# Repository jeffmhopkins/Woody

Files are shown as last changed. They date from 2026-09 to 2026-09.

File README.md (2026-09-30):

# Woody

A custom electronic woodwind instrument: a wooden body with mechanical key
switches, breath and motion sensing, driving control voltage into a Eurorack
system.

This is the second iteration of the
[Open Woodwind Project](https://github.com/jeffmhopkins/Open-Woodwind-Project)
(2021), rebuilt from scratch with modern components. The previous version was a
Teensy 3.2 with capacitive touch keys and an onboard synthesizer. This one keeps
almost none of that: mechanical switches instead of capacitive pads, an ESP32-S3
instead of a Teensy, CV output instead of an onboard synth engine.

**Status: Phase 0.** Design decisions are being recorded; no hardware has been
built. Switches and keycaps are purchased. See [ROADMAP.md](ROADMAP.md).

## What it is

The project splits into two physical deliverables that meet over a single cable:

| | **Controller** | **Interface module** |
|---|---|---|
| Form | Laminated wood/aluminium/acrylic body | 10HP Eurorack module |
| Contains | Keys, breath sensor, IMU, LED matrix, MCU | DAC, analog scaling, jacks, knobs |
| Domain | Digital | Analog, ±12V |
| Primary risk | Mechanical and ergonomic | Analog precision |

The controller carries no battery and no output jacks, and all CV **scaling,
conversion and output** happens in the module. It is **not** purely digital —
it holds the pressure sensor, a precision reference, two op-amp stages and the
analog drive onto the umbilical, which is where most of the project's analog
risk lives (ADR 0003). An earlier version of this sentence said otherwise, and
ADR 0004 records that the claim let a review finding through unchallenged.

It takes power from the rack over the umbilical and sends channel data
down the same cable as SPI. The module's analog sits inches from
the jacks it drives.

These two can be developed and tested independently, and the module can be
brought up standalone on a bench long before the instrument exists.

### Output

Six CV channels from the module:

- **Pitch** — dedicated, 1V/oct, −2V to +7V, per-unit calibrated
- **Breath** — dedicated, 0–10V, with panel knobs for gain and offset
- **Mod 1–4** — assignable; source, scale, offset, curve and slew configured
  over the instrument's USB port (ADR 0015)

## Design scope

**This is a tethered rack instrument.** It is powered by a Eurorack system,
patched into one, and played in front of one. That is the design case, and
decisions get made for it.

It is explicitly **not**: battery powered, wireless, standalone, a USB MIDI
controller product, or a touring instrument. Requirements that only make sense
away from the rack do not belong here, and past versions of these documents
drifted into arguing for some of them.

USB exists for flashing, and USB MIDI on top of it is a **bring-up tool** — it
is how keys, fingering and breath response get validated in a DAW before any
analog hardware is built (milestone E5). It is not a feature and it does not
get to constrain anything.

There is no onboard synthesizer. There is no battery.

**The target rack has a generous supply and a regulated +5 V rail.** Both are
stated properties of the system this is built for, not assumptions to be
defended. Rack current budget is therefore **not** a design constraint here, and
arguments of the form "a small Eurorack PSU might not cope" do not apply.

That relief is narrower than it sounds, and worth stating precisely so nobody
re-derives the wrong caution later. What still binds:

- **Heat.** The body is oak and acrylic — insulators — and sealed. Every watt
  leaves through the aluminium plate, part of which is under the player's hands.
- **The instrument's own 5 V regulator**, which is a 1 A part at the end of a
  2 m cable, not the rack supply.
- **Fault current**, which a larger supply makes *worse*, not better.

## Licence

Three share-alike licences, one per kind of work — **GPL-3.0-only** for
firmware, **CERN-OHL-S-2.0** for hardware and mechanical design,
**CC-BY-SA-4.0** for documentation. Derivatives stay open on the same terms.

See [`LICENSE`](LICENSE) for the mapping and the reasoning, and
[ADR 0011](docs/decisions/0011-licensing.md) for why it is three rather than
one.

## Repository layout

```
docs/decisions/   Architecture decision records — the important stuff
docs/log/         Dated build log
docs/reference/   Latency budgets, fingering notes, specs
docs/research/    Component comparisons and datasheet notes
docs/review/      Cold review waves. A dated record, never corrected
datasheets/       The actual vendor PDFs, one MANIFEST.csv row each
hardware/         Schematics, split by CIRCUIT under each board:
                    <board>/<circuit>/<circuit>.md  the drawing + derivations
                                      bom.csv       fragment; generates the BOM
                                      circuit.yaml  declared dependencies
                                      notes.md      what it used to be
                  interfaces/  the three circuits that cross a board boundary
                  boards/      one KiCad project per physical board, placing the
                               circuit sheets; the KiCad sheets are the source
                               of truth (ADR 0019, docs/reference/tooling.md)
                  bom.csv      GENERATED from the fragments - do not edit
firmware/         ESP32-S3 firmware (PlatformIO)
mechanical/       Body CAD (OpenSCAD, parametric): renders, DXF cut files and
                  a design-rule report, all GENERATED by tools/cad.py and
                  fingerprinted against their sources - see mechanical/README.md
config/           figures.yaml - THE SHARED-FIGURE REGISTER, the single
                  source of truth for every value used in more than one
                  document; plus key layout and routing, as data
tools/            Host-side utilities
branding/         The Space Coast Synthesizers mark: build.py generates the
                  laser artwork (SVG/DXF), a test print and renders
CLAUDE.md         THE WORKING RULES. Read this before editing anything -
                  it is short, and every rule in it was paid for once
```

*(`docs/review/` and `datasheets/` were missing from this tree until
2026-09-21. `datasheets/` is the largest directory in the repository;
`docs/review/` holds a wave per directory — `ls -d docs/review/*/` is the
count, and there is deliberately no number in this sentence. Both were
invisible in the one file a new reader opens first. The counts that used to
sit here — "77 banked documents", "seven waves", then "nine waves" — were
each true when written and wrong within the week, which is the whole reason
this repository cites rather than
restates.)*

## Where to start reading

1. [ROADMAP.md](ROADMAP.md) — the three tracks and what "done" means for each
2. [hardware/README.md](hardware/README.md) — **how the schematics are
   organised**: one circuit per directory, what the four files in each are,
   and the two rules that will bite you. Start here before opening any
   circuit page.
3. [docs/decisions/](docs/decisions/) — every choice made so far, and why
4. [docs/reference/latency-budget.md](docs/reference/latency-budget.md) — the
   constraint that shapes most of the electrical design
5. [docs/reference/repo-maintenance.md](docs/reference/repo-maintenance.md) —
   which files are generated, which are history, what each tool owns
6. [docs/reference/tooling.md](docs/reference/tooling.md) — **installing and
   using the tools**: the body CAD (OpenSCAD) and the schematic sheets
   (KiCad 9), one setup script for both

*(Entry 2 was missing until 2026-09-21. `hardware/README.md` — the page that
explains the whole `<board>/<circuit>/` scheme the restructure exists to
create — had **zero inbound links from anywhere in the corpus**, so the tree
was navigable by `grep` and by already knowing where things were, which is
the condition the restructure was meant to end.)*

*(This file carried a second "Licensing" section here saying the licence was
"not yet decided", contradicting the "Licence" section above it, which states
the three that were chosen. ADR 0011 has read `Accepted` since it was written
and `LICENSE` has held the mapping the whole time. Deleted 2026-09-21 — the
licence is stated once, above, and nowhere else.)*

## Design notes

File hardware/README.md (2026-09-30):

# hardware/ — how this directory is organised

*Schematic sheets are generated from the netlists in KiCad 9, and each
physical board has a directory under [`boards/`](boards/) whose netlist is
assembled from the circuits: [`docs/reference/tooling.md`](../docs/reference/tooling.md) §3.*

One circuit per directory. The directory is the unit: the drawing, the parts,
the declared dependencies and the history of what the circuit *used to be* all
sit together, so a change and its record are never in different places.

```
<board>/<circuit>/<circuit>.md     the schematic: ASCII drawing, derivations,
                                   and an ## Interfaces table of every net
                                   that crosses the circuit's boundary
                  bom.csv          this circuit's parts. A FRAGMENT
                  circuit.yaml     declared dependencies. SEEDED, NOT VERIFIED
                  notes.md         past tense only. No live value belongs here
                  sim/             its SPICE simulation: sims.yaml (what is simulated,
                                   and what each run must show), the decks, and
                                   results.yaml, GENERATED by tools/sim.py run and
                                   held to its inputs by check-staleness. A sim/
                                   with a README and no sims.yaml is a contract not
                                   yet run, and says so
                  <circuit>.kicad_sch  THE SOURCE OF TRUTH where it exists
                                   (ADR 0019): connections and part facts.
                                   Edit in KiCad 9
                  netlist.yaml     EXPORTED from the sheet by tools/kicad.py
                                   where one exists - do not edit. Otherwise
                                   hand-written and authoritative until the
                                   circuit is migrated. Every check reads it

boards/<board>/   one KiCad project per physical board: the root sheet
                  places circuit sheets once per instance; board-netlist.yaml
                  is its exported, flattened netlist

nets.yaml                          at hardware/ root: THE MASTER NET LIST,
                                   which owns every net that crosses a circuit
                                   boundary. A netlist.yaml declares only its
                                   own side; this file owns the net
```

> ### The drawing is not the source of truth. Where a `netlist.yaml` exists, that is.
>
> **An ASCII drawing is a picture.** No tool in this repository can read one,
> so nothing checks that a value in a drawing matches the BOM row for the same
> refdes — and on 2026-09-22 a review found four that did not, including
> `R-FB` drawn at a resistance that is not a purchasable E96 value and an
> entry capacitor drawn at half the BOM's value on the rail that matters.
>
> **`tools/check-netlist.py` checks the drawing against the netlist**, and
> the netlist against `bom.csv` and against `nets.yaml`. It runs `--strict`
> from the commit gate, so a page that gains a drawing and no netlist is a
> failure rather than an entry on a list. It resolves a label against EVERY
> netlist, not only the one beside the page, because several pages draw parts
> they do not own.
>
> **Where a drawing and a row disagree and no netlist covers them, `bom.csv`
> wins.** It is generated from fragments, `merge-bom.py --check` proves the
> master matches them, and the commit hook runs it. A drawing has none of
> that behind it.

| Directory | |
|---|---|
| [`carrier/`](carrier/carrier.md) | The instrument's real-time board — 5 circuits |
| [`cluster/`](cluster/cluster-boards.md) | The four key clusters — two key boards and the main board's two thumb clusters — 3 circuits |
| [`module/`](module/module.md) | The 10HP Eurorack module — 12 circuits |
| [`interfaces/`](interfaces/README.md) | The 3 circuits that cross a board boundary |

## The `## Interfaces` table

Every circuit page carries one: every net that crosses that circuit's
boundary, one row each. A PCB netlist is transcribed from these, so a row is
a wiring instruction and two pages disagreeing about a net is a short.

**Two drawing shorthands, and they are shorthands — not missing parts.** The
ASCII drawings use a short spelling where the full refdes would break column
alignment. When transcribing a netlist, expand them:

A netlist declares its own alias with `drawn_as:`, which is what makes the
shorthand checkable rather than merely documented; this table is for the
pages that have no netlist yet.

| Drawn as | BOM row |
|---|---|
| `C-TIMER` | `C-TIMER-LOADSW` |
| `C-GATE` | `C-GATE-LOADSW` |

**`J-UMB` is no longer a shorthand.** It was one, for `J-UMBILICAL`, until
ADR 0017 put a real connector of that name on the main board: `J-UMB` is now
its own row, the header that joins the etherCON's adapter to the main board
(ADR 0021), so "`J-UMB` pin N" on an instrument page is that header and the
same conductor as the etherCON's pin N
(`hardware/interfaces/spi-link/spi-link.md`). On a module page the umbilical
connector is `J-UMBILICAL`, netlisted as `J-UMB-MOD`; the instrument's
etherCON is `J-UMBILICAL-INST`, netlisted as `J-UMB-INST`. Neither is ever
`J-UMB`.

A cold reviewer filed these two, and `J-UMB` when it was a shorthand, as
refdes that "match nothing in `bom.csv`", which was fair — nothing said
otherwise. They are listed here once rather
than expanded in ~40 drawing sites, because widening a label inside a drawing
shifts every column to its right, and that drift is itself a recorded defect
on these pages. One more, an unlabelled `N-FET`, was **not** a shorthand: it
is `Q-LOADSW`, a row created after that drawing was last touched, and it is
now labelled.

| Column | |
|---|---|
| **Node** | The net's name, **qualified** where the same bare name means different things on different boards. `AGND_SENSE`, `AGND_INST` and `AGND_MOD` are three nets; `AGND` alone is a merge waiting to happen. Each row names the drawing's own spelling so a reader can match the two. |
| **Dir** | This circuit's side of the net: `in`, `out`, `in/out`, `ref` (a return or a reference) or `—` (no connection here — the row is context). |
| **Peer** | A bare `board/circuit` id when the other end is a circuit in this tree, a reference designator or part name when it is not, `—` when there is nothing on the other end. |
| **Figure** | A citation into `config/figures.yaml`. The table names nodes; it **does not restate values.** |

**Exactly one page sources a net.** The page holding the part that drives it
says `out` and "Sourced here"; every other page says `in` and names it. Two
pages both claiming to source one net is the defect this column exists to
make visible — it happened to the DAC's `SCLK`/`DIN`/`SYNC`, in two
byte-identical rows.

The two board-crossing tables (`interfaces/breath-sense-link`,
`interfaces/spi-link`) carry an extra **End** column naming which side of the
cable a node sits on, because for those the board is not implied by the page.

*(This definition sat inline in all 23 circuit pages until 2026-09-21 —
twenty-three copies of one paragraph, in a repository whose first rule is
state it once and cite it. It is here, and they cite it.)*

## `circuit.yaml` and its `depends_on` edges

Every circuit directory carries a `circuit.yaml` whose `depends_on` list is
the dependency graph. Four kinds of edge, and **they are not equally
trustworthy** — this section is the one place that says which:

**`circuit:` edges are VERIFIED.** The rule is mechanical, so any edge can be
checked against the two tables it comes from:

> ONE `circuit:` edge per distinct `board/circuit` id in the **Peer** column of
> this circuit's `## Interfaces` table, AND every such edge is declared from
> **both** ends. A peer that is not a circuit in this tree — a connector, the
> Eurorack bus board, a dev board header — is named in the Peer column by its
> reference designator or its name, and creates no edge.

**`adr:`, `fig:` and `refdes:` edges are SEEDED FROM CO-MENTION and are NOT
VERIFIED.** An edge of those three kinds means *"this page mentions this
thing"*, which is a useful starting graph and a bad finished one. Three were
verified false by a cold reviewer, by reading:

| edge | what it really is |
|---|---|
| `pitch-stage` → `R-BIAS-INAMP` | the page names it as an explicit **contrast** |
| `breath-adc` → `C-STRIP-BULK` | a citation of a note about the LED strip |
| `breath-receive` → `U-OPA-PITCH` | a package-count consequence, not a use |

All three are still declared. **Expect more of that shape.**

**Direction is not recorded.** Several pairs are mutual, which is honest for a
net shared between two circuits and useless for ordering anything.

**What IS guaranteed for every edge, verified or seeded: it RESOLVES.** A
`refdes:` names a BOM row that exists, a `fig:` names a register entry, a
`circuit:` names a declared id. That is what catches a dependency on a deleted
part — the semantic half `CLAUDE.md` §5 says a grep cannot reach.

*(This sat as a 39-line comment header inside all 23 `circuit.yaml` files —
byte-identical, twenty-three copies — until 2026-09-22. Same defect as the
`## Interfaces` definition above, found the same way, fixed the same way.)*

## Two rules that will bite you

**`bom.csv` here is GENERATED.** `tools/merge-bom.py` rebuilds it from the
per-circuit fragments, so **a direct edit survives until the next run of that
tool and then disappears without a word.** Edit the fragment. A row lives with
the circuit **whose page derives its value** — not where it is mentioned, not
where it is mounted. `merge-bom.py --check` proves the master still matches
and the commit hook runs it, so this one fails loudly rather than silently.

**Numbers shared between documents are not written here.** They live in
`config/figures.yaml`, stated once by their owner and **cited by name**
everywhere else. This whole repository is organised around one recorded
failure — a value changes and the documents derived from it do not follow —
and citation is the only form that cannot go stale. `CLAUDE.md` has the rule
and the three-step procedure for changing a tracked figure.

## What is deliberately not here

`hardware/unplaced.csv` holds the BOM rows **no schematic page derives**.
That is a count, not a dumping ground: a part nobody has drawn.

It has shrunk twice; `wc -l hardware/unplaced.csv` is the count, and a
number written here goes stale the next time a row is placed. Sixteen rows
were drawn all along — the
DAC, the in-amp, the LM317 and its divider, the entry diodes, the four
beads, the bulk capacitors, both load-switch capacitors, the module's level
shifter and the LT5400 — and were sitting in the undrawn pile because
assignment matched on **reference designator** while those parts are drawn
under a local label (`R1`, `C_cm`, `FB2`, `R_G`) or a part number
(`INA828`, `LM317LZ`, `DAC8568`). A count of undrawn parts that includes
every principal IC on a board is not a count of anything.

What remains is genuinely unplaced, and most of it is mechanical — the oak,
the acrylic, the adhesives, the fasteners — plus the parts whose circuit has
no page yet.

Drawings that span more than one circuit were **left whole** rather than
redrawn, and the circuits cite them. `carrier.md`'s §2 figure carries three
circuits in one connected picture; dividing it would mean redrawing it, and a
redraw is not a move.

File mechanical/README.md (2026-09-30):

# Instrument body — parametric CAD

*Installing the tools and the day-to-day loop: [`docs/reference/tooling.md`](../docs/reference/tooling.md)
(`sudo bash tools/setup-env.sh` installs everything).*

> **Status:** first model, 2026-09-26. **Layout is PROVISIONAL**: every key
> position in `config/key-layout.yaml` is still `null` (they are M2/M3
> outputs), so keys are placed on ADR 0009's length budget and every render
> says so in its footer. Keys are **flush with the top face at full travel**
> — thumb keys included, on the bottom face. **There is no display board**:
> the LED matrix is the instrument's only display (ADR 0015, 2026-09-26).

The body described in [ADR 0009](../docs/decisions/0009-enclosure-construction.md)
— a laminated stack of flat parts, every layer a 2D through-cut — as an
OpenSCAD model, with renders and cut files generated from it and a ledger that
proves each one still shows the model it names.

*The Eurorack module is a separate model in the same pipeline:
[`module/README.md`](module/README.md).*

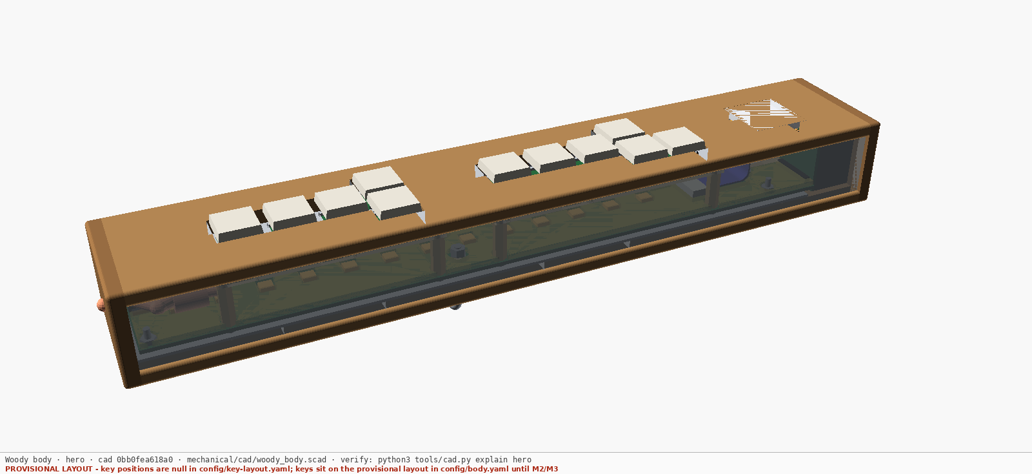
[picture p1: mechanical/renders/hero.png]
The instrument, key face up


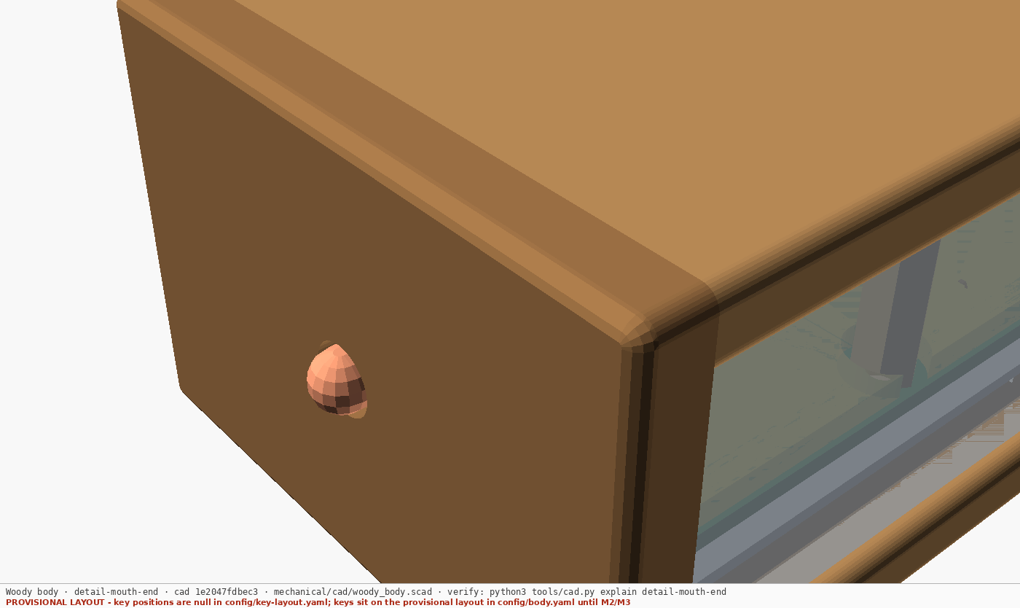
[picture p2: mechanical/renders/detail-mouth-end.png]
The mouth end close up: oak cap and sanded edges


## The one rule

**Change the YAML, run the build, commit what it produced.** Never draw a
number into the `.scad`, and never touch a file under `renders/`, `export/`
or `cad/generated/`.

```
config/key-layout.yaml ─┐                           ┌─> renders/*.png   (stamped)
config/body.yaml ───────┼─> cad/generated/params.scad ─> woody_body.scad ─┼─> export/*.dxf    (cut files)
datasheets/…  (STEP, DXF)─> cad/vendor/*.stl ────────┘                     └─> drc.echo        (design rules)
                                                         every arrow fingerprinted in OUTPUTS.csv
```

```
python3 tools/cad.py build          # regenerate params, rebuild whatever is stale
python3 tools/cad.py check          # exit 1 if any output no longer matches its sources
python3 tools/cad.py explain hero   # which input moved, and the commit it was built from
```

`check` runs from the commit gate (`tools/check-staleness.py`) and needs
nothing but Python. `build` needs OpenSCAD 2021.01+, `xvfb-run` on a machine
without a display, Pillow (for the stamp), and gmsh (`pip install gmsh`, plus
apt `libxft2`) to mesh the vendor STEP files.

## How staleness is tracked

A picture cannot be grepped, so no forbidden pattern will ever catch a render
of a superseded value. Instead:

- **Every output has a fingerprint**: a hash over its recipe in
  [`outputs.yaml`](outputs.yaml) and the git blob id of **every file it was
  built from**, found by walking `include`/`use`/data-file references from its
  source. The build cross-checks that walk against OpenSCAD's own dependency
  file and refuses to trust a fingerprint the two disagree on.
- **[`OUTPUTS.csv`](OUTPUTS.csv) is the ledger**: fingerprint, the output's own
  hash, and each input's blob id. `check` recomputes all of it. It reports an
  output as **STALE** when an input moved (naming the file), as **edited** when
  the output no longer hashes to what the ledger vouches for, and as an
  **orphan** when a PNG or DXF exists that no spec entry builds.
- **The fingerprint is stamped into every render's footer**, because the reader
  looks at the picture, not the ledger. A render pasted anywhere still says
  `cad <fingerprint>`, and `explain` turns that back into the git commits it was
  built from.
- **A config change is caught before it reaches a picture**: `params.scad`
  must equal what the YAML generates, and `check` lists every output fed by it.
- **Pages here may only show tracked outputs.** An image link in a
  `mechanical/**/*.md` page that is not in the ledger fails `check`.
- **`RECIPE` in `tools/cad.py`** is part of every fingerprint. Bump it when you
  change *how* outputs are made (stamp, mesh settings, render flags) — the
  tool's own source is deliberately not an input, so this is the one manual
  step, and forgetting it was the first bug this pipeline had.

## What is here

| Path | What it is |
|---|---|
| [`cad/woody_body.scad`](cad/woody_body.scad) | The model. Every flat part as a 2D module in its own sheet frame; the assembly places them. `part=` selects one |
| `cad/fig_*.scad` | Figure sources with dimensions and labels, drawn from the same variables as the parts. They sit beside the model because OpenSCAD resolves `import()` against the top-level file |
| `cad/lib/annot.scad` | Dimension and label helpers (from JBrain2's back-plate CAD) |
| `cad/generated/params.scad` | **Generated.** Every number the model uses, with its source and status |
| `cad/vendor/*.stl` | **Generated.** The banked KS-33 STEP solid, meshed |
| [`outputs.yaml`](outputs.yaml) | Every output: cameras, defines, paths. The build does exactly this list |
| [`OUTPUTS.csv`](OUTPUTS.csv) | **Generated.** The fingerprint ledger |
| [`drc.echo`](drc.echo) | **Generated.** The design-rule report — read it after every change |
| [`clash.txt`](clash.txt) | **Generated.** The interference check: every named solid against every other |
| [`clash-allow.yaml`](clash-allow.yaml) | Interference the design intends, each with its reason |
| `export/*.dxf` | **Generated.** One file per flat part, as it goes to the cutter |
| `renders/*.png` | **Generated.** Every image on these pages |
| [DESIGN.md](DESIGN.md) | How the stack is built, where each number comes from, and what the first model found |

## The views

| | |
|---|---|
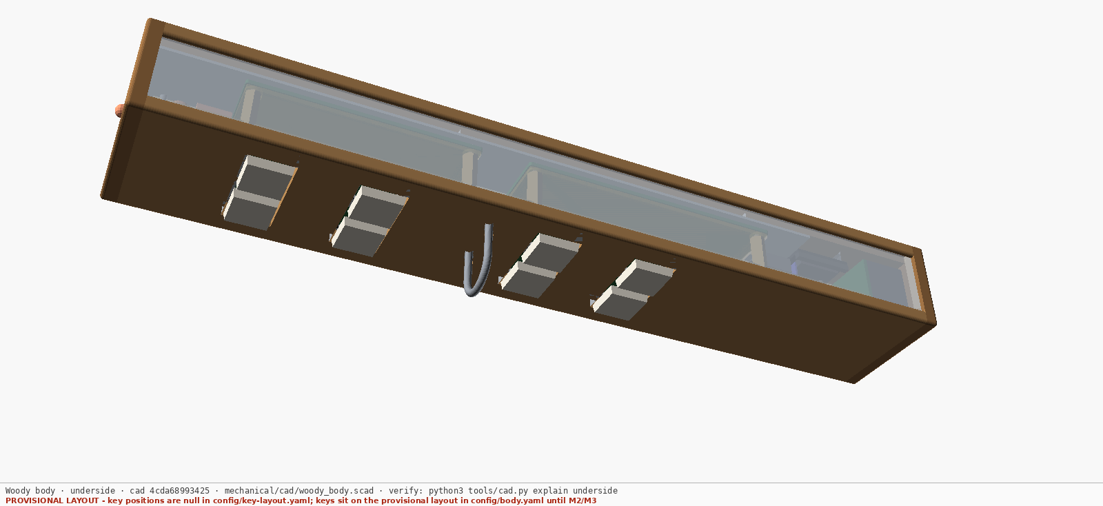
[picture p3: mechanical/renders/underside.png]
Underside
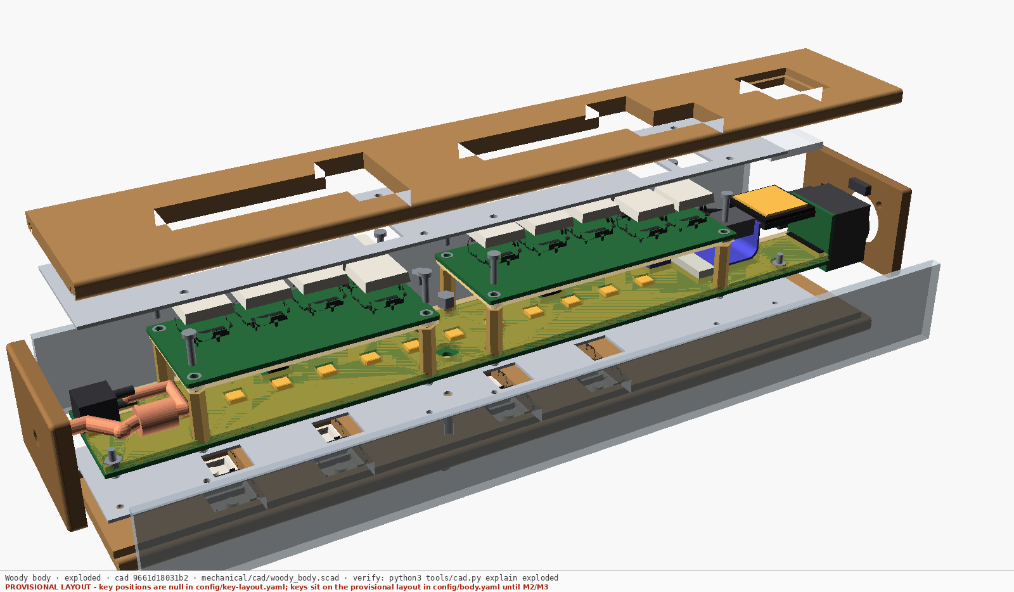
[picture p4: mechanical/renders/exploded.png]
Exploded
|  Underside: thumb recesses, both thumb rests, U-bolt |  The stack, pulled apart |
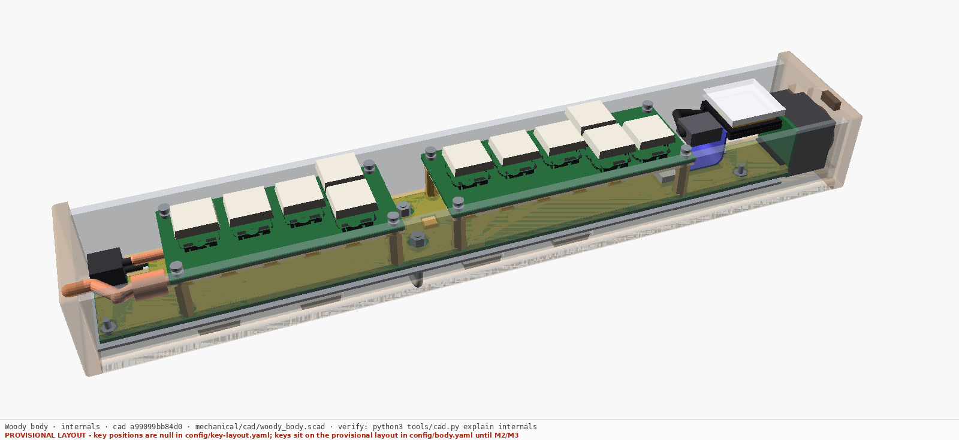
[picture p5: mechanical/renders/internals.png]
Internals
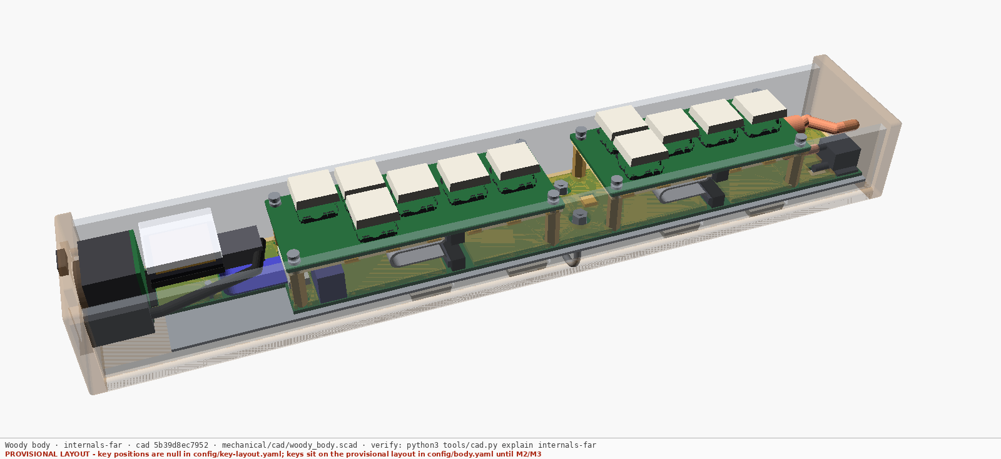
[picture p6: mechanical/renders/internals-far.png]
Internals, far side
|  Oak top and key plate off |  Oak top and key plate off, from the far side: the ribbons |
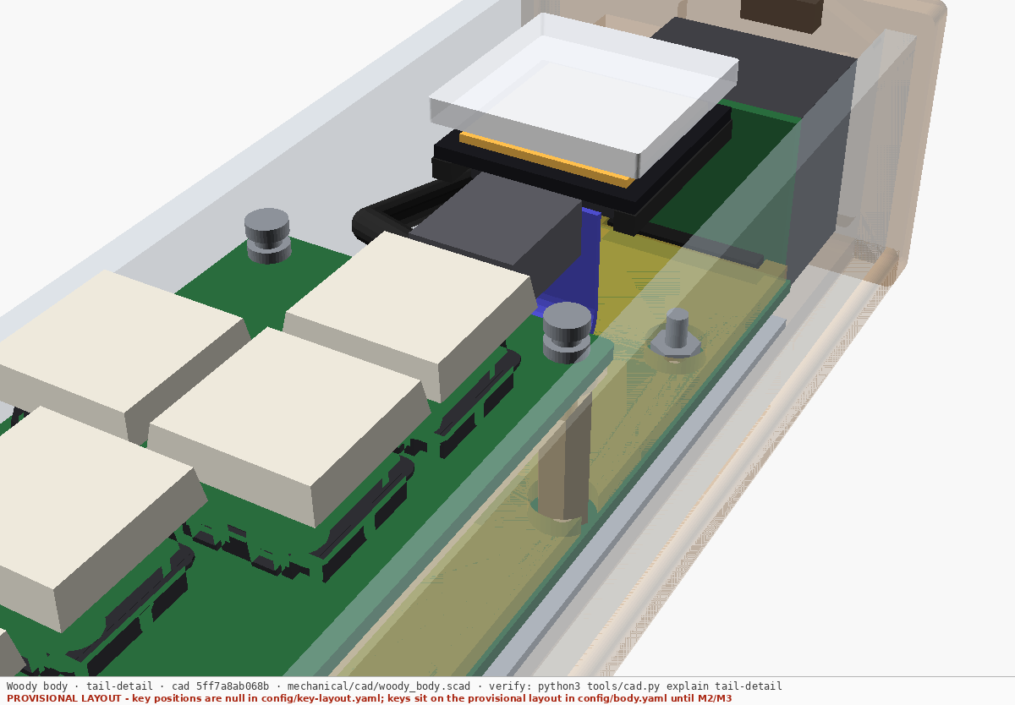
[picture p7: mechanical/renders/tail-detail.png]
Tail
|  The tail from inside | |
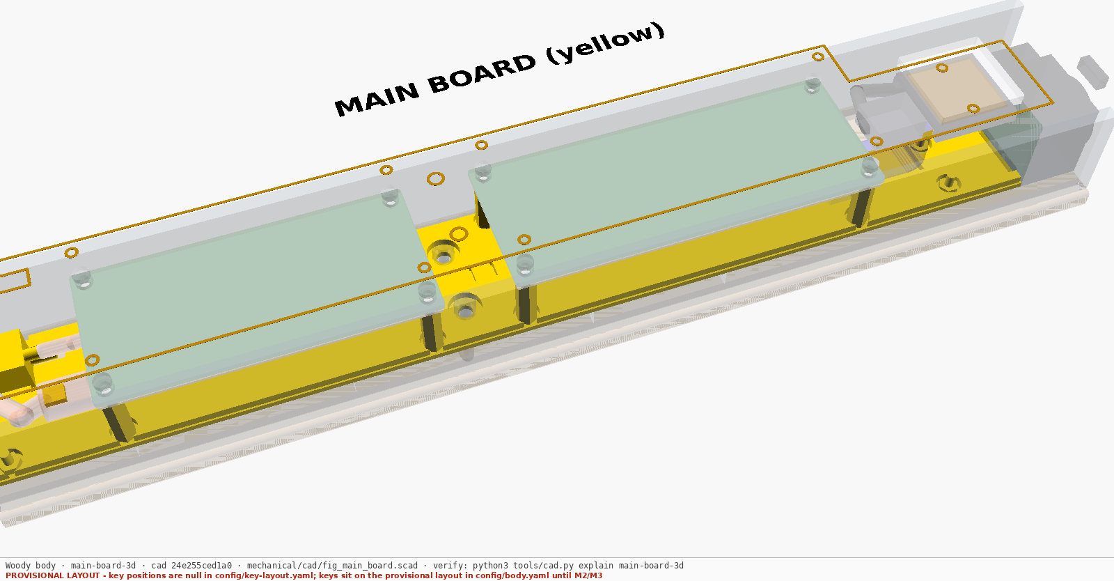
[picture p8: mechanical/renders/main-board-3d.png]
Main board
|  The main board: thumb switches and carrier circuits on one board, in yellow | |

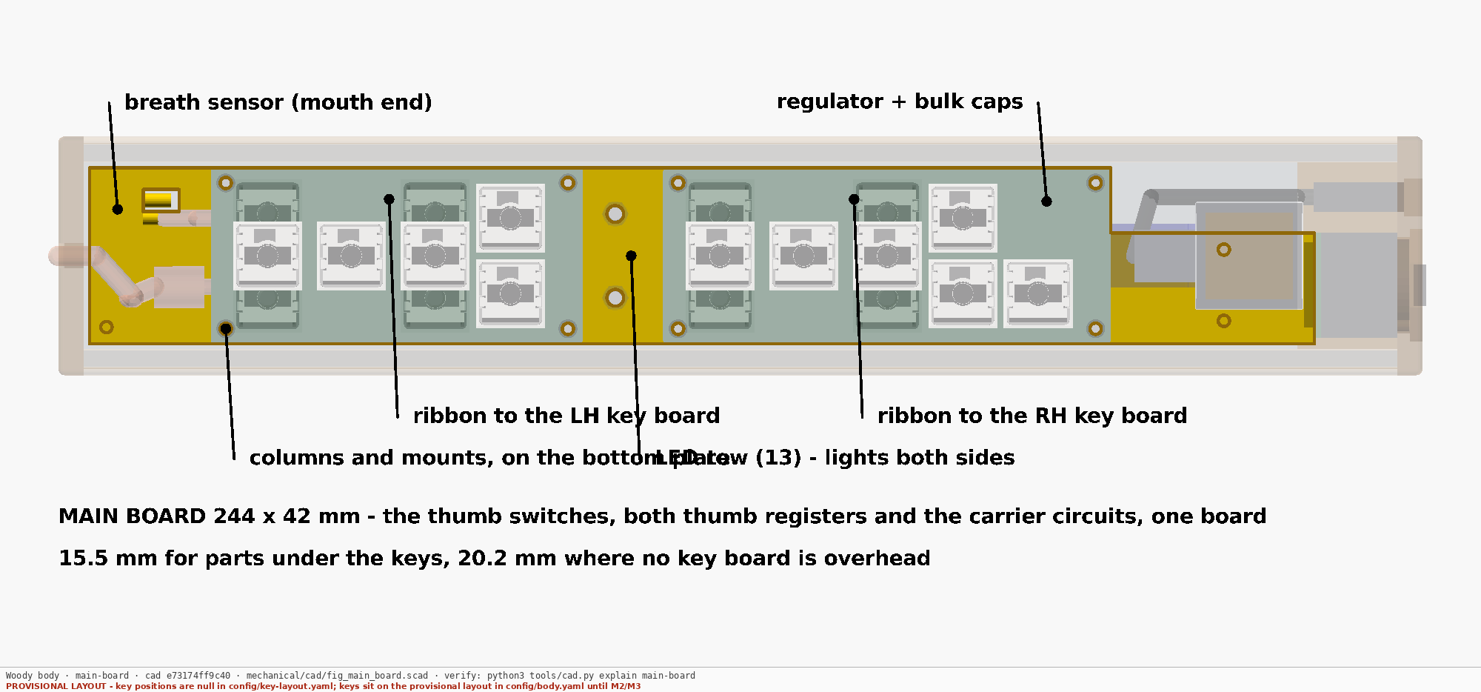
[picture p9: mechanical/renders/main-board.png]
The main board, labelled


### Breakdowns

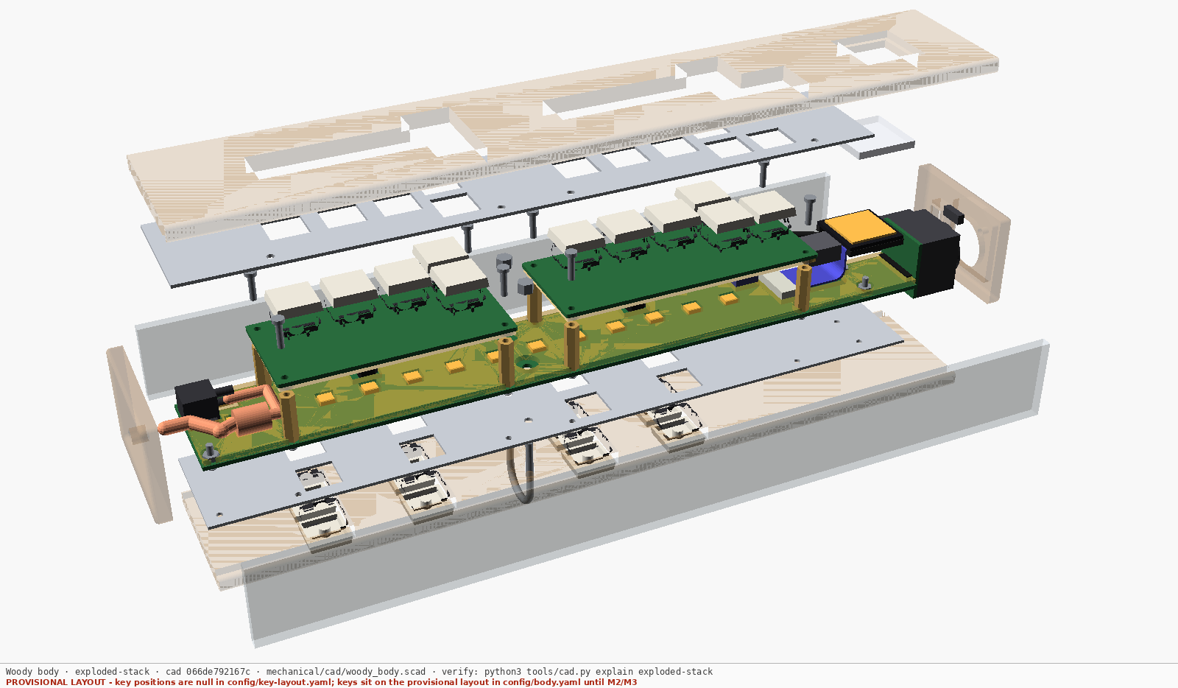
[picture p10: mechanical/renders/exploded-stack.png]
The stack pulled apart, shell ghosted


| | |
|---|---|
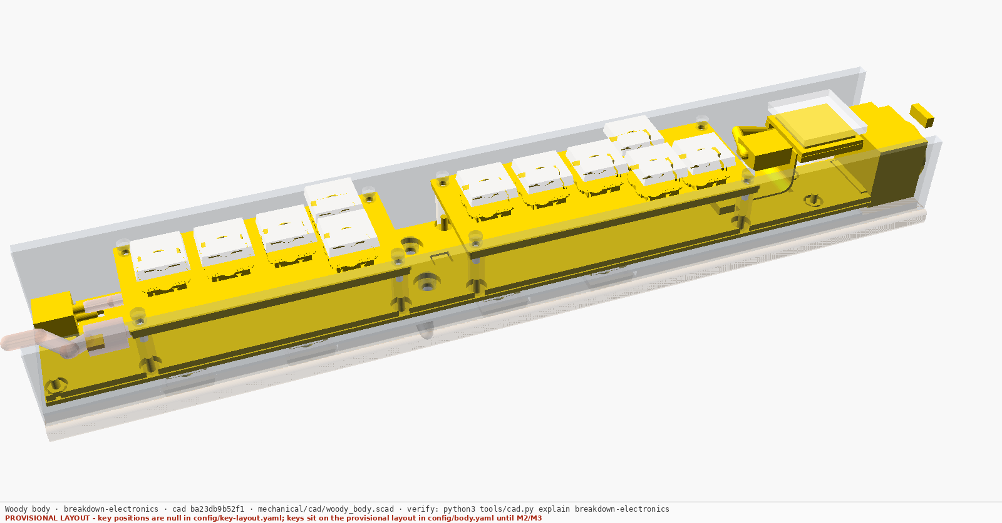
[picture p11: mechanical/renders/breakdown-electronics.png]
Electronics
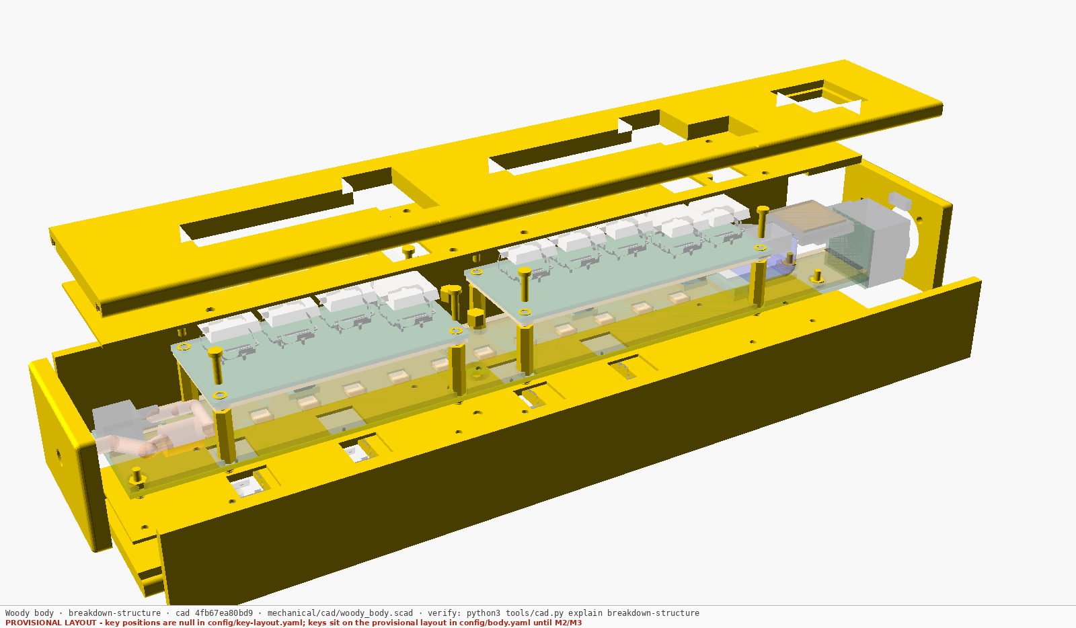
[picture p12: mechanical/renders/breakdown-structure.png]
Structure
|  The electronics in yellow |  The structure in yellow, pulled apart |
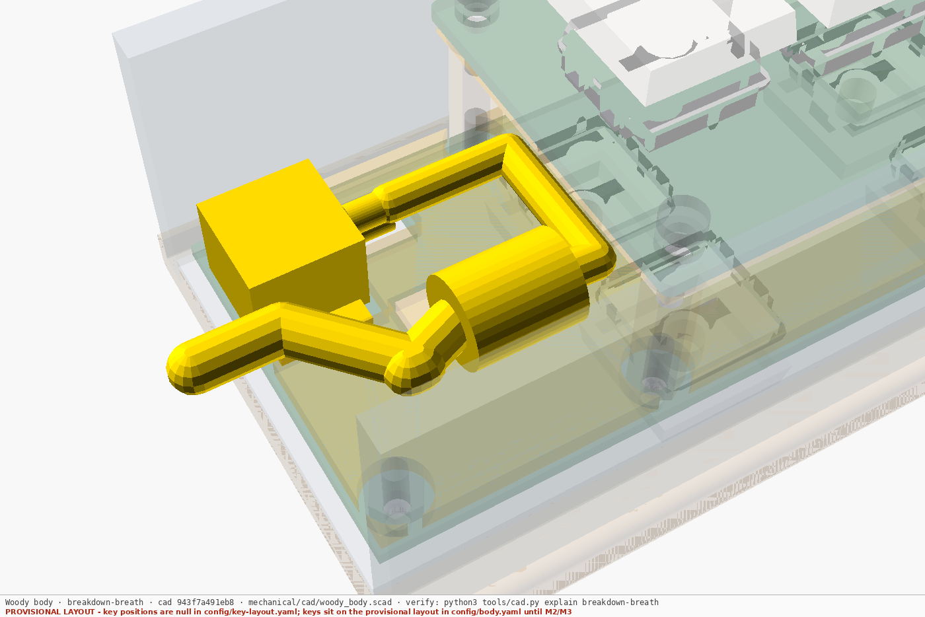
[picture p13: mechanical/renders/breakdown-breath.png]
Breath path
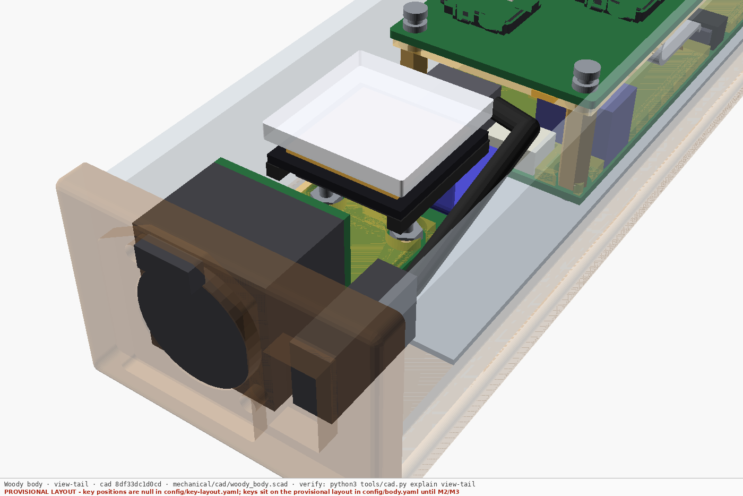
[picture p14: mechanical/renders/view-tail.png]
From the tail
|  The breath path at the mouth end |  The tail from outside, oak top and key plate off |

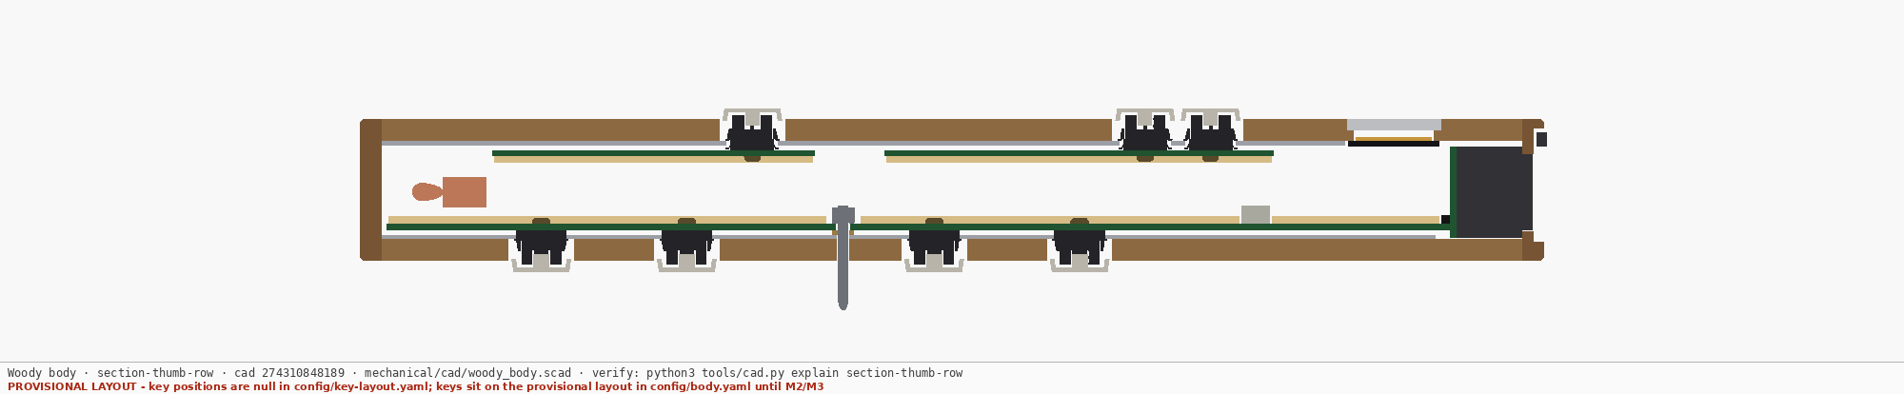
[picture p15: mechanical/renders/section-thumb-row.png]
Section through the thumb row


| | |
|---|---|
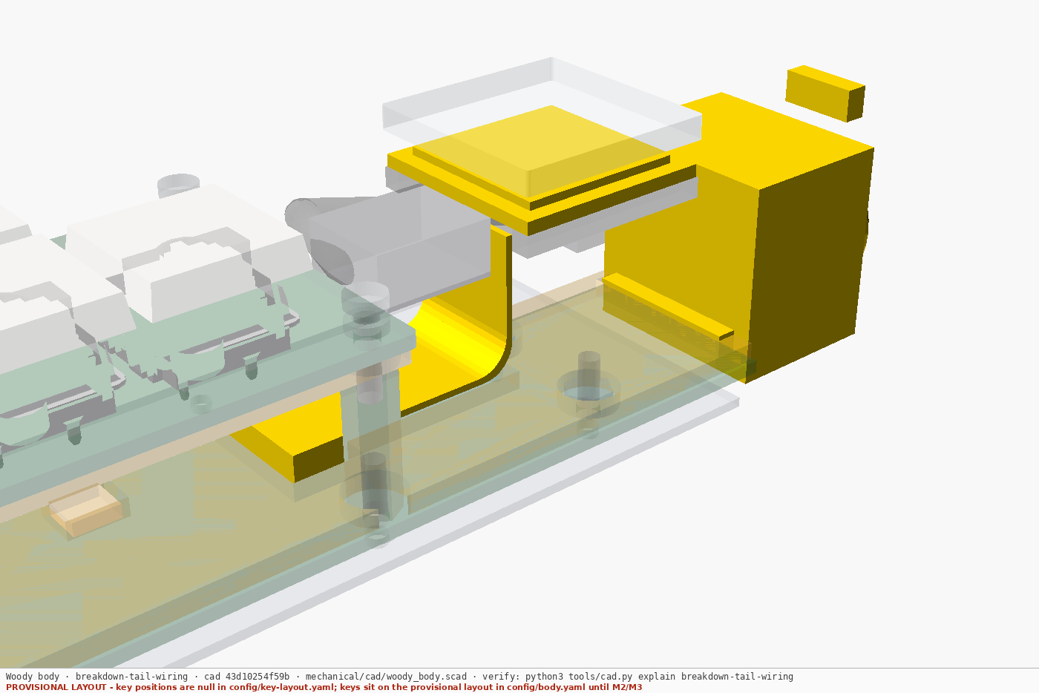
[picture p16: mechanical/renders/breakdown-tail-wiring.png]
Tail wiring
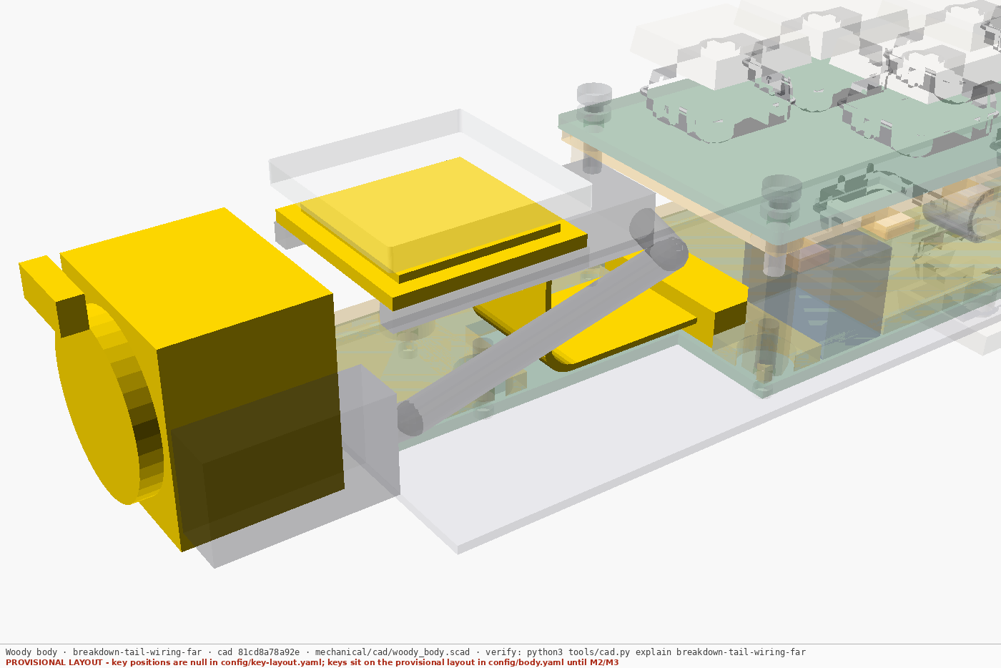
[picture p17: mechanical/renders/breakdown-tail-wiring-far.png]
Tail wiring, far side
|  The etherCON on its adapter, joined by J-UMB to the main board's tongue, and the Matrix's ribbon |  The Matrix ribbon's drop into J-MCU |
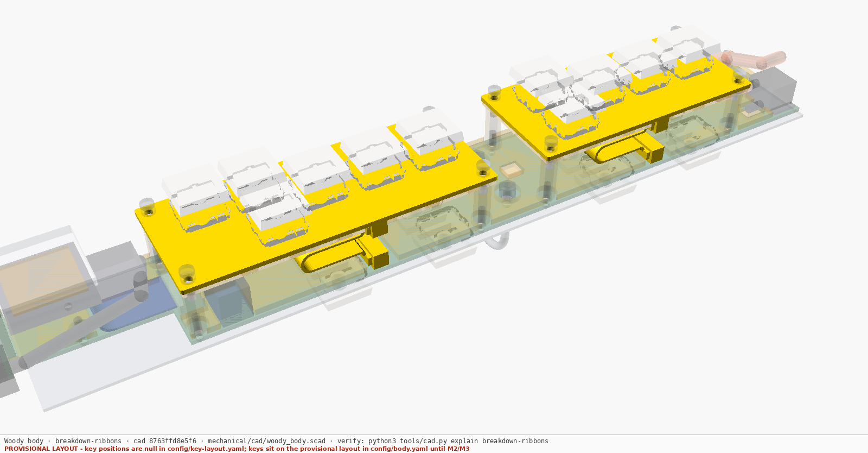
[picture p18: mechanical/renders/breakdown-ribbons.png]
Ribbons
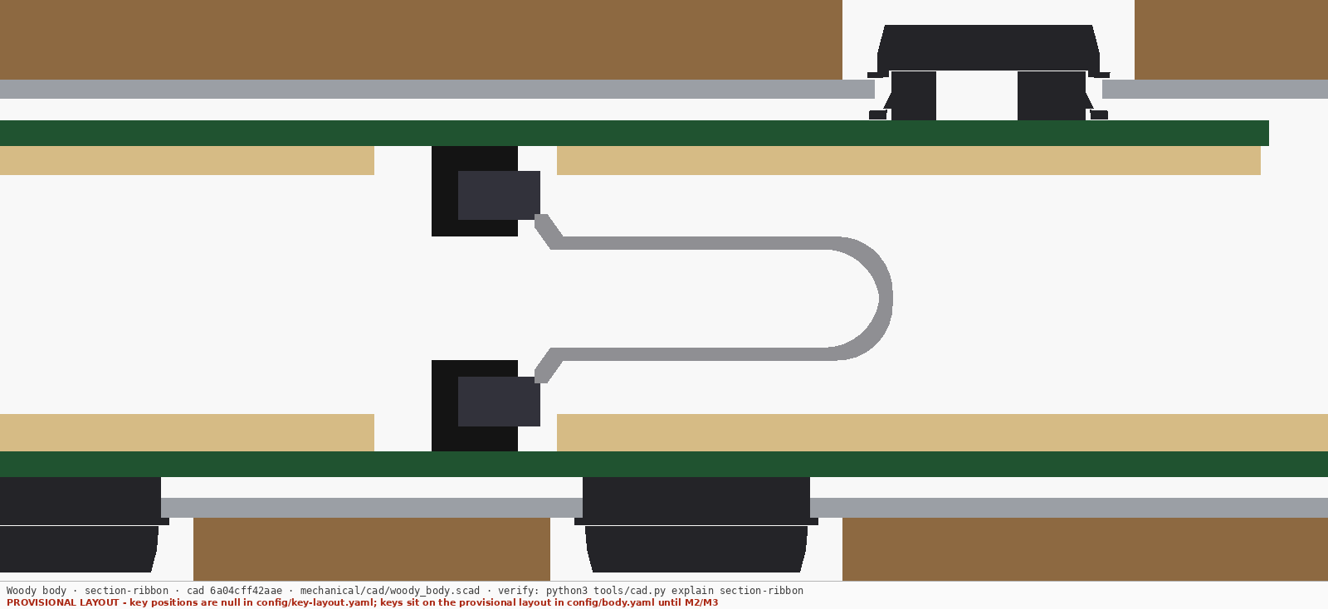
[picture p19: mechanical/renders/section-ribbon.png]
Ribbon fold
|  The key boards' ribbons and connectors, lid, sides and oak bottom off |  Section along the body through the left key board's chain headers: the ribbon's hairpin, closed |

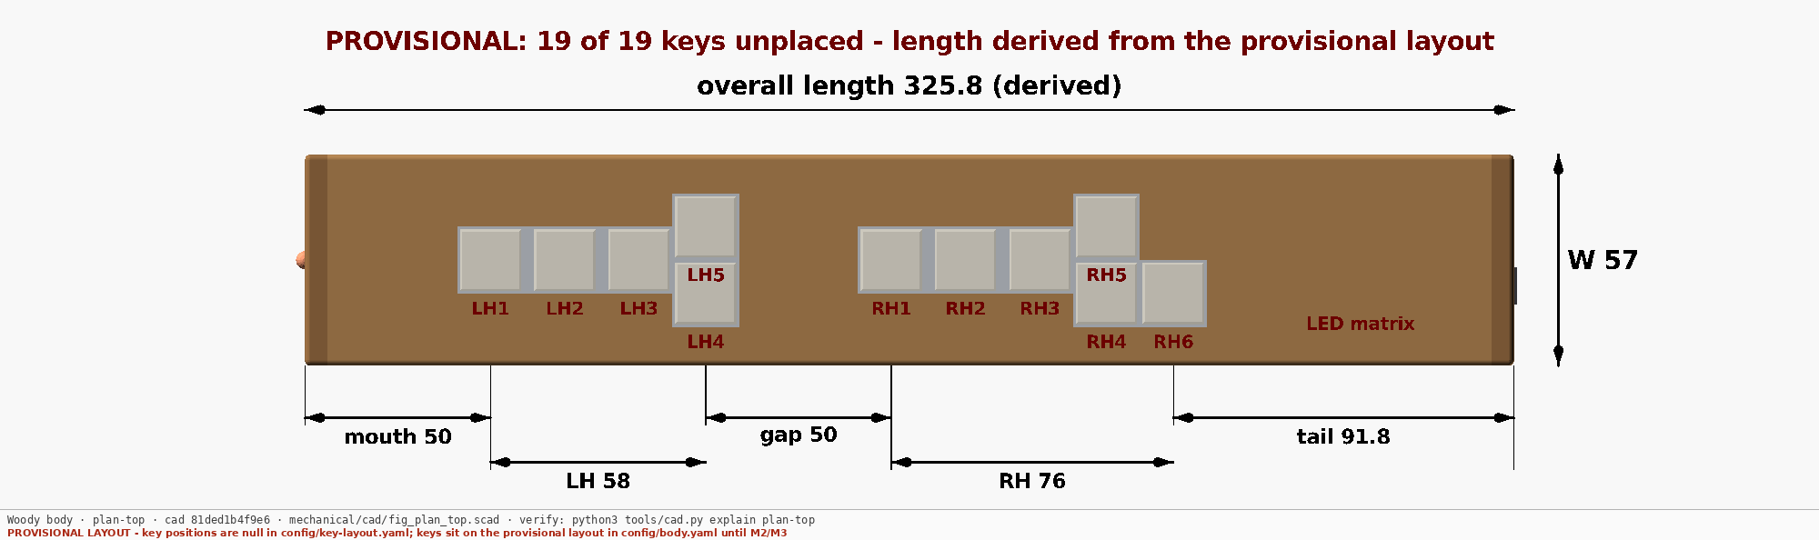
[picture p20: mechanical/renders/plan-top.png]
Plan from above, with the length budget


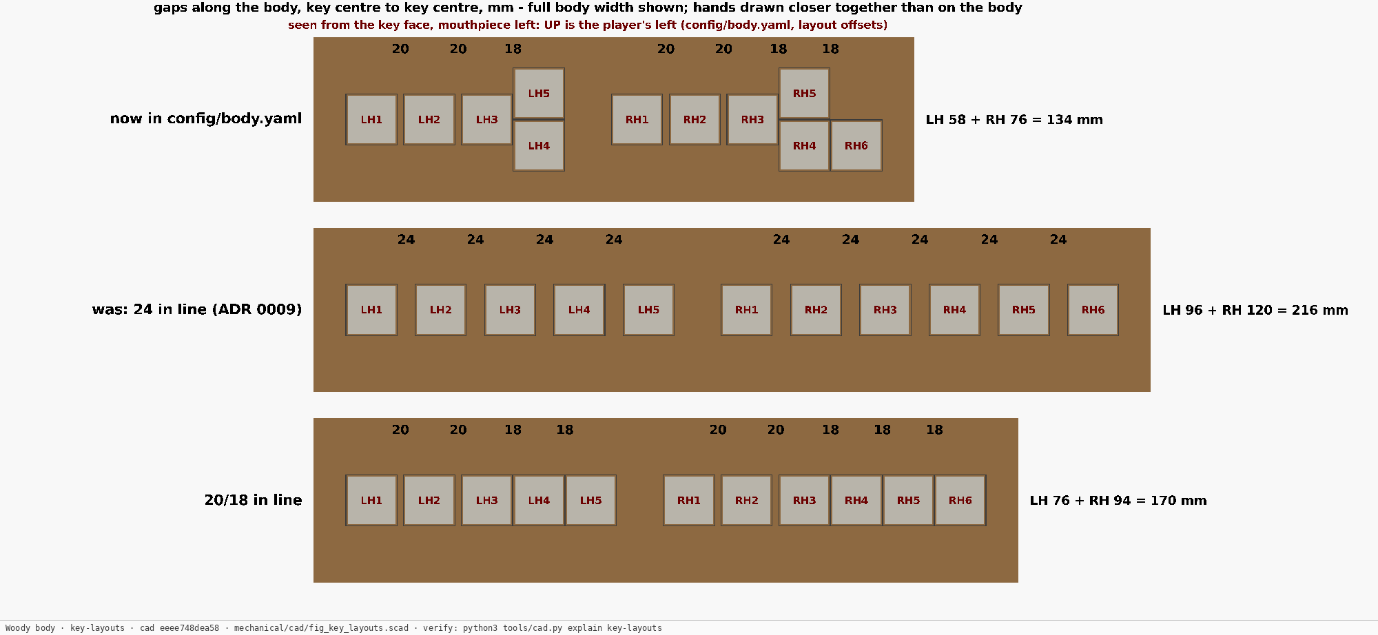
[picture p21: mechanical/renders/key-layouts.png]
Top-key spacing, now against the alternatives


Top-key spacing comes from `docs/research/2026-09-26-finger-spacing/`:
graded, wider under index-middle-ring and tighter to the little finger. The
little finger starts on a side-by-side pair, and the right little finger has
a single key below its pair, in line with the pair's outer key (ADR 0010). At
the tightest gap an oak web between individual cap holes would be zero, so
the oak top has **one slot per hand** (`stack.cap_holes`).

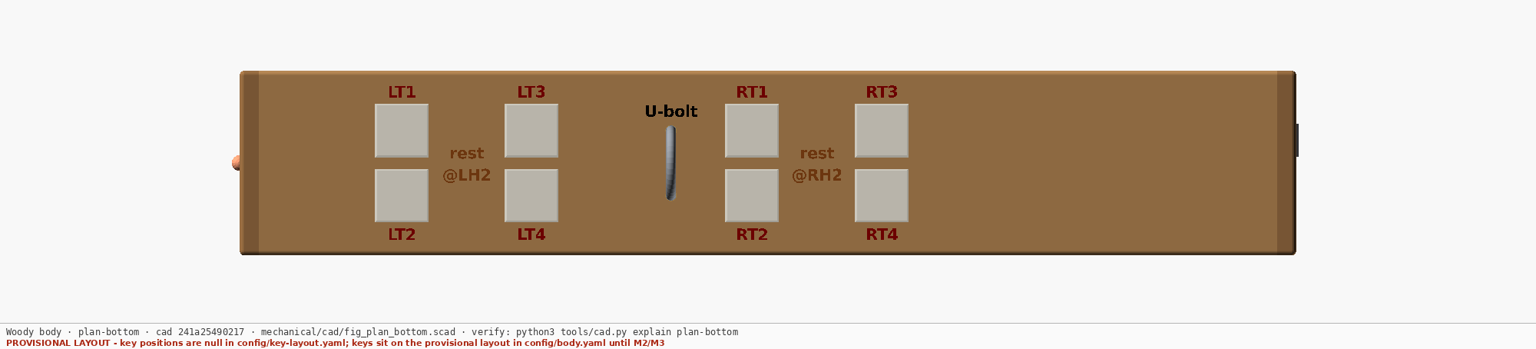
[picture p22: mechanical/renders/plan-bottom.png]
Plan from below


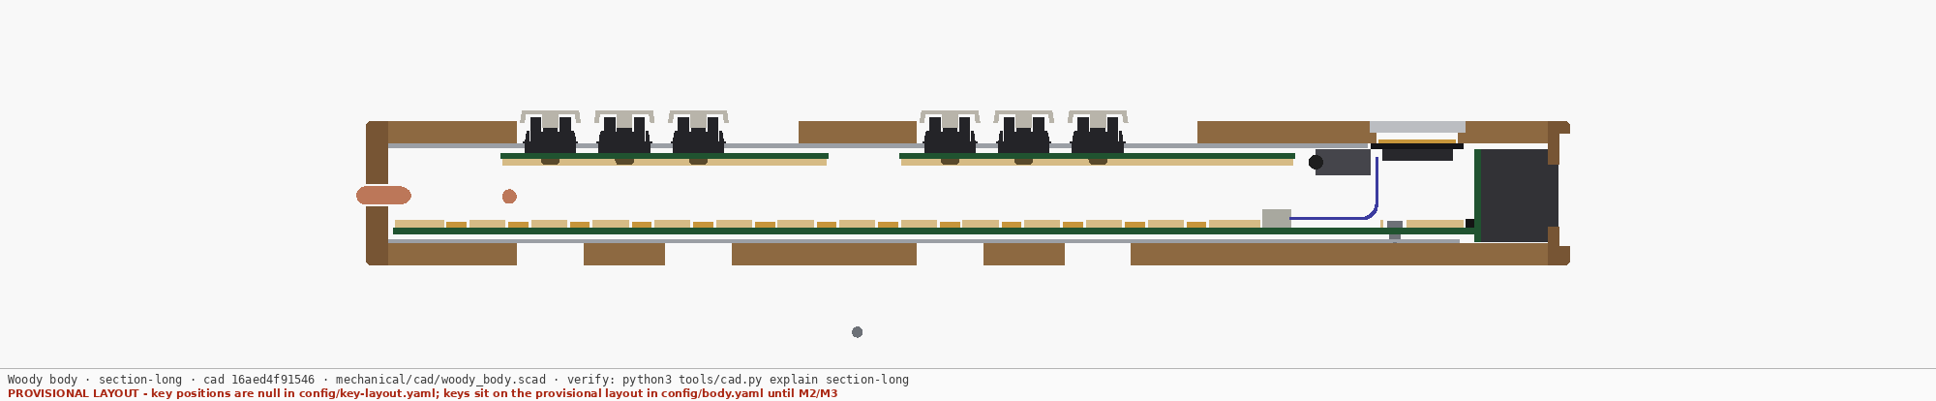
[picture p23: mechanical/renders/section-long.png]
Longitudinal section


| | |
|---|---|
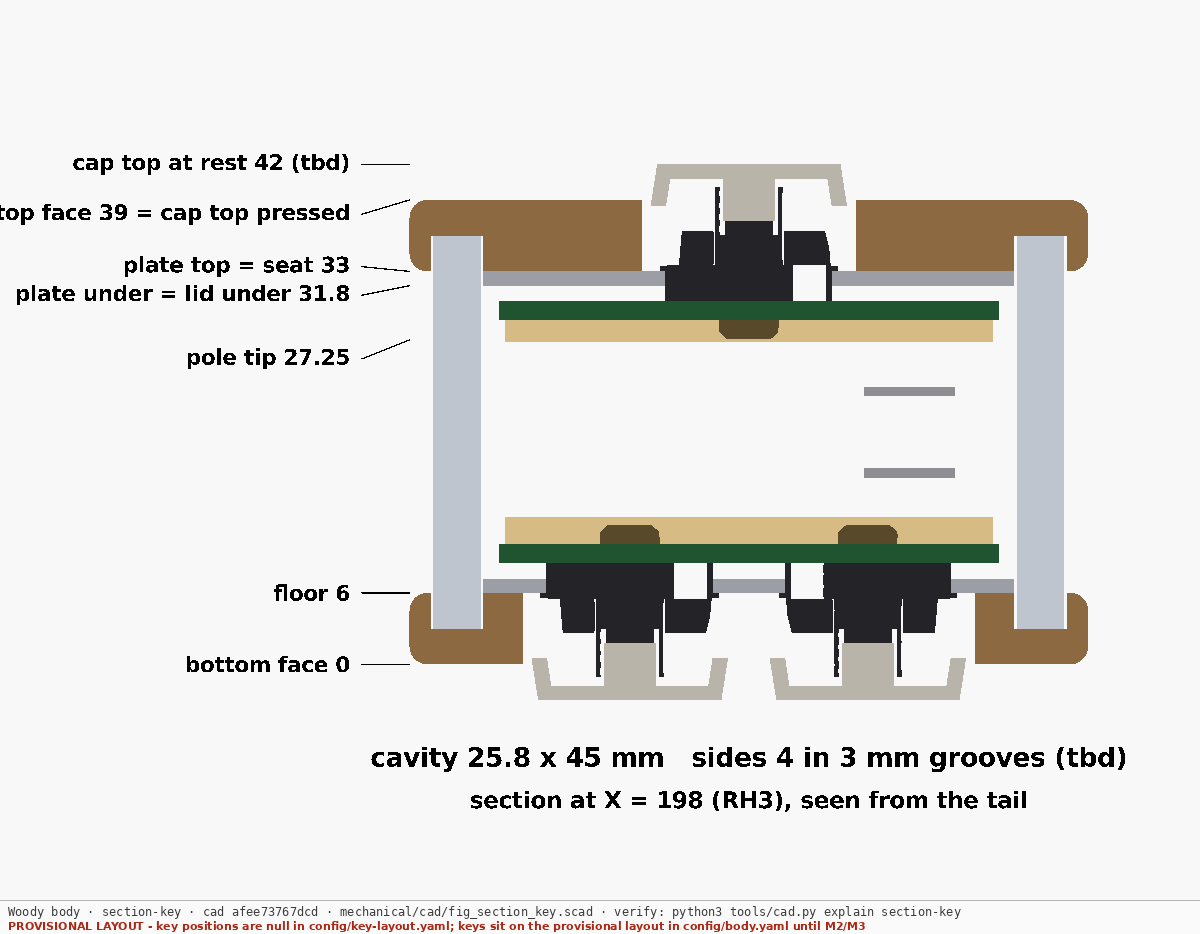
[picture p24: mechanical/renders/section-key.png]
Cross-section through RH3
|  | Tail face |
| Cross-section through the LED matrix The frosted window, flush on its oak lip | Section through a key-board corner A column at a key board's corner (ADR 0025): the stud in the bottom plate, a spacer, the main board, the standoff faced to the gap, the key board, a spacer, the key plate, and the screw whose head sits in a blind pocket in the oak top |

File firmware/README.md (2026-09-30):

# Firmware

**One image** ([ADR 0015](../docs/decisions/0015-one-mcu-no-display.md)):

- `realtime/` — the ESP32-S3-Matrix. Keys, breath, IMU, DAC loop, the LED
  strip (one, ADR 0016) and the 8×8 matrix (the only display), USB MIDI and USB
  configuration. Owns all state and persistence. This is the instrument.

There is no display board and no radio: WiFi and BLE stay off.

PlatformIO, ESP-IDF underneath. Nothing here yet — Track F follows Track E
(see [ROADMAP.md](../ROADMAP.md)).

## Architecture constraints

These come from [ADR 0001](../docs/decisions/0001-mcu-and-board-partitioning.md)
and [the latency budget](../docs/reference/latency-budget.md), and they are not
negotiable without revisiting those:

- **4 kHz loop** for sensor read and DAC update, pinned to one core.
- **Lighting renders on the other core, through RMT.** A matrix or strip update
  must never block the output loop.
- **Asymmetric key debounce** — fire immediately on press, filter only the
  release. A symmetric window puts its full length into the attack. The
  release window is sized against `ks33-contact-bounce`, which is now a
  tracked figure read verbatim off Gateron's own drawing for this exact part
  — so the starting number is published, not guessed, and is deliberately not
  restated here. M1 still measures it, because a vendor maximum at a stated
  actuation speed is not this keyboard's bounce at a player's speed; what M1
  changed is that it now confirms or moves a documented figure instead of
  supplying the only one. Either way, not the conventional 20 ms the 2021
  firmware used.
- **Per-channel smoothing in software**, not in the analog filter. The analog
  filter is fixed; firmware knows what each channel carries.
- **Nothing expressive touches the ESP32's internal ADC.** It is noisy and
  nonlinear, and breath drives a 0–10V output where that shows.
- **There is no radio.** WiFi and BLE are never started, so no transmit burst
  can preempt the output loop or land on the rail the breath path shares
  ([ADR 0015](../docs/decisions/0015-one-mcu-no-display.md)).
- **Refresh everything, every pass. Never write-on-change.** The umbilical is
  write-only — `MISO` was deleted from the cable (ADR 0004) — so nothing
  downstream can ever be read back. *With no readback, shared state can only be
  made safe by being made stateless.* This is the rule, not an optimisation
  note; see below for the failure that produced it.

### Why statelessness, specifically

The design review found this by one route and two diagnostics findings arrived
at it from the opposite direction, so it is worth stating the case once.

The mod channels are `Vout = 4·Vdac − 3·V_ref`, with `V_ref` the shared
**3.3333 V** from DAC channel 7 — **refreshed every pass, like the other five** (ADR 0006, corrected 2026-09-21). *(The
value changed with the two-resistor redraw in `mod-channels.md`; writing the
old 2.5 V into channel 7 against the current 10 k/30 k network gives a
−7.5…+12.5 V window — wrong span, and it clips positive.)* When `CLR` is
asserted, every DAC channel including channel 7 goes to zero scale. Firmware
then rewrites the five signal channels, because those are the ones it thinks of
as signals, and `Voffset` stays at 0. Every mod jack pins at `4 × Vdac`
≈ +11.45 V and stays there.

**`CLR` is asserted by two things, and neither of them is optional.** The
DAC's own **power-on reset**, which fires on every rack power-up — so this is
not a fault case, it is the boot path. And the **`LK-CLR` solder pad**
(`bom.csv`), which asserts `CLR` by hand and exists precisely so that E7–E10
can drive the module into this state deliberately. *(This paragraph said "when
the module watchdog asserts `CLR`" until 2026-09-21. The 74HC123 frame watchdog
is deleted — `digital-and-supervision.md` — and the rule below is the most
load-bearing firmware constraint in the repo, so its stated cause had to be one
that still exists. A reader who checks the old premise, finds the watchdog
gone, and relaxes the rule reintroduces +11.45 V on four jacks.)*

With no `MISO` this is undetectable, and it survives until the next power
cycle. The same shape of bug is latent in every other register the DAC holds
that firmware writes once: the internal-reference enable, and the clear-code
register itself.

The fix costs nothing. **The latency budget already books six DAC words per
pass while five are written**, so the sixth channel fits inside a budget that
was already paid — and refreshing the reference-enable and clear-code registers
periodically costs a word every few thousand passes.

**Breath is outside all of this.** It never passes through the DAC, and since
the in-amp's `REF` pin is grounded rather than driven by a firmware zero
(ADR 0003), no DAC register touches the breath jack at all. Firmware's breath
zero is a subtraction applied to its own ADC copy — the representation it can
actually measure — and never leaves the instrument.

## The instrument must stay recoverable

The body comes apart by cutting its silicone (ADR 0025), and answering a
failed flash that way means cutting the oak top free, unscrewing the key plate
from the cassette's columns, unplugging the Matrix's ribbon and the key
boards' ribbons from the main board (ADR 0017), and bonding it all back with
fresh silicone. Everything here exists so that it never has to be the answer.

- **Two app partitions, with `CONFIG_BOOTLOADER_APP_ROLLBACK_ENABLE`.** There
  is no OTA — no radio — but an image flashed over USB into the inactive slot
  that does not mark itself valid is still rolled back by the bootloader on the
  next boot. It turns the most likely bricking event into a reboot.
- **USB MIDI is opt-in, not the default.** On the ESP32-S3 the internal PHY
  routes to USB-Serial-JTAG *or* USB-OTG, never both. The moment the
  application claims OTG the `DTR`/`RTS` download-mode path is gone. Leaving
  MIDI off until the player enables it keeps the serial-JTAG reset path alive
  through every boot that has not been asked for MIDI.
- **The recovery ladder, in order.** (1) Rollback to the other app slot. (2) USB-Serial-JTAG
  through the tail USB-C slot — which is why MIDI is opt-in. (3) The console
  header on the main board, with the body opened (ADR 0025 — there is no
  service cover since 2026-09-26), for watching a board that boots
  but misbehaves. (4) **Hardware boot-force on the same header**: `EN` and
  `IO0` are not on the ESP32-S3-Matrix's pad rows, so two ribbon conductors
  are soldered to its RESET and BOOT button pads and brought to
  `HDR-SERVICE` (ADR 0018; `hardware/carrier/service-uart/`). Hold `IO0` low,
  pulse `EN`, and the ROM download mode takes a UART flash over the console
  pair — so a corrupted *bootloader* is recovered with the body opened and the
  Matrix still in place. **Only pull `EN` and `IO0` to ground** (open-drain or
  a switch to GND), never drive them high: the Matrix's own buttons short them
  to GND. The two spare GPIO on the ribbon (`IO2`, `IO3`) sit beside fast
  lines as shields; drive them low after boot (`IO3` is a strapping pin
  [from memory], harmless once booted) — pin map in `hardware/carrier/carrier.md`.
- **Exercise the ladder at M8**, before the body closes, so it is known good
  rather than assumed.

## The lights are instrument-side, and so is everything about them

**The LED row and the matrix read the MCU's own digitised breath value.** Not
the jack, not anything that has been through the module's panel knobs — there
is no return path for that and no reason to want one. The lights show what the
player is doing; the knobs scale what the rack receives. See ADR 0014.

Three numbers, all firmware, none of them constants in the source:

- **Zero** — the power-on ADC capture, shared with the note-gating zero.
- **Deadband** — zero plus a measured noise margin. Without it the bottom LED
  flickers with nobody blowing, which looks like a fault and is arithmetic.
  Size it from E2's measured standard deviation; the auto-zero's "quiet" gate
  needs the same figure.
- **Span** — where full brightness lands. A setting, because the sensor's range
  is about twice what real playing produces, so a fixed mapping wastes the top
  of the display.

## Data, not code

Two things are explicitly configuration rather than compiled constants
([ADR 0010](../docs/decisions/0010-key-layout-as-data.md),
[ADR 0006](../docs/decisions/0006-cv-channel-allocation.md)):

- **Fingering table** — a custom fingering system takes a lot of playing to get
  right, and a recompile per experiment is the wrong loop. It covers the 15
  `note` keys only; the four right-thumb switches are `control` and must never
  enter it (ADR 0010).
- **Routing matrix** — four mod channels, each with source, scale, offset, curve
  and slew.

Both live in NVS and are edited over USB.

## Bring-up fixtures

Throwaway test firmware for E-track milestones belongs in `fixtures/`, not in
the instrument firmware. It is a tool, not a deliverable.

## Configuration is over USB

Config is a page on a computer, talking to the instrument over its own USB-C
port, not a menu system and not a phone
([ADR 0015](../docs/decisions/0015-one-mcu-no-display.md)). The matrix shows
status only.

**The transport follows the USB PHY rule above.** With MIDI off — the default —
the only USB function is USB-Serial-JTAG, so configuration rides it (Web Serial
from a browser, or a host tool). With MIDI on, the same framed messages go as
SysEx, which Web MIDI can reach. One message format, two carriers; do not let
configuration be the reason MIDI stops being opt-in.

**Single source of truth:** every config edit round-trips. The page edits, the
instrument validates, applies, persists and echoes back. The page never holds
authoritative state.

Build live telemetry over the same link early — it is a test instrument for the
mechanical and calibration work, not just a configuration convenience.

## USB MIDI

A **bring-up tool, not a feature.** Keys, fingering and breath response get
validated in a DAW before any analog hardware exists (milestone E5). The
instrument is a tethered rack device; USB MIDI does not get to constrain the
design.

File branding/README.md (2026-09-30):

# Branding: the Space Coast Synthesizers mark

The mark etched on bocote and dark walnut

The **orbit-wave mark** for Space Coast Synthesizers, the maker name on the
instrument. "Woody" is the project's working name and is not part of the
brand.

It is a ring in orbit (a planet's path, with a moon on it) and a sine wave
running through it (the sound). The wave is drawn as a brush stroke that
lifts off into a point at both ends. The mark is symbol-only by design, with
no lettering, because small text does not survive laser etching into
figured wood.

## Files

Everything under `export/` is **generated** by [`build.py`](build.py). Do not
edit it by hand: change `SPEC` in `build.py` and rebuild.

| File | Use |
|---|---|
| [`export/scs-orbit-wave-mark.svg`](export/scs-orbit-wave-mark.svg) | **Production artwork.** Exact size in mm, filled outlines only (no strokes, no fonts). Black is the etched area. Send this to the laser shop. |
| [`export/scs-orbit-wave-mark.dxf`](export/scs-orbit-wave-mark.dxf) | The same outlines as five closed polylines, units mm, for laser or CAM software that prefers DXF. |
| [`export/spec.json`](export/spec.json) | Every construction number, plus the measured overall size. |
| [`export/print/scs-mark-test-print-100pct.pdf`](export/print/scs-mark-test-print-100pct.pdf) | US Letter. Print at 100 % and measure the 50 mm bar first. It includes the mark at actual size, a cut-out outline for checking position, the mark on a panel outline, and 45 mm / 36 mm comparisons. |
| [`export/png/scs-mark-black.png`](export/png/scs-mark-black.png), [`scs-mark-white.png`](export/png/scs-mark-white.png) | Transparent PNGs, 2000 px wide, for screens and documents on light or dark backgrounds. |
| [`export/renders/`](export/renders/) | True-scale renders on procedurally generated wood textures. **Illustrative only**: the wood is synthetic, not photographed. `scs-mark-on-*`: plain laser etch on bocote and dark walnut. `scs-mark-epoxy-on-*`: the colour-fill scheme below, on dark oak and dark walnut. |

## Geometry

All dimensions are in mm, at the size the mark is etched.

| | |
|---|---|
| Overall | **54.0 × 39.6** |
| Ring | 36.0 centreline diameter, 3.6 band |
| Wave | One sine cycle, amplitude 6.2, 2.8 wide in the body, brush-tapered to a point over the last 9.0 at each end, 54.0 tip to tip |
| Moon | Ø 7.52, on the ring at upper left (−122° from the +x axis) |
| Clearances | 2.0 around the wave where it crosses the ring, 2.0 around the moon |
| Parts | 5 separate filled shapes: 3 ring arcs, the wave, the moon |

The mark is laid out for the controller's top panel, in the section between
the key runs and the mouthpiece end. Its width is taken from the enclosure
envelope in [ADR 0009](../docs/decisions/0009-enclosure-construction.md).
`PANEL_WIDTH` in `build.py` is used only for the test print and the renders;
**if ADR 0009's width changes, update `PANEL_WIDTH` and check the side margin
in `spec.json`**, because the 54 mm mark does not scale with it.

The smallest feature is the 2.0 mm clearance, which is safe for a laser in
wood. The pointed wave tips will come out slightly soft over their last
~1 mm when etched; that is expected, and it reads as a brush lift.

## Etching notes

- Etch the black areas as **filled raster**, not vector outlines. About
  0.3–0.5 mm deep reads well.
- **Mask the panel** (paper transfer tape or masking tape) before etching.
  Resinous woods smoke-stain around an etch, and the mask takes the stain.
- Etch **after final sanding and before finishing**, so the finish seals the
  etch along with the surface.
- **Test on an offcut of the same board first** to set the depth and check
  that the tips come out cleanly.

## Colour fill (dark woods)

On dark wood the etch can be filled with pigmented epoxy and sanded flush.
The scheme is set in `EPOXY` in `build.py`:

| Part | Colour | sRGB |
|---|---|---|
| Wave | Orange | `#FC4C02` |
| Moon | Orange | `#FC4C02` |
| Ring | Black | `#121214` |

Colour-filled mark on dark oak and dark walnut

The orange carries the mark and the black ring reads as a gloss a shade darker
than the wood, so the eye goes to the sound and the moon first. The sRGB
values are screen references; match the pigment against a poured test coupon,
not the screen.

- Etch **deeper than for a plain burn**, about 0.8–1.5 mm, so the fill has
  something to key into.
- **Seal the etched wood first** (a thin coat of dewaxed shellac), or the
  pigment wicks into the grain around the edges.
- Two colours means **two pours**: mask the ring, pour and cure the orange,
  then pour the black. The 2.0 mm clearances keep the colours apart.
- Pour slightly proud, cure, **sand flush** (220 then 400 grit), then finish
  as normal.
- Use **UV-stable pigment**. Bright oranges fade, and some are fluorescent,
  which fades faster.

## Rebuilding

```sh
pip install -r branding/requirements.txt
python3 branding/build.py
```

The build is **deterministic**: with `SPEC` unchanged it rewrites every file
byte for byte (no timestamps in the PDF or DXF, seeded textures, and a pinned
Python hash seed, which the DXF writer's table order depends on). A diff
under `export/` therefore always means the mark itself changed.

## Licence

**TBD.** [`LICENSE`](../LICENSE) maps every other top-level directory to a
licence, and `branding/` is not in it yet. A brand mark is usually kept out of
the share-alike licences so that forks do not ship under the original maker's
name. What decides it: whether derivatives may carry the Space Coast
Synthesizers mark. Until that is decided and recorded in `LICENSE`, the mark
is not covered by the repository's open licences.

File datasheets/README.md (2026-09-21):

# Datasheets and mechanical drawings

**Actual PDFs, not links.** Four review waves were degraded by every vendor
site being blocked at the egress proxy — dozens of findings were marked
`[from memory]` and several load-bearing numbers had never been read off a real
document. This directory is the fix, and as of wave R7 (2026-09-21) it mostly
works: the LT1641's `I_TIMER`, the OPA2197's output impedance and the KS-33's
clip dimension were the three named here as missing, and **all three are now
read off vendor documents banked in this directory**. Two of the three had been
*wrong*, one of them by a factor of five.

## Rules

- **The PDF lives here.** A link is not a datasheet; the link rots and the
  proxy blocks it on the day you need it.
- **`MANIFEST.csv` has one row per part**, with the SHA-256 of the file, where
  it came from, and when. A file with no manifest row is untrusted.
- **A part that could not be fetched gets a row too**, with `status=BLOCKED`,
  the exact URL and the exact error. An honest gap is useful; a fabricated
  file is not.
- **Verify before committing**: `python3 tools/verify-datasheets.py`. It
  checks that every row's file exists, that a `.pdf` really begins with `%PDF`
  and is larger than 10 kB, that every SHA-256 matches, that a row with no
  file says why, and that nothing sits on disk without a row. Vendor sites
  commonly serve an HTML error page with a `.pdf` filename, which is the
  failure the magic-number check exists for.
- **Non-PDF artefacts are banked too** — dimensioned DXFs, STEP solids, KiCad
  footprints, vendor images — because they carry dimensions the design is
  built from. The KS-33's Z stack and the etherCON's screw pattern both came
  from these rather than from a datasheet.
- **Closing someone else's BLOCKED row: quote it.** When you bank a document
  that fills an earlier gap, put the blocked row's **exact `part` string** in
  your own row's notes together with the word **`SUPERSEDES`**.
  `tools/merge-manifests.py` then reports that row as closed every time it
  runs. This matters because you must not edit their fragment, so the blocked
  row goes on existing — and a reader greps `BLOCKED` to find the gaps. In
  September 2026 three banked documents read as live gaps for exactly this
  reason, and a session nearly spent a wave of agents re-fetching them. The
  tool also guesses at renamed matches and prints them under `CHECK:`, but that
  is a heuristic and it says so: it deliberately will not match `WS2812B-0807`
  to `WS2812B-2020`, because those are different dies.
- **Each researcher writes to `.manifest-R<N>.csv`**, and
  `python3 tools/merge-manifests.py` rebuilds `MANIFEST.csv` from the
  fragments. It is idempotent — edit a fragment, re-run, re-verify. Do not
  hand-edit `MANIFEST.csv`; it is generated.

## How to fetch anything at all from here

**The egress policy is not the same on every session, so measure it before you
plan around it.** Six researchers in waves R1-R6 found every vendor and
distributor host blocked and built an elaborate GitHub-mining method around
that. A seventh wave (R7, 2026-09-21) found ti.com, neutrik.com, murata.com,
gateron.com, files.waveshare.com, farnell.com, docs.rs-online.com,
world-semi.com, onsemi.cn, tai-hao.com and **web.archive.org** all answering
normally. Nine of the seventeen gaps closed by simply asking again.

Spend the first five minutes on a reachability sweep:

```
UA="Mozilla/5.0 (Windows NT 10.0; Win64; x64) AppleWebKit/537.36 (KHTML, like Gecko) Chrome/126.0.0.0 Safari/537.36"
curl -sS -A "$UA" -o /dev/null -w "%{http_code} %{content_type}\n" -L --max-time 40 "<url>"
```

| Lever | Note |
|---|---|
| **`web.archive.org`, via the CDX API** | **The single biggest unlock in R7.** It is how `164112fc.pdf` was recovered after four waves failed: `cdx/search/cdx?url=<host>/<path>&output=text` lists captures, then fetch `web.archive.org/web/<timestamp>id_/<original-url>` for raw bytes. It reaches hosts that are still dead directly — analog.com among them. Use `curl -G --data-urlencode` for any `filter=`, or brackets in the regex break the URL. |
| Mirror hosts | `docs.rs-online.com`, `www.farnell.com/datasheets/<id>.pdf`, `datasheet.lcsc.com`, `www.tme.eu`, `static6.arrow.com`. Farnell in particular served two documents in R7 from URLs an earlier wave had recorded as `HTTP 000`. |
| Regional domains | `www.onsemi.cn` serves what `www.onsemi.com` 403s. `www.tai-hao.com` answers where `taihao.com.tw` does not. Worth trying before declaring a vendor blocked. |
| `git clone https://github.com/<owner>/<repo>` | Works for any public repo. Clone, then `find -iname '*.pdf'`. |
| `raw.githubusercontent.com/...` | Direct fetch of a known path, including binaries. |
| `media.githubusercontent.com/media/...` | **Git-LFS objects.** `raw` returns only a ~130-byte pointer; swapping the host returns the real bytes. |
| The GitHub MCP `search_code` tool | GitHub indexes no binaries: `extension:pdf` always returns zero. Search for *text* files that reference a PDF beside them. |

**A 200 and a `.pdf` filename prove nothing. Three mirrors lied in R7 alone:**

- `docs.rs-online.com/5ab4/0900766b810edab8.pdf`, recorded in an earlier
  BLOCKED row as the LT1641's RS mirror, is a real 195 kB PDF — **of the
  LT4256**, a pin-compatible successor.
- `farnell.com/datasheets/2299370.pdf`, found searching for a 74HC165, is a
  genuine 359 kB PDF containing no occurrence of "165".
- `diodes.com/assets/Datasheets/ds30079.pdf`, found searching for a 1N4148W,
  is the **MMST3906 transistor**.

So: `head -c 4` must be `%PDF`, size over 10 kB, and the part number must appear
in `pdftotext -layout` output. `tools/verify-datasheets.py` enforces the first
two; **only you can enforce the third.** And when a document is vector CAD —
Gateron's drawing, the Laird bead drawings, the Neutrik outlines — `pdftotext`
returns almost nothing and the numbers are only in the picture. Render it
(`pdftoppm -r 150 -png`) and read it.

## What is still missing, and why it matters

**Rewritten 2026-09-21 after wave R7.** Seventeen rows were `BLOCKED` or
`NOT-FETCHED`; **ten of those parts are now banked**, and
`tools/merge-manifests.py` prints their names every time it runs. The earlier
fragments are left exactly as their researchers wrote them — a BLOCKED row is
the honest record of a gap at the time, and editing it would destroy the one
thing it is for — so the same part legitimately appears twice in `MANIFEST.csv`,
once `BLOCKED` with no file and once `OK` with one. **Trust the row with the
file.**

The three that blocked real decisions are all resolved:

- **LT1641-1** — `164112fc.pdf` is banked. It confirmed eight of nine claims
  verbatim, including that foldback is sensed at the `FB` pin, and refuted the
  `VCC` UVLO maximum. `C-TIMER`, `C-GATE`, `R-FB-HI` and `R-FB-LO` all have
  values now and the parts order is unblocked.
- **SP0504BAHT** — banked, and it settled the power question by **not having
  one**: there is no peak-pulse-power spec in the document at all, so the
  0.98 W figure is unsourceable rather than merely wrong.
- **A ferrite bead with an impedance-vs-DC-bias curve** — found, in Laird's
  `MI1206K601R-10`. The judgement that produced this gap was right and is
  upheld: Murata's *PDF* turns out to carry no bias curve either (that data
  lives only in SimSurfing), so a Murata part can be an alternate but not the
  characterised one.

**What is genuinely still open**, and all of it was opened *by* R7 rather than
inherited:

- **WS2812B-0807 — and this one is not a fetch failure, it is a vendor
  negative.** The Waveshare schematic, once banked, showed the matrix is fitted
  with this part and not the WS2812C the corpus assumed. **Worldsemi does not
  publish a datasheet for it**: their own machine-readable datasheet index
  enumerates 68 keys covering every published part — `ws2812b-v6/-v7`, `-mini`,
  `-1313`, `-2020`, `-2427`, `-4020`, all of `ws2812c/d/e` — and has no `0807`
  key in either language, while the control URL for `ws2812b-2020-v6` returns a
  real 1.26 MB PDF. Two XINGLIGHT `XL-0807RGBC-WS2812B` revisions are banked as
  **surrogates, named as such**, and they disagree with each other (12 vs
  19 mA/channel, 7× on quiescent). Tracked as `matrix-led-current`, status
  `blocked` — and **unblocking it now needs a current probe at E1, not another
  fetch.**
- **`5400fc.pdf`** — the LT5400 is banked at rev **fa**, which answers the
  exposed-pad question fully. Rev fc is still wanted because rev fa predates
  the `-7` option, so `LT5400-7` is *not-in-document* rather than refuted.
- **Tai-Hao MT165** — no drawing exists anywhere. Tai-Hao's own store confirms
  16.5 x 16.5 mm and MX-compatible; height, stem depth and profile are
  unpublished. Two independent routes failed; recorded and moved on.

The rest are second sources and substitutes whose absence is recorded in the
relevant BOM row.

**A note on surrogates.** Three rows in this manifest bank a document for a part
that is *not* the one fitted: the two XINGLIGHT 0807 LEDs and the 1986 Toshiba
`TC74HC165P/F` excerpt. Their notes say so in the first line, and they exist
because a bracketing document is worth more than nothing when the real one does
not exist. **They must never be cited as the fitted part's datasheet**, and the
figure they bracket stays `blocked` or carries its bracket explicitly.

## Provenance and licence

These are third-party copyrighted documents, redistributed here for a
one-off personal build so that the design can be verified offline. They are
not covered by this repository's own licence (ADR 0011). Each manifest row
records its source.

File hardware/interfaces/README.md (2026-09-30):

# Interfaces — the circuits that cross a board boundary

Three circuits in this project do not sit on one board. Each was described in
two places until 2026-09-21, and each is now one directory.

| Directory | Runs between |
|---|---|
| [`breath-sense-link/`](breath-sense-link/breath-sense-link.md) | Sensor and excitation buffer on the carrier → 2 m twisted pair → in-amp on the module |
| [`spi-link/`](spi-link/spi-link.md) | Carrier SPI egress → umbilical → the module's 74AHCT125 |
| [`key-chain-loom/`](key-chain-loom/key-chain-loom.md) | Main board → the two key boards, one 1.27 mm IDC ribbon each; the thumb clusters' part is main-board traces |

## Why these are not filed under a board

Because their numbers cannot be derived from one side.

`breath-sense-link` is the clearest case. Its differential pole is derived
from 1 kΩ in **both** legs, and one of those legs is on the other board. Its
CMRR term is *entirely* a statement about whether a resistor is fitted over
there. And it **owns a tracked figure**, `inamp-full-scale`, whose derivation
reaches across the umbilical. Split across two files, each half stated a
budget it could not check.

`docs/reference/pcb-pipeline.md`'s netlist precursor records the cost of
getting this wrong: `AGND` means two different things and `BREATH` means two
different things, and **both collisions are between the two ends of one of
these three blocks**. A transcription that takes net names off the drawings
shorts the breath in-amp input to the breath output jack — and every
downstream check passes, because the merge happens before anything can see it.

Each page's `## Interfaces` table therefore carries an **End** column naming
which side of the cable a node sits on, and the breath table states both
collisions explicitly.

## A disagreement is moved here, not resolved here

Consolidation was done under a content freeze: where the two halves disagreed,
**both statements were moved verbatim and placed adjacent**, with a closing
section saying no winner was picked.

`breath-sense-link.md` carries the live one. One end says `R1b` is worth
"fifty times" the rejection; the other says it buys about 13 dB. Both agree
the part must be fitted. The simulation deck in
`../module/breath-receive-stage/sim/` is what settles it, and it has not been
run.

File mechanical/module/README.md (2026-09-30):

# Eurorack module — parametric CAD

The module's panel, its two boards and every part that sets their positions
and depths, as an OpenSCAD model: [`../cad/module.scad`](../cad/module.scad).
The decisions it realises are [ADR 0023](../../docs/decisions/0023-module-ethercon-and-two-boards.md)
(the NE8FAV, two boards) and [ADR 0024](../../docs/decisions/0024-module-panel-layout-and-stack.md)
(the panel layout and the stack). It goes as far as the line before board
layout: outlines, positions, keep-outs and the cut file, not copper.

**The etherCON is the panel's bottom row** (ADR 0024 point 11, the owner's
instruction of 2026-09-30: *"Power switch should not be underneath the
connector"*). The toggle and the LED are the row above it, so the umbilical's
plug and cable drop below every control. The panel drawing shades that drop
zone, and `drc.echo` holds the rule that keeps controls out of it: *no panel
control under the umbilical: clear of the NE8MX's grip and its cable's drop
zone*, with *the umbilical's plug stands proud of every control* beside it.
Behind the panel, the jack board's notch clears the NE8FAV and steps up
narrower for the toggle's body.

**The toggle throws left–right, ON to the right** (ADR 0024 point 12, the
owner, 2026-09-30: *"to avoid inadvertent triggering"*). One leaf,
`layout.toggle_on`, turns everything that turns with the switch: the panel
hole's D-flat (on the OFF side, the left — NKK's M2011 is ON with its lever
away from the flat), the lever's sweep and the legends derived from it, the
body's terminal field and lugs, the jack board's step and the main board's
wiring keep-out. The panel drawing outlines the sweep and marks ON.

The module, three-quarter front

## The one rule, as for the body

**Change `config/module.yaml`, run the build, commit what it produced.** Never
type a number into a `.scad` file, and never touch a file under `renders/`,
`export/` or the generated parameters. The NE8FAV's numbers are not in
`config/module.yaml` at all: its leaves say `ref: config/body.yaml:ethercon.*`
and `tools/cad.py` copies them, so the connector is dimensioned once for both
ends. A leaf that names a register figure (`figure: panel-width`) fails the
build if the figure moves.

```
config/module.yaml ──┐  (+ config/body.yaml ethercon.*, config/figures.yaml)
                     └─> cad/generated/module-params.scad ─> cad/module.scad ─┬─> module/renders/*.png   (stamped)
datasheets/… (STEP) ─> cad/vendor/{ne8fav,pj398sm,r0904n}.stl ────────────────┤─> module/export/*.dxf    (cut files)
                                                                               ├─> module/drc.echo        (design rules)
                                                                               └─> module/clash.txt       (interference)
                                        every arrow fingerprinted in module/OUTPUTS.csv
```

```
python3 tools/cad.py build                       # everything stale, body and module
python3 tools/cad.py build module-drc module-clash
python3 tools/cad.py check
```

The module is **a separate model with its own spec and ledger**
([`outputs.yaml`](outputs.yaml), `OUTPUTS.csv`), built by the same tool as the
body (`mechanical/README.md` says how staleness is tracked). A change to the
body never marks a module picture stale, nor the reverse.

## What is here

| Path | What it is |
|---|---|
| [`../cad/module.scad`](../cad/module.scad) | The model. `part=` selects the assembly, a 2D cut (`panel`, `jack_board`, `main_board`), the DRC or the PCB geometry |
| `../cad/fig_module_*.scad` | The drawings: the panel, both boards, the side section |
| `../cad/generated/module-params.scad` | **Generated** from `config/module.yaml` |
| [`drc.echo`](drc.echo) | **Generated.** Every design rule, `PASS`/`FAIL`/`NOTE`/`INFO` with its measured value. Pages cite rules by name |
| [`clash.txt`](clash.txt) | **Generated.** Every named envelope against every other |
| [`clash-allow.yaml`](clash-allow.yaml) | Interference the design intends, each with its reason (none yet) |
| `export/panel.dxf` | **Generated.** The panel as it goes to the cutter |
| `export/jack-board.dxf`, `export/main-board.dxf` | **Generated.** The boards' outlines, with the standoff holes |
| [`export/pcb-geometry.echo`](export/pcb-geometry.echo) | **Generated.** Where every board-mounted part is, each face's keep-outs and height limits - the board layout's input, in the body's `pcb-geometry.echo` format |
| [`export/panel-art.echo`](export/panel-art.echo) | **Generated.** Every legend and graphics zone's position, every keep-out on the face, where each part sits - the artwork's and the photographs' input (ADR 0026) |
| `art/` | **Generated** by `tools/panel-art.py`: the print PDF and SVG, the proof, the placement report, the render textures |
| `blender/studio_small_08_1k.hdr` | The photographs' light probe, banked (Poly Haven, CC0) |
| `renders/*.png` | **Generated.** Every image on this page; `photo-*.png` by `tools/render-module.py` |

The clash check and the DRC use **envelopes** from `config/module.yaml`, not
the vendor meshes (`vendor=false`); the meshes are for the pictures. So a
clean clash is only as good as the envelopes, and several are `tbd` — the DRC's
first line lists each one in play.

## The panel's print (ADR 0026)

The module in a slice of a black case: patched, the umbilical home, the power LED lit

The printed graphics follow Pittsburgh Modular's dark Lifeforms language —
black anodise, three grey islands, a light-grey header pill, white lowercase
Inter, every jack's word knocked out of a light-grey pill (they are all
outputs), no scales but OFFSET's − and + — as an original design
([ADR 0026](../../docs/decisions/0026-module-panel-graphics.md)). Nothing in
it is drawn by hand:

```
config/module.yaml art.*  ──┐
cad/module.scad (part=art) ─┴─> export/panel-art.echo ─┐   every zone's position, every keep-out, every part
export/panel.dxf ──────────────────────────────────────┼─> tools/panel-art.py ─┬─> art/panel-art.pdf   spot inks, to the panel maker
datasheets/fonts/Inter-*.ttf ──────────────────────────┘                        ├─> art/panel-art.svg   the master, Inkscape layers
                                                                                ├─> art/panel-art.png   the proof
                                                                                ├─> art/panel-art-check.txt   every word's zone and air
                                                                                └─> art/tex-*.png ─> tools/render-module.py ─> renders/photo-*.png
```

- `module.scad` derives the islands, the `breath` header pill, the
  OFFSET marks and the name between the top screws from the layout, and `drc.echo` checks each
  (`art:` and `art zone:` rules). The legend zones ADR 0024 already had are
  exported with their positions too.
- `tools/panel-art.py` sets the words and **fails** on any placement rule;
  its report, `art/panel-art-check.txt`, gives every word's ink box, its air
  inside its zone, its distance to a cut and to the nearest keep-out, its
  stem, and each ink pair's contrast. The words themselves are
  `config/module.yaml` `art.text.*` — the knobs read *gain, offset, curve*.
- **To the panel maker**: `export/panel.dxf` (the cut) with
  `art/panel-art.pdf` (UV print, "use white ink" and "underprint white" on).
  A 1:1 paper print of the PDF over a cut template first, then one proof panel.

The artwork proofed on the anodise, the cuts shown light

The photographs are Cycles renders of a scripted scene
(`tools/render-module.py`, Blender as a Python module): the panel is
`panel.dxf` extruded, the print is the same textures at
`art.texture.px_mm`, the NE8FAV, the NE8MX and the jacks are the banked
vendor solids, and the knob, the toggle's lever, the nuts, the patch cables
and the case are modelled from `config/module.yaml`. The studio light probe
is Poly Haven's *studio_small_08* (CC0, Sergej Majboroda,
https://polyhaven.com/a/studio_small_08), banked at 1k in `blender/`. Each
render takes tens of minutes on a CPU; `cad.py build` redoes one only when
something it shows moved.

| | |
|---|---|
| Straight on, orthographic, no patch cables: the print against the parts Straight on — for checking the print against the parts | Close-up of the breath knobs and the first outputs' pills The breath knobs, the OFFSET marks, the pitch and breath pills |

## The views

The panel drawing: cuts, centres, legend zones, the washers' reach along their slots

Both boards seen from the panel: the jack board's notch and its step for the toggle, the standoffs, J-B2B-MOD, the parts on each face

Side section through the panel's centre, with every depth and the Palette's limit read both ways

| | |
|---|---|
| The stack pulled apart The stack pulled apart | From behind From behind: the power header, its socket and the ribbon folded down, `U-ISO` (RPA20-2412SAW, ADR 0027) with its filter parts, the trimmers and bulk caps (envelopes) |

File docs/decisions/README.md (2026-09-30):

# Architecture Decision Records

Every non-obvious choice in this project gets a numbered record here: what was
decided, what the alternatives were, and why. Six months from now, "why did I
pick that sensor" should have a written answer.

## Scope

Decisions here are made for **one case: a tethered rack instrument**, powered by
and patched into a Eurorack system. See the design scope in the
[README](../../README.md).

Battery operation, wireless output, standalone use and touring durability are
explicit non-goals. An argument that only holds away from the rack is not a
reason to do anything — several ADRs here previously carried justifications of
that kind and have been trimmed.

## Status values

| Status | Meaning |
|---|---|
| **Accepted** | Decided. Build to this |
| **Open** | Options identified, decision not made. Usually blocking something |
| **Superseded** | Replaced by a later ADR. Kept for the reasoning trail |

## Format

Context, Options, Decision, Consequences. Keep the options that were rejected —
the reasoning behind a rejection is often more useful later than the decision
itself, especially when circumstances change and the rejected option comes back.

When a decision is reversed, do not edit the old ADR. Mark it `Superseded` and
write a new one that says what changed. ADR 0005 is an example: the battery
architecture was real work that got deleted by a better idea, and the record of
why it was deleted is worth keeping.

A **partial** reversal, where most of the decision stands, may instead be
recorded in the same ADR as a dated `## Amendment, <date>` section, with a
dated italic note at each point it changes, and the amendment named in the
`**Status:**` line. ADRs 0017, 0019 and 0020 are examples.

## Index

> **This table is hand-maintained, and on 2026-09-21 three of its fourteen rows
> disagreed with the ADR they point at** — 0007 and 0008 read "(board open)"
> while both files name a selected board, and 0011 read "Open" while the ADR
> says `Accepted`. Each row restates a fact its own target owns, which is
> rule 1 in `CLAUDE.md` broken in the project's own index. **It should be
> generated from the `**Status:**` line of each ADR.** Until it is, check the
> file before trusting the row.

| # | Title | Status |
|---|---|---|
| [0001](0001-mcu-and-board-partitioning.md) | MCU selection and board partitioning | Accepted (partitioning revised by 0013, one MCU since 0015) |
| [0002](0002-key-switches-and-mounting.md) | Key switches and mounting | Accepted |
| [0003](0003-breath-sensing-path.md) | Breath sensing signal path | Accepted |
| [0004](0004-cv-interface-module.md) | CV interface module and umbilical | Accepted |
| [0005](0005-power-architecture.md) | Power architecture | Accepted |
| [0006](0006-cv-channel-allocation.md) | CV channel allocation and calibration | Accepted |
| [0007](0007-imu-selection.md) | IMU selection | Accepted. Board selected: Waveshare ESP32-S3-Matrix |
| [0008](0008-display-selection.md) | Display selection | Superseded by 0015 |
| [0009](0009-enclosure-construction.md) | Enclosure construction | Accepted; how the body closes amended 2026-09-29 by 0025 (no body fasteners, glued shut round the cassette) |
| [0010](0010-key-layout-as-data.md) | Key layout as data | Accepted |
| [0011](0011-licensing.md) | Licensing | Accepted |
| [0012](0012-configuration-interface.md) | Configuration interface | Superseded by 0015 |
| [0013](0013-two-mcu-split.md) | Two-MCU split | Superseded by 0015 |
| [0014](0014-lighting.md) | Lighting | Accepted (geometry amended by 0016; the strip replaced, density and diffusion timing amended 2026-09-30 by 0028) |
| [0015](0015-one-mcu-no-display.md) | One MCU, no display board | Accepted |
| [0016](0016-one-strip-on-the-centre-board.md) | One LED strip, on the centre board | Accepted (placement amended by 0017; the strip replaced 2026-09-30 by 0028) |
| [0017](0017-one-main-board.md) | One main board | Accepted (wiring details in 0018; key-chain connectors amended to through-hole IDC 2026-09-27) |
| [0018](0018-main-board-wiring-decisions.md) | Main board wiring: five decisions | Accepted |
| [0019](0019-kicad-sheets-are-the-source.md) | The KiCad sheets are the source of truth | Accepted, amended 2026-09-27 (the sheet names the bought part; migration in progress) |
| [0020](0020-key-boards-screw-to-the-plate.md) | The key boards are screwed to the key plate | Accepted, amended 2026-09-29 (1.6 mm boards pressed against the switches; Amendment 7: held by the cassette's columns, Amendment 5's bond superseded, by 0025), 2026-09-27 (a mount at each corner, 1.2 mm boards; twice more the same day) and 2026-09-28 (Amendment 4: a PEM flush-head stud pressed into the plate, nothing above it) |
| [0021](0021-pcb-mount-ethercon.md) | The instrument's etherCON is PCB-mounted, on an adapter joined to the main board | Accepted (the instrument's end of ADR 0004's open variant question) |
| [0022](0022-main-board-mount.md) | How the main board is held, and how thick it is | Accepted, amended 2026-09-29 by 0025 (every mount on the bottom plate) |
| [0023](0023-module-ethercon-and-two-boards.md) | The module's etherCON is the NE8FAV too, and the module is two boards | Accepted (the module's end of ADR 0004's open variant question); amended 2026-09-29 by 0024 (no PUSH-tab slot) |
| [0024](0024-module-panel-layout-and-stack.md) | The module's panel layout and board stack | Accepted |
| [0025](0025-the-cassette.md) | The cassette: the internals are one bonded unit, dropped into the shell | Accepted |
| [0026](0026-module-panel-graphics.md) | The module panel's graphic language (dark Lifeforms-style islands, Inter lowercase, spot-colour UV print) | Accepted |
| [0027](0027-isolated-instrument-supply.md) | The instrument's supply is isolated, drawn rail to rail | Accepted |
| [0028](0028-on-board-leds.md) | The lights are thirteen LEDs on the main board, not a strip | Accepted |

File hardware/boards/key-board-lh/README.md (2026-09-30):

# Left-hand key board — `key-board-lh`

The left hand's five keys (LH1–LH5) and their register. The board is held
under the key plate by the cassette's columns, one at each corner (ADR 0025,
ADR 0020 Amendment 7), and one IDC ribbon runs from it to
the main board (ADR 0017, amended). **This board is the project's worked
example.** Every other board is laid out, checked and ordered the way this one
is.

> **Status: orderable as a prototype, not as the instrument's board.** The
> five switch positions this board is built around are **provisional until
> M2/M3**. They come from `config/body.yaml` `layout.lh_gaps` (`nominal`) and
> `layout.lh_offsets` (`tbd`), which stand in until the ergonomic work of M2
> fills `config/key-layout.yaml`'s `x`/`y` (every one `null` on purpose), and
> ROADMAP M3 locks them: "nothing expensive gets cut before M3". An order
> before then is a bring-up board. It proves the circuit, the chain, the fab
> outputs and the assembly, and it can go on a mule. When a key moves, the
> switches, the plate cutouts and the outline all move, and the board gets a
> new revision (below).

What each circuit does, and why, is on its page:
- [`key-register`](../../cluster/key-register/key-register.md)
- [`key-switch-network`](../../cluster/key-switch-network/key-switch-network.md)
- [`key-marker-and-bits`](../../cluster/key-marker-and-bits/key-marker-and-bits.md)
- [`cluster-boards.md`](../../cluster/cluster-boards.md)
- the ribbon: [`key-chain-loom.md`](../../interfaces/key-chain-loom/key-chain-loom.md)

This page covers the board as a made thing.

## Files — what is source, what is generated

| File | What it is |
|---|---|
| `key-board-lh.kicad_sch` (+ the three circuit sheets it places) | **Source.** Every connection, and each part's identity: `Row`, `Pins`, `Manufacturer`, `MPN`, `LCSC`, `Assembly` (ADR 0019) |
| `key-board-lh.kicad_pcb` (+ `.kicad_pro`, which holds its design rules) | **Source**, once laid out: edit it in KiCad 9 |
| `layout.yaml` | The first layout's inputs, and the limits the board is held to. `networks:`, `parts:`, `silk:`, `route:`, `route_first:`, `standoff_footprint:`, `ground_net:` and `power_nets:` are read only by `pcb.py layout`. `rules:`, `fab:` and `connect_first:` are read by **every** `pcb.py check` too: the board's design settings must still say what they say, and each `connect_first` path must stay within its `max_mm` (below) |
| `board-netlist.yaml` | Exported from the sheets (`tools/kicad.py export`) |
| `*.sch.png`, `*.pcb-*.png` | Renders, recorded in `hardware/SHEETS.csv` |
| `fab/` | **Generated** by `tools/pcb.py render`, and recorded in the ledger against the board *and* the sheets. Never edit it by hand: `kicad.py check` fails on a stale file, and on any file in `fab/` that no tool wrote |

`key-board-lh.kicad_prl` (KiCad's per-user view state) is gitignored.

`fab/` holds:
- Gerbers: both coppers, pastes, silkscreens and masks, plus the edge.
- `key-board-lh-job.gbrjob`, which carries the stackup: thickness, finish, mask and silk colour.
- Two drill files, as JLCPCB takes them: `key-board-lh-PTH.drl` (plated: the switch pins, `J-CHAIN` and the vias) and `key-board-lh-NPTH.drl` (unplated: the switches' centre-pole holes and the four corner mount holes, which must stay unplated, ADR 0020). The drill sizes and their arithmetic are in `hardware/lib/README.md`.
- `key-board-lh-pos.csv`, KiCad's own placement export.
- For JLCPCB:
  - `key-board-lh-bom-jlc.csv` — the machine-placed parts, with LCSC numbers.
  - `key-board-lh-cpl-jlc.csv` — their placement.
  - `key-board-lh-hand-assembly.csv` — the parts fitted by hand.

### Rebuild and check

**Prerequisites:** KiCad 9 with its Python module (`pcbnew`), OpenSCAD for the
body CAD, `rsvg-convert`, and the three KiCad 3D models this board's renders
need. `sudo bash tools/setup-env.sh` installs all of them
(`docs/reference/tooling.md` §1). `pcb.py render` refuses to run without the
models rather than render a board with parts missing.

After editing **a circuit sheet**, rebuild everything that places it, in this
order. The same sequence is in `docs/reference/tooling.md` §3:

```
python3 tools/kicad.py export hardware/cluster/<circuit>     # each circuit sheet you edited -> its netlist.yaml
python3 tools/kicad.py export hardware/boards/key-board-lh   # the board -> board-netlist.yaml, ERC
python3 tools/kicad.py export hardware/boards/key-board-rh   # every other board that places the circuit
python3 tools/kicad.py render hardware/cluster/<circuit>     # sheet PNGs, for each of the above
python3 tools/kicad.py render hardware/boards/key-board-lh
python3 tools/kicad.py render hardware/boards/key-board-rh
python3 tools/pcb.py check hardware/boards/key-board-lh      # the layout against the sheets, the fab limits and the body CAD
python3 tools/pcb.py render hardware/boards/key-board-lh     # PCB renders and fab/ (refuses a board that fails check)
python3 tools/kicad.py check                                 # everything above is current; runs pcb.py check too
```

After editing **only the `.kicad_pcb`**, the last three lines are enough.

`pcb.py check` fails on any of these (`docs/reference/tooling.md` §4 has the
full list and the reasons):
- a DRC error **or warning**;
- a schematic-parity difference, or an unrouted connection;
- a design setting that no longer matches `layout.yaml` `rules:`/`fab:`, or
  **any** DRC test set to *ignore* that is not on `tools/pcb.py` `IGNORE_OK`
  (each entry there carries its reason);
- a silkscreen line or text under `fab:`'s minimums, a filled silk shape
  thinner than the minimum line, silk too near a pad's mask opening, silk on
  a via, or silk off the board (KiCad's DRC does not test these);
- a placed silkscreen mark under a part's body (its courtyard), on either
  side, where it could not be read with the part fitted;
- two tracks of one net meeting on one layer at under 90° (an acid trap),
  including a track that ends in the middle of another; a wedge whose apex a
  via or pad of the net fills is not one;
- a `layout.yaml` `connect_first:` connection with no track path of its own,
  or a longer one than its `max_mm` (the decoupler's return to the register's
  ground pin);
- the board's thickness or outline differing from the body CAD's;
- a switch, mount hole or `J-CHAIN` not where the body CAD puts it, or
  turned or on the wrong side;
- a mount hole (H1–H4) that is not NPTH at the body CAD's size, or any copper
  (track, via, pour or another part's pad), on either layer, inside its
  keep-out: the column standoff's and the spacer's footprint, each grown by
  `hardware.kb_mount_float`, plus `rules.clearance` (ADR 0020).

**What holds the owner's rule (every key's network placed the same way round
its switch) after the layout:** only the switches' positions. `layout`
places the networks from the one pattern and stops if any key's three KEY
pads are not the three nearest its T's junction; `check` holds each switch
where the body CAD puts it. Nothing re-checks the networks' own positions
once the `.kicad_pcb` is edited by hand.

`kicad.py check` also holds `J-CHAIN`'s pins to the ribbon's netlist
(`hardware/interfaces/key-chain-loom/netlist.yaml`).

`tools/pcb.py layout … --force` rebuilds the board from scratch, from
`layout.yaml` and the body CAD. It overwrites any hand edits, so run it only
while `layout.yaml` is still the record of the layout. If the router cannot
finish a net, it exits 1 and leaves the existing board as it was.
`docs/reference/tooling.md` §4 covers the tools.

### Making the next board from this one

The right-hand board, or any other simple board, starts from a copy of
`layout.yaml`:
- `cluster:` and `suffix:` name the cluster (`right_hand`, `RH`). The switches,
  mount holes, `J-CHAIN` and outline then come from the body CAD for that cluster.
- `networks:` gives ONE PATTERN for every key: where the T's junction sits
  relative to the key's switch, and which way its resistors and capacitor
  turn. `tools/pcb.py` `network_parts` places each key's three parts from its
  switch's position in the body CAD, so every key's network sits the same way
  round its switch. A key that cannot take the pattern goes under `except:`,
  with the reason; on this board none does.
- `route_first:` names the nets routed before the rest, in order. They are
  the chain nets reaching `J-CHAIN`'s far (odd) row, which a track can reach
  only from behind the header. On this board they also include three key
  lines, which would otherwise be boxed in at the register:
  - `/KEY_LH5` goes first, because U1.14's only way out is a via between the
    pin rows, which SCK would otherwise take;
  - `/KEY_LH4` and `/KEY_LH1` go straight after the chain nets.

  With that order, every net routes on the first pass. `layout.yaml` says why,
  line by line.
- **No mount is plated.** All four stay unplated with their copper
  keep-outs: the key plate is grounded through the columns at the main
  board's mounts (ADR 0025). Amendment 5's `bond_mount` is gone from
  `layout.yaml`; `tools/pcb.py` still supports the key for a board that needs one.
- `connect_first:` names pad-to-pad connections routed before everything,
  each with the `max_mm` that `pcb.py check` then holds it to: here the
  decoupler's return to the register's ground pin. Name the new board's pads.
- `parts:` places everything else: the register, its decoupler, the free-bit
  pull-ups and `C-BULK-CHAIN-<suffix>`.
- `rules:`, `fab:` (the board house), `silk:` (title, revision, date; `at`
  for the parts side, `top_at` for the switch side),
  `standoff_footprint:`, `route:`, `ground_net:` and `power_nets:` are copied
  as they are. `power_nets:` names that board's rail.

Then run `pcb.py layout`, and move parts in `layout.yaml` until `pcb.py check`
passes. Write the board's README from this one.

## Ordering it — JLCPCB

Everything below was checked against JLCPCB's banked pages
(`datasheets/fab/`) on 2026-09-27.

**What to upload:**
1. **PCB:** `fab/` zipped: every `.gbr` file, both `.drl` files and the `.gbrjob`.
2. **Assembly BOM:** `fab/key-board-lh-bom-jlc.csv`.
3. **Assembly CPL:** `fab/key-board-lh-cpl-jlc.csv`.

**The bare board** — the options to pick:

| Setting | Value | Why |
|---|---|---|
| Layers | 2 | |
| Quantity | 5, the fewest JLC makes `[from memory]`; assemble 2 | Economic PCBA assembles 2–30 boards `[datasheets/fab/JLCPCB-PCBA-CAPABILITIES.pdf, "PCB Specs for Economic PCB Assembly"]`. The right-hand board is a different design and a separate order (below) |
| Thickness | `boards.key_board_t` | `config/body.yaml` (ADR 0020); a standard JLC thickness `[datasheets/fab/JLCPCB-PCB-CAPABILITIES.pdf]`. `pcb.py check` holds the stackup to it |
| Material | FR-4 | |
| Surface finish | HASL lead-free | At this thickness, Economic assembly offers HASL only `[JLCPCB-PCBA-CAPABILITIES.pdf]`. `layout.yaml` `fab: finish`, in the stackup and the Gerber job file |
| Solder mask / silkscreen | Green / White | `layout.yaml` `fab:`. Economic assembly at this thickness offers green or black |
| Copper | 1 oz | `layout.yaml` `fab: copper_oz` |
| Outline | from the Gerbers | The outline is the body CAD's key board, `mechanical/export/key-board-lh.dxf`, which holds only the outline (its size is there). The four mount holes (M2.5) are footprints placed from `mechanical/export/pcb-geometry.echo`, in the NPTH drill file |

**The limits this board is held to.** JLCPCB's own limits are banked in
`datasheets/fab/` and written into `layout.yaml` `fab:`. The first layout
copied them into the board's design rules (`key-board-lh.kicad_pro`), and every
`pcb.py check` compares the two, so neither can drift from the other
unreported. To change a limit, change both: in KiCad's Board Setup and in
`layout.yaml`, and say why. The silkscreen limits that KiCad's DRC does not
test are checked by `pcb.py` itself (above).

**Assembly: Economic PCBA, bottom side only**

- **Every machine-placed part is on the bottom** (the side facing the main board).
  - The designators are the plain references on the silkscreen (R1, C6, U1); *The silkscreen*, below, maps each to its BOM row.
- **Check every part's orientation in JLC's placement preview before you pay.**
  - The CPL carries KiCad's own rotations, with KiCad's column headers renamed to JLC's (the banked guide's Method 1, `datasheets/fab/JLCPCB-KICAD-BOM-CPL-GUIDE.pdf`).
  - That guide attributes automatic rotation corrections only to the Fabrication Toolkit plugin (its Method 2). This flow does not use the plugin, so **nothing corrects the rotations**: JLC's preview is the only check.
  - Bottom-side parts are the ones most often shown wrong `[from memory]`, and every part here is on the bottom.
  - The register's (U1) pin 1 is marked on the silkscreen, and that is the one to look at.
  - Record any correction the first order needs in *Revisions* (below), so the next order does not rediscover it.
- **Which parts are in the order.** The resistors and capacitors are JLC **Basic** parts. The register, TI's SN74HCS165DR, is an **Extended** part, not a "Preferred" one, so it carries JLC's feeder-loading fee on Economic assembly ("$3 per extended component", FAQ 6 `[datasheets/fab/JLCPCB-PCBA-FAQ.pdf]`).
  - **Its stock at JLC is thin**: about 112 on 2026-09-27 and 112 again on 2026-09-30 `[web https://jlcpcb.com/partdetail/TexasInstruments-SN74HCS165DR/C2864745, 2026-09-27; JLC component-search API, 2026-09-30]`. Digi-Key held 5,845 at $0.73 the same day `[web https://www.digikey.com/en/products/detail/texas-instruments/SN74HCS165DR/13563029, 2026-09-27]`. **If JLC is short, buy it from Digi-Key** and either send it to JLC as a consigned part or leave it off the JLC order and fit it by hand (SOIC-16, 1.27 mm pitch).
  - **Do not let JLC substitute a plain 74HC165** or a 74LV165A: the part must have Schmitt-trigger inputs with no input transition-rate limit (the `U-KEYS` row says why).
  - Library status as of 2026-09-27 `[web, JLC part pages: jlcpcb.com/partdetail/…/C17408, …/C17520, …/C49678, …/C53134, …/C2864745, and JLC's component-search API]`. It can change, so check it at order.
  - The other part numbers are not repeated here. They are on the sheets, and in `fab/key-board-lh-bom-jlc.csv`.
- **Not in the order:**
  - SW1-SW5 and J1 (`J-CHAIN`), which are in `fab/key-board-lh-hand-assembly.csv`;
  - the mount holes, which are drill only.
- **Bought separately, for the hand assembly.** Only the first two are on the hand list. Sourcing facts below were read on 2026-09-27; check stock at order.
  - **The switches** (BOM row `SW1-n`): Gateron **KS-33H10B050NN-Y24**, Low Profile 2.0 Red, the code on the sheet and the hand list. **Order `-Y24` exactly.** The suffix is the bottom housing's colour, not a year: `-Y24` is black and `-Y31` white. The white-housing spec gives a longer total travel than the black one the body is drawn from (`switch.total_travel`), which would break the flush rule `[datasheets/mechanical/GATERON-KS-33-VENDOR-SPEC-DRAWING.pdf; datasheets/mechanical/GATERON-KS-33-SPEC-WHITE-HOUSING-KS-33H10B050NN-Y31.pdf]`. Not the Silent, not the Low Profile 3.0. Gateron's own store sells the black-housing Red `[web https://www.gateron.com/products/gateron-ks-33-low-profile-switch-set, 2026-09-27]`; whether it ships from a US warehouse is unverified. US sellers found (e.g. LumeKeebs) sell "KS-33 2.0 Red" without naming the housing or the code `[web https://lumekeebs.com/products/gateron-ks-33-low-profile-2-0-mechanical-switches, 2026-09-27]`, so check the code on the packaging.
  - **`J-CHAIN`**, Samtec SHF-106-01-L-D-RA. JLC/LCSC had none (C17202657, stock 0 `[web, JLC API, 2026-09-27]`). DigiKey SHF-106-01-L-D-RA-ND had **only 8 in stock**, with a **4-week factory lead time**, on 2026-09-27 and again on 2026-09-30 `[web https://www.digikey.com/en/products/detail/samtec-inc/SHF-106-01-L-D-RA/8410402]`. An instrument takes `chain-connectors` of them, two on this pair of key boards and two on the main board, so eight is one build and its spares; failing that, Samtec direct (reel variants and samples). Its sourcing is open (its BOM row, and *Open* below).
  - **The corner mount hardware**: at each corner a spacer (`MECH-KB-SPACER`), and the column's standoff and screw (`MECH-COL-STANDOFF`, `MECH-COL-SCREW`), which are bought with the cassette. What each must be, the quantities and the sources are those rows in `hardware/unplaced.csv`; their prices are not repeated here. The spacers and standoffs are faced to length before fitting. The mount is described in *Assembling*, step 2.
  - **`CBL-CHAIN`**, one per board, ordered as in *Assembling*, step 3.
- **A US-sourced hand build.** The UNI-ROYAL resistors stay for JLC assembly: they are JLC **Basic** parts, with no feeder fee. No US distributor stocks them (DigiKey had no result `[web https://www.digikey.com/en/products/result?keywords=0805W8F1000T5E, 2026-09-27]`). For a board built by hand from US stock, use YAGEO RC0805FR-07100RL (100R) and RC0805FR-072K2L (2k2): DigiKey 311-100CRCT-ND / 311-2.20KCRCT-ND; LCSC C105577 / C114561, which are JLC **Extended** `[web https://www.digikey.com/en/products/result?keywords=RC0805FR-07100RL; …=RC0805FR-072K2L; https://jlcpcb.com/partdetail/YAGEO-RC0805FR07100RL/C105577; …/YAGEO-RC0805FR072K2L/C114561, all 2026-09-27]`. The capacitors' parts are already at DigiKey.
- **One instrument needs two key boards.** The right-hand board is a separate design and a separate order: [`../key-board-rh/README.md`](../key-board-rh/README.md), which gives only what differs from this one.
- **The sheets are the source of every part number.** To change a part, set its `LCSC`/`MPN` fields in the circuit sheet and re-render. The BOM row (`hardware/cluster/bom.csv` etc.) says what the part must be; the sheet says which one is bought.

## Assembling the rest by hand

1. **J1** (`J-CHAIN`; the part is on its BOM row and the sheet).
   - It goes on the bottom side, **mouth toward the tail**. The silkscreen marks it: an arrow beside the header points out of its mouth, and pin 1's dot is behind the pins, away from the mouth.
   - **Backward is 3V3 on ground.** The 2×6 pad grid fits the header either way round. Turned 180°, the header puts the ribbon's 3V3 on a ground pin (`key-chain-loom.md`). Fit it with its mouth at the arrow.
   - Seat it flat and solder it from the top (switch) side.
   - The plate has **no window** over the tails. Seated flat, they stop short of the grounded plate (`mechanical/drc.echo` "J-CHAIN pin tails clear of the key plate"), so do not trim them or leave the header standing proud.
2. **The corner mounts, and the switches.** Each of the board's four corners is one of the cassette's columns (ADR 0025; ADR 0020 Amendment 7; the section is `mechanical/renders/section-kb-mount.png`). From the top down: an M2.5 low-head screw whose head bears on the key plate's top face; the key plate; a spacer (Ettinger 5.52.015, faced to `hardware.kb_spacer_l`); the board; and the column's standoff, which is already threaded onto its stud in the bottom plate and clamps the main board. The screw goes down through the plate, the spacer and the board into the standoff. The key board is fitted on the bench, with the rest of the cassette, before anything goes into the wood.
   - **The spacer is not optional**: with the plate it sets the board's depth (`drc.echo` "key-board mount sets the board depth"). Measure each faced spacer with calipers before fitting: `hardware.kb_spacer_l`, within `kb_spacer_l_tol`.
   - Clip the five KS-33s into the key plate's cutouts.
   - Plug the ribbon into this board's J1 (step 3).
   - Stand the board on its four standoffs, set a spacer on each corner, lower the key plate onto the switch pins and the spacers, and drive the four screws into the standoffs.
   - **Then** solder the switch pins, from the bottom. Soldering with the board fixed at depth is what holds it at the depth the pins were designed for (`switch.pcb_below_seat`). How far the hardware's tolerances can move it is `drc.echo` "key-board depth at the hardware's tolerance limits" (*Open* below). Soldering from the bottom needs the key plate, with its board, off the columns and turned over: do it before the cassette's ribbon is plugged at the main board, or with the plate held raised (step 3).
   - **Last, the cassette goes into the shell**, and the oak top is RTV-bonded onto the key plate (ADR 0025), the screws' heads finding their pockets. For service afterwards the silicone is cut and the screws come out from above.
3. **The ribbon** (`CBL-CHAIN`).
   - **Order it as** `FFSD-06-D-<code>-01-N-RN2`. `<code>` is `mechanical/drc.echo` "key-chain cable to order (FFSD length code)", **written with two digits before the point**: Samtec's field is `XX.XX` `[datasheets/connectors/SAMTEC-FFSD-XX-X-XX.XX-01-PRINT.pdf, part-number block]`, so a length under 10 in takes a leading zero, as DigiKey lists FFSD-06-D-06.00-01-N `[web https://www.digikey.com/en/products/detail/samtec-inc/FFSD-06-D-06-00-01-N/6678085, 2026-09-27]`. The print takes any overall length in that field above a 1.00 in minimum; it states increments only for the daisy-chain option, which this cable does not use (same print, sheet 1). Type the full part number into Samtec's configurator and check it echoes back before paying, since the series is non-returnable. It is the overall length in **inches**, over both sockets, as the FFSD print measures it, with the print's −0.125 in tolerance already covered. `-RN2` reverses the notch on the second socket. **Do not type the millimetre length** ("key-chain ribbon length (derived)") into the part number: read as inches, it orders a cable about 25 times too long.
   - **Meter every cable before it is first powered**, not only the first one. Check it by *Bring-up*, step 2.
   - Plug it in with the key plate held raised straight up off its columns, before the plate is screwed down (`routing.chain_service`, `routing.chain_raise`). That is the position its length was derived for.
   - With `-RN2`, the main board's socket's cable leaves **upward** and the key board's leaves **downward**. The two face each other, and closed, the ribbon folds into a flat hairpin between the two plugs' heights (`key-chain-loom.md`). **A cable whose ends both leave downward is a standard cable, without `-RN2`, and it is wrong.**
4. **Conformal coat** (`MECH-COAT`), once the board has passed *Bring-up*: brush it on the bottom (parts) face only, with J1's mouth masked, and leave the switch side bare (`cluster-boards.md`, *Still open*, says why).

## Bring-up

Before the first key board goes into an instrument, check it on the bench.
**There are no test pads** (owner, 2026-09-29: a one-off build is probed by
hand). Everything is reached at J1's pin tails on the bottom, which carry the
whole chain (`hardware/interfaces/key-chain-loom/key-chain-loom.md`, the
key-board end):

| J1 pin | Signal |
|---|---|
| 3 | 3V3 |
| 4, 6, 8, 10, 12 | GND |
| 11 | SCK |
| 9 | SH/LD |
| 7 | SER |
| 5 | QH |

A clip lead on the header's pin tails, or a spare ribbon with an IDC plug cut
open, is the bench harness.

1. **No shorts.** Measure J1 pin 3 (3V3) to pin 4 (GND) with no power: it must not read as a short.
2. **Every cable's pinout, with a meter, before it is first powered.**
   - With both ends free, conductor 10 at one end must reach the other socket's position 3 (3V3), and conductor 2 its position 11 (SCK).
   - That is the `-RN2` map, key pin = 13 − main pin (`key-chain-loom.md`). The map is symmetric, so either end can be taken as the main-board end.
   - A cable without `-RN2` looks right on the drawn route and puts 3V3 on a ground pin. Nothing mechanical shows it, so check every cable, spares and replacements included.
3. **Tie SER.** Nothing drives SER on the bench, and a floating CMOS input draws current and shifts in undefined bits. Tie J1 pin 7 (SER) to a GND pin or to pin 3 (3V3).
4. **Power.** Feed 3.3 V between J1 pin 3 (3V3) and a GND pin (current-limited to ~20 mA).
   - With no key pressed, and SER tied, the draw should be near zero: the register's quiescent current is microamps `[datasheets/logic/SN74HCS165-ti-scls828a.pdf p.6]`. A reading of milliamps with no key pressed is a fault.
   - Each pressed key adds its pull-up's current (`key-scan-current`, on `key-switch-network.md`).
5. **The chain.** Drive SH/LD low then high, then clock SCK, and watch QH.
   - It shifts out this board's eight bits, H first: LH1..LH5, then the two marker bits and the free bit, in `key-marker-and-bits/allocation.yaml`'s order. Idle, each key bit and the free bit read high, and the markers read the pattern `marker-bits` gives this device.
   - Each key reads low while pressed.
   - Clocks past the 8th shift in the level SER is tied to.
   - Firmware normally does this; with a logic analyser on J1's pins it is visible without one.
6. **The rail, in the instrument.** On the real main board and ribbon, scope the key board's VCC (J1 pin 3 to a GND pin, or across C6) while the chain shifts. `FB-CHAIN` and `C-DECOUPLE-165` form a lightly damped LC (the `FB-CHAIN` row). The simulation (`hardware/interfaces/key-chain-loom/sim/`, `rail-as-ordered`) keeps this rail well inside its limit with C7 fitted, and inside it even without C7 (`rail-without-bulk`), so expect at most a small ring after each burst and each key change. A larger one means the bead or the ribbon is not what the simulation assumes: record it in *Revisions*. The bench supply has no bead, so this step needs the main board.

## The silkscreen

Both sides carry it, every mark clear of the parts, so it reads with them
fitted: `pcb.py check` fails any silkscreen under a part's body (its
courtyard). The parts side is mirrored so it reads from below. The straight-down
renders, `key-board-lh.pcb-plan-bottom.png` and `-plan-top.png`, show it as a
builder sees it.

**References are plain numbers** (owner, 2026-09-28): R1, C1, U1, as the
schematic, the placement file and the hand-assembly list all name them. Each
part's BOM row is its `Row` field; the sheet a key's network sits on (LH1..LH5)
is how the tools find it.

| Reference | BOM row | What it is |
|---|---|---|
| SW*n*, *n* = 1-5 | `SW1-n` | the switch of key LH*n* |
| R(2*n*-1): R1, R3, R5, R7, R9 | `R-KEY-SER` | key LH*n*'s series resistor |
| R(2*n*): R2, R4, R6, R8, R10 | `R-KEY-PU` | key LH*n*'s pull-up |
| C*n*: C1-C5 | `C-KEY` | key LH*n*'s capacitor |
| R11 | `R-KEY-PU` | the free input's pull-up (sheet FREE3) |
| C6 | `C-DECOUPLE-165` | the register's decoupler |
| C7 | `C-BULK-CHAIN` | the rail's reservoir, beside J1's 3V3 pin |
| U1 | `U-KEYS` | the register, SN74HCS165 |
| J1 | `J-CHAIN` | the key chain's header |
| H1-H4 | (board only) | the corner mounts' holes |

**Parts side (bottom):** every part's reference beside it. Each key's three
network parts carry theirs the same way round the network, as the parts sit
round the switch (the two resistors' along them, beside the column), with the
key's name (LH1..LH5) beside its capacitor;
J1's pin 1 dot and an arrow out of its mouth; `MOUTH` and an arrow at the
mouth end; the title block (`layout.yaml` `silk:`).

**Switch side (top):** each switch's reference and key (`SW1 LH1`) beside it;
J1 with pin 1's dot and the arrow out of its mouth, where it is soldered;
`MOUTH`; the title block again (`silk:` `top_at`).

## Revisions

| Rev | Date | What changed | Where |
|---|---|---|---|
| A | 2026-09-27 | First layout: every key's network the same T in the same place round its switch, six test pads in one row (QH, SER, GND, SCK, SH/LD, 3V3), C7 (`C-BULK-CHAIN`), silkscreen on both sides, no acute track junction (`pcb.py check` tests every join, a track ending mid-track included). Not yet ordered; re-laid out on the same date for the screwed corner mount (keep-outs from the nut and the spacer/washer; ADR 0020 Amendment 3 then moved the heads from plugged bores into blind pockets, which changes nothing on the board); on 2026-09-28, C7 made a fitted, machine-placed part (it had been a do-not-fit footprint; owner: it costs cents) and J-CHAIN's pads lengthened on their free side; the same day the corner mounts went to M2.5 for PEM studs pressed flush into the plate (ADR 0020 Amendment 4: larger holes and keep-outs, mounts 0.2 further in), and the washer dropped, the spacer taking its length; on 2026-09-29 re-laid out for the cassette's columns (ADR 0025): no bonded mount (Amendment 5's is superseded), the mouth end 0.6 and the tail end 0.2 longer, J-CHAIN 0.5 further toward the tail and the register, its decoupler, R11 and C7 moved 0.5 with it | git history of this directory |

To make a revision, edit the board in KiCad, change the revision and date in
the title block and in the silkscreen text, and copy them into
`layout.yaml` `silk:` so a re-layout keeps them. Then re-render and add a row
here. Record any correction an order needed (a part rotation in JLC's preview,
a drill that did not fit) in the row.

## Open, and what decides each

| Open | Decided by |
|---|---|
| **The switch positions** (`layout.lh_gaps`, `layout.lh_offsets` `tbd`; `config/key-layout.yaml` `x`/`y` replace them) | M2 on the mule, locked at M3 |
| The FFSD socket's stand-out from the header's mouth, `boards.chain_plug_proud`. The print does not dimension it, and it decides whether the cable clears the shroud's mouth at all, not only the ribbon's fold | M4, the first mated pair |
| The mount's spacers, faced to `hardware.kb_spacer_l` (no stocked M2.5 spacer has that length), and the column's standoff and screw (`MECH-COL-STANDOFF`, `MECH-COL-SCREW`) | the first fit; M4, with the parts bought |
| The board depth at the hardware's tolerance limits: the worst case reaches the window's shoulder end (`drc.echo` "key-board depth at the hardware's tolerance limits") | the first board, fitted |
| The register's supply: JLC's stock is thin (above) | the first order |
| J-CHAIN's supply: none at JLC, 8 at DigiKey (above); buy them with this order, or from Samtec. A stocked alternative is not a drop-in: its footprint is on three boards | the first order |
| J-CHAIN's pads' ring is at JLC's absolute minimum on the sides facing a neighbour. The 1.27 mm pitch both ways leaves no room there. The pads are lengthened on their free side instead (`hardware/lib/README.md`, the IDC header's row); ask JLC's review to accept the thin side | the first order |
| Part orientation in JLC's placement preview (above) | the first order |
| No 3D model of J-CHAIN in the renders (Samtec's is behind a login; `datasheets/.manifest-R12.csv` records the attempt) | nothing blocks on it |
| The main board's end of the ribbon | the main board's layout |

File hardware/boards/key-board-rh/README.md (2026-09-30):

# Right-hand key board — `key-board-rh`

The right hand's six keys (RH1–RH6) and their register. **It is made, checked,
ordered, assembled and brought up exactly as the left-hand board is**, and
[`../key-board-lh/README.md`](../key-board-lh/README.md) is the procedure for
all of it. This page gives only what differs. Where it says nothing, the
left-hand page holds, with `key-board-rh` for `key-board-lh` in every path.

> **Status: orderable as a prototype, not as the instrument's board**, for the
> same reason as the left-hand board. The six switch positions come from
> `config/body.yaml` `layout.rh_gaps` and `layout.rh_offsets` until M2 fills
> `config/key-layout.yaml`, and M3 locks them.

## What differs from the left-hand board

| | Left hand | This board |
|---|---|---|
| Keys | five, LH1–LH5, on inputs H..D | **six**, RH1–RH6, on inputs H..C |
| The register's other inputs | A is a free input with its pull-up (R11, sheet FREE3); B and C are the markers | **no free input**: A and B are the markers (`key-marker-and-bits/allocation.yaml`) |
| The register's decoupler | C6, across the ends of pins 16 and 15 | **C7, below the register's J-CHAIN end, beside pin 8** (`layout.yaml` says why: two key lines leave the far row here, and the left-hand board's place walls them in) |
| The register's far-row ground pins | reached by the pour | **strapped by tracks of their own**, pin 12 (the low marker) to pin 8 and pin 15 (CLK INH) to pin 12, held by `pcb.py check` (`layout.yaml` `connect_first:`): the far-row key lines box them in, so no pour reaches them |
| The register's place | level with LH3 | 6.0 past RH3's level, where the header's new place leaves room for SCK and SH/LD between them (ADR 0025 moved `J-CHAIN`), and 0.5 further from the key row, for the room those lines need. **Marginal**: `layout.yaml` records what else was tried |
| The rail's reservoir | C7 | **C8** |
| SER comes from / QH goes to | the main board / the left thumb (`/CHAIN_SER_LH`, `/HOP_LH_LT`) | the left thumb / the right thumb (`/HOP_LT_RH`, `/HOP_RH_RT`), `key-chain-loom.md` |
| Its rail | `V3V3_CHAIN_LH` | `V3V3_CHAIN_RH` |

Everything else is the same part, placed the same way: every key's network
the same T round its own switch (`layout.yaml` `networks:`, the same
pattern), J1 where the body
CAD puts it, the four corner mounts, the rules and the board house's limits.

## The references

As the left-hand board's table, for six keys:

| Reference | BOM row | What it is |
|---|---|---|
| SW*n*, *n* = 1-6 | `SW1-n` | the switch of key RH*n* |
| R(2*n*-1): R1, R3, … R11 | `R-KEY-SER` | key RH*n*'s series resistor |
| R(2*n*): R2, R4, … R12 | `R-KEY-PU` | key RH*n*'s pull-up |
| C*n*: C1-C6 | `C-KEY` | key RH*n*'s capacitor |
| C7 | `C-DECOUPLE-165` | the register's decoupler |
| C8 | `C-BULK-CHAIN` | the rail's reservoir, beside J1's 3V3 pin |
| U1 | `U-KEYS` | the register, SN74HCS165 |
| J1 | `J-CHAIN` | the key chain's header |
| H1-H4 | (board only) | the corner mounts' holes |

## Ordering

As the left-hand board, with this board's `fab/` files. It is a **separate
design and a separate order**: one instrument needs one of each. For the
hand assembly, buy **six** switches, not five. `J-CHAIN`'s stock (the
left-hand page) has to cover both boards.

## Bring-up

As the left-hand board's, with two differences at step 5 (the chain): the
eight bits out, H first, are RH1..RH6 and then the two marker bits, in
`key-marker-and-bits/allocation.yaml`'s order, and there is no free bit.

## Simulation

`sim/`, generated from this board's netlist as the left-hand board's is,
with that board's register model and parameters imported by path, so they
are stated once. At every corner: every key input H..C clears the register's
thresholds open and closed, the high marker (A) reads high, and the draw with
every key closed is six keys' `key-scan-current`.

## Revisions

| Rev | Date | What changed | Where |
|---|---|---|---|
| A | 2026-09-28 | First layout, from the left-hand board's (`layout.yaml`). Not yet ordered; re-laid out 2026-09-29 for the cassette's columns (ADR 0025): the mouth end 0.6 and the tail end 0.2 longer, `J-CHAIN` 13.0 further toward the tail where the shorter ribbon lets the body CAD put it, the register, C7 and C8 following it, the switch side's title moved off the header's tails | git history of this directory |

## Open, and what decides each

The left-hand page's *Open* table holds for this board too. This board adds
nothing to it.

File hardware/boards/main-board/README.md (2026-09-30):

# Main board — `main-board`

The one long board at the thumb level (ADR 0017). It carries:
- the thumb switches and both thumb registers;
- the carrier's circuits: the breath sensor's reference, buffer and ADC, power
  entry, the LED drive and the LED row (ADR 0028), the service header and the
  SPI egress;
- the key chain's two ribbon headers;
- `J-UMB`, where the umbilical arrives from the etherCON's adapter (ADR 0021).

The Matrix is on the lid and reaches it by a ribbon into `J-MCU`. The board
is part of the cassette (ADR 0025): every one of its mounts stands on the one
bottom plate, and eight of them are columns up to the key boards (ADR 0022 as
amended).

> **Status: schematic done, layout not started.** The sheets are the source
> and pass KiCad's ERC. Every part has its footprint and bought part on its
> symbol (`Footprint`, `Manufacturer`, `MPN`, `LCSC`, `Assembly`), from
> selections whose datasheets are banked, except those under *Open*. The
> board's outline and every placement the body fixes are exported
> (`mechanical/export/main-board.dxf`, the `main` entries in
> `mechanical/export/pcb-geometry.echo`). The thumb switch positions are
> provisional until M2/M3, as the key boards' are.

What each circuit does, and why, is on its page:
- [`carrier.md`](../../carrier/carrier.md), the board's own page, and its
  circuits:
  - [`breath-adc`](../../carrier/breath-adc/breath-adc.md)
  - [`breath-excitation-reference`](../../carrier/breath-excitation-reference/breath-excitation-reference.md)
  - [`power-entry-instrument`](../../carrier/power-entry-instrument/power-entry-instrument.md)
  - [`service-uart`](../../carrier/service-uart/service-uart.md)
  - [`led-strip-drive`](../../carrier/led-strip-drive/led-strip-drive.md)
- The thumb clusters:
  - [`key-register`](../../cluster/key-register/key-register.md)
  - [`key-switch-network`](../../cluster/key-switch-network/key-switch-network.md)
  - [`key-marker-and-bits`](../../cluster/key-marker-and-bits/key-marker-and-bits.md)
- The interfaces whose main-board parts the root sheet draws:
  - [`key-chain-loom`](../../interfaces/key-chain-loom/key-chain-loom.md)
  - [`breath-sense-link`](../../interfaces/breath-sense-link/breath-sense-link.md)
  - [`spi-link`](../../interfaces/spi-link/spi-link.md)
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

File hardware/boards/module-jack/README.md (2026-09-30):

# Module jack board — `module-jack`

The Eurorack module's front board (ADR 0023), behind the panel where the
jacks' bodies put it: the six jacks, the three pots and the power LED, and
nothing else. It is a U whose notch clears the etherCON (ADR 0024).
Everything it connects to is on [`module-main`](../module-main/README.md),
through `J-B2B-MOD`.

> **Status: schematic done, layout not started.** The sheets are the source
> and pass KiCad's ERC. Every part has a footprint; the parts still missing a
> bought part are under *Open*.
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

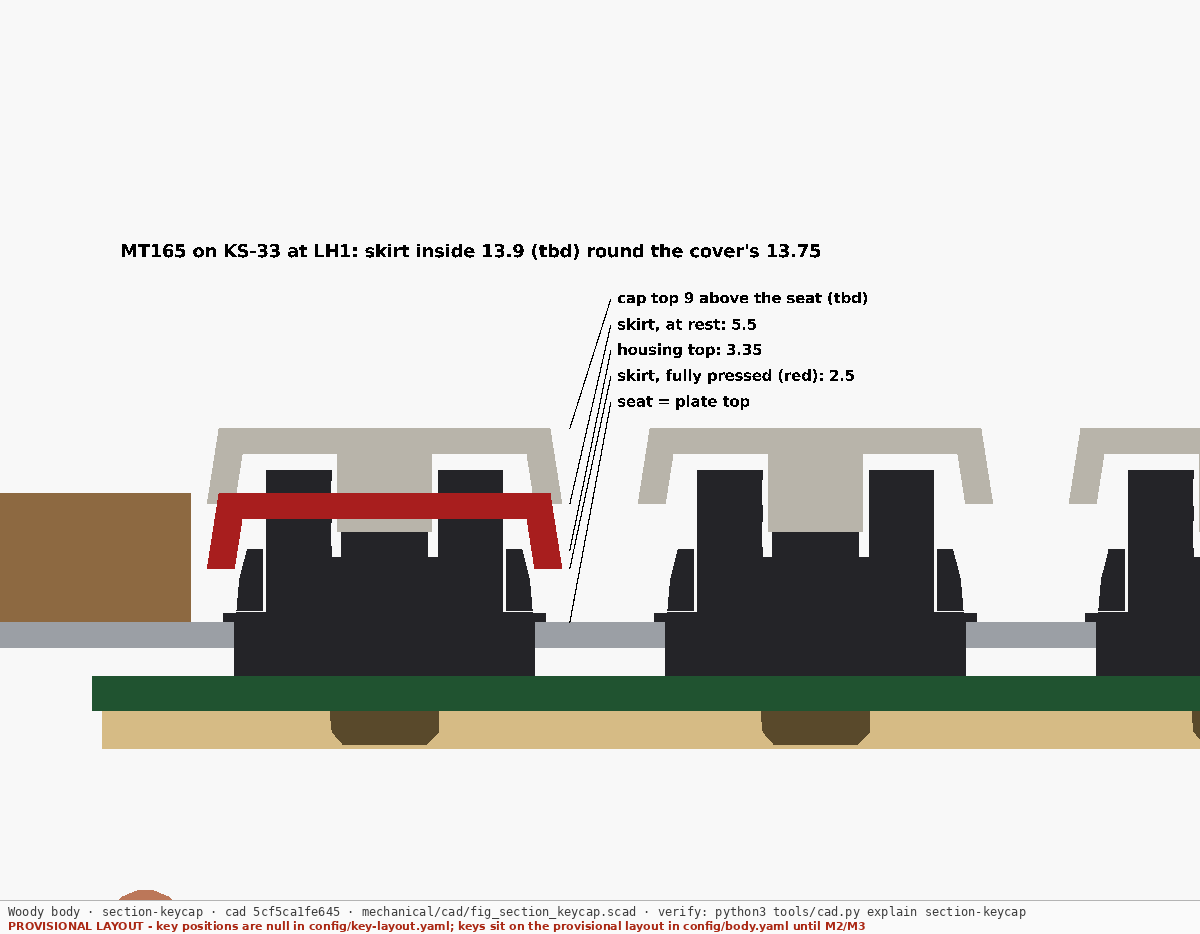
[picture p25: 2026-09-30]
mechanical/renders/section-keycap.png

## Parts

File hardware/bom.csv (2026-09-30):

ref | category | part | manufacturer | description | package | qty | status | source | adr | notes
U-BUCK | controller | R-78E5.0-1.0 | Recom | 12V to 5V switching regulator module | SIP-3 THROUGH-HOLE | 1 | candidate |  | 0015 | 3-pin SIP on a 7805 footprint - no inductor, no feedback network, no layout risk. ONE: the one dev board, the 8x8 matrix and the level shifter (ADR 0015 - there is no display board). Its share of the clamp-legal worst case is 68-78% of 1A (power-entry-instrument.md). IT IS 10.4mm TALL UPRIGHT, which fits anywhere on the main board, under the key boards included (mechanical/drc.echo 'main board parts room under the key boards' and 'regulator block fits where it stands') - no need to lay it flat. *** MINIMUM INPUT IS 8V FOR THE 5.0V PART, NOT THE 7V ON THE FEATURES LINE - THAT 7V IS THE 3.3V PART'S. *** The front page says 'Wide input range (7V - 28V)' and the selection table says R-78E3.3-1.0 = 7-28, R-78E5.0-1.0 = 8-28. Not binding here - worst case at the buck input is ~10.96V (rack at 11.4V, less ~0.28V of Schottky, ~36mV of R-ILIM and FET, ~121mV in 4m of Cat5 at 360mA), so ~3V of margin and even a 20% rack sag clears it - but anyone sizing the umbilical against '7V' is working to the wrong part. DERATING: 100% of rated load from -40C to +60C ambient, then linear to 60% at +85C with a hard cutoff, natural convection. At 65C ambient that permits 92% against the 69-78% actually drawn, ~14 points of margin, and 78% stays legal to ~73.8C. SWITCHING FREQUENCY 330kHz for the 3.3V and 5V outputs (570kHz for 12V) - the figure C-AA-ADC is sized against. Max capacitive load 220uF. No minimum load on the 5V part. Short-circuit protection is CONTINUOUS WITH AUTOMATIC RECOVERY, not l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
C-STRIP-BULK | controller | 470uF 25V electrolytic | Nichicon | Bulk at the LED row's 12V feed point | SMD can 10 x 10mm | 1 | selected |  | 0028 | Bulk belongs at the load: the row's PWM steps its whole current at once, and a ferrite is a wire at that rate. ONE, at the row's feed end on the main board, where the 12V from J-UMB reaches it, the 100 nF at each LED (C-LED) taking the edges (ADR 0028). UCW1E471MNL1GS (LCSC C340751): 25 V on the 12 V feed
L-BUCK-IN | controller | 22uH shielded power inductor, >=1A | Sunlord | LC between the umbilical node and the buck input | SMD 6.0 x 6.0 x 2.8mm | 1 | selected |  | 0004 | A real inductor, not a bead. SWPA6028S220MT (LCSC C51349), 22 uH: the value the input LC's derivation uses (power-entry-instrument.md)
D-USBOR | controller | SS14 | Vishay | ORs USB VBUS with the umbilical-derived 5V rail for bench use | DO-214AC (SMA) | 1 | selected |  | 0005 | One diode from the buck into the dev board's 5V node, which USB VBUS also feeds. Bench affordance for E5, explicitly not a standalone mode. SS14-E3/61T (LCSC C47460): SMA like D-REVSHUNT's SMC, so machine-placed with no hand step, and 2.29 max high [ds SS14.pdf p.3], inside the main board's SMD height. VF 0.50 V max at 1 A [ds p.2]; at 0.7-0.8 A it drops about 0.45 V, leaving about 4.55 V at the dev board's 5V pin - fine for its 3V3 LDO [calc]. Dissipation 0.78 A x 0.45 V = 0.35 W, +31 C at RthJA 88 C/W [calc, ds p.2]. The breath sensor is not on this rail
C-BUCK-IN | controller | 100uF 25V electrolytic | Nichicon | Bulk cap at the umbilical entry / buck input - the C of L-BUCK-IN's LC | SMD can 6.3 x 5.8mm | 1 | selected |  | 0004 | Completes the LC: L-BUCK-IN had an L and no C. One buck and one capacitor. Also the capacitance the module load switch's inrush ramp is sized against (ADR 0005). 25V part on a 12V rail for derating. UCM1E101MCL1GS (LCSC C729678): AN ELECTROLYTIC, NEVER A CERAMIC - its ESR is the LC's damping (power-entry-instrument.md, the input LC)
D-TVS-PWR | controller | SMAJ15A | multiple | TVS across the umbilical power pair at the instrument | DO-214AC | 1 | candidate |  | 0005 | 15V standoff on a 12V rail. The power pair is the one the old 6-channel array could never have covered - six channels against eight conductors, and the six non-power ones are the natural fit
D-REVSHUNT | controller | SS34 | multiple | Shunt diode across the umbilical power pair at the instrument | DO-214AB (SMC) | 1 | candidate |  | 0004 | UNRETROFITTABLE. A rollover/console RJ45 lead swaps 3 and 6, which on the T568B map are +12V and PWR_GND - reverse polarity into the instrument, from a consumable patch lead that looks identical to a good one. Cathode to the +12V pin: reversed, it conducts hard, the module's LT1641-1 sees a short and LATCHES OFF, and the panel LED says so - the load switch becomes the fuse. *** PACKAGE IS DO-214AB (SMC), NOT DO-214AC *** [SS34.pdf p.1, 'MECHANICAL DATA / Case: SMC (DO-214AB)']. DO-214AC is the SS14's package, and the two are a footprint apart on unretrofittable reverse-polarity protection sitting on the +12V pin - check it against the drawing before the board goes out
NT-AGND | controller | Net tie, 2 pads, copper only |  | The analog star's single tie: AGND_INST to PWR_GND at one point | net tie footprint (no part) | 1 | decided |  | 0003 | COPPER, NOT A PART: nothing is bought or placed. The one place AGND_INST (an island on layer 2) meets the PWR_GND plane, under U-ADC between its VSS and its digital pins, so the ADC's SPI edges return straight into the plane (power-entry-instrument.md section 2). The net tie lets KiCad's DRC allow that join there and nowhere else. Assembly: none
U-REF-BREATH | controller | REF5050IDR | TI | 5.000V precision series reference for the breath sensor supply | SOIC-8 (1.27mm pitch) | 1 | selected |  | 0003 | The MPXV4006DP is ratiometric, so ITS SUPPLY IS ITS SCALE FACTOR - that is the whole reason for a separate reference here. Buffered by half of U-BUF, and see R-ISO-REF for the network that makes that buffer stable. THE HIGH GRADE, NO 'A' IN THE ORDER CODE: grade and accuracy are figures.yaml ref5050-grade, and are not restated here. The 'A' suffix is the WORSE (Standard) grade [ds REF5050.pdf SBOS410O Table 4-2 p.3], the opposite of what a reader expects from a letter suffix - do not let a substitution add it back. Same SOIC-8 and pinout for both grades [ds Table 5-1 p.4]. TI REF5050IDR, LCSC C24696, 4401 in stock at USD 1.92 (1-9) [web jlcpcb.com parts search 2026-09-30]. FETCH NOTE: ti.com/lit/ds/symlink/ref5050.pdf is a 404 since rev O; the working URL is ti.com/lit/ds/sbos410/sbos410.pdf
U-BUF | controller | OPA2197IDR | TI | Dual RRIO op-amp: breath buffer + reference buffer | SOIC-8 (1.27mm pitch) | 1 | candidate |  | 0003 | SOIC-8, and it RUNS ON +12V, NOT 5V: a +12V fault on the BREATH conductor is then at the rail, so there is no clamp current and the >=3.3k protection-resistor requirement goes away. Same part as the module op-amps - DEVICE FACTS ARE ON U-OPA-PITCH and are not repeated here. STABILITY IS THE WHOLE OF THIS ROW. The reference half drives the sensor's 100nF decoupler ALONE - C-REF-OUT is on the REF5050, not on this output (see figures.yaml cref-out-node). Against the specified 375 ohm open-loop Zo that is 1.5 degrees of phase margin as a bare follower, so IT MUST BE COMPENSATED, with TI's own dual-feedback network [SBOS737C Figure 56]: R-ISO-REF 37.4R, R-FB-REF 10k taken at VS, R-FBX-REF 100R + C-FB-REF 1nF at this pin. Its phase margin is figures.yaml riso-ref-phase-margin (sim/), AND the DC error across R-ISO-REF is exactly zero, so the 2% ratiometric objection to an out-of-loop resistor never has to be paid - see figures.yaml riso-ref-topology
C-REF-OUT | controller | 10uF X7R |  | Output and input capacitors on the REF5050 | 1206 | 2 | selected |  | 0003 | REF5050 VIN bypass and REF5050 VOUT load capacitor - one each, with a 100nF from C-DECOUPLE-CARRIER alongside each. *** NEITHER IS ON THE BUFFER'S OUTPUT *** (see figures.yaml cref-out-node); this is the rail that IS the breath scale factor. The VOUT one is not a choice - the part cannot be built without it [SBOS410O 8.4.1 p.26: 'Confirm that a output capacitor (CL) is connected from VOUT to GND. For output stability, verify that the ESR value of CL less than or equal to 1.5 ohm', with Figure 8-6 giving CL = 1uF to 50uF] - and the other is the 8.4.1 supply bypass (1-10uF). 10uF on the buffer output would be 10000x the OPA2197's 1 nF capacitive-load limit. The REF5050 drives only the OPA2197's input bias current (+/-20 pA max at 25C), so its load regulation (20 ppm/mA typ, 30 max, 50 over temperature) contributes ZERO to the breath scale factor. NO SERIES RESISTOR, NO FOOTPRINT FOR ONE: the X7R goes straight from VOUT to AGND_INST. 8.4.1's 'ESR <= 1.5 ohm' is a stability ceiling an X7R meets, 9.4.1.1 p.29 says 'A resistor in series with the output capacitor is optional', and the 1-1.5 ohm TI recommends is 'for better noise performance' only - low ESR gain-peaks the reference's own noise [p.28]. That noise is 4.5 uVrms against a 1.46 mV ADC LSB (325x below), so even a 3x peak leaves it 108x below one LSB [calc], and the load is a constant pA, so there is no transient for peaking to ring on. The TRIM/NR 1uF is DECLINED for the same reason: 8.3.6 p.26 halves the same 4.5 uVrms 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
R-ISO-REF | controller | 37.4R 1% |  | Isolation resistor, reference buffer dual-feedback network (SBOS737C Fig. 56) | 0805 (2.0 x 1.25mm) | 1 | selected |  | 0003 | OPA2197 output to U-BREATH VS (pin 2). One of four parts in TI's dual-feedback reference-buffer network [SBOS737C 8.2.3 p.30, Figure 56 'Precision Reference Buffer']; the other three are R-FB-REF, R-FBX-REF and C-FB-REF. INSTRUMENT-SIDE AND UNRETROFITTABLE. *** TI'S FIGURE TRANSFERS TO OUR 100 nF DESPITE ITS 10uF BECAUSE R_ISO IS SET BY Zo, NOT BY C_L *** - the attenuation R_ISO/(Zo+R_ISO) and the pole-zero ratio both depend only on R_ISO/Zo, and C_L moves both corners together and cancels. 37.4R is Zo/10 against the specified 375 ohm (see U-OPA-PITCH). Simulated margin: figures.yaml riso-ref-phase-margin (sim/, against TI's macromodel, which also reproduces Figure 56's published 89 degrees). *** DC ERROR ACROSS THIS RESISTOR IS EXACTLY ZERO BY TOPOLOGY *** - C-FB-REF blocks at DC so no current flows in R-FBX-REF, input current is pA so none flows in R-FB-REF, and the amplifier therefore forces V(VS) = 5.000 V. Its value and tolerance stop mattering; the 1% is bought for stock reasons. Power is (10mA)^2 x 37.4 = 3.74 mW in an 0805. DO NOT PUT R_ISO INSIDE THE LOOP: it buys nothing at ANY value - 1.5 degrees at 10R and 1.5 degrees at 37.4R, the same as fitting nothing. See figures.yaml riso-ref-topology
R-FB-REF | controller | 10k 1% |  | DC feedback resistor, reference buffer - taken at the sensor's VS pin | 0805 (2.0 x 1.25mm) | 1 | selected |  | 0003 | Part of the reference buffer's dual-feedback network - see R-ISO-REF and figures.yaml riso-ref-topology. INSTRUMENT-SIDE AND UNRETROFITTABLE: the carrier board is inside the sealed body and this network cannot be added later | 10k is this board's value, not TI's scaled (Figure 56's are in figures.yaml riso-ref-topology). (1) The guaranteed-over-temperature I_B of 5 nA through 10k is 50 uV = 0.034 LSB on a rail that IS the ratiometric scale factor. (2) R_F x C_F sets the HANDOVER frequency above which the loop closes on the amplifier's own output instead of on VS; the sensor draws 10 mA, so above the handover any load-current change appears at VS across R-ISO-REF. 10k x 1nF puts it at 15.9 kHz, well above the 500 Hz channel, and |Z_out| at VS is then 1.20 ohm at 500 Hz (sim/ zout-as-netlisted)
R-FBX-REF | controller | 100R 1% |  | AC feedback resistor, reference buffer - taken at the OPA2197 output pin | 0805 (2.0 x 1.25mm) | 1 | selected |  | 0003 | Part of the reference buffer's dual-feedback network - see R-ISO-REF and figures.yaml riso-ref-topology. INSTRUMENT-SIDE AND UNRETROFITTABLE: the carrier board is inside the sealed body and this network cannot be added later | 1% of R-FB-REF, so that above the handover the loop closes on the amplifier output with only 1% of VS leaking in. R_Fx x C_F is 100 ns here against the 3.74 us TI's own rule (R_Fx C_F = R_ISO C_L) would give, and the simulation says it costs nothing - the binding condition is |R_Fx + 1/(2.pi.f C_F)| much less than R_F AT CROSSOVER (riso-ref-phase-margin): at 1.25 MHz |100 - j127| = 162 ohm against 10k, a 62x margin
C-FB-REF | controller | 1nF C0G |  | AC feedback capacitor, reference buffer | 0805 (2.0 x 1.25mm) | 1 | selected |  | 0003 | Part of the reference buffer's dual-feedback network - see R-ISO-REF and figures.yaml riso-ref-topology. INSTRUMENT-SIDE AND UNRETROFITTABLE: the carrier board is inside the sealed body and this network cannot be added later | C0G, because this capacitor sets the handover frequency and an X7R's DC-bias and temperature derating would move it. 1nF at R-FB-REF's 10k gives a 15.9 kHz handover. IT IS ALSO WHY THE DC ERROR IS ZERO: blocking at DC is what leaves R-FB-REF as the only feedback path, so the amplifier servos the SENSOR pin rather than its own output. NOTE FOR THE SPICE DECK: this network leaves the summing node with no DC path except through R-FB-REF, so a simulator needs a leak resistor there for convergence and a real board does not - the amplifier's input leakage provides it
R-REF-IN | controller | 330R 1% |  | Series resistor ahead of the REF5050 input, into the zener clamp | 0805 (2.0 x 1.25mm) | 1 | selected |  | 0003 | +12V to REF_VIN. THE RAIL'S TVS DOES NOT PROTECT THE REFERENCE: D-TVS-PWR clamps at up to 24.4 V [ds LITTELFUSE-SMAJ-SERIES-SMAJ15A.pdf p.2] and the REF5050's VIN abs max is 18 V [ds REF5050.pdf p.5]. This resistor limits the zener's current to (24.4 - 15.75)/330 = 26 mA [calc]. DC drop at the reference's 1.2 mA max [ds REF5050.pdf p.8] is 0.40 V, leaving >= 11.6 V against 5.2 V needed [ds p.7]. The REF5050's VIN capacitors sit on REF_VIN, after this resistor, so R and C filter ahead of the clamp. Same part as R-LED-SER (UNI-ROYAL 0805W8F3300T5E).
D-REF-CLAMP | controller | 15V zener | onsemi | 15 V zener clamp on the REF5050 input (MMSZ5245BT1G) | SOD-123 | 1 | selected |  | 0003 | Cathode to REF_VIN, anode to AGND_INST. Vz 14.25-15.75 V at 8.5 mA, Zzt 16 ohm max [ds ONSEMI-MMSZ5221BT1-SERIES-MMSZ5245BT1G.pdf p.3]: at 26 mA it holds <= 16.1 V, under the REF5050's 18 V [calc]. Leakage is specified only at 11 V (0.1 uA); 1 uA through R-REF-IN would be 0.33 mV, so it cannot move the reference [calc].
C-AA-ADC | controller | 47nF C0G/NP0 |  | Anti-alias cap at the MCP3202 input pin | 0805 (2.0 x 1.25mm) | 1 | candidate |  | 0003 | 564Hz with the divider's 6k Thevenin (10k||15k) - matches the 500Hz channel everywhere else. WAS 220nF, which is 121Hz and smears the breath band; the '~600Hz, 58dB at 496kHz' note was wrong twice over - wrong corner, and the R-78E5.0 switches at 330kHz not 496kHz. 55dB at 330kHz. C0G not X7R in a DC-accurate path
C-ADC-BULK | controller | 10uF X7R |  | Bulk at MCP3202 VDD/VREF | 1206 | 1 | selected |  | 0003 | FITTED, beside C-DEC-ADC at U-ADC pin 8 (VDD, which IS the reference: the MCP3202 has no VREF pin), returned to AGND_INST. The reservoir each conversion draws from, taking the ribbon's inductance out of that current's path. IT DOES NOT FILTER LED PWM: against the ribbon conductor and the LDO it corners in the hundreds of kHz (breath-adc.md). Whether PWM ripple on the reference reaches the breath reading is E9's scope test, specified on breath-adc.md. Samsung CL31B106KBHNNNE (LCSC C89632), 10 uF X7R 50 V, the same part as C-REF-OUT
R-ADCDIV-L | controller | 15k 1% metal film |  | Lower leg of the 0.6x divider from the breath buffer to the ADC | 0805 (2.0 x 1.25mm) | 1 | candidate |  | 0003 | LOWER LEG, to the instrument analog star. 15k against the 10k upper leg is the 0.6x that lands sensor-full-scale inside a 3V3 ADC's range. The RATIO is what matters, so buy both legs from one reel
R-ADCDIV-U | controller | 10k 1% metal film |  | Upper leg of the 0.6x divider from the breath buffer to the ADC | 0805 (2.0 x 1.25mm) | 1 | candidate |  | 0003 | UPPER LEG, AND >=10k IS THE SPEC, NOT THE VALUE: below that, 5V-before-3V3 sequencing pushes about 2.5 mA into the ADC's ESD clamp on every power-up. It also has to leave C-AA-ADC time to settle, which is what stops the leg going higher still. Divide AFTER the buffer, never before
U-ADC | controller | MCP3202-CI/SN | Microchip | 12-bit 2-ch SAR ADC SPI | SOIC-8 (1.27mm pitch) | 1 | candidate |  | 0003 | SOIC-8. VDD-referenced so no separate ref chip. 50ksps at 3V3 vs 4-8kHz needed. One spare channel | 2026-09-21, from Microchip DS21034F now at datasheets/analog/MCP3202-CI-SN.pdf: fCLK max is 1.8MHz at VDD=5V and 0.9MHz at VDD=2.7V, WITH NO 3.3V ROW. The 0.9MHz the design uses is therefore the GUARANTEED 2.7V MAXIMUM, not an interpolation - two documents called it an interpolation and it is strictly conservative at 3.3V, with ~25% of unclaimed headroom (straight-line to 3.3V gives ~1.14MHz). Both rows are characterised, not 100% tested. ALSO A MINIMUM NOBODY HAD: the sample cap holds charge for at least 1.2ms at 85C, so effective fCLK >= ~10kHz - which forecloses 'slow the ADC down' as a way to buy loop time. Sample cap 20pF with 1k switch resistance; tSAMPLE is 1.5 clock cycles and source impedance adds directly to it, so the buffer ahead of it is load-bearing
U-LVLSHIFT | controller | 74AHCT125 | multiple | Quad buffer as LED data level shifter | SOIC-14 (1.27mm pitch) | 1 | candidate |  | 0014 | SOIC-14. 5V rail TTL thresholds so 3.3V reads high. ONE GATE USED, THREE SPARE: the LED row has one data line (ADR 0028); tie every spare input. LED 1's DIN2 is grounded, not driven. THRESHOLD: the WS2815B-V1 wants V_IH 2.7V min and V_IL 1.5V max at VDD 12V, and takes -0.3 to 5.7V on a logic input [ds datasheets/led/WS2815B-V1.pdf pp.2-3]; this part's output at 5V clears the first and stays under the last (led-strip-drive.md section 4)
C-DECOUPLE-CARRIER | controller | 100nF X7R |  | HF decoupling at every carrier IC - ADC, reference, buffer, level shifter, sensor | 0805 (2.0 x 1.25mm) | 8 | candidate |  | 0013 | One per supply pin: MCP3202, REF5050 IN AND OUT, OPA2197 +12V, 74AHCT125, MPXV4006DP, and both R-78E5 inputs. ADR 0001 fixed only the shift registers (C-DECOUPLE-165) and stopped there | 2026-09-21: QTY 7 -> 8. The old enumeration gave the REF5050 one 100nF while carrier.md drew one at its OUTPUT and the prose claimed one at the sensor's VS pin - the same part spent twice across three files, and none drawn at VS at all. SBOS410O section 9.4.1.1 pp.29-30 wants both: a VIN bypass AND 'a high-frequency, 1uF capacitor in parallel between the output and ground'. Settled allocation is REF5050 VIN, REF5050 VOUT, and U-BREATH VS (pin 2) - and the VS one is the 100 nF the reference buffer's compensation is designed against. See figures.yaml cref-out-node
R-LED-SER | controller | 330R 1% |  | Series resistor on the LED row's data line at the driver | 0805 (2.0 x 1.25mm) | 1 | selected |  | 0016 | Damps the fastest edge in the instrument at its source and protects the 74AHCT125 output. ONE: the row has one data line, and it feeds LED 1's DIN1 and LED 2's DIN2 (ADR 0028). LED 1's DIN2 is grounded, so it needs no gate and no resistor
R-LED-PD | controller | 10k 1% |  | Pull-down on the LED data line at the MCU pin | 0805 (2.0 x 1.25mm) | 1 | selected |  | 0016 | IO1 is high-impedance through the bootloader window, and a floating data line into addressable LEDs is the classic source of intermittent LED behaviour. FITTED: the ESP32-S3 datasheet gives GPIO1 no weak pull at or after reset (p.16), so the line floats in the boot window on every board. 10k holds the AHCT input at 10mV against its 1uA leakage (V_IL 0.8V) - led-strip-drive.md. One part, one data line (ADR 0028)
D-LED | controller | WS2815B-V1, 12V addressable RGB LED, 5050 PLCC6, with a backup data input | Worldsemi | The instrument's lights: one row down the main board's top-face centreline, lighting both acrylic sides through the cavity | 5050 PLCC6, 5.4 x 5.0 x 1.65mm (woody:LED_WS2815B-V1_PLCC6_5.4x5.0mm_P1.6mm) | 13 | selected | LCSC | 0028 | COUNT: config/body.yaml lighting.led_count; pitch and positions from the body CAD (pcb-geometry.echo 'led'). ONE DATA LINE, BACKUP CHAINED: DIN1 from the LED before's DO, DIN2 from the LED before's DIN1, LED 1's DIN2 to GND - the WS2815 recommended circuit [ds datasheets/led/WS2815.pdf p.4]; the B-V1 sheet draws none. PIN 1 IS NC and the body's chamfer marks PIN 4 (DIN1), not pin 1 [ds datasheets/led/WS2815B-V1.pdf p.2]: check the assembler's rotation against the footprint. 12V on VDD, 9.5-13.5V absolute [ds p.2]. MSL 5a: baked before reflow [ds p.6]; no repair after reflow in a glued body. JLC EXTENDED part, LCSC C5446699. Current: tracked figure led-row-current
C-LED | controller | 100nF X7R 50V | YAGEO | Bypass at each D-LED, VDD (pin 2) to GND (pin 5) | 0805 (2.0 x 1.25mm) | 13 | selected | LCSC | 0028 | ONE PER D-LED, at its VDD pin. The vendor's 100 nF bypass [ds datasheets/led/WS2815.pdf p.4, 'C1 is bypass filter capacitor']. The same part as C-DECOUPLE-CARRIER, 50V on the 12V row
HDR-SERVICE | controller | 1x5 2.54mm pin header |  | Service header: the real-time board's U0TXD, U0RXD, GND, EN and IO0 | THROUGH-HOLE | 1 | candidate |  | 0018 | FIVE PINS (ADR 0018): 1 TXD (IO43, out), 2 RXD (IO44, in), 3 GND, 4 EN, 5 IO0 - the ground between the UART pair and the control pair. EN and IO0 reach it on two conductors of CBL-MCU-RIBBON, soldered on the Matrix to its Key1 (RESET/EN) and Key2 (BOOT/IO0) terminals. NOTHING IN SERIES: the Matrix pulls both up with 10k to its 3V3 (R8, R10) and its buttons pull them to GND [datasheets/mechanical/WAVESHARE-ESP32-S3-MATRIX-SCHEMATIC.pdf]. DRIVE THEM TO GROUND ONLY - a button, a jumper, or an adapter's open-collector reset circuit; never drive them high, least of all from a 5V adapter. Recovery order: USB-Serial-JTAG through the tail USB-C first, a reflash over the same port second, this header third - and with EN and IO0 here, download mode can be forced in place (firmware/README.md)
U-MCU-RT | controller | ESP32-S3-Matrix | Waveshare | Real-time MCU: ESP32-S3 + onboard QMI8658C 6-axis IMU | dev board, on the lid; CBL-MCU-RIBBON soldered to its pad rows | 1 | selected |  | 0007 | Mounted low for acceleration sensitivity. 17 GPIO on its two pad rows (1-7, 33-40, 43, 44) and 12 used; CBL-MCU-RIBBON takes them to J-MCU. Native USB - verified, not a UART bridge - so USB MIDI works. 4MB flash, 2MB QUAD PSRAM, both on-package: the vendor schematic marks U66 = ESP32-S3FH4R2 [datasheets/mechanical/WAVESHARE-ESP32-S3-MATRIX-SCHEMATIC.pdf; F=in-package flash, H4=4MB, R2=2MB quad PSRAM from Espressif's ordering code, from memory], so GPIO33-37 are free - octal PSRAM would have taken them. The 8x8 matrix is the instrument's only display, under a window in the top face (ADR 0015) - measure idle draw at E1 to size the shared lighting budget
MECH-COAT | controller | Acrylic conformal coating |  | Conformal coating for the in-body boards | aerosol or brush | 1 | open |  | 0009 | Breathed into for hours behind 18 unsealed switch cutouts, interior 10-20K above ambient. MASK BOTH SENSOR PORTS FIRST - a sealed reference chamber gains ~5.2kPa when warm and the output clips at zero, looking like a dead sensor (ADR 0003). THE SENSOR IS SOLDERED TO THE BOARD AND COATED WITH IT: a sensor swap breaks the coating at its eight joints - re-mask both ports before touching it up
PCB-CARRIER | controller | 4-layer PCB - the main board: thumb switches, both thumb registers and the carrier circuits |  | Thumb switches and their registers, breath sensor, reference, ADC, umbilical, SPI egress, LED drive and the LED row, the regulator, service header | long and narrow, sized in mechanical/drc.echo (main board), 1.6mm (config/body.yaml switch.pcb_t) | 1 | open |  | 0017 | ONE board at the thumb level, mouth cap to the end of the right hand (ADR 0017). A TONGUE runs on from its tail end to the etherCON's adapter and carries J-UMB, soldered into both (ADR 0021). The thumb switches solder into it; the key boards connect to it by 12-conductor IDC ribbons (CBL-CHAIN), a through-hole right-angle J-CHAIN header for each in its far band beside the LED row. Parts face up - mechanical/drc.echo gives the room under the key boards and elsewhere. A clearance hole for each U-bolt leg, no edge notches, and a plated PWR_GND hole at each mount, every one on the cassette's bottom plate: the stud, the spacer, the board, then a column's standoff or an end mount's nut (ADR 0022, ADR 0025). Its underside faces the grounded bottom plate over its whole length, so an underside part needs a window cut in the plate (hardware/boards/main-board/README.md). 1.6mm, as the key boards, its top pressed against the thumb switches' housing bottom (ADR 0020 Amendment 6). Long: check the board house's panel and price before M4. FOUR LAYERS, signal / ground / power / signal (ADR 0017 amendment 2026-09-29): layer 2 the PWR_GND plane with the analog island, power-entry-instrument.md section 2. WHITE SOLDER MASK, both faces (owner, ADR 0028): the top face is the LED row's first reflector. ASSEMBLY: JLCPCB assembles the parts whose sheet field Assembly is machine (the SMT passives, ICs and the LED row). HAND-SOLDERED, Assembly=hand on the sheets: the thumb switches (SW1-n), the throu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
J-MCU | controller | 2x12 1.27mm shrouded box header, right-angle, keyed |  | The Matrix's connector on the main board: CBL-MCU-RIBBON plugs in here and unplugs when the lid comes off | envelope: config/body.yaml boards.mcu_conn_* | 1 | open |  | 0018 | WHERE: the main board's tail end beside the regulator block, side entry, the ribbon arriving level from the mouth side; the LED strip stops short of it (mechanical/DESIGN.md). PINOUT (ADR 0018), ribbon conductor n = pin n [IDC numbering, from memory - confirm on the socket's drawing]: 1 5V, 2 GND, 3 5V, 4 IO1, 5 IO2 (spare), 6 IO7, 7 IO3 (spare), 8 IO38, 9 GND, 10 IO35, 11 GND, 12 IO36, 13 3V3, 14 IO34, 15 GND, 16 IO39, 17 5V, 18 IO37, 19 IO33, 20 IO40, 21 IO44 (RX), 22 IO43 (TX), 23 IO0, 24 EN. hardware/carrier/netlist.yaml is authoritative. Every fast line - IO35 SCLK, IO36 MOSI, IO34 CS_MOD, IO38 chain SCK, IO7 SH/LD - has a ground, a supply or a static line on both sides; pin 9 is the ground between SCLK (IO35) and the chain clock (IO38). EN is on the edge with only IO0 beside it: the Matrix has no capacitor on EN (R8 10k to 3V3 and Key1 to GND, nothing else - datasheets/mechanical/WAVESHARE-ESP32-S3-MATRIX-SCHEMATIC.pdf). IO2 and IO3 are spare and reach no other part on the main board; bring them to two test pads beside J-MCU. KEYED AND SHROUDED: a reversed plug puts 5V on a GPIO. RATING: the 5V and GND contacts carry the whole Matrix draw, and fed from the 5V pad nothing on the Matrix limits it (its USB diode is bypassed - matrix-led-current, power_path), so rate them against U-BUCK's 1A (R-78E5.0-1.0), not against matrix-led-current: three 5V contacts at ~0.33A and four GND at ~0.25A each [calc, equal sharing], against ~1A per 1.27mm contact [from memory]. PART NUMBE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
CBL-MCU-RIBBON | controller | 24-way flat ribbon, 0.635mm pitch, with a 2x12 1.27mm IDC socket at one end |  | The Matrix's wiring: soldered to its two pad rows, two test pads and its two button pads on the lid, plugged into J-MCU on the main board | cable assembly, hand-built | 1 | open |  | 0018 | CONDUCTORS: 24, conductor n = J-MCU pin n (J-MCU row; hardware/carrier/netlist.yaml is authoritative). AT THE MATRIX END [datasheets/mechanical/WAVESHARE-ESP32-S3-MATRIX-SCHEMATIC.pdf; pad rows per WAVESHARE-ESP32-S3-MATRIX-pinout.png]: the 12 used GPIO and the spare IO2 and IO3 to their pads; 3V3 (13) to the 3V3 pad; 5V x3 - conductors 1 and 3 both on the 5V pad, 17 on TP2 (net VCC_5V); GND x4 - conductor 2 on the GND pad, 9, 11 and 15 on TP3 (net GND). IF TP3 WILL NOT TAKE THREE JOINTS, twist 9, 11 and 15 together and tin them as one joint - each is still its own path to J-MCU. EN (24) to Key1 and IO0 (23) to Key2, each on the terminal that goes to its 10k pull-up (R8 for RESET/EN, R10 for IO0), NOT the one on GND: with a meter, the right terminal reads ~10k to the 3V3 pad and the wrong one 0 ohm to the GND pad. Nothing in series on either: R8/R10 hold them up, the buttons still work, and whatever drives them from HDR-SERVICE pulls to ground only. CURRENT: at U-BUCK's 1A (R-78E5.0-1.0) the three 5V conductors carry ~0.33A each and the four GND ~0.25A [calc, equal sharing]; a 0.635mm conductor carries that without heating to speak of [from memory]. RESISTANCE IS WHAT THE FOUR GROUNDS ARE FOR: ~34mohm per 100mm [from memory, ~30AWG], four in parallel ~8.5mohm - ~1 LSB full scale on the breath ADC per 100mA and ~10 at 1A, against ~42 on one ground [calc, carrier.md]. The Matrix's 3V3 is the ADC's reference (carrier/breath-adc) and is regulated against the Matrix's ground, so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
NT-DIG | controller | Net tie, 2 pads, copper only |  | DIG_GND (J-UMB pin 8) to the main board's ground, at the pin | net tie footprint (no part) | 1 | decided |  | 0018 | COPPER, NOT A PART: nothing is bought or placed. The layout puts it at J-UMB pin 8 - the short, wide connection ADR 0018 asks for - and the net tie lets KiCad's DRC allow that join there and nowhere else. Assembly: none
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

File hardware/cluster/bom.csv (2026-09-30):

ref | category | part | manufacturer | description | package | qty | status | source | adr | notes
SW1-n | controller | KS-33 Red (linear) | Gateron | Low-profile mechanical switch MX stem | switch, plate mount | 21 | purchased | Amazon | 0002 | Binary. Plate cutout must be measured. Soldered. Thumb keys may want a lighter spring - decide at M1. 12.2mm tall, 1.70mm pretravel, 3.00mm total travel, 3-pin. Datasheet and STEP model published by Gateron - use them, do not caliper the housing. 19 keys + 2 spares (octave up/down) - the spares have no cutouts (ADR 0010), so fitting one means recutting the bottom plate and oak bottom. ORDER KS-33H10B050NN-Y24, the code the banked drawing is for (datasheets/mechanical/GATERON-KS-33-VENDOR-SPEC-DRAWING.pdf) and the MPN on hardware/cluster/key-switch-network/key-switch-network.kicad_sch. The -Y24 suffix is the BLACK-BOTTOM-HOUSING variant, not a year: -Y31 is the white-bottom one, and its spec gives a longer total travel (datasheets/mechanical/GATERON-KS-33-SPEC-WHITE-HOUSING-KS-33H10B050NN-Y31.pdf), so a -Y31 order breaks the flush rule, which the body derives from switch.total_travel. The switches in hand came from Amazon and their code is unknown: read it off the packaging before trusting them to the flush rule
PLATE-TOP | mechanical | 1.20mm aluminium |  | Aluminium key plate laser or waterjet cut | n/a | 1 | selected |  | 0009 | *** PLATE THICKNESS IS 1.20 +/-0.05 mm, OFF THE VENDOR DRAWING *** (datasheets/mechanical/GATERON-KS-33-VENDOR-SPEC-DRAWING.pdf, the linear Red KS-33H10B050NN-Y24: sheet 6's elevation dimensions the plate slot, sheet 3 section 8 shows the same 1.20 against a hatched plate section). BOTH OF THE OBVIOUS ALTERNATIVES ARE OUTSIDE THAT WINDOW: MX-standard 1.5mm is 0.25mm over the upper limit, 2mm is 0.75mm over and defeats the retention clips entirely, and the third-party reference build's 1.10mm is 0.05mm under the lower limit - do not 'correct' this to an MX number. CUTOUT 14.00 +0.05/-0.02 x 14.00 +0.05/-0.02, not a bare 14.0 square. Also off this drawing: operating force 50 +/-15 gf, pre travel 1.7 +/-0.4, total travel 3.0 +/-0.2, and the contact bounce that is the tracked figure ks33-contact-bounce (cited, not restated). VENDOR CONTRADICTION - USE 60 M: sheet 6 states operation life 60,000,000 cycles min while sheet 3 sections 6.1/6.2 state 80,000,000. *** STRUCTURAL CONSEQUENCE, NOT DECIDED HERE: *** at 1.20mm the plate is thinner than either stiffening plan assumed, so ADR 0009's lamination-or-backer question is a REQUIREMENT rather than an option. THE CASSETTE'S TOP (ADR 0025): a clearance hole at each of the eight columns (hardware.col_plate_hole), where a MECH-COL-SCREW comes down into its standoff. GROUNDED THROUGH THE COLUMNS to the main board's plated PWR_GND mounts (ADR 0025; ADR 0020 Amendment 7): each screw's head bears on the plate's top face, so ORDER IT UN-ANO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
PCB-CLUSTER | controller | 2-layer PCB - key board |  | Per key cluster: switches, one register (U-KEYS), its decoupling, and the per-key network | 1.6mm (config/body.yaml boards.key_board_t) - outline mechanical/export/key-board-*.dxf | 2 | open |  | 0017 | Two - left hand (5) and right hand (6). The thumb clusters are on the main board (PCB-CARRIER, ADR 0017). The switches need a rigid PCB regardless (ADR 0002), so putting the register on it is nearly free: every switch-to-chip connection is a TRACE, and each key board connects to the main board by one 12-conductor IDC ribbon (CBL-CHAIN) into a through-hole right-angle J-CHAIN on its underside (ADR 0017)

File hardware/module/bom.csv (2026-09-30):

ref | category | part | manufacturer | description | package | qty | status | source | adr | notes
R-OUT-PROT | module | 1k 1%, >=500mW |  | Series protection on each CV output | 1206 (3.2 x 1.6mm) | 6 | candidate |  | 0006 | *** SPECIFY 0.66-1W IN 1206 (ERJ-P08 class, confirmed to exist). THE POWER RATING IS NOT OPTIONAL AND THIS IS THE ONLY PART IN THE MODULE AT REAL RISK FROM ANY JACK FAULT. *** The worst case is output-to-output patching, not a short: with pitch taking jack-side feedback the loop FIGHTS the other module, giving 322mW against a 220R source at +/-10V (two reviewers found this independently, on 269/312/464mW ladders). A dead short merely rails the op-amp across this resistor, at 142mW. AND THE DERATING IS WHAT RULES OUT 500mW: thick-film at a 50C rack interior leaves a 500mW 1206 delivering 350-420mW, so it is ~1.1x margin, not the 2.6x a nameplate reading suggests. Mutable specifies its output 1k at >=200mW where every other resistor in the same BOM is 100mW, which is the published form of this argument
R-OPAMP-IN | module | 1k 1% |  | Series resistor on each op-amp + input driven by the DAC | 0805 (2.0 x 1.25mm) | 6 | candidate |  | 0006 | SIX: pitch, mod 1-4 and the mod offset buffer. Correct on the mod channels too, because the two-resistor form drives the op-amp's (+) input directly - a true high-Z node where 1k causes no error. The VREFOUT follower's protection is R-VREF-SER, a thin-film part because it is also half of the ratio that sets V_ref. DAC on 5.21V and op-amps on +-12V do not come up together; this bounds clamp current, outside the feedback path so no accuracy cost
D-JACK-CLAMP | module | BAV99 |  | Clamp diodes on the DRIVER side of R-OUT-PROT | SOT-23 | 6 | candidate |  | 0006 | MOVED to the op-amp side of the 1k, which fixes two things at once. (a) BACK-POWERING: clamped at the JACK, a neighbouring module driving 10V through its own 220R output pushes 42mA per jack into our +12V rail when this module is off - 254mA across six jacks, into the rail that also feeds the umbilical. Behind the 1k it is 7.6mA per jack. (b) LEAKAGE: inside the feedback loop the op-amp absorbs it, so the 2.4-cent BAT54S error goes to identically zero for any diode. BAV99 kept anyway - silicon costs nothing and the reasoning no longer depends on it. NOTE: no surveyed design clamps a CV output to the RAILS at all; every clamp in the corpus goes to GND. Erica Synths is the one that puts its clamp on the driver side, which is where this now is. SIX - one per OUTPUT jack including breath, whose schematic omitted it. The two BREATH INPUT clamps are a separate row, D-CLAMP-BREATH, so the module carries eight BAV99 in total
J-CV | module | PJ398SM (Thonkiconn) |  | 3.5mm mono PCB-mount jack | THROUGH-HOLE | 6 | candidate |  | 0006 | De facto eurorack standard. BUSHING IS D6.0mm WITH 4.5mm OF THREAD, so the panel hole is 6mm nominal and 6.2-6.5 in practice, with 5.5mm from the panel face to the body front including the shoulder. Body 9 x 9 x 8.3mm, barrel bore D3.6, 3.5mm of tails behind. Rated DC30V 0.5A, 5000 cycles, PBT / brass-Ni / BeCu-Ag. *** PINOUT, cross-checked two ways (drawing schematic, and a KiCad footprint whose pads are NAMED with offsets matching the drawing's 4.92 / 3.38 / 6.48): PIN 3 = TIP, PIN 2 = TIP-NORMAL SWITCH CONTACT - NORMALLY CLOSED TO PIN 3 AND OPENING WHEN A PLUG IS INSERTED - PIN 1 = SLEEVE. *** All three on one centreline, oval drill 1.6 x 0.6. LEAVE A 3mm HOLE OR A VOID IN THE PCB UNDER THE BARREL (Thonk's own note). THE SWITCH CONTACT IS FREE NORMALLING and nothing in the design uses it yet - worth knowing before the layout rather than after. FILED AT BOARD LEVEL, beside R-OUT-PROT, because three circuits drive these six jacks and panel.md owns only the cutouts: no single circuit page derives the connector

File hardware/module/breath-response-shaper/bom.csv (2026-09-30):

ref | category | part | manufacturer | description | package | qty | status | source | adr | notes
D-RESP | module | 1N4148W, x2 antiparallel | Vishay | Nonlinear element for the response shaper | SOD-123 | 2 | selected |  | 0006 | Breath is unipolar so only one ever conducts in play; the second covers the power-on and fault excursions. Scaling is set at /2 so the knee lands at about a quarter of a hard blow - at /10 it would sit ABOVE the playing range and the control would do nothing until you overblow. *** THE 0.6 V KNEE THIS SHAPER DEPENDS ON IS NOT-IN-DOCUMENT AS A SPEC. *** Neither banked datasheet specifies V_F at 0.6V; it is readable only off Vishay's TYPICAL Fig.1 (~1mA at 25degC), and that curve shifts more than 100mV LEFT at 150degC - on a part whose entire behaviour is where the knee sits. The tightest SPECIFIED bound in the bank is Diotec's V_F < 0.855V at 10mA. *** BUY VISHAY'S 1N4148W-E3-08, *** a true SOD-123 (Document 86356 Rev 1.0: 2.7 x 1.55mm body, R-thJA 440 K/W, P_tot 280mW, V_F <=1V at 10mA, C_D 1.5pF max) - Diotec's same-numbered part is SOD-123F, flat lead, no standoff, and the plain 1N4148 is axial DO-35. LCSC C241939
POT-RESP | module | 50k linear, 9mm vertical, centre detent | Alpha | Breath response: log (CCW) - linear (centre) - exponential (CW) | THROUGH-HOLE 9mm vertical, snap-in (R0904N footprint) | 1 | selected |  | 0006 | ALPHA RV09AF-40-25B-B50K-0C: RV09A = 280 deg like the R0904N on the other two knobs, -40 vertical, 25B = 25mm shaft of the B type, which is 18-TOOTH knurled like the T18 knob (the K type is 40-tooth), B50K linear, 0C = centre click [ds RV09AF-40.pdf p.1 order code, p.3 outline, p.7 B type]. Song Huei lists a centre click in its specification but no order code for it [ds R0904N.pdf p.1], so this is the one Alpha on the panel. Same 5.0mm pin pitch, 10.6mm lug span and 7.0mm offset as the R0904N [RV09AF-40.pdf p.3, R0904N.pdf p.2], so it takes the same footprint. *** THE CENTRE DETENT IS HONESTLY WARRANTED HERE AND NOT ELSEWHERE: *** at centre the wiper sits at exactly 0V by topology - it spans +Vin/2 and -Vin/2 - so the nonlinear branch carries no current and the stage is linear. POT-OFFSET gets no detent: its zero is not at centre. The click costs half the rotational life, 5000 cycles against 10000 [p.1]
R-RESP | module | 3.9k 1% | UNI-ROYAL(Uniroyal Elec) | Sets response curve strength | 0805 (2.0 x 1.25mm) | 1 | selected |  | 0006 | SETS HOW HARD 'FULLY EXPONENTIAL' BENDS: the owner requires at least 1.5x at a hard blow (2026-09-30), and 3.9k is the E24 value that holds it at every simulated corner - shaper-exp-gain, module/breath-response-shaper/sim. Lower bends harder and clips earlier; the next E24 value up, 4.3k, falls under 1.5x at the worst corner. POT-RESP's track tolerance is most of the spread, so a pot measured low at incoming inspection is where to look first if a unit reads short. UNI-ROYAL 0805W8F3901T5E, LCSC C17614
R-RESP-DIV | module | 10k 1% |  | The 2 x 10k divider that makes V_in/2 for the pot's top end | 0805 (2.0 x 1.25mm) | 2 | selected |  | 0006 | TWO, and they must MATCH rather than be accurate: the null at centre detent is exact only while the divider gives exactly half of what the inverting stage gives back. That null is the reason this pot earns a centre detent where POT-OFFSET's does not. 0805W8F1002T5E, LCSC C17414
R-RESP-FB | module | 10k 1% |  | Feedback resistor (drawn R2) of the shaping stage | 0805 (2.0 x 1.25mm) | 1 | selected |  | 0006 | The /2 comes from R-RESP-FB over R-RESP-IN, and the /2 is the whole design: at /10 the diode knee lands above a hard blow and the knob does nothing until you overblow. Do not rescale either without re-checking the knee against the playing range. 0805W8F1002T5E, LCSC C17414
R-RESP-IN | module | 20k 1% |  | Input resistor (drawn R1) of the shaping stage | 0805 (2.0 x 1.25mm) | 1 | selected |  | 0006 | Sets the shaping stage's input current against R-RESP-FB, so the pair is what makes it divide by two. 0805W8F2002T5E, LCSC C4328
U-RESP | module | OPA2197IDR | Texas Instruments | Response shaper: 1/2 shapes at /2 inverting, 1/2 restores x2 inverting | SOIC-8 | 1 | selected |  | 0006 | Response-shaper op-amp. DEVICE FACTS ARE ON U-OPA-PITCH; not repeated here. ITS OWN PACKAGE, BOTH HALVES THE SHAPER'S: A shapes at /2 inverting, B restores x2 inverting so scale and polarity at POT-GAIN are the in-amp's. The six U-OPA-PITCH packages keep their two spare halves (U-REF-BUF B, U-MOD-C B). LCSC C139363
R-RESTORE-IN | module | 10k 1% | UNI-ROYAL | Input resistor of the shaper's restoring half (x2 inverting) | 0805 (2.0 x 1.25mm) | 1 | selected |  | 0006 | V_shaped into U-RESP B's (-) input. With R-RESTORE-FB it undoes the shaping half's -1/2, so at centre detent the stage is exactly unity and the polarity is the in-amp's. 0805W8F1002T5E, LCSC C17414
R-RESTORE-FB | module | 20k 1% | UNI-ROYAL | Feedback resistor of the shaper's restoring half | 0805 (2.0 x 1.25mm) | 1 | selected |  | 0006 | U-RESP B's output to its (-) input: -20k/10k = -2. The stage's output is BREATH_SHAPED, into POT-GAIN. 0805W8F2002T5E, LCSC C4328

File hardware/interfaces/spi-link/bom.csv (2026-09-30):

ref | category | part | manufacturer | description | package | qty | status | source | adr | notes
R-SPI-PULL | module | 10k 1% |  | SPI idle-state pulls at the module: SCLK and MOSI (cable side), SCLK_DAC, DIN and SYNC (DAC side) | 0805 (2.0 x 1.25mm) | 5 | candidate |  | 0004 | FIVE OF THE MODULE'S SIX SPI PULLS - the sixth, CS_MOD's cable-side pull, is its own row, R-CS-PULL-MOD, because it is 100k and not 10k, and it has a partner at the instrument end, R-CS-PULL-INST (spi-link.md, 'CS_MOD's two pulls'). BOTH SIDES of the 74AHCT125. Cable side: SCLK and MOSI to DIG_GND, so the buffer's inputs do not float and crowbar when the instrument is absent. DAC side: SCLK_DAC and DIN down, SYNC up, because with OE disabled the buffer outputs are Hi-Z and it is then the DAC's SCLK/DIN/SYNC that float - the state the cable-side pulls do not reach. Module-alive-instrument-off is the normal state, not a fault; a stray CS edge latches garbage into the pitch DAC. DAC-SIDE SYNC PULLS TO AVDD (the LM317's 5.21V), a pull-up on its consumer's rail: on any other rail a reversed ribbon could reach the DAC's SYNC pin and turn a $0.30 buffer failure into a DAC failure. UNI-ROYAL 0805W8F1002T5E, LCSC C17414
R-CS-PULL-MOD | module | 100k 1% | UNI-ROYAL(Uniroyal Elec) | CS_MOD's cable-side pull-up at the module, to LOGIC_5V | 0805 (2.0 x 1.25mm) | 1 | selected |  | 0004 | THE WEAK HALF OF CS_MOD'S TWO PULLS (the strong half is R-CS-PULL-INST at the instrument). On module-main as R-PULL-CS, from CS_MOD to LOGIC_5V - the rail of the part it holds, U-LVL-MOD. 100k, NOT 10k: with the instrument plugged in and switched off, its 3V3 is dead, and 10k to 5V would push ~430uA through the ESP32's input clamp with the node stuck near 0.7V; 100k against R-CS-PULL-INST's 10k puts ~45uA into the dead rail and the node at ~0.45V, below the buffer's 0.8V V_IL [ds SN74AHCT125.pdf p.3]. With nothing plugged in it holds the buffer input within 0.1V of 5V (1uA max leakage, p.4), so SYNC sits high and the DAC ignores SCLK. A PULL-DOWN HERE IS WRONG: the 74AHCT125 does not invert, so it would hold SYNC low - selected - with the umbilical out. The arithmetic for all four link states is on spi-link.md, not restated here. UNI-ROYAL 0805W8F1003T5E, LCSC C149504
R-CS-PULL-INST | controller | 10k 1% | UNI-ROYAL(Uniroyal Elec) | CS_MOD's pull-up at the instrument end, IO34 to the dev board's 3V3 | 0805 (2.0 x 1.25mm) | 1 | selected |  | 0004 | THE STRONG HALF OF CS_MOD'S TWO PULLS, on the main board (carrier/carrier's sheet) because 3V3 exists only at the instrument: from IO34 to DEV_3V3, beside J-MCU pins 14 and 13, on the MCU side of R-SPI-SER-CS so the source termination is untouched. IT IS WHAT HOLDS CS DESELECTED WHILE THE ESP32 RESETS AND BOOTS: GPIO34 has no pull at reset, input-enabled only [ds ESP32-S3-datasheet-v2.2.pdf p.17], and it is not a strapping pin (GPIO0, 3, 45, 46 [p.26]), so a pull here changes no boot mode. With R-CS-PULL-MOD's 100k to 5V in parallel the idle node is ~3.45V, which the ESP32's pad clamp holds to within ~17uA [calc on spi-link.md]. UNI-ROYAL 0805W8F1002T5E, LCSC C17414
R-SPI-SER | controller | 82R 1% | UNI-ROYAL(Uniroyal Elec) | Series termination on SCLK, MOSI and CS at the driving end | 1206 (3.2 x 1.6mm) | 3 | selected |  | 0004 | THREE, 82R (owner, 2026-09-30: cs-fall-reentry, interfaces/spi-link/sim). *** 2m OF CAT5 IS A 100-OHM TRANSMISSION LINE (20ns round trip against 2-5ns edges), NOT AN RC CORNER *** - do not derive this from a corner frequency. *** U-TVS-SPI SITS ON THE PAD SIDE OF THESE, NOT THE CABLE SIDE: *** at J-UMB its 30 pF sends CS_MOD's returning edge back up through the far end's V_IL. The value is spi-series-r, derived on spi-link.md. FAULT CURRENT into a conductor shorted to ground: 3.3V / (82 + 17) = 33mA at the pad's strongest drive setting, under its 40mA [calc; ds ESP32-S3-datasheet-v2.2.pdf p.65]. 1206, 1/4 W: 33mA through 82R is 90mW, 36% of rating [calc; ds UNIROYAL-THICK-FILM-CHIP-RESISTOR-0805W8F.pdf, 1206 = 1/4 W, 200 V]. UNI-ROYAL 1206W4F820JT5E, LCSC C17980
U-TVS-SPI | controller | SP0504BAHT or equivalent 4-channel 5V array | multiple | ESD protection on the umbilical's SPI lines | SOT-23-5 (0.95mm pitch) | 1 | candidate |  | 0004 | SCLK, MOSI, CS (+ one spare channel) to PWR_GND. ORDER CODE IS SP0504BAHTG AND IT IS SOT-23-5, NOT SOT-23-6 [SP0504BAHT.pdf p.1 ordering table, package outlines pp.6-7]; SP0505BAHTG is the SOT-23-6 part and brings a fifth channel if one is wanted. *** THE PART HAS NO PULSE RATING AT ALL. *** Eight pages carry no I_PP, no 8/20us or 10/1000us waveform, no surge curve and no theta-JA: it is ESD-rated only (IEC 61000-4-2, 20kV contact / 30kV air). What it does specify is a steady-state ceiling - package dissipation 0.225 W [Abs Max p.2, corroborated 'PD@70degC .225W' p.7]. SO A SUSTAINED FAULT IS NOT SURVIVED BY A BIGGER ARRAY; the fix is a series resistor or a resettable element. ALL FOUR CHANNELS SHARE ONE COMMON PIN (pin 2), to PWR_GND. *** ON THE PAD SIDE OF R-SPI-SER *** (IO34, IO35, IO36), close to J-UMB: on the cable side its capacitance reflects CS_MOD's returning edge back through the module's V_IL (cs-fall-reentry, interfaces/spi-link/sim), and there R-SPI-SER now limits what a sustained fault on a conductor pushes into it. U-TVS-CHAIN is a second package because it clamps at the J-CHAIN, elsewhere on the main board. THE ARRAY IS EFFECTIVELY UNI-DIRECTIONAL: the -0.8V negative clamp is a forward diode drop, not an avalanche knee. Fine for 0-3.3V SPI; MUST NOT be reused on a bipolar CV node. 30 pF per channel is high for a modern array; on the pad side it loads the pad, not the line, and interfaces/spi-link/sim carries it. DO NOT RE-PROPOSE onsemi ESD7104: it is a clea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

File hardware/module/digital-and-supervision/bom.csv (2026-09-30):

ref | category | part | manufacturer | description | package | qty | status | source | adr | notes
U-LVL-MOD | module | 74AHCT125 |  | Level shifter, 3V3 SPI up to 5V for the DAC | SOIC-14 (1.27mm pitch) | 1 | candidate |  | 0004 | SAME part as the instrument LED shifter. Covers SCLK MOSI CS with a spare gate, each from U-RX-MOD's second inverter. Runs from the module's own 5V (U-REG-LOGIC, LOGIC_5V); the DAC runs from U-REG-DAC. *** NO INPUT CLAMP TO VCC, *** confirmed three independent ways in SCLS264O: abs-max lists 'Input clamp current, IIK (VI < 0): -20mA',
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

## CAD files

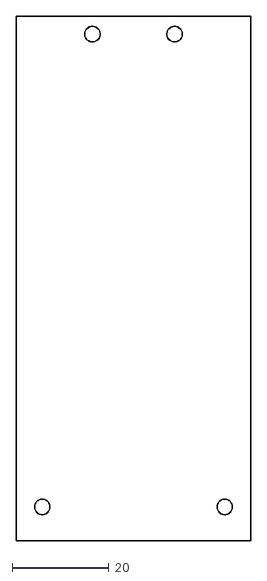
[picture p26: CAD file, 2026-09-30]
mechanical/module/export/main-board.dxf
48.5 x 108.5

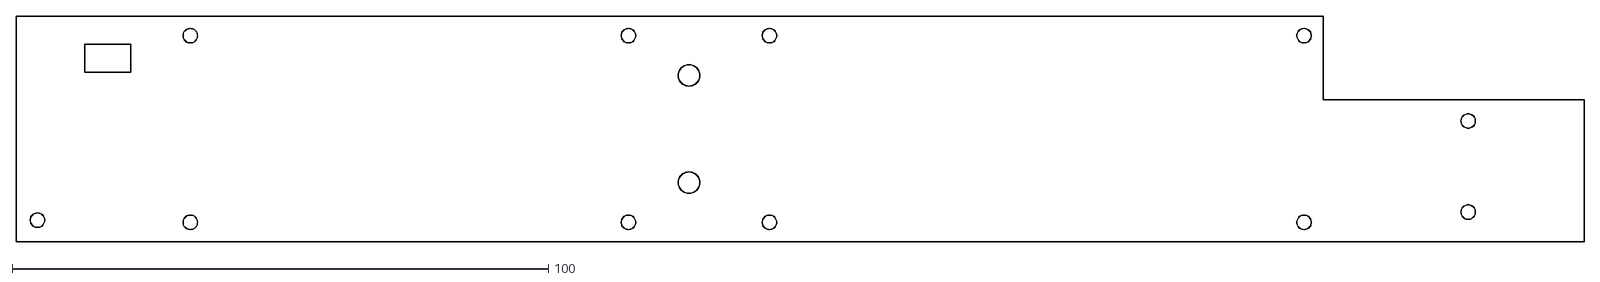
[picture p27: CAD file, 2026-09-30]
mechanical/export/main-board.dxf
292.4 x 42.0

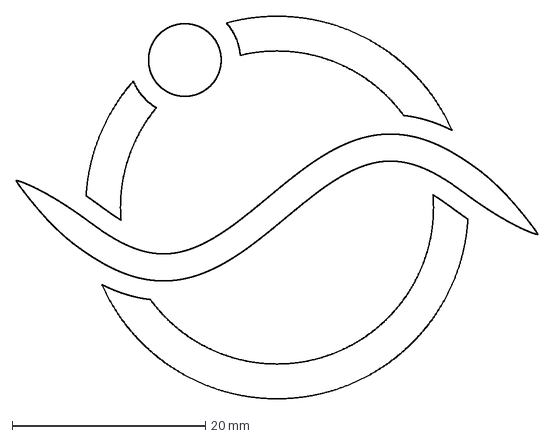
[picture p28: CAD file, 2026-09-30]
branding/export/scs-orbit-wave-mark.dxf
54.0 x 39.6 mm

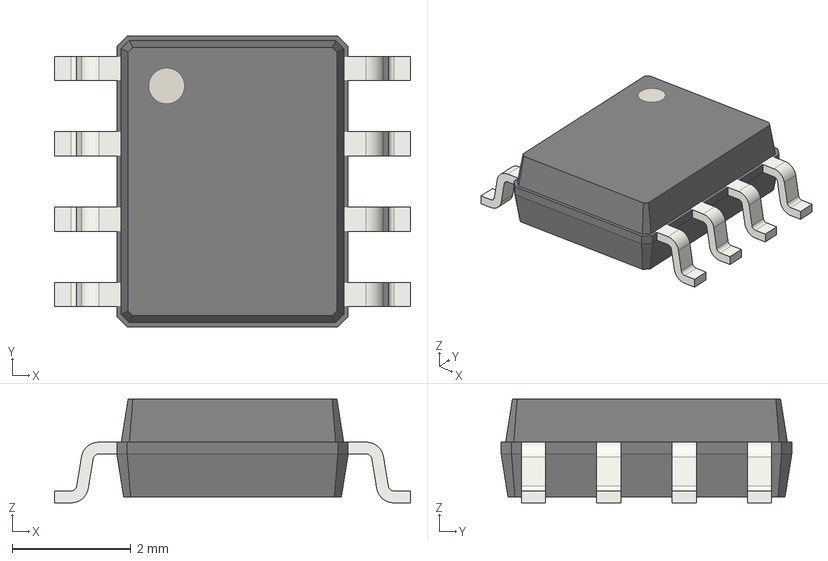
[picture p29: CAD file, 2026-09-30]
datasheets/analog/KICAD-SOIC-8_3.9x4.9mm_P1.27mm-3D.step
6.00 x 4.90 x 1.75 mm

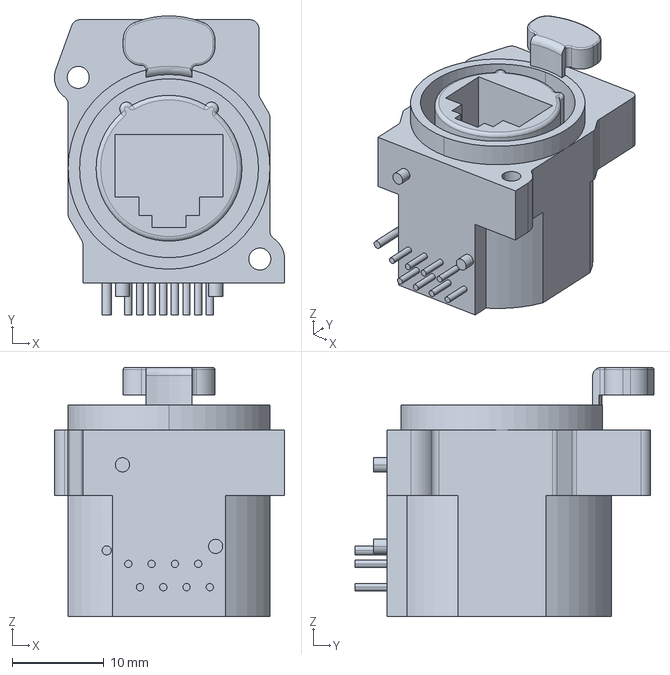
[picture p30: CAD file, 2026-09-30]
datasheets/connectors/NEUTRIK-NE8FAH-C5-3D.stp
25.1 x 32.6 x 27.2 mm

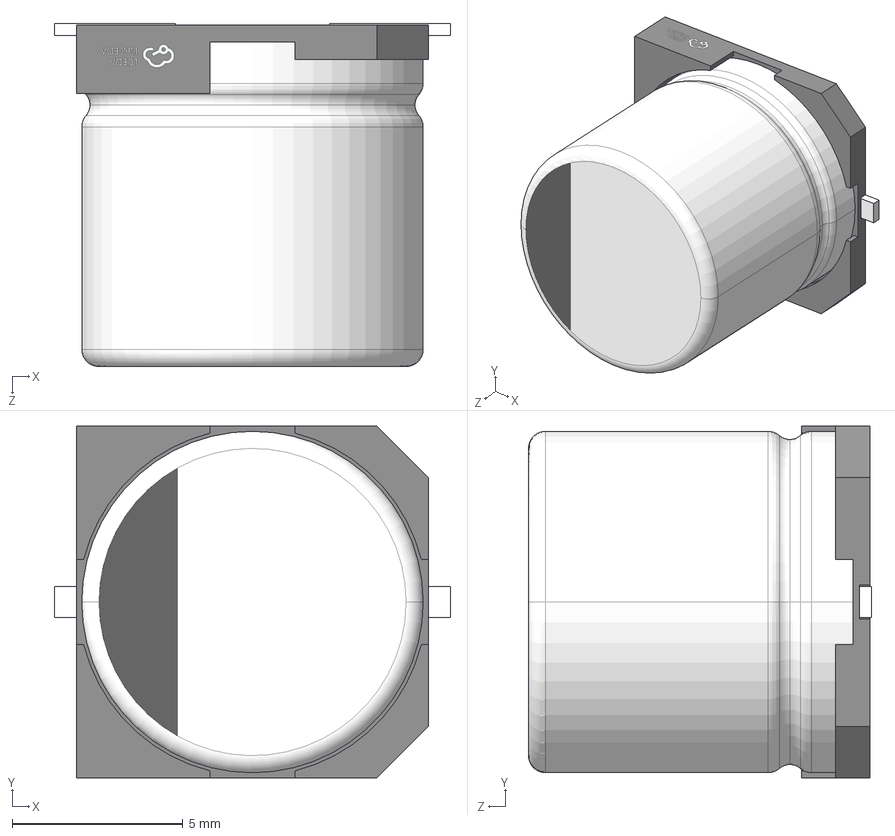
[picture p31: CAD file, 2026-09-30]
datasheets/discrete-and-power/NICHICON-UCW-10x10-3D.step
11.6 x 10.3 x 10.1 mm

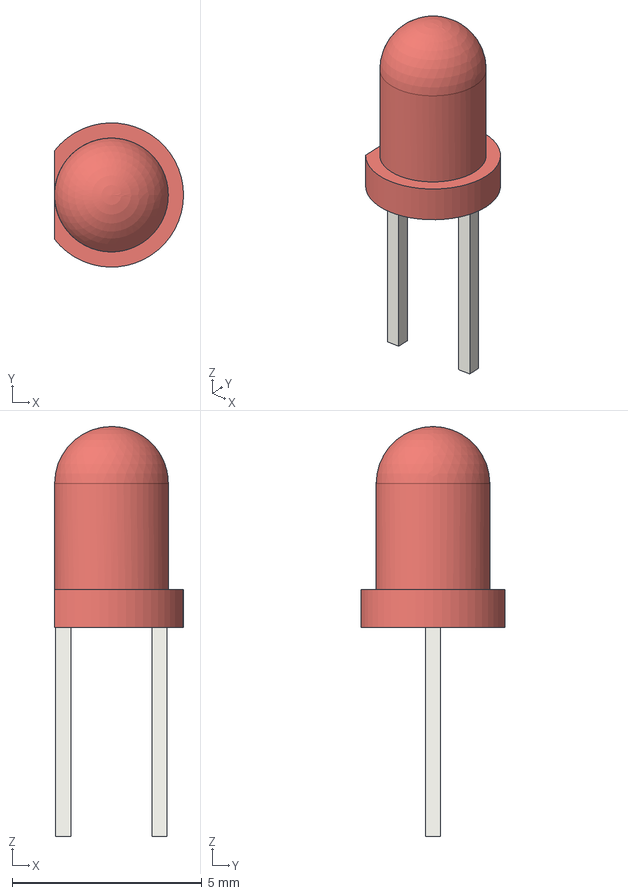
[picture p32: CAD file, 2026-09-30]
datasheets/led/KICAD-LED_D3.0mm-3D.step
3.40 x 3.80 x 10.8 mm

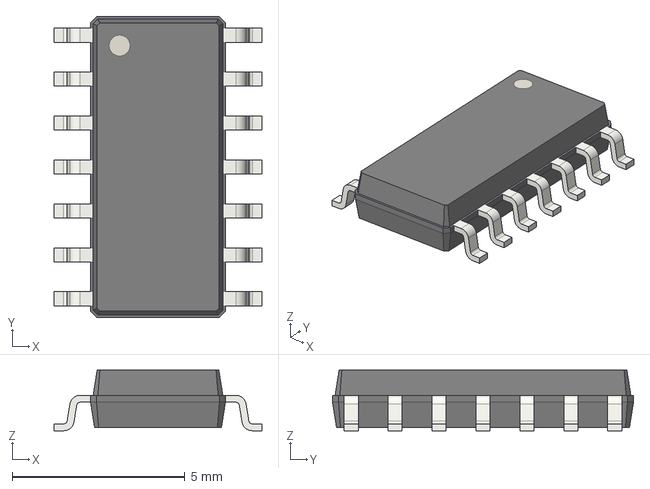
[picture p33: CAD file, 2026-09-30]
datasheets/logic/KICAD-SOIC-14_3.9x8.7mm_P1.27mm-3D.step
6.00 x 8.70 x 1.75 mm

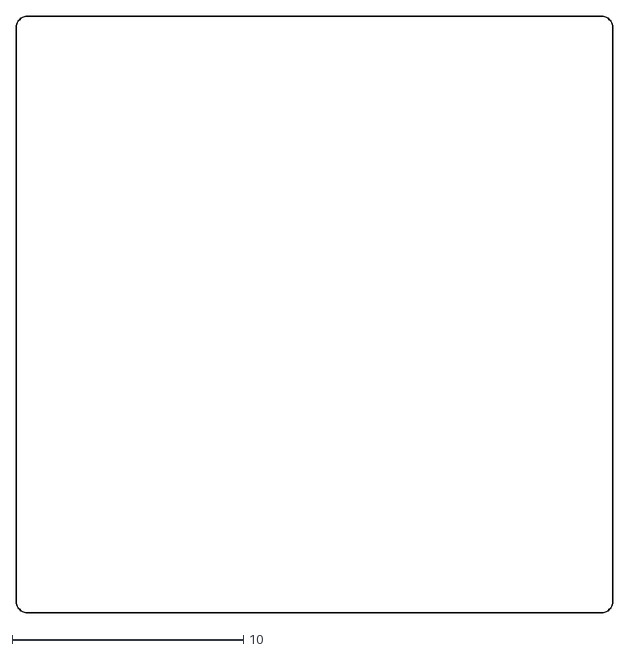
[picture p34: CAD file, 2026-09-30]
mechanical/export/matrix-window.dxf
25.8 x 25.8

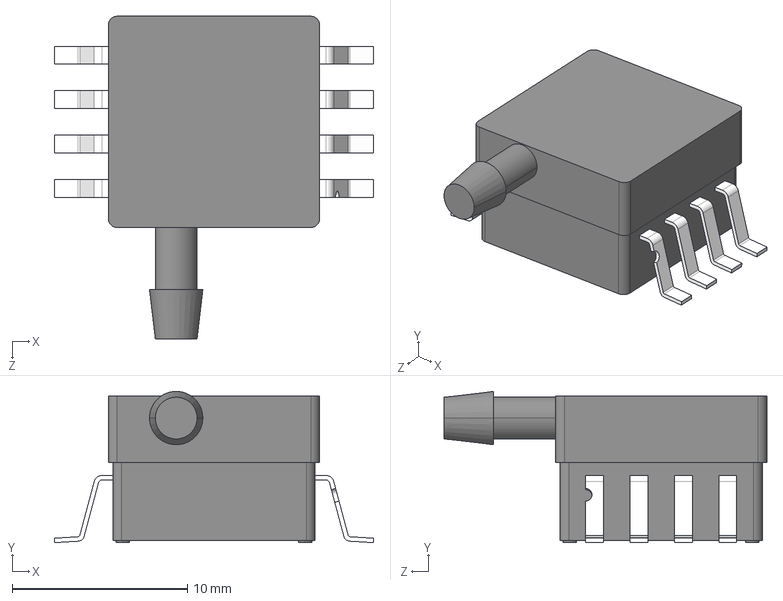
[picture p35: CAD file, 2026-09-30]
datasheets/analog/MPXV-CASE-1351-01-MP3V5050DP-3D.step
18.2 x 8.64 x 18.4 mm

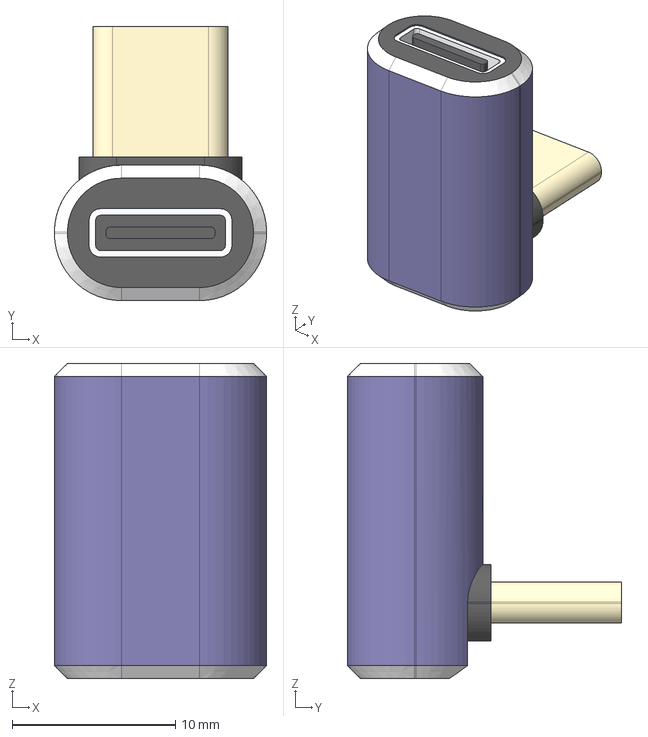
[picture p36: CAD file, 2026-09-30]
datasheets/connectors/GENERIC-USB-C-RIGHT-ANGLE-ADAPTER-3D.step
13.0 x 16.8 x 19.3 mm

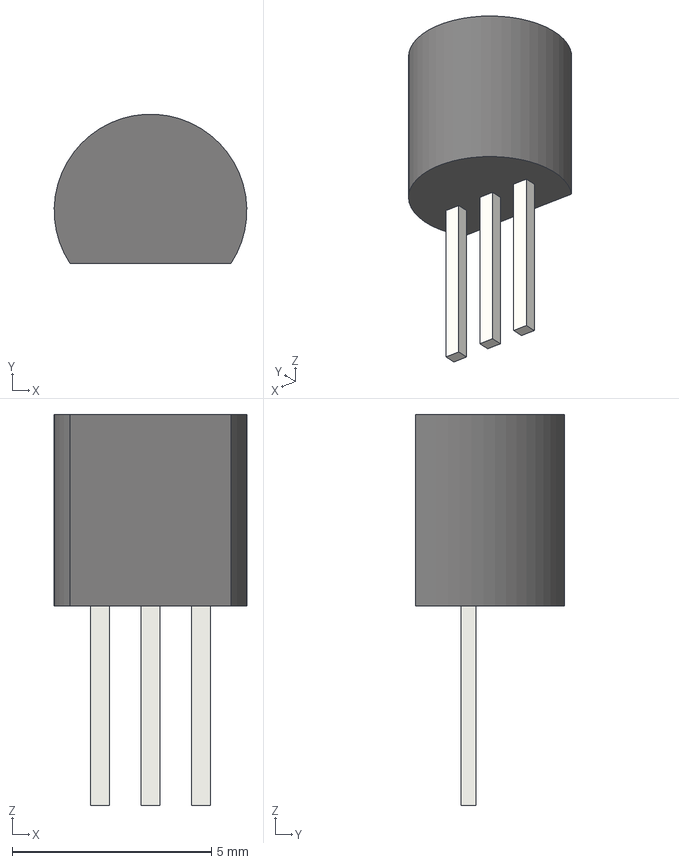
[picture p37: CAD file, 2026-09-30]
datasheets/discrete-and-power/KICAD-TO-92_Inline-3D.step
4.83 x 3.74 x 9.80 mm

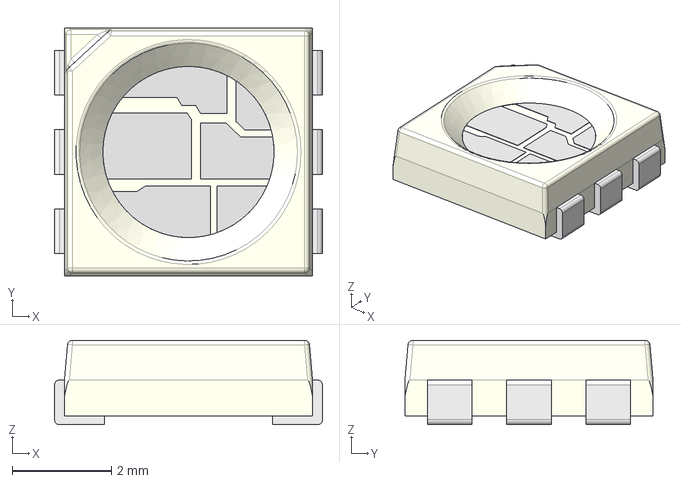
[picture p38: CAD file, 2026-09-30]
datasheets/led/WS2815B-5050-3D.step
5.40 x 5.00 x 1.70 mm

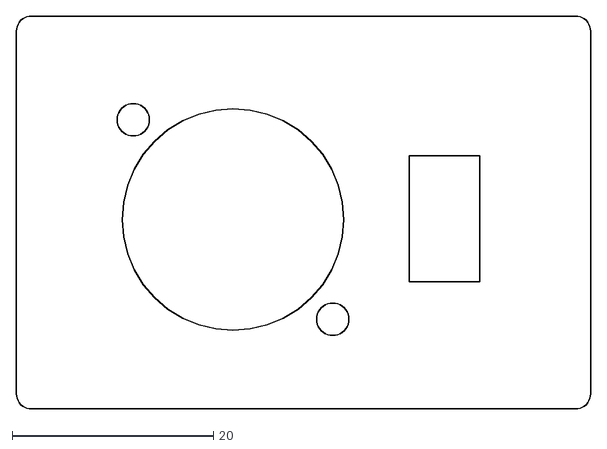
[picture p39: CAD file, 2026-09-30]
mechanical/export/tail-cap.dxf
57.0 x 39.0

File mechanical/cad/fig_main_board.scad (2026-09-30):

// Figure source: included into, never used by, woody_body.scad - imports
// resolve against the top-level file, which is why figures sit beside it.
// The main board - the one long board at the thumb level that carries the
// thumb switches and everything the carrier did (ADR 0017) - picked out: the
// oak top and key plate off, the board, its parts, the LED row, the key
// boards' ribbons, its mounts and the breath sensor in bright yellow, everything else faded,
// each labelled from the same variables that place it. fig_view = "plan" is
// the labelled view from above; "3d" is a perspective with only the title.
include <woody_body.scad>
use <lib/annot.scad>
figure = true;
show_lid = false;
origin = "centre";
fig_view = "plan";
// A literal list: an override is evaluated where the model first assigns
// highlight, before the model's own variables exist.
highlight = ["main board", "parts main board", "tall parts main board", "breath sensor", "LED row",
             "J-CHAIN left_hand main board", "J-CHAIN right_hand main board", "IDC plug left_hand main board", "IDC plug right_hand main board",
             "ribbon left_hand", "ribbon right_hand",
             "main board stud*", "main board spacer*", "main board nut*", "column standoff*"];
$k = 3;
module fig() {
    assembly();
    z = T + 4;
    s = 4.2;
    s2 = s * 0.85;
    top = W + 8;
    bot = -10;
    // The outline traced on top: from above, the board is under the key boards.
    color("DarkGoldenrod") translate([0, 0, z - 0.2]) linear_extrude(0.1) difference() {
        offset(0.4) cb_2d();
        offset(-0.4) cb_2d();
    }
    if (fig_view == "plan") {
        callout([gap_x[0] + 10, W / 2, z], [gap_x[0] + 12, bot - 10, z], "LED row (13) - lights both sides", size = s2);
        callout([tall_c[0][0], tall_c[0][1], z], [tall_c[0][0] - 2, top, z], "regulator + bulk caps", size = s2, halign = "right");
        callout([sensor_c[0], sensor_c[1], z], [sensor_c[0] - 2, top, z], "breath sensor (mouth end)", size = s2, halign = "left");
        callout([mb_chain("left_hand")[0], chain_y, z], [mb_chain("left_hand")[0] + 2, bot, z], "ribbon to the LH key board", size = s2);
        callout([mb_chain("right_hand")[0], chain_y, z], [mb_chain("right_hand")[0] + 2, bot, z], "ribbon to the RH key board", size = s2);
        callout([cb_standoffs[0][0], cb_standoffs[0][1], z], [cb_standoffs[0][0] + 2, bot - 10, z], "columns and mounts, on the bottom plate", size = s2);
        label([0, bot - 24, z], str("MAIN BOARD ", round(cb_x[1] - cb_x[0]), " x ", cb_y[1] - cb_y[0],
              " mm - the thumb switches, both thumb registers and the carrier circuits, one board"), size = s2, halign = "left");
        label([0, bot - 34, z], str(cb_room, " mm for parts under the keys, ", gap_room, " mm where no key board is overhead"), size = s2, halign = "left");
    } else
        label([L / 2, W + 14, z], "MAIN BOARD (yellow)", size = s * 1.4, c = "Black");
}
at_origin() fig();

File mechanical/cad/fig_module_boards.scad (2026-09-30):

// Both boards, each seen from the panel (the frame's x and y): the jack board
// on the left, the main board to its right. Solid: what stands on the face
// toward the panel. Outlined: what stands on the rear face. Drawn from the
// same lists the DRC and pcb-geometry.echo use.
include <module.scad>
use <lib/annot.scad>
figure = true;
$k = 1.2;
Z = 0.2;                       // drawing convention: layers stacked for the orthographic camera
DX = W + 22;                   // drawing convention: the main board's offset on the sheet

module r2(a, b) { translate(a) square(b - a); }
module fill(c) { color(c) translate([0, 0, 2 * Z]) linear_extrude(0.05) children(); }
module outline(c) { color(c) translate([0, 0, 3 * Z]) linear_extrude(0.05) difference() { offset(r = 0.25) children(); children(); } }
module tag(p, s, sz = 1.5) label([p[0], p[1], 4 * Z], s, size = sz);

// ---- jack board
color(C_PCB) linear_extrude(Z) jack_board_2d();
color([0.8, 0.8, 0.8, 0.5]) translate([0, 0, -Z]) linear_extrude(0.05) square([W, H]);   // the panel behind, for scale
for (j = jacks) { let(r = jack_body_rect(j[1])) fill(C_BLACK) r2(r[1], r[2]);
                  fill("Gold") for (i = [0 : 2]) translate([ju(j[1], jack_pins[i]), j[1][1]]) square([jack_pads[i][1], jack_pads[i][0]], center = true);
                  tag(j[1] + [0, jack_body_w / 2 + 1.4], j[0], 1.2); }
for (i = [0 : 2]) { fill(C_METAL) r2(pots[i] + [-pot_body[2] / 2, pot_body[0]], pots[i] + [pot_body[2] / 2, pot_body[1]]);
                    tag(pots[i] + [0, pot_body[0] - 1.6], layout_pots[i], 1.2); }
fill(C_NYLON) translate(led) circle(d = led_spacer_d);
tag(led + [0, 3.5], "LED-PANEL");
for (s = standoff_at) { fill(C_METAL) translate(s) circle(d = m3_head_d); tag(s + [0, -4.2], "standoff"); }
fill("Gold") r2(b2b_at - [b2b_w, b2b_l] / 2 - [1.27, 1.27], b2b_at + [b2b_w, b2b_l] / 2 + [1.27, 1.27]);
tag(b2b_at + [0, -b2b_l / 2 - 2.6], "J-B2B-MOD", 1.2);
tag([cx, notch[2] - 6], "notch: the NE8FAV", 1.3);
tag([cx, tog[1]], "SW-POWER", 1.1);
tag([cx, -6], str("JACK BOARD - ", b_x1 - b_x0, " x ", b_y1 - b_y0, ", ", jb_d, " behind the panel"), 1.5);

// ---- main board
translate([DX, 0, 0]) {
    color(C_PCB2) linear_extrude(Z) main_board_2d();
    fill(C_EC) r2(ec - fl / 2, ec + fl / 2);
    tag(ec, "J-UMBILICAL (NE8FAV)");
    fill("Gold") r2(b2b_at - [b2b_w, b2b_l] / 2 - [1.27, 1.27], b2b_at + [b2b_w, b2b_l] / 2 + [1.27, 1.27]);
    for (s = standoff_at) fill(C_NYLON) translate(s) circle(d = standoff_af / cos(30), $fn = 6);
    // Rear face, outlined.
    outline("Red") r2(pw - [power_w, power_l] / 2, pw + [power_w, power_l] / 2);
    tag(pw + [0, power_l / 2 + 1.5], "J-PWR-EURO (rear)");
    tag(pw + [0, -power_l / 2 + 1.5], "-12 V");
    outline("DarkOrange") r2([pw[0] + power_socket_w / 2 - power_ribbon_w, b_y0], pw + [power_socket_w / 2, power_socket_l / 2]);
    for (i = [0 : len(tall_at) - 1]) let(t = tall_at[i])
        if (t[2] == "cap") outline("Blue") translate([t[0], t[1]]) circle(d = tall_cap_d);
        else outline("Blue") r2([t[0], t[1]] - [tall_trim[0], tall_trim[1]] / 2, [t[0], t[1]] + [tall_trim[0], tall_trim[1]] / 2);
    outline("DimGray") r2(tog - tog_body / 2, tog + tog_body / 2);
    tag(tog + [0, -tog_body[1] / 2 - 1.5], "SW-POWER lugs, in front");
    tag([cx, -6], str("MAIN BOARD - ", b_x1 - b_x0, " x ", b_y1 - b_y0, ", ", mb_d, " behind the panel"), 1.5);
    tag([cx, -9], "solid: front face - outlined: rear face; orange: ribbon");
}
label([DX / 2 + cx, H + 6, 1], "THE MODULE'S TWO BOARDS, seen from the panel - mm, panel frame", size = 2.0);

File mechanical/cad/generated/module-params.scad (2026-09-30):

// GENERATED by tools/cad.py params - DO NOT EDIT.
// Source: config/module.yaml (and, where a leaf says ref:, the file it names). Edit
// those, then run `python3 tools/cad.py build`; `check` fails on a hand edit here.
// Units: mm. Every value below cites its source in the YAML it came from.

// ---- config/module.yaml
panel_w = 50.5;  // settled; [register panel-width] [ds] DOEPFER-A100-CONSTRUCTION-DETAILS-a100m_e.html, Table 1: 10 HP actual module width
panel_h = 128.5;  // settled; [ds] DOEPFER-A100-CONSTRUCTION-DETAILS-a100m_e.html: 'the final height is 128.5 mm for all A-100 front panels'
panel_t = 2.0;  // settled; [ds] DOEPFER-A100-CONSTRUCTION-DETAILS-a100m_e.html: 'The front panels are made of 2 mm anodized aluminium'; PANEL row
panel_hp = 5.08;  // settled; [ds] DOEPFER-A100-CONSTRUCTION-DETAILS-a100m_e.html: 1 HP = 5.08 mm; hole spacing must be a multiple of it
panel_hole_d = 3.2;  // settled; [ds] DOEPFER-A100-FRONT-PANEL-HOLE-SKETCH-A100FP.gif: d = 3.2 mm
panel_hole_x0 = 7.5;  // settled; [ds] A100FP.gif: the left holes 7.5 from the panel's left edge
panel_hole_n_hp = 7;  // settled; [adr 0024] the widest whole-HP spread that keeps the right holes inside 10HP: 7.5 + 7 x 5.08 = 43.06 [calc], as mechanical/EURORACK-3U-PANEL-HP-TABLE-make_blanks.py has for 10HP [ds]
panel_hole_y = [3.0, 125.5];  // settled; [ds] A100FP.gif: 3.0 from the bottom edge, 125.5 (3.0 from the top)
panel_slot_travel = 3.0;  // settled; [ds] EURORACK-3U-3HP-PANEL-apfaudio-pmod-r3.1.kicad_pcb Edge.Cuts: a FABRICATED panel's mounting cut is a slot, arcs of r 1.6 whose centres run 1.5 either side of the Doepfer hole centre [calc 6.0..9.0 from the left edge], so the panel takes the rail's nut strip wherever it sits in the HP grid. Doepfer's own sketch draws a round d3.2; the slot contains it
panel_four_screws = true;  // settled; [adr 0023] point 4 - four M3 screws; Doepfer: 'From 10/12 HP usually four mounting holes are used'
panel_washer_t = 0.5;  // tbd; [from memory] DIN 125 M3 washer thickness
panel_washer_od = 7.0;  // settled; [repo] MECH-PANEL-SCREW-MOD: DIN 125 M3 washer; OD 7.0 is the assumption panel-height-budget's clear height is derived on
rail_band = 10.0;  // tbd; [web] 108-110 mm is the usual maximum board height between the rails (modwiggler 'Max PCB height for Eurorack?', t=203897; sdiy.info wiki 'Eurorack'), i.e. ~10 mm at each edge; NOT banked - both pages refused a fetch (403) on 2026-09-29. Community rail profiles (github.com/rahji/eurorack-ears) exist but their orientation to the panel is not stated
rail_depth = 10.0;  // tbd; [from memory] how far behind the panel's rear face a Eurorack rail's profile reaches; drawn so the clash check sees parts in the rail band near the panel
case_depth_max = 45.5;  // settled; [ds] INTELLIJEL-PALETTE-CASE-MANUAL-2020-11-30.pdf p.6: '3U modules, up to a depth of 45.5mm' (middle HP; 37.42 at each 1 HP edge). Taken as behind the panel's REAR face - the manual does not say which face; the DRC also reports the depth from the front face, which is 2 mm worse
boards_t = 1.6;  // settled; [repo] PCB-MODULE, PCB-MODULE-JACK rows: 1.6 mm
boards_side_margin = 1.0;  // nominal; [adr 0024] each board's side edge this far inside the panel's side edge, so a neighbour module's board cannot touch it
boards_ec_clear = 1.0;  // nominal; [adr 0024] the jack board's notch this far clear of the NE8FAV's 25 x 25 body on each side
boards_toggle_clear = 1.0;  // nominal; [adr 0024] the jack board's notch this far clear of SW-POWER's body on each side and above - the body is deeper than the jack board's depth, so it passes through the board
boards_copper_edge = 0.5;  // nominal; [adr 0024] a pad's edge this far inside a board edge or cut-out (a fab-house edge clearance; the layout's own rules may be stricter)
boards_part_clear = 0.5;  // nominal; [adr 0024] the least air between two parts' envelopes that the DRC accepts
standoff_stock_l = 8.0;  // settled; [ds] WURTH-WA-SPAII-970080365-SPACER-M3-8MM-POLYAMIDE.pdf: 8.0 +/-0.1, M3 internal both ends
standoff_tol = 0.1;  // settled; [ds] as stock_l: +/-0.1
standoff_af = 6.0;  // settled; [ds] as stock_l: SW 6 (hex across flats)
standoff_hole_d = 3.2;  // nominal; [calc] M3 clearance, the panel's own hole size
standoff_at = [[16.75, 114.8], [33.75, 114.8], [6.375, 17.0], [44.125, 17.0]];  // nominal; [adr 0024] placed by hand against the pots, the legs and the rail band; module.scad DRCs every one
m3_head_d = 6.0;  // settled; [ds] ASPEN-DIN7985-ISO7045-PAN-HEAD-DIMENSION-TABLE.pdf: DIN 7985 M3 dk nominal max 6.0 (min 5.7) - the head MECH-PANEL-SCREW-MOD buys. The ISO 7045 head is smaller; the table banked is the DIN one
m3_head_k = 2.52;  // settled; [ds] as head_d: DIN 7985 M3 k max 2.52 (nominal 2.4)
b2b_rows = 2;  // settled; [repo] J-B2B-MOD: 2 x 10, 2.54 mm
b2b_pins = 10;  // settled; [repo] J-B2B-MOD
b2b_pitch = 2.54;  // settled; [repo] J-B2B-MOD
b2b_insulator_h = 2.54;  // settled; [ds 3D] KICAD-PinHeader_2x10_P2.54mm_Vertical-3D.step: insulator z 0..2.54
b2b_pad_d = 1.7;  // nominal; [repo] KiCad PinHeader_2x10_P2.54mm_Vertical pad (1.7 round) [from memory]
b2b_protrude = 1.5;  // nominal; [adr 0024] how far the posts stand out of the jack board's front face, for a solder fillet
b2b_tail = 1.5;  // nominal; [adr 0024] how far the tails stand out of the main board's rear face
b2b_at = [25.25, 77.0];  // nominal; [adr 0024] between the two jack columns, near the middle jack row; 1.5 above it (2026-09-30) so its tails clear U-ISO's body on the main board's rear face (iso.at)
power_l = 27.97;  // settled; [ds] XFCN-BH254V-16P-2x8-BOX-HEADER.pdf: B = 27.97 for 2x08
power_w = 8.8;  // settled; [ds] XFCN BH254V: body width 8.8
power_h = 9.05;  // settled; [ds] XFCN BH254V: height above board 9.05
power_floor = 2.55;  // settled; [calc] 9.05 height - 6.5 cavity depth [ds XFCN BH254V] = where a seated socket's face stops
power_socket_h = 14.35;  // settled; [ds] TE-IDC-SOCKET-CATALOG-82012.pdf p.52: 622/636 socket height after crimping WITH strain relief 14.35 (the taller build; 10.5 without)
power_socket_w = 6.1;  // settled; [ds] TE 82012 p.52: body width 6.10 max
power_socket_l = 24.82;  // settled; [calc] TE 82012 p.53: A = B + 7.04 (12-position: 19.74 = 12.70 + 7.04); 16-position B = 7 x 2.54 = 17.78, so A = 24.82
power_ribbon_t = 1.0;  // tbd; [from memory] 1.27 mm-pitch flat cable, ~0.9 thick
power_ribbon_w = 20.32;  // settled; [calc] 16 conductors x 1.27 mm pitch
power_at = [42.5, 35.0];  // nominal; [adr 0024] low on the right, behind the jack board's right leg, clear of the NE8FAV's tails (the NE8FAV is on the bottom row, centred) and of the lower right standoff screw's head; the ribbon folds down to the bus board behind the NE8FAV
power_drop = 10.0;  // nominal; [adr 0024] how far below the panel's bottom edge the ribbon's envelope is drawn - toward the bus board, which the model does not draw
tall_cap_d = 6.3;  // settled; [repo] C-BULK-RAIL 100 uF: CP_Radial_D6.3mm (the tallest of the four)
tall_cap_h = 11.0;  // tbd; [from memory] a 6.3 x 11 25 V 100 uF can; the banked KiCad model is a generic 6.3 tall
tall_trim = [9.53, 4.83, 10.03];  // settled; [ds] BOURNS-3296-TRIMPOT.pdf via R26: 3296W body 9.53 x 4.83 x 10.03
tall_at = [[40.0, 57.0, "cap"], [40.0, 67.0, "cap"], [40.0, 77.0, "cap"], [40.0, 87.0, "cap"], [25.25, 95.0, "trim"], [14.0, 95.0, "trim"], [36.5, 95.0, "trim"]];  // nominal; [adr 0024] representative spots for the three trimmers and four bulk caps, so the depth check sees them; the layout moves them. The caps sit in the right-hand column (2026-09-30) because U-ISO and its filter take the left
iso_body = [25.4, 25.4, 10.2];  // settled; [ds] RECOM-RPA20-AW.pdf PD-7, PD-8: 25.4 x 25.4 x 10.2 mm without heat sink
iso_pin_l = 5.6;  // settled; [ds] RECOM-RPA20-AW.pdf PD-8: pins 5.60 below the body
iso_pin_d = 1.0;  // settled; [ds] RECOM-RPA20-AW.pdf PD-8: pin d1.0 +/-0.1
iso_pins = [[-2.54, -10.16], [2.54, -10.16], [10.16, 10.16], [0.0, 10.16], [-10.16, 10.16]];  // settled; [ds] RECOM-RPA20-AW.pdf PD-8 recommended footprint: columns 20.32 apart, the 3/4 row 2.54 inside the body's edge; 2 and 1 at 7.62 and 12.70 from it, 4/5/6 at 0/10.16/20.32 [calc: offsets from the centre, turned 90 degrees]
iso_at = [14.2, 50.6];  // nominal; [calc] the only 25.4 square on the rear face: its bottom edge boards.part_clear above the NE8FAV's tails (ec.y + 12.35 + 0.5 = 37.85, taken as 37.9), its left 0.5 inside the board's edge (1.5), so the centre is 1.5 + 12.7, 37.9 + 12.7; J-B2B-MOD moved up to clear its top. The layout places it
iso_filter = [[6.0, 68.5, "can", 6.3, 7.7, "C-ISO-BULK"], [6.0, 76.5, "can", 6.3, 5.8, "C-ISO-OUT"], [15.0, 68.5, "box", 6.0, 2.8, "L-ISO-IN"]];  // nominal; [repo] the rows' packages: C-ISO-BULK SMD can 6.3 x 7.7, C-ISO-OUT 6.3 x 5.8, L-ISO-IN 6.0 x 6.0 x 2.8 (hardware/module/power-entry/bom.csv); placed just above U-ISO, where the layout will want them - an envelope, not a placement
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

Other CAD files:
mechanical/module/export/jack-board.dxf
datasheets/analog/KICAD-TSSOP-16_4.4x5mm_P0.65mm-3D.step
datasheets/connectors/SAMTEC-SHF-106-01-L-D-TH-3D.step
datasheets/discrete-and-power/KICAD-L_1206_3216Metric-3D.step
mechanical/cad/generated/params.scad
datasheets/analog/KICAD-MSOP-8-1EP_3x3mm_P0.65mm_EP1.68x1.88mm-3D.step
datasheets/analog/MPXV7007-CASE-1351-01-HAXO-3D.step
datasheets/connectors/ADAFRUIT-4056-PANEL-MOUNT-USB-C-3D.step
datasheets/connectors/GENERIC-RJ45-8P8C-PLUG-3D.step
datasheets/connectors/GENERIC-USB-C-PLUG-OVERMOULD-3D.step
datasheets/connectors/HANXIA-HX-JN1.27-2x6-WZ-H4.9-3D.step
datasheets/connectors/HANXIA-HX-PZ2.54-1x5P-ZZ-3D.step
datasheets/connectors/HANXIA-HX-PZ2.54-1x8P-WZ-3D.step
datasheets/connectors/JST-B4B-XH-A-3D.step
datasheets/connectors/JST-GH-SM08B-GHS-TB-KICAD-3D.step
datasheets/connectors/KICAD-IDC-Header_2x08_P2.54mm_Vertical-3D.step
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

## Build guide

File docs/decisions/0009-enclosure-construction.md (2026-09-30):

# 0009 — Enclosure construction

**Status:** Accepted. **How the body closes is amended 2026-09-29 by
[ADR 0025](0025-the-cassette.md)**: the six body fasteners are gone. The
internals are one bonded unit, the cassette, glued into the shell with RTV and
opened by cutting it. Each passage that ADR 0025 changes is marked in place.

## Context

No 3D printer and no CNC access; everything is outsourced. Basic wood
construction is available in-house, but not deep pocketing.

The instrument is **not round**. It is a flat sandwich: oak top and bottom,
frosted acrylic sides carrying LEDs, aluminium key plate on top, and three or
four mechanical keys on the underside for the left thumb, inset so the travel
feels right.

> **Finishes, 2026-09-28 (owner).** The wood is stained **a very dark
> ebony**, with the grain still showing through, under a satin oil finish.
> The frosted acrylic sides are **dark grey**. The tint is not only a look:
> the side LEDs light through these panels (ADR 0014), so how much a dark
> grey sheet passes sets how hard the LEDs are driven. **Open:** a sample of
> the chosen sheet under the chosen LEDs, before the sides are ordered
> (`SIDE-ACRYLIC`).

## Envelope

**Width 2.25 inches (57 mm); thickness 39.0 mm, about 1.54 inches** — the
register's `body-thickness`, stated here.

> **The thickness was 1.5 inches until 2026-09-26**, when the owner chose to
> set it by the etherCON rather than pocket the oak bottom for it. The
> connector stands on the floor with its rear socket and patch plug under the
> LED matrix *(since ADR 0021: an NE8FAV on an adapter, with no rear socket
> or plug; only `J-UMB` passes under the matrix)*; the matrix sits against the oak top, the key plate ending short
> of it, and the key and thumb boards join by stacking headers *(since ADR 0017: one main board, key boards on 12-way ribbons — 1.27 mm IDC since 2026-09-27)* (owner, same
> day: "tighter vertically"). `mechanical/drc.echo` ("body thickness takes
> the etherCON on the floor") gives the thinnest body that allows it — the
> connector's flange, floor to oak top — and this figure is that rounded up
> to a whole millimetre.

> **The length is no longer set here (owner, 2026-09-26: "minimize total
> length").** It is derived by the body CAD from the key layout, a little at
> the mouth end, the underside and the tail connector, and printed in
> `mechanical/drc.echo` ("overall length", with what sets each end). The
> 18-inch (457 mm) envelope and the table below are the original feasibility
> argument — the record of why a single line of keys was believed to fit —
> not the current length. Figures sized from 457 mm elsewhere (tube, looms,
> strips) are tracked for re-derivation in `ROADMAP.md`.

### Keys run in a single line

The instrument stays long and slender like a flute, with keys in **one
longitudinal line**. What makes 18 inches workable is not compressing the key
runs but **shortening the sections above and below them** — there is no acoustic
bore to accommodate, so the mouthpiece region and the tail can both be brief.

### Length closes

18 inches is compact for a wind controller — an EWI USB is around 24 inches, a
clarinet closer to 26. Worth checking rather than assuming, at a 24 mm key
pitch:

| Segment | mm |
|---|---|
| Mouthpiece / breath inlet (short) | 40 |
| Display band | 60 |
| Left hand, 5 keys in line | 96 |
| Inter-hand gap | 50 |
| Right hand, 6 keys in line | 120 |
| Tail: connector + strain relief (short) | 40 |
| End margins | 20 |
| **Total** | **426** |
| **Available** | **457** |
| **Slack** | **31 (1.2 in)** |

*(2026-09-26: the key runs have since been tightened — ADR 0010 — so this
table is now the conservative case. The working budget, and the slack it
leaves, are in `config/body.yaml` and `mechanical/drc.echo`.)*

It closes with 1.2 inches of slack, and more at a tighter pitch — the MT165 caps
at 16.5 mm allow roughly 18–20 mm before caps collide, against standard 18 mm MX
spacing. Not constrained, but the layout wants designing rather than
improvising, and the display band is now the second largest single claim on
length after the key runs — it grew from 30 mm to 60 mm when the board was
chosen (ADR 0008), which halved the slack. Anything else wanting length should
be checked against this table rather than assumed to fit.

**A useful side effect: the long-run signal concern from ADR 0001 largely
evaporates.** That analysis assumed roughly two feet between the MCU at the top
and the IMU and connector at the bottom. At 18 inches overall the longest run is
more like 14–16 inches, which is comfortable for SPI with ordinary care. RS-485
transceivers stay a contingency rather than a likely requirement.

### Thickness is bounded by switch bodies, not boards

The body's thickness (`body-thickness`), consumed roughly as:

```
  oak top                   = cap height above the seat - travel  <- flush rule, below
  aluminium key plate       1.20 mm <- SETTLED by Gateron's drawing, see ADR 0002
  ---- cavity ----          remainder
  oak bottom                = the same rule, for the thumb keys (below)
  thumb switch plate        ~2 mm
```

**The plate is under the oak, not on it (decided 2026-09-26)** — see "Keys
are flush at full travel" below. The cavity arithmetic does not change: the
lid is the same two layers in the other order.

That leaves the clear cavity the body CAD derives (`mechanical/cad/woody_body.scad`, `cavity_h`) — except where switch bodies intrude.
Top switches pass through the plate and oak and protrude slightly into the
cavity; the bottom thumb switches mount to the inside face and protrude *up*
into it by most of their body height.

**The KS-33 is 12.2 mm tall overall**, from Gateron's published specification —
this ADR previously called it unmeasured and deferred it to M1, which was wrong
on both counts: the switch is documented, and the number was available all along
(ADR 0002).

That is good news for the cavity. Against that clear space, even if the
entire 12.2 mm sat inside it there would be room left, and in practice several
millimetres of that height is stem and top housing sitting *above* the plate.
**The earlier worry that "usable cavity may be half of what it is elsewhere" in
the thumb regions looks overstated.**

What is still missing is the **split** — how much of the 12.2 mm falls above
versus below the mounting plane. That is on the dimensioned drawing, and it is
the reason to download the drawing and the STEP model before starting M4 rather
than modelling against a nominal box.

Boards are not the constraint on *depth*. An ESP32-S3-WROOM module on a PCB is
around 5 mm total. The thickness is comfortable; it is the switch bodies and the U-bolt
that eat the space.

**But the cavity is not a clear box in plan, either.** Switch bodies run down
the centreline for the whole length of both key runs, and thumb switches
protrude upward from the bottom face. The genuinely free volume is the upper
section, the inter-hand gap (minus the U-bolt), the lower section, and two
narrow side channels flanking the switch column — which are the natural route
for wiring looms *(since ADR 0017 there are none; the tube and ribbons use them)*. Board outlines belong on that plan, not on the raw envelope
(ADR 0013).

### The thickness suits the grip

The left hand sandwiches the body between fingers and thumb (ADR 0010). At
`body-thickness` that is a comfortable pinch — about the span of a thick book
spine. Thinner would make the grip cramped and give the thumb less leverage;
much thicker would strain it.

### Strap placement follows from the layout

The U-bolt goes on the **bottom face, in the inter-hand gap** — the 50 mm band
between the left thumb cluster and the right thumb rest, which is free of
switches and lands near the middle of the instrument where CG will be.

Bottom face is correct for the same reason a saxophone's strap ring is on the
back: the instrument hangs with its key face outward and the attachment toward
the player's body.

**Through-bolt the entire laminated stack.** The U-bolt then does two jobs: it
anchors the strap to the aluminium plate, which is the strongest element in the
sandwich, and it adds clamping force to the lamination at mid-span where it is
otherwise held only by adhesive.

## Width: 2.25 inches

**57 mm**, in the middle of the 50–60 mm window originally sketched here.

### Why the grip concern is smaller than the heuristic implied

The earlier reasoning assumed the sandwich grip carries the instrument. It does
not — **the strap does** (ADR 0005, U-bolt above). The grip *stabilises* and
positions; it does not bear weight.

That is exactly how a saxophone works: the right thumb hook and left thumb rest
stabilise while the neck strap takes the load, and a tenor body at the grip
point is nearer three inches across. The relevant question is not "can the hand
clamp this" but "can the thumb reach a comfortable opposing position and still
extend to its keys", which is a much weaker constraint.

### Nothing on the instrument binds the width

Two earlier justifications in this ADR turned out not to hold, and both are
worth recording because they were wrong in the same direction — assuming
something needed lateral room that does not.

- **Two-column key clusters.** Void: keys run in a single line (ADR 0010).
- **The left thumb's four-key arc.** Also void, and usefully so — see below.
  Four 16.5 mm caps laid *across* the body would need 66 mm of cap width alone,
  which does not fit at any width under consideration. The arc therefore has to
  run **along** the body, so it consumes length in the left-hand region, not
  width.

What is left is grip feel, display legibility, PCB area, cavity volume, and
enough side-panel height for the edge lighting to read. None of those is tight
at 57 mm, so the width is set by how the instrument should *feel* rather than by
a clearance anywhere.

2.25 inches sits between the slender flute-like 2 inches and the roomier 2.5,
and it is comfortably inside the span where the thumb can oppose the fingers.

### Mass

| Width | Mass |
|---|---|
| 2.00 in | ~735 g (1.62 lb) |
| **2.25 in** | **~778 g (1.72 lb)** |
| 2.50 in | ~825 g (1.82 lb) |

Aluminium plate, oak top and bottom, acrylic sides, plus ~200 g of electronics
and hardware. All three land in EWI territory (~1.5–2 lb); the width barely
moves it, which is another reason to choose on feel.

### Mass

Rough estimate at this envelope:

| Part | g |
|---|---|
| Aluminium top plate, 2 mm | 157 |
| Oak top, 6 mm | 131 |
| Oak bottom, 8 mm | 174 |
| Acrylic sides, 2 × 4 mm | 164 |
| Electronics and hardware | 200 |
| **Total** | **~825 (1.8 lb)** |

Squarely in EWI territory (~1.5–2 lb), and on a strap that is unremarkable. Not
a reason to reconsider.

### What to check at M2

The paper mockup should answer three specific things, and they are the only real
risks at this width:

1. **Can the left thumb reach its four-key arc** from a comfortable opposing
   position, without the hand shifting?
2. **Is the grip patch far enough from the key arc** that gripping does not
   trigger keys (ADR 0010)?
3. **Does the right thumb rest fall naturally** where the body wants to sit in
   the hand?

If any of those fail, the fix is narrowing toward 55 mm, which costs the
two-column layout. Worth knowing before anything is cut, and it costs one sheet
of paper.

## Decision

**A laminated stack of flat parts, every layer a 2D through-cut.**

### No CNC is required

Every part in this design is a flat sheet with through-cuts, which is laser and
waterjet territory rather than milling. Vendors like SendCutSend, Ponoko and
OSH Cut will cut aluminium, acrylic and plywood from a DXF at a fraction of CNC
cost with days of turnaround.

The key plate is the extreme case: a flat plate with a grid of rectangular
cutouts is close to the most laser-friendly part that exists.

### Lamination replaces pocketing

Rather than milling a recess into thick oak, build thickness from thinner layers
where the middle layer has a through-cut. Every layer stays a 2D part that can
be cut on a scroll saw or sent out flat. This is how a cavity gets built without
a mill.

### Keys are flush at full travel, so the plate goes under the oak

**Decided 2026-09-26.** A key pressed to the bottom of its stroke is level with
the top face; at rest it stands proud by the travel. That puts the switch seat
— the plate's top face — below the top face by the cap's height above the seat
less the travel, so **the plate moves under the oak top, and the oak top's
thickness is set by that rule rather than chosen**. The body CAD derives it
(`mechanical/drc.echo`, "oak top thickness"); until the MT165's height is
measured at M1 it rests on an estimate.

What changes, and what does not:

- **The oak top is a sheet with one clearance hole per cap**, which the cap
  travels in. It is still not structural and still holds no switch (ADR 0002):
  the plate retains every key, the oak only surrounds the caps. The clearance
  must exceed the oak's cross-grain movement across one hole, which the model
  checks.
- **The playing face is unbroken oak.** The six fasteners stop in the plate
  from below, so no hole in the oak top carries one. *(Since [ADR 0025](0025-the-cassette.md):
  there are no body fasteners. The column screws' heads sit in blind pockets in
  the oak top's underside, so the face is still unbroken.)*
  > **True, and simpler, 2026-09-28 ([ADR 0020](0020-key-boards-screw-to-the-plate.md),
  > Amendment 4).** The key boards hang on PEM self-clinching studs pressed
  > into the plate, their heads flush with its top face. Nothing stands above
  > the plate, so the wood top has no pockets at all and bonds to a flat
  > plate; nothing goes through the face. The owner: "the press and flush
  > looked good, let's go ahead and convert to that".
  >
  > *Superseded 2026-09-28 by the note above — the record of Amendment 3:*
  > **True again, 2026-09-27 ([ADR 0020](0020-key-boards-screw-to-the-plate.md),
  > Amendment 3).** The key boards hang on screws whose heads sit on the
  > plate's top face inside **blind pockets drilled up into the wood top's
  > underside** (`hardware.kb_pocket_d`), one at each corner of each key
  > board. Nothing goes through the face and nothing is plugged. The owner:
  > "I don't want to have through holes and plugs in the wood. I want to
  > have only holes that go half depth in the wood, drilled from the inside".
  > The wood left over each pocket is ruled (`drc.echo` "key-board head
  > pockets leave wood over them", against `hardware.kb_pocket_skin`).
  >
  > **The species is open.** The owner: "we've been calling this oak, but
  > honestly, I'll probably use a harder wood, but it really doesn't matter
  > for the design aspect". A hardwood, the owner's choice. The part names
  > keep "oak"; the cross-grain movement figure below and the pocket
  > placeholders (`hardware.kb_pocket_wall`, `kb_pocket_skin`) assume oak
  > until the species is chosen.
  >
  > *Superseded the same day by the note above — the record of Amendment 2:*
  > **Amended 2026-09-27 ([ADR 0020](0020-key-boards-screw-to-the-plate.md),
  > Amendment 2): the face now READS as unbroken wood, and is not.** The six
  > lid fasteners still come from below. But the key boards now hang on
  > screws that go down through bores in the wood top, one at each corner
  > of each key board (`hardware.kb_bore_d`, `drc.echo` "key-board mounts"),
  > each bore filled over the screw head with a glued face-grain plug of the
  > same wood (`MECH-KB-PLUG`) — the owner's standard: "so that we can put a
  > wooden cap on top so it looks like it's not there". The plugs are cut
  > from the top's own stock, so the grain matches. What the playing face
  > loses is the claim that nothing pierces it; what it keeps is that
  > nothing shows, catches a finger, or loosens in play.
  >
  > **The species is open.** The owner: "we've been calling this oak, but
  > honestly, I'll probably use a harder wood, but it really doesn't matter
  > for the design aspect". A hardwood, the owner's choice. The part names
  > keep "oak"; the cross-grain movement figure below and the plug and
  > bore-wall placeholders (`hardware.kb_bore_wall`, `kb_plug_min_depth`)
  > assume oak until the species is chosen.
- **Superseded (2026-09-26, [ADR 0015](0015-one-mcu-no-display.md)): there is no display.** The display band is gone
  and the CAD derives a shorter mouth end. Record: **the display was on the underside** (same date), glass down, in a through-cut
  in the oak bottom — still in the display band at the mouthpiece end. Nothing
  is cut in the plate for it any more.
- **Thumb keys follow the same rule** (same date): flush with the bottom face at
  full travel. The thumb plate stays on the oak bottom's inside face *(since
  ADR 0025, one bottom plate for both thumbs, in the same place)*, so the
  oak bottom is the same thickness as the oak top and **"oak thickness sets the
  inset depth" becomes "the flush rule sets the oak thickness"** — the open
  question below is closed by it.
- **The plate is no longer under the player's hands**, but it is still a
  floating conductor a few millimetres from eighteen switch pins, so the
  bonding rule below stands unchanged.

### The thumb inset falls out for free

```
 ┌──────────────────────────┐   oak top (a hole per key cap)
 ├──────────────────────────┤   aluminium key plate (switch cutouts), under the oak
 │    electronics cavity    │   spacer layers; frosted acrylic sides + LEDs
 ├───────┬──────────┬───────┤   oak bottom, through-cut at the thumb
 └───────┤  switch  ├───────┘   thumb plate mounted to the INSIDE face
         └──────────┘
```

The thumb switches mount to a plate on the **inside** face of the bottom panel,
and the through-cut in the oak is the recess. **Oak thickness sets the inset
depth** — choose the bottom panel thickness to get the thumb travel wanted, and
the geometry follows. No pocketing anywhere in the design.

### Breath tube access

The breath system is closed and dead-ended, so condensation is modest and there
is no flow carrying saliva into the sensor (ADR 0003). A small dead-volume trap
at the sensor end handles what accumulates.

The only stack requirement is **access to clear it without disassembly**. Not a
drain plumbed through the body — just a serviceable path to the sensor end.

**The tube is ~400 mm and the sensor is at the tail** *(Amended 2026-09-26, ADR 0017: no longer — the sensor is on the main board at the mouth end beside the trap, and the tube is short, within the mouth band)*, not the 30 mm near the
top this section used to assume. The trap therefore sat at the tail alongside
everything else *(since ADR 0017: at the mouth end)*, and "clearable" meant reachable from the tail face *(since ADR 0017: from the mouthpiece end)* rather than
from the mouthpiece end. The tube ran the length of the body in one of the side
channels *(since ADR 0017: it does not)*.

### The tail carries a display window and a USB port

Two openings in the tail section, below the right-hand key run, clear of the
thumb keys and the U-bolt:

> **Superseded 2026-09-26 (owner): the matrix is on the TOP face, just past
> the last key**, through a window in the oak top. The
> window is **frosted acrylic, flush with the oak top, sitting on a lip of
> oak** (a rebate in the oak's upper face) — the owner's choice, made knowing
> frosted material softens pixels at this distance from the LEDs, which the
> diffuser guidance below warned against. **The Matrix board sits face up
> against the oak top under the window**, the key plate ending short of it and
> its LEDs standing up into the opening (owner, 2026-09-26: "the matrix can
> be up higher out of the way and still allow the connectors", then "tighter
> to the acrylic"), wired to the
> carrier by a pigtail soldered to its pads *(since ADR 0017: a 24-way
> ribbon (ADR 0018), soldered to its pads, into J-MCU on the main board)*, so **the carrier cutout below is
> no longer needed** and which face carries the LEDs stops being a risk. The
> etherCON's rear socket and the patch plug pass **under** it, beside its
> USB-C plug, so only the connector's housing queues behind it *(since ADR
> 0021: the connector and its adapter queue behind it, and only `J-UMB`
> passes under)*; the connector
> stands on the floor, and the body is thick enough for that
> (`body-thickness`). There is no carrier board any more: its circuits
> were on one flat board between the thumb and key boards, the centre board (ADR 0013) *(since ADR 0017: on the main board, which replaced the centre and thumb boards, under the key boards)*. The
> paragraphs below are the original underside design.

**A window in the oak underside for the 8×8 matrix** on the real-time board
(ADR 0007, ADR 0014). Roughly 22 mm square, facing the player's downward glance
rather than the audience. It is a through-cut in a flat part, so lamination
gives it for free — the cost is entirely in planning, because it constrains
where that board sits and it cannot be added once the laminated layers are
glued. (The body opens — see "The body comes apart" — but the U is one glued
sub-assembly and a through-cut in it is not a later job.)

Three details that have to be in the CAD from the start:

- **A matching cutout in the carrier PCB**, because the board's LED face points
  at the carrier and the light has to pass through it.
- **A diffuser, and not the side panels' material.** The sides are frosted to
  blur the strips into a glow; an 8×8 needs enough diffusion to kill hot spots
  and little enough to keep pixels distinguishable. Thin, and close to the LEDs.
- **Which face of the board carries the matrix** relative to its header rows.
  Confirm on arrival. If it is the wrong way round, the board moves to the
  carrier's underside; if that fails too, a flying harness for 14 signals, which
  is ugly enough to be worth knowing about early.

**A USB-C slot at the tail face**, which the instrument needs regardless of the
window. Flashing and USB MIDI (E5) both require reaching the real-time board's
own connector. The body opens on six fasteners now *(since ADR 0025, by
  cutting silicone)*, but opening it to flash a
board is a bench operation, not a thing to do with an instrument in a rack —
the slot is what makes it a cable. Keep that edge of the board at the tail.

**Decided 2026-09-26 (owner): a panel-mount USB-C extension.** With the matrix
on the top face the Matrix board sits a few centimetres inboard of the tail,
and the etherCON fills the tail's depth, so its own port cannot reach the
face. A short extension brings it to a receptacle in the tail cap beside the
etherCON (`CBL-USB-EXT`). The ESP32-S3's USB is full-speed, which a short
extension carries without a second thought; USB-Serial-JTAG recovery through
it is unchanged. The body CAD checks the receptacle fits beside the connector
and reports the cable run (`mechanical/drc.echo`).

**And the umbilical connector, which is the reason the tail face is now
crowded.** *(Since [ADR 0021](0021-pcb-mount-ethercon.md) the instrument's
etherCON is an NE8FAV: a square flange, a smaller bore, mounted latch up
behind a recess in the cap that leaves it the 3 mm panel it allows, and
screwed through that panel. The two bullets below argue about the NE8FDP;
the bore-not-flange point still holds, and the rotation is retired with the
part — `config/body.yaml` `ethercon:` has the NE8FAV's numbers.)* The
etherCON chassis flange (ADR 0004)
is roughly 26 × 31 mm on a face 57 mm wide and `body-thickness` tall. Two
consequences:

- **What is cut away is the bore, not the flange.** The chassis bore is
  **⌀24.0 mm minimum**, read off Neutrik drawing ST-NE8FDP
  (`datasheets/connectors/NE8FDP.pdf`); the 26 × 31 flange *overlaps* the
  face and clamps against it, and removes nothing. The connector stands on the
  floor since 2026-09-26, so it is not centred and the oak left below and
  above the bore differs — `mechanical/drc.echo` measures both ("tail cap
  material below and above the etherCON bore"). An earlier revision of this
  bullet worked the margin from the flange and got half the real figure.

  **Oak is still not what should be carrying it**, and the reason is unchanged
  by the arithmetic. This is the same rule as the U-bolt and the key switches:
  the wood is a shell, not structure (ADR 0002).

- **Rotate it 90°. Settled off the drawing.** The flange is 26 × 31 mm on the
  tail face, and the mounting pattern is two diagonal ⌀3.2 holes at
  19 × 24 mm — so the orientation is a free variable worth spending:

  *The table is the argument as first made, for a connector centred on the
  face as it was until 2026-09-26. It stands on the floor now, and the body
  CAD measures its margins (`mechanical/drc.echo`); what the table shows
  about rotation — flange and screw margin gained, bore margin unchanged —
  still holds.*

  | On the tail face | as drawn (portrait) | **rotated 90°** |
  |---|---|---|
  | Material above/below the **flange** | 3.50 mm | **6.00 mm** |
  | Screw-hole edge to face edge, vertically | 5.40 mm | **7.90 mm** |
  | Material above/below the **bore** | 7.00 mm | 7.00 mm — *rotation-invariant* |
  | Clear width beside the flange for USB-C | 31 mm | 26 mm — *amended 2026-09-26: the body CAD's lane, flange edge to the side's inside face, is about half this once the oak lips and acrylic sides come off the width and the connector is off-centre (`mechanical/drc.echo`, "USB-C extension receptacle beside the etherCON flange")* |

  Nearly double the flange margin and 2.5 mm more at the screws,
  for 5 mm of width beside it that the USB-C slot does not need — *amended 2026-09-26: it did need it. A flat slot, 12.5 mm plus a 2 mm web to the rotated flange, did not fit the lane beside it, and that forced the receptacle on end (`config/body.yaml` `openings.usb_slot_portrait`; `mechanical/drc.echo`, "tail cap web between the USB-C cutout and the etherCON flange"). Un-rotating is not the way back: the flange would then stand 31 mm tall, taller than the cavity behind the cap (`drc.echo`, "etherCON body inside the cavity height").*
  **Note what it does not
  fix:** the bore-referenced 7.00 mm is the same either way, so rotating is not
  what keeps the connector out of thin oak — the internal backing plate is.

  *(On the 10HP module panel both orientations fit: 12.25 mm of panel each side
  as drawn, 9.75 mm rotated. A review's "the orientation is therefore forced"
  was a **6HP** statement — at 30.18 mm the rotated case left a 1.49 mm web —
  and 10HP made it false.)*
  **Mount the connector to an internal backing plate** — aluminium or ply, tied
  into the same stack that carries the keys — and let the oak be the face the
  screws pass through rather than the thing the screws hold.
  *(Superseded 2026-09-26, owner: the etherCON need not be panel mounted. It
  now sits with flange and chassis behind the tail cap, its front through the
  cap's bore — the drawing's "both behind" depths — and the backing plate and
  its 4 mm panel limit no longer apply to it. The U-bolt keeps its plate.)*
- **It shares the face with the USB-C slot**,
  leaving roughly 31 mm beside the flange for it. That fits — *amended 2026-09-26: 31 mm was the unrotated column of the table above; the model's lane is about half the rotated one, and the receptacle fits it only on end, earless, behind an overmould pocket in the tail face (`config/body.yaml` `openings.usb_mount`; `mechanical/drc.echo`, "USB-C extension receptacle beside the etherCON flange", "USB-C plug overmould reaches the receptacle", "USB-C receptacle mount inside the cavity").*
  But it is not the place to discover a conflict.
  Both openings and the backing plate go into the M4 CAD together, and the
  1:1 paper check covers this face as well as the 10HP panel — and the tail is
  now the tight one of the two.

> **Superseded (2026-09-26, owner: "service cover is for to remove"): there is no service cover.** The console header
> stays, on the centre board inside the body, and is reached by taking the
> lid off (six fasteners). USB-Serial-JTAG through the tail USB-C port is
> the recovery path that works with the body closed. The underside past the
> right thumb is plain oak.

**And a screwed service cover on the tail underside**, beside the matrix
window, over a **six-pin** header on the carrier: `U0TXD`, `U0RXD` and `GND`
for each board.

**Not `EN` and `IO0`, which are not available.** The vendor's own board
definition accounts for every pin on the ESP32-S3-Matrix's two header rows —
three power and seventeen GPIO — and neither appears. They exist on the board
(`IO0` under the BOOT button, `EN` on the reset circuit) but reaching them
means soldering to the dev board, which would end its life as a socketed,
swappable module. *(Amended 2026-09-26: since ADR 0017 the ribbon is
soldered to the Matrix anyway and nothing is socketed, so this reason is
gone; `EN` and `IO0` are wired to the service header since
[ADR 0018](0018-main-board-wiring-decisions.md) — `hardware/carrier/service-uart/`.)* Not worth it, because the header was never the first line of
defence. Roughly 12 × 40 mm, two M2 screws into the plate stack,
in the same laminated layer as the window.

**There are three lines of defence and this header is the third**, which is
why losing the boot-force pins is acceptable:

> **(2026-09-26, [ADR 0015](0015-one-mcu-no-display.md)): no radio, so no OTA.** The first line of defence below is
> gone; USB-Serial-JTAG is now the first, and this header the second.

1. **OTA rollback.** An image that does not mark itself valid is rolled back by
   the bootloader at the next boot. Covers the likely case — a bad flash.
2. **USB-Serial-JTAG through the tail USB-C slot**, which is a designed opening
   and stays reachable with the body closed. This works *provided the
   application has not claimed USB-OTG*, because the S3's internal PHY routes
   to one or the other and never both. **That is the whole reason USB MIDI is
   opt-in rather than default** (`firmware/README.md`) — it keeps the download
   path alive through every boot that has not been asked for MIDI.
3. **This console header**, for watching a board that boots but misbehaves.

What is given up is forcing the boot mode by hand when software cannot — and
that is now **recoverable rather than terminal.** The body opens on six
fasteners, the dev boards are socketed *(since ADR 0017: the Matrix unplugs
at J-MCU and its ribbon is desoldered)*, and a corrupted *bootloader* means
taking the lid off and swapping or re-flashing a board on the bench. This
paragraph used to end "ends the instrument", which was true of a bonded body
and is not true of this one. Still inconvenient, still behind three
mitigations, no longer fatal.

*(Superseded (2026-09-26, [ADR 0015](0015-one-mcu-no-display.md)): there is no display board.)* ~~The display board needs none of this.~~ It was flashed over its UART from the
real-time board, which closes ADR 0013's open question about how it gets
programmed and removes the one case where a board with no external connector
had to be recovered through hardware.

Placing the umbilical at the tail also puts it as far as possible from the
mouthpiece, so the cable leaves the instrument at the end that hangs low and
does not foul the player's hands or the strap.

Both are cheap now and unavailable later, which is the recurring shape of every
decision in this section.

### Strap point: U-bolt above the centre of gravity

A U-bolt near the middle of the instrument, **slightly above the centre of
gravity**, carries a neck strap.

Above CG is correct and deliberate: a mass hung below its suspension point is
pendulum-stable and self-rights, while hanging at or below CG is unstable and
wants to flip. *Slightly* above is also right — a large offset gives a strong
restoring torque that fights the player, and a wind controller has to be angled
by the player at will. A small offset gives a gentle centring tendency with
compliance left over.

**This is the highest-stress point in the entire build.** The strap carries the
whole instrument, and it carries it *during play*, not just at rest — the left
thumb momentarily gives up grip every time it extends to a key (ADR 0010).

Two consequences:

- **It must anchor to the structural plate stack, not to the oak.** The wood is
  a shell (ADR 0002) and a U-bolt through oak alone will crush the fibres and
  eventually tear out. Through-bolt to a metal backing plate inside the cavity,
  tied into the same structure that carries the keys. *(Since [ADR 0025](0025-the-cassette.md):
  that plate is the cassette's bottom plate, the length of the body, which the
  legs pass and which the columns tie to the key plate. There is no separate
  backplate.)*
- **The position must be settled empirically, which is not the same as being
  adjustable.** CG cannot be known accurately from CAD — cable, connector,
  adhesive and finish all add mass that is hard to model, and what matters is
  how it *feels* hanging, not where the model says the centroid is.

  An earlier revision asked for a slot or discrete hole positions "so balance
  can be tuned empirically after assembly." **A review called that impossible**,
  because the backing plate the U-bolt anchors to sat inside a bonded cavity and
  an adjustment requiring a part you cannot reach is not an adjustment.

  **The serviceable body gives it back.** Six fasteners, lid off, move the
  bolt, lid on — so a slot or a row of positions is now worth cutting, and the
  balance can be tuned with the instrument on a strap and everything in it.
  Still do it once at M8 rather than treating it as a user control.
  *(Since [ADR 0025](0025-the-cassette.md): moving it after closing means cutting the
  silicone and a new main board, whose holes fix it. So the first way below,
  dry-assembly before closing, is the only one.)*

  Two ways to have it, and they are no longer exclusive:

  - **Dry-assemble, hang, balance, then close.** The stack goes together with
    everything in it that contributes mass, it hangs from a temporary strap,
    and the position is marked. This is free, and it folds naturally into the
    **M8 gate** — which exists anyway, for other reasons.
  - **Or make the anchorage reachable from outside** — a captive plate in a
    machined recess accessible through the bottom face, with the slot in the
    external hardware rather than the internal plate.

  **Take the first.** The second adds a serviceability feature to a part of the
  instrument that will be adjusted exactly once.

The U-bolt also intrudes into the electronics cavity near the middle of the
body. It is an obstruction that belongs in the CAD from the start, with cable
routing designed around it rather than discovered during assembly.

### The right thumb rest is a stack feature

The right thumb rests on the instrument and its three control switches sit
offset from that rest position (ADR 0010). That means a **defined thumb rest**,
not bare oak — and on a flat sandwich with no pocketing available, it is another
laminated layer: a small additional piece bonded to the bottom panel forming a
lip or contour for the thumb to sit against.

Consistent with everything else here — a 2D part, cut flat, added by lamination
rather than removed by machining.

## Ergonomic iteration ladder

Without a printer, iteration goes cheapest-first:

1. **Paper at 1:1, taped to a board.** Free, same day. Catches gross errors — is
   the reach right, do the fingers splay naturally.
2. **Laser-cut acrylic test plate**, real switches clipped in, hand-wired.
   ~$20–40 and about a week. This is the real ergonomic test.
3. Iterate step 2 once or twice, then commit to aluminium.

Slower than a printer would be, but cheaper per iteration than 3D printing for
flat parts, and not blocked.

**No aluminium is cut before M3.**

## Consequences

- CAD produces DXF as the primary export. Every part must be expressible as a 2D
  outline with through-cuts; if a part needs 3D machining, the design is wrong.
- The wood remains non-structural (ADR 0002). The plate stack carries the keys
  and mounts to the body at a few points.
- Strap attachment points are hard points through the oak and must be designed
  in, not retrofitted (ADR 0005).
- *(Superseded (2026-09-26, [ADR 0016](0016-one-strip-on-the-centre-board.md)): there are no side strips; the one strip lies on the
  centre board, and the side channels carry the tube and the looms.)*
  *(Amended 2026-09-26, ADR 0017: the strip is on the main board, there are no
  looms, and the tube stays in the mouth band.)*
  **The two side channels are shared: LED strips on both sides, looms alongside.**
  An earlier revision assigned the channels to the wiring looms while ADR 0014
  assigned the same two to the LED strips — a direct contradiction between two
  accepted decisions, and one that made ADR 0014's own instruction ("keep the LED
  runs away from the breath wiring") unsatisfiable.

  **It is resolved by the sensor moving to the bottom** (ADR 0003). The analog
  breath pair no longer runs the length of the body at all *(Amended 2026-09-26, ADR 0017: it does again — the sensor is at the mouth end and the buffered signal runs the main board as a trace over its own ground; E11 is the test)*, so what shares the
  channels with pulsed LED current is the SPI key chain, the UART and power —
  all digital and all tolerant. Digital beside pulsed LED current is a far weaker
  objection than analog beside it would have been.

  **The key chain still needs a ground return per signal** (ribbon with
  alternating grounds, or twisted pairs) — that requirement is independent of
  what else is in the channel, and it is the one thing that makes this sharing
  safe.

  Diffusion gap between strip and acrylic is a prototype question and it
  constrains the channel depth.

## Things that are free now and impossible later

**This section is weaker than it was, and deliberately so.** It used to open
"a body that is bonded shut is a body that is never opened again." The body is
not bonded shut any more, so the items below are no longer *impossible* later —
they are merely expensive, because getting at them means lifting the lid,
disturbing the loom *(since ADR 0017: unplugging J-MCU and, with the lid laid beside the body, the two key-chain ribbons — IDC sockets since 2026-09-27, no ZIF latches)* and re-laying a gasket. That is a real cost and it is worth
avoiding, but it is not the cliff this page was written against.

**Two of them are still genuinely impossible later**, because they are cuts in
the glued U or in a laminated layer: the matrix window (now through the lid —
oak top and plate — rather than the U) and the channels. Those keep the old force. Everything else below: do it now
because opening a finished instrument is a bad afternoon, not because you
cannot.

**Populate the console header** on the centre board. *(There is no service
cover to cut since 2026-09-26; the header is reached with the lid off.)* It
is the last line of defence between a bad flash and an instrument that will
not boot, and the one dev board depends on it (ADR 0015).

**Bond the aluminium plate to `PWR_GND`. Never to `AGND`.** Nothing currently
bonds it. It floats under the player's hands, one to two millimetres from
eighteen switch pins that are wired directly to shift-register inputs — and a
corrupted chain read becomes a spurious note-on at full velocity (ADR 0001). An
unbonded plate means the instrument fires random notes when touched in a dry
room, and that will be blamed on firmware forever. The choice of *which* ground
matters as much as the bonding: tying it to `AGND` would put the player's body
capacitance straight onto the breath channel's voltage reference.

**Fit the key input networks.** A 74x165's parallel inputs have no internal
pull-up, so without them every key input floats in a channel shared with 12 V
LED power and 800 kHz data — a pull-up, a series resistor and a capacitor per
switch position on the cluster boards (ADR 0001; the values are
`key-switch-network.md` §2's, `R-KEY-PU`, `R-KEY-SER`, `C-KEY`). *(Amended
2026-09-27: this line gave 10 kΩ, 100 Ω and 10 nF, a network retired on
2026-09-21.)*

*(Amended 2026-09-26: since ADRs 0016 and 0017 there is no hand-built loom.
The key boards are on flat flex *(1.27 mm IDC since 2026-09-27, ADR 0017's amendment)* and the Matrix on a 24-way ribbon, whose extra positions carry 5 V and
ground (ADR 0018, `CBL-MCU-RIBBON`).)*
**Run two spare conductors in every internal loom.** The looms are hand-built,
once, and threaded through channels in a glued sub-assembly. The lid comes off,
but the looms do not re-route themselves. A spare pair costs a few cents and
some crimping now; discovering you need one signal more afterwards costs a
strip-down.

**Conformal-coat the boards.** The instrument is breathed into for hours, behind
eighteen unsealed switch cutouts *(Amended 2026-09-26: one more since hold/preset became RT4 — `config/key-layout.yaml`)*, in a body whose interior runs 10–20 K above
ambient. There is no coating anywhere in the BOM and nothing else in the design
addresses humidity inside the cavity.

**Choose the adhesives before M8, not at M8.** Two products, split by joint —
see below. Both are cheap and neither is exotic; what is expensive is
discovering at M8 that the one tube in the drawer releases acetic
acid into a sealed box full of electronics.

**Mask both pressure-sensor ports before coating.** The breath sensor's
reference port has to stay open to the cavity, and coating that seals it turns
the reference chamber into a trapped volume that gains ~5.2 kPa when the body
warms — clipping the output to zero and presenting as a dead sensor that works
from cold and fails ten minutes in (ADR 0003). Adhesive during lamination can do
the same thing, so orient the part with neither port facing a glue line.

**Dry-assemble and balance before final closure**, per the U-bolt section
above. This is the M8 gate in the roadmap. The U-bolt position is no longer
something M8 is the *last* chance to settle — the lid comes off — but it is
still the sensible time, because M8 is when the instrument first has all its
mass in it.

## The body comes apart

> **Superseded 2026-09-29 by [ADR 0025](0025-the-cassette.md).** The owner: "we could just drop
> it into the instrument with a little bit of silicone to glue it to the top
> and bottom wood ... so no need to like screw into the wood except for maybe
> the u-bolt". The six fasteners, their counterbores and the lid's gasket are
> gone. The internals are one unit, the cassette, built and tested on the
> bench and bonded to the oak top and bottom with RTV. The oak top's joints at
> the side grooves are glued too. **Service is by cutting the silicone**
> (ADR 0025, *Consequences*). This section is the record of the body that
> opened on screws. What it says about the cavity's leak (the breath
> reference must see the room) and about M8 still holds. A glued joint of RTV
> beads is not airtight unless it is made so, and M8 still watches the zero.

**This supersedes the page's earlier assumption that the stack is bonded shut.**
The section below the U-bolt already said it in one line — "a body that is
bonded shut is a body that is never opened again" — and then the construction
went on bonding it. It does not any more.

### A U, a notch, and six fasteners

```
        ┌──────────────────────────────┐   aluminium key plate
        ╞══════════════════════════════╡   oak top   ─┐
        │                              │              │  the lid
   ┌────┴──────────────────────────────┴────┐        ─┘
   │  ╱                                   ╲ │
   │ ╱        electronics cavity            ╲│   frosted acrylic side  ─┐
   │╱                                        │   (one side of the U)    │
   │                                         │                          │ the U
   └────────────┬──────────┬─────────────────┘   oak bottom            ─┘
                │  switch  │
                └──────────┘   thumb plate, inside face

        ▲        ▲        ▲        ▲        ▲        ▲
        └────────┴────────┴────────┴────────┴────────┘
         six fasteners, up through the bottom, into the plate
```

> **Superseded in part, 2026-09-26: the sides sit BETWEEN the oak panels, in
> grooves, not on the outside of them.** Oak top and oak bottom both run the
> full width; each frosted acrylic side stands in a groove cut along the
> inner face of each panel, set in from the edge behind an oak lip. The U is
> still one glued sub-assembly — the sides are glued into the **bottom**
> grooves — and the lid now drops onto the sides' top edges, which slide into
> the **top** grooves. **That groove replaces the notch below**: it locates the
> lid laterally and takes the shear, and the gasket bead goes in it. Two
> costs, both measured by the body CAD (`mechanical/drc.echo`): the grooves are
> a saw or router pass, the one cut in the stack that is not a through-cut;
> and the oak lips come off the interior width twice.

**One side is a U.** The oak bottom and the two frosted acrylic sides are
assembled as a single channel — glued to each other, once, permanently. That
sub-assembly is never taken apart again. *(It carried the LED strips until
ADR 0016 moved the one strip onto the centre board.)*

**The other side pulls in on a notch.** The lid — oak top on the aluminium key
plate — drops into a rebate cut along the top inside edge of each acrylic side.
The notch locates the lid laterally and takes the shear, so the fasteners only
have to hold it down.

**Six fasteners come up from the bottom face, through the whole instrument,
into the aluminium plate.** They are the only thing holding the instrument
closed. Six, not four, because the span between fasteners is what sets how
much the lid can lift between them. *(On the original 457 mm body that put
them ~80 mm apart. The derived body has three stations of two — mouth end,
between the hands, before the connector — placed where the keys are not;
`mechanical/DESIGN.md`.)*

**Why this and not a lid that screws down from the top:** the top face is the
playing surface and the one the hands sit on. Fastener heads there are
something to feel, something to catch a finger, and six holes through a plate
whose flatness under the switches is the whole point of it being aluminium.
From underneath they are invisible in play and land in oak, which takes a
counterbore for free.

> **Amended 2026-09-28 (ADR 0020, Amendment 4): this holds, for
> everything, with nothing above the plate.** The key boards hang on studs
> pressed into the plate, heads flush with its top face; the clinch holds
> each stud against turning, so the nuts come off from below with the lid in
> place, and there is no head to hold, pocket or epoxy.
>
> *Superseded 2026-09-28 by the note above — the record of Amendment 3:*
> **Amended 2026-09-27 (ADR 0020, Amendment 3): this holds again, for
> everything.** No screw goes through the playing face. The key-board screws
> are put through the plate from its top face before the plate is bonded to
> the wood, and their heads end up in blind pockets in the wood's underside.
> Once the lid is bonded a head cannot be held, so each head is fixed to
> the plate with a dot of epoxy before bonding (the owner, 2026-09-27: "Yes,
> add the epoxy dot on the heads"); the nuts then come off from below with
> the lid in place (ADR 0020, Amendment 3).
>
> *Superseded the same day by the note above — the record of Amendment 2:*
> **Amended 2026-09-27 (ADR 0020, Amendment 2).** This still holds for the
> lid: its six screws come from below. It no longer means that nothing
> screws down from the top. The **key-board** screws do, through the wood
> top, their heads on the plate at the floor of each bore and under a
> glued wooden plug, so the face shows no head and no hole. They hold the
> key boards, not the lid, and the lid comes off without touching them. The
> reasons above (a head to feel or catch, holes through the plate under the
> switches) are what the plug and the corner positions answer: the heads
> are covered, and the screws sit outside every switch cutout
> ("key-board screw heads bear on plate metal").

### The two end caps, and what they are made of

The ends are separate parts, not extensions of the top or the bottom.

| End | Material | Why |
|---|---|---|
| **Mouthpiece end** | **Acrylic**, with a drilled circle for the tube pass-through | It is the part most likely to want changing. A pass-through diameter that turns out wrong, or a mouthpiece that wants a different mount, is one flat part to re-cut — and acrylic is the material already being cut for the sides |
| **Tail end** | **Oak**, carrying the etherCON and the USB-C slot (the matrix window is on the top face since 2026-09-26) | So the wood reads as wrapping from the top face around the bottom and up the back, which is the look. And it is the face with the most openings in it, which wants the material that takes a backing plate |

> **Decided 2026-09-26 (owner): the mouthpiece end is oak**, the same stock
> as the tail cap - the wood now wraps both ends. The table above is the
> record of the acrylic reasoning.

**If the acrylic mouthpiece end looks wrong on the bench, it becomes oak.**
Same cut, same fixings, different sheet. That is the reason to make it a
separate part rather than a lip on the top panel — the decision stays open
until there is something to look at, and it costs nothing to keep open.

**The etherCON exits the tail end face, axially** — straight out the back along
the instrument's long axis, the way a flute's foot joint is open at the end.
Not out of a side, and not out of the bottom face. The cable then leaves in
line with the body, which is what makes a 2 m tether hang rather than twist
(ADR 0004).

### What this costs, and what it does not

**It does not weaken anything.** The load paths were never the glue: the keys
land on the aluminium plate, the plate is the structure, and the U-bolt hangs
from the same stack. What the glue did was hold the shell together, and six
M3s do that better because they can be done up again. *(Since [ADR 0025](0025-the-cassette.md):
the load path is the cassette's columns, key plate to bottom plate, and the
bottom plate bears on the oak bottom. The shell is glued and is the main
structure, in the owner's words.)*

**It costs the cavity's seal, and that is fine.** The MPXV4006DP is a
*differential* part with its reference port open to the cavity, so the cavity
**must** leak or the breath zero walks with temperature (ADR 0003). A body that
comes apart on a gasket leaks by construction. The M8 soak still watches the
zero, but it is now watching for a cavity that seals *too well* rather than
hoping one was built loose enough.

**It changes what M8 is.** M8 was the pre-bond gate — the last moment before
the body closed forever. It is now the **pre-assembly gate**: the last moment
before the instrument is treated as finished, and the point at which every
measurement is taken on the final loom *(since ADR 0017: the final boards and ribbons)*. The tests do not change. What changes
is that failing one of them after M8 is now a repair rather than a rebuild.

### Adhesives, and which joint gets which

*(Titled "Two adhesives" until 2026-09-27, and it was never only two - the
U's acrylic joint has its own. The key-board screw heads' epoxy had a row from
2026-09-27 until the screws gave way to clinched studs, 2026-09-28, ADR 0020
Amendment 4.)*

"Structural adhesive for oak/acrylic/aluminium" was one line in the BOM for at
least four joints with incompatible requirements, which is the same defect as
ordering a ferrite bead and an electrolytic on one row.

| Joint | Adhesive | Permanent? |
|---|---|---|
| Oak ↔ oak — spacer layers, thumb rest lip | **PVA wood glue** | Yes |
| Frosted acrylic sides ↔ oak bottom — **the U** | **PVA is wrong here; use a solvent-free acrylic-to-wood structural adhesive or a mechanical fixing** | Yes — this is the one sub-assembly that stays together |
| Aluminium key plate ↔ oak top — **the lid** | **RTV silicone**, still — see below. Bonded **after** the key boards are mounted on the plate's studs and soldered (ADR 0020, Amendment 4) | Yes, within the lid. The key boards still come off from below: their studs are clinched in the plate and do not turn |
| Lid ↔ the U, at the notch | **RTV as a gasket bead, not an adhesive.** Skinned, not fresh, so it seals without sticking | **No — six fasteners** |
| End caps | **Fasteners into the stack** | **No** |
| Matrix diffuser | **RTV silicone**, edges only, clear of the light path | Yes |
| Thumb plate ↔ inside face of the oak bottom | **RTV silicone** | Yes |

> **Amended 2026-09-29 ([ADR 0025](0025-the-cassette.md)).** The key plate is bonded to the
> oak top with RTV, as the table says. But it is bonded as the top of the
> cassette, after the cassette is assembled, with the column screws' heads
> finding their pockets. The **bottom plate**, which replaced the thumb
> plates, is bonded to the oak bottom's inside face with RTV too. The **oak
> top to the U** at the side grooves is no longer a gasket clamped by six
> fasteners. It is an RTV bond, fresh, not skinned, and cut to open. The
> **end caps'** "fasteners into the stack" were never drawn, and the owner
> wants nothing screwed into the wood, so how the caps are held is open
> (ADR 0025, *Open*). RTV is now the adhesive on every joint that may have to
> open, and the gasket paragraph below is the record.

**RTV changes job, not product.** It was the adhesive on four joints; it is now
the adhesive on two and a **gasket** on the one joint that opens. Same
neutral-cure tube, same two shop rules below. The gasket is laid on one face,
allowed to skin, and then clamped by the fasteners — which is how it seals a
joint that has to come apart again.

Wood to wood is wood glue — the strongest, cheapest joint available and the one
nobody needs to think about. The plate joint stays RTV for a reason worth
stating:

**A thin silicone layer is compliant in shear and stiff in compression**,
because a wide bonded layer cannot squeeze out sideways. On the plate joint that
is exactly the two behaviours wanted at once. Oak moves roughly 1–1.5 % across
the grain with indoor humidity — **0.6–0.9 mm over the 57 mm width** — against
an aluminium plate that moves essentially nothing, and a rigid bond would have
to fight that for the life of the instrument. RTV lets it slide. But press a
key and the plate is pushing *into* a thin confined layer, which barely gives.
*(Corrected 2026-09-29, [ADR 0025](0025-the-cassette.md): this was written for a plate on top of
the wood. Since the plate went under the oak top (2026-09-26, above), a key
press pulls the plate away from the wood, and the layer is in tension, not
compression. The cassette's columns now take the press, down to the bottom
plate and the oak bottom in compression. The shear argument above stands.)*
Epoxy would have bought shear stiffness nobody needs and paid for it by
fighting the wood.

*(Thermal is the small term here, not the large one. Aluminium over 400 mm and a
20 K swing is 0.18 mm; wood and water is three to five times that.)*

**The specifics, because each is easy to get wrong at the shop:**

- **Neutral cure, not acetoxy.** The common hardware-store RTV releases acetic
  acid as it cures, and this cure is happening inside a sealed cavity holding
  two dev boards, a carrier, connectors and a pressure sensor. Buy **alkoxy
  (alcohol) cure**, sold as electronics-safe or low-corrosivity.
- **Bead it, do not butter it.** RTV cures by taking moisture from the air,
  inwards at a couple of millimetres a day. A full-face layer trapped between
  the plate and the oak has no path to cure through. Beads with gaps between
  them, and real time before the final closure goes on — which also keeps the
  outgassing away from the breath sensor, alongside the port-masking rule
  above.
- **The plate's beads may run over the key-board studs' heads** *(2026-09-28,
  ADR 0020 Amendment 4)*. They are flush with the plate's top face and never
  turn, so silicone on them costs nothing. Order: mount the key boards on the
  studs and solder them, then bond the plate to the wood. *(Until that day
  this bullet kept the beads off the screw heads' pockets, and before that
  off Amendment 2's plugged bores.)*

## Open

- ~~CAD tool~~ — **decided 2026-09-26: OpenSCAD, parametric, in
  `mechanical/cad/`**, driven by `config/body.yaml` and `config/key-layout.yaml`
  through `tools/cad.py`, which also fingerprints every render and DXF against
  its sources (`mechanical/README.md`). The length table and the stack sketch
  above are the feasibility argument; `config/body.yaml` holds the working
  values the model draws, each citing this page, and `mechanical/drc.echo`
  reports what the model found against them (`mechanical/DESIGN.md`).
- ~~Oak thickness for the bottom panel~~ — **closed 2026-09-26** by the flush
  rule above: it is derived from the cap height, which M1 measures.

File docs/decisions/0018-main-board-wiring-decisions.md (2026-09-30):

# 0018 — Main board wiring: five decisions

**Status:** Accepted

Closes five items that [ADR 0017](0017-one-main-board.md)'s rework left open
on the main board's pages. Decided by the owner, 2026-09-26, taking the
recommendation on each.

## Context

Moving to one main board, with the key boards on flat flex ribbons and the
Matrix on the lid, left five questions open in `hardware/`. A cold review of
that rework then found one fact that changed two of them: **the Matrix's 5 V
pad is `VCC_5V` itself, downstream of its `B5819WS`**
(`datasheets/mechanical/WAVESHARE-ESP32-S3-MATRIX-SCHEMATIC.pdf`; ADR 0014's
2026-09-26 amendment). Fed from the pad, the Matrix's LED current is limited
only by the firmware clamp and the regulator (`U-BUCK`), so it all crosses
`J-MCU` and the ribbon.

## Decision

1. **The Matrix ribbon is 24-way, and its extra conductors carry power and
   ground.** `J-MCU` becomes a 2 × 12 1.27 mm box header and `CBL-MCU-RIBBON`
   a 24-way ribbon: the twelve used GPIO, three 5 V, four ground, 3V3, `EN`,
   `IO0` and two spare GPIO, in a pin order that puts a ground or a quiet
   line beside every fast signal. The extra 5 V and ground conductors are soldered
   to the Matrix's pads and to its test points `TP2` (`VCC_5V`) and `TP3`
   (`GND`). This shares the regulator's full current across several contacts,
   and cuts how far the Matrix's ground, and with it the breath ADC's reference,
   moves with LED current. The allocation, the pin map and the arithmetic are in
   `hardware/carrier/carrier.md`. It was 20-way, with five positions open.
2. **Fit `U-TVS-CHAIN`.** The key-chain lines that reach the ZIF connectors
   are bare to fingers whenever the lid is off and a ribbon is unplugged. The
   array cannot be added after the board is made, and costs pennies.
   *(Amended 2026-09-27: the connectors are now through-hole 1.27 mm IDC
   headers (ADR 0017's amendment); the exposure is the same — a main-board
   header with its socket unplugged — and so is the decision.)*
3. **No fuse on the chain's 3V3 (`F-CHAIN` goes); protect at the source.**
   The chain's 3V3 comes from the Matrix's own LDO. The one fault a fuse would
   cover, a ribbon seated skewed at reassembly *(since 2026-09-27 a keyed IDC
   shroud: a socket forced or a ribbon pinched)*, happens on the bench, before
   the lid goes on, and shows at once: the short pulls down the Matrix's own
   3V3, so the instrument does not start. A series ferrite per ribbon isolates
   each key board's supply. The LDO's short-circuit limit is typical-only on
   its datasheet, so E1 shorts a ribbon's 3V3 to prove it; how, and the
   ferrite's rating, are in `hardware/interfaces/key-chain-loom/`.
4. **Wire `EN` and `IO0` to the service header.** They are not on the
   Matrix's pad rows, so two conductors of the ribbon are soldered to its
   RESET and BOOT button pads and brought to `HDR-SERVICE`. The reason for
   leaving them alone (a socketed, swappable module, ADR 0009) went with ADR
   0017. A corrupted bootloader is now recovered from the service header,
   lid off, without unplugging the Matrix (`firmware/README.md`).
5. **`DIG_GND` joins the main board's ground at `J-UMB`.** It is the SPI
   return. The three SPI lines are routed over unbroken ground from `J-MCU`
   to `J-UMB`, and the breath sense return is kept off that path. This decides
   the **instrument** end only. The register's `dig-gnd-topology` dispute is
   about the module end and stays open (`config/figures.yaml`).

## Options considered

- **Ribbon:** keep 20-way and spend the five spares on 5 V and ground. That
  leaves no conductor for `EN`/`IO0`, so they would need a second lead. Or
  keep all five as spare GPIO, which leaves one ground conductor carrying
  every LED return. Not chosen.
- **ESD:** handling care only. Relies on remembering every time, and a zap
  lands on the MCU. Not chosen.
- **3V3 fuse:** fit `F-CHAIN`. Harmless electrically, but it guards a fault
  that is visible immediately. Not chosen.
- **`EN`/`IO0`:** leave them off. Recoverable anyway with the lid off, only
  less conveniently. Not chosen.
- **`DIG_GND`:** leave it open until the module-side dispute settles. An
  unterminated return on a 2 MHz link is the worst of the three, and it
  blocks the main board's layout. Not chosen.

## Consequences

- **The tail wiring is wider.** `J-MCU` and the ribbon grow by two positions.
  The body model re-derives their placement (`config/body.yaml`
  `boards.mcu_conn_l`, `routing.mcu_ribbon_w`; `mechanical/drc.echo`).
- **Soldering to the Matrix is more than its pad rows:** two test points and
  two button pads. That is M4 work, done with the board in hand. If a test
  point cannot take a wire, its conductor moves to the matching pad.
- **E11** (breath output clean while the matrix and LEDs are exercised) is
  still the test of decisions 1 and 5.

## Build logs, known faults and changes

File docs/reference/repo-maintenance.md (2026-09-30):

# Repo maintenance — what is generated, what is a record, what may be edited

**Written 2026-09-21.** Every trap in this file cost real time at least once.

The corpus rules are in `CLAUDE.md`. This page is the layer under them: **which
files a tool owns, which files are history, and where an edit will be silently
thrown away.**

---

## §1. The four kinds of file

| Kind | Files | Rule |
|---|---|---|
| **Design corpus** | `hardware/**`, `docs/decisions/**`, `docs/reference/**`, `config/**`, `firmware/**`, `mechanical/**` (since 2026-09-26), `README.md`, `ROADMAP.md` | Must be self-consistent. This is what `check-staleness.py` checks. |
| **Historical record** | `docs/review/**`, `docs/log/**`, `docs/research/**` | **Never "corrected".** A 2026-09-21 review saying "8HP" is right as a record of what was true when written. Excluded from the checker by design. |
| **Generated** | `datasheets/MANIFEST.csv`, **`hardware/bom.csv`** | **Edits are silently destroyed.** See §3 and §4. `bom.csv` joined this row on 2026-09-21 and this table did not say so for several hours. |
| **Generated, fingerprinted** | `mechanical/cad/generated/params.scad`, `mechanical/cad/generated/module-params.scad`, `mechanical/cad/vendor/*.stl`, `mechanical/renders/*.png`, `mechanical/export/*.dxf`, `mechanical/drc.echo`, `mechanical/OUTPUTS.csv`; the module's `mechanical/module/{renders,export,art}/*`, `drc.echo`, `clash.txt`, `OUTPUTS.csv` | Built by `tools/cad.py build` (the module's `art/` and `renders/photo-*.png` through `tools/panel-art.py` and `tools/render-module.py`, ADR 0026) from `config/body.yaml`, `config/key-layout.yaml`, `config/module.yaml` and the two models (`mechanical/outputs.yaml`, `mechanical/module/outputs.yaml`). **An edit is not destroyed — it is detected**: `cad.py check` (run by `check-staleness.py`) fails on any output whose inputs moved, whose bytes no longer match the ledger, or that no spec entry builds. `mechanical/README.md`. |
| **Fragments (append-only, per author)** | `datasheets/.manifest-R*.csv` | One per research wave. **Do not edit another wave's fragment** — a `BLOCKED` row is the honest record of a gap *when it was written*. See §3 for how to close someone else's gap without touching it. |
| **SOURCE (KiCad)** | `hardware/**/<circuit>.kicad_sch` whose title block names a circuit; `hardware/boards/*/<board>.kicad_sch` + `.kicad_pro` | The source of truth for connections and part identity (ADR 0019). Edit in KiCad 9. `docs/reference/tooling.md` §3. |
| **SOURCE (layout)** | `hardware/boards/*/<board>.kicad_pcb` (+ its `.kicad_pro`, which holds the design rules), `layout.yaml` (the first layout's inputs; its `rules:` and `fab:` stay the limits the board is checked against), `hardware/lib/woody.pretty/` | Written once by `tools/pcb.py layout`, then edited in KiCad. `tools/pcb.py check` (run by `kicad.py check`): DRC with every warning a failure, schematic parity, the design settings against `layout.yaml` `rules:`/`fab:`, the silkscreen limits DRC does not test, and the body CAD's outline, thickness and part positions. `docs/reference/tooling.md` §4. |
| **Exported from the layout** | `hardware/boards/*/*.pcb-*.png`, `hardware/boards/*/fab/*`: Gerbers, the `.gbrjob`, plated and unplated drill files, KiCad's placement, and the board house's BOM, CPL and hand-assembly list | `tools/pcb.py render`. Ledgered in `hardware/SHEETS.csv` against the `.kicad_pcb` **and the sheets it was built from**, so a part-number edit on a circuit sheet makes `fab/` stale too. `kicad.py check` also fails on a file in `fab/` that no ledger row knows — a stray Gerber would be uploaded with the rest. **Never edit.** |
| **Exported from the sheets** | a migrated circuit's `netlist.yaml`; `hardware/boards/*/board-netlist.yaml`; `hardware/**/*.sch.png` and their ledger `hardware/SHEETS.csv` | `tools/kicad.py export <dir>` / `render <dir>`. **Never edit** — `kicad.py check` reports an export that no longer matches its sheet, and a render whose sheet moved or whose bytes changed. Board netlists are named so `check-netlist.py` does not count a board's parts twice. |
| **Generated once, then source** | a circuit's first `.kicad_sch` | `tools/sch.py build` writes it from the hand-written `netlist.yaml` + a `schematic.yaml` when the circuit migrates; after the export replaces the YAML, the sheet is the source and `sch.py` has no further part in it. |
| **Fragments (per circuit)** | `hardware/**/bom.csv`, `hardware/unplaced.csv` | The source the BOM is generated from. Editable — this is where a part change goes. §4. |

Not tracked, and gitignored: `.staleness/`, `.staleness-report.txt`, `*.tmp`.

---

## §2. `tools/check-staleness.py` — the mechanical half of the one failure mode

Run by a `PreToolUse` hook before every `git commit`, so forgetting it is
visible rather than silent. It greps the corpus for values `config/figures.yaml`
lists as `forbidden`, skipping lines whose wording refutes them.

### The trap: a forbidden list written from the document in front of you

**This is the mechanism behind the fourth and worst recorded instance of the
project's named failure mode**, and it is worth stating as a rule because it is
not obvious:

> When a figure moves, **grep the corpus for the OLD value first, and add one
> pattern per spelling you find.** Do not write the forbidden list from the
> document you happen to be editing.

`sensor-full-scale` moved and the list was written from its owner ADR. The
corpus spelled the same number **seven other ways** — an en dash without spaces,
a table cell with pipes, the superseded `0.2 + 0.766` with no ` V`. (That
spelling is quoted here as a refuted example, which is why the checker allows
this line and would not allow it in a design page.) Each missed by one or two
characters against a case-sensitive literal `find`. Eleven derived statements
stayed live while the checker reported **zero hits**, and two cold reviewers
found it independently hours apart.

### Other things it will not catch

- **Anything semantic.** It greps for values. It cannot see that a page still
  *depends* on a deleted part, or that an argument survives its own refutation.
  For that, run a review wave — at gates, not per commit.
- **A figure with an empty `forbidden` list.** A `disputed` entry protects
  nothing until it is settled and its old values are listed.

### Two structural holes, both found and fixed

1. **It matched line by line**, so any forbidden phrase that *wrapped* across a
   line break was invisible. It now joins lines into a single stream with a
   line map. Lines join with exactly **one** space and internal spacing is left
   alone, because several forbidden patterns are code-block spellings
   containing runs of spaces.
2. **Refutation detection is per-match context**, not per-file. A line that
   quotes an old value must carry refutation wording (`was`, `superseded`,
   `refuted`, `no longer`, …) *on that line or its neighbours*.

---

## §3. `datasheets/` — banked, not linked

`MANIFEST.csv` has one row per artefact with a SHA-256.
`tools/verify-datasheets.py` must pass before committing anything under
`datasheets/`.

### The trap: `MANIFEST.csv` is generated

**`tools/merge-manifests.py` rebuilds it from the `.manifest-R*.csv` fragments.
A direct edit to `MANIFEST.csv` survives until the next run of that tool and
then disappears without a word.** This happened in the session that wrote this
page; it was caught only by re-running the tool, not by noticing.

**To record something new about a banked document**, you have three options, in
order of preference:

1. **Fix the tooling**, if what you want is for a *check* to see something.
   That was the right answer when `verify-datasheets.py` could not tell that a
   manifest row naming a **refdes** (`"... (SW-POWER) - NKK Series M"`) is
   coverage for a BOM part whose number it cannot match. A vendor catalogue for
   a whole family, with the MPN chosen later out of it, is a case no
   part-number token can ever reach.
2. **Put it in `hardware/bom.csv`**, if it is a fact about the *part* rather
   than about the *document*.
3. **Add your own fragment** only if you actually fetched something. Two rows
   for the same file is tolerated — WS2815 has one from each of two researchers,
   both now pointing at `led/WS2815.pdf` — but it is not tidy. (It used to be
   two rows at two *paths*; the duplicate under `mechanical/` was de-duplicated
   by the 2026-09-21 re-filing and has a `deleted` row in the path map.)

### Closing someone else's `BLOCKED` row

Wave R8 established the convention, and it is in `datasheets/README.md`:

- **DECLARED** — your `OK` row quotes the blocked row's **exact `part` string**
  *and* contains the word `SUPERSEDES`. Opt-in, zero false positives.
- **LIKELY** — shared distinctive tokens, printed under `CHECK:`, never
  asserted as fact. Deliberately tuned to **refuse** `WS2812B-0807` →
  `WS2812B-2020` and the WS2815 strip → the WS2815 IC, because those are
  different dies.

### Traps when banking

- **A 200 and a `.pdf` filename prove nothing.** An RS-online URL recorded as
  the LT1641's mirror is a real PDF *of the LT4256*. A Diodes Inc URL found
  searching for a 1N4148W is the **MMST3906**. **Grep the extracted text for
  the part number, always.**
- **Text-layer coverage is per-document *and* per-element, so measure it, do
  not assume it.** One vendor sheet can carry fully extractable prose and fully
  outlined dimension callouts on the same page. Measured across all 60 banked
  PDFs, 2026-09-21:

  | Extracts | Documents |
  |---|---|
  | **Nothing at all — 0 characters** | `connectors/NE8FDP.pdf`, `connectors/NE8MC.pdf`, `connectors/PJ301M-12.pdf` |
  | **A title block and no more** | both Laird bead drawings (72 and 170 chars), `connectors/100SP1T2B3M2QEH.pdf` (157), `connectors/NE8MX.pdf` and `connectors/NE8MX6.pdf` (~400) |
  | **Everything, dimensions included** | `connectors/TE-IDC-SOCKET-CATALOG-82012.pdf` (239 kB) and `connectors/NKK-SERIES-M-TOGGLE.pdf` (49 kB). **This page listed both as textless and was wrong**: `8.89`, `8.9` and `6.5` are all in their text layers |
  | **Prose yes, drawing callouts no** | `mechanical/GATERON-KS-33-VENDOR-SPEC-DRAWING.pdf` — 11 kB of extractable spec text, and not one occurrence of `1.20` or `14.0`, the dimensions this project reads off sheets 3 and 6 |

  So **search the extracted text for the string you actually want**, not for
  "some text". The Gateron row is the one that has cost something:
  `ks33-geometry.md` recorded contact bounce as unpublished through four review
  waves, and *"Bounce Time: 5msec Max.(at 16 in/sec. actuation speed)"* was
  sitting in the extractable text of a document already in the bank.

- **The companion file is often the machine-readable one.**
  `connectors/NE8FDP.pdf` extracts zero characters. `connectors/NE8FDP.dxf`,
  banked beside it, has a full `TEXT`/`MTEXT` layer carrying every dimension
  the corpus derives from that connector. Its *geometry* entities are to
  drawing scale and rotated per view, so read the text layer, not the
  coordinates.

- **For a number that lives only in a curve, extract the content-stream
  geometry and calibrate against the gridlines.** Reading a render is the last
  resort, not the first: a reviewer's eyeball pass on the Laird bias curves was
  wrong by up to **60 %**, and the vector extraction corrected it.

- **`pdftotext` is not installed in every session, and a bare `import pypdf`
  raises a Rust panic in this container.** The system `cryptography` package's
  pyo3 binding fails to load — `ModuleNotFoundError: No module named
  '_cffi_backend'`, then `pyo3_runtime.PanicException` — and pypdf imports it
  eagerly although it needs it only for *encrypted* PDFs. Two routes, both
  verified against the bank on 2026-09-21:

  ```python
  # 1. pypdf, with the eager cryptography import stubbed out
  import sys, types
  for m in ('cryptography', 'cryptography.hazmat', 'cryptography.exceptions',
            'cryptography.hazmat.primitives', 'cryptography.hazmat.primitives.ciphers',
            'cryptography.hazmat.primitives.padding', 'cryptography.hazmat.backends'):
      sys.modules[m] = types.ModuleType(m)
  import pypdf
  ```

  ```python
  # 2. pymupdf - pip install pymupdf. Text AND rendering, and no stub needed
  import pymupdf
  doc  = pymupdf.open(path)
  text = "".join(p.get_text() for p in doc)
  pix  = doc[5].get_pixmap(dpi=150)        # for when you do have to look
  ```

  **The stub has one real limit and the bank contains a case.** Stubbing
  `cryptography` leaves pypdf unable to decrypt an AES-encrypted PDF, so
  `connectors/NKK-SERIES-M-TOGGLE.pdf` raises `DependencyError: cryptography>=3.1
  is required for AES algorithm` — on the document whose text layer carries the
  toggle dimensions. pymupdf opens the same file with an empty password and
  reads all 28 pages. **Prefer pymupdf**, and keep the stub for a session where
  pypdf is the only thing installed.

---

## §4. `hardware/bom.csv` — eleven columns, CRLF, **and generated**

```
ref,category,part,manufacturer,description,package,qty,status,source,adr,notes
```

> ### The trap: `bom.csv` is generated too, since 2026-09-21
>
> **`tools/merge-bom.py` rebuilds it from the per-circuit `bom.csv`
> fragments — `merge-bom.py --check` prints the live fragment and row count
> on every run, so no number is written here.
> A direct edit survives until the next run of that tool and then disappears
> without a word** — the same trap §3 documents for `MANIFEST.csv`, on the
> **most-cited file in this repository**.
>
> Unlike the manifest's, this one is caught: `merge-bom.py --check`
> regenerates into memory, byte-compares, and names the first differing line.
> `check-staleness.py` runs it, so the commit hook fails on a hand edit.
>
> **Edit the fragment, then re-run the tool.** A row lives with the circuit
> **whose page derives its value** — not where it is mentioned, not where it
> is mounted.
>
> **`hardware/unplaced.csv` holds the rows that no schematic page names.**
> That is not a dumping ground, it is a count: a part nobody has drawn. The
> number is `wc -l` on that file against `merge-bom.py --check`'s row total;
> this paragraph carried "50 rows of 138" until 2026-09-22, when it was 32 of
> 140, and the §4 closing note already admitted this section had gone stale
> once before. Two of its clusters name circuits this corpus has no page for — six
> identical jack-protection networks drawn three times, and nineteen
> decoupling capacitors with no home.
>
> *This section described `bom.csv` as the file you edit for several hours
> after it stopped being one. Found by a cold reviewer. It is the project's
> named failure mode, in the document that exists to record exactly this
> trap.*

- **The file is CRLF.** Python's `csv.writer` defaults to `\r\n`, but setting
  `lineterminator="\n"` rewrites every line in the file and buries a three-row
  change in a 130-row diff. **Always pass `lineterminator="\r\n"`.** Check with
  `git diff --stat` before committing: a BOM edit should touch about as many
  lines as rows you meant to change.
- **Validate column count and duplicate refdes after any edit** —
  `merge-bom.py` does both, one level up: it now catches "two circuits both
  claim this refdes", with both file:line locations named, which the old
  same-file check could not see.
- The `notes` column is append-only in practice: corrections are added after a
  ` | ` with a date, and the superseded text is left in place. That is what
  makes the checker's refutation detection work, and it is why rows are long.
- **`TBD`/`open` must say what decides them.** Two rows are deliberately
  blocked on a datasheet and say so; that is correct, not a defect.

---

## §5. `config/figures.yaml` — the register

One entry per shared quantity. The owning document states it; **every other
document cites it by name and does not restate the number.**

Changing a tracked figure is three steps, never one:

1. Update `value`.
2. Move the old value into `forbidden` — **and see §2's trap first.**
3. Run the checker. It then tells you every file to fix. Fix them in the same
   commit.

Fields in use beyond the documented ones, all optional and all free text:
`derivation`, `provenance_note`, `companion`, `false_positive_note`,
`escape_note`, `consequence`, `adaptation`, `dc_error`, `robustness`,
`toggle_row`, `floor`, `candidates`, `decided_by`. **`false_positive_note` is
the one that earns its keep** — it tells the next person why a legitimate
occurrence of a forbidden string is allowed, so they do not "fix" it.

A `disputed` entry must carry `decided_by` naming **what decides it** — a
bench measurement, a datasheet, or a choice that is the owner's. An entry that
says "somebody should look at this" is not trackable.

> **A correct figure filed as `disputed` is the dangerous kind**, because it
> stops getting re-checked. This has happened once (the OPA2197's 1 nF
> capacitive-load limit, filed as refuted on the strength of a coincidence with
> the INA828's identical headline number).

---

## §6. Running the tools

```
python3 tools/check-staleness.py      # terse; detail lands in .staleness/report.txt
python3 tools/verify-datasheets.py    # SHA-256 + BOM coverage
python3 tools/merge-manifests.py      # REGENERATES datasheets/MANIFEST.csv
python3 tools/merge-bom.py            # REGENERATES hardware/bom.csv
python3 tools/merge-bom.py --check    # ...or just prove it still matches
python3 tools/check-conservation.py <rev> <source> <dest>...   # split audit
python3 tools/audit-notes.py          # BOM notes: live content vs accumulated history
python3 tools/audit-notes.py --regrown  # ...rows that have turned back into logs
python3 tools/audit-notes.py <REF>    # ...one row, classified segment by segment
python3 tools/rewrite-paths.py        # restructure only; --apply/--verify/--invert
python3 tools/cad.py build            # body CAD: params, then every STALE render/DXF
python3 tools/cad.py check            # ...or prove every output still matches its sources
python3 tools/cad.py explain <name>   # which input moved since an output was built
```

The first four are expected to pass before a commit that touches the corpus.
The staleness hook surfaces `check-staleness.py` automatically — though note
`CLAUDE.md` §2: it runs before *every* `Bash` call rather than before `git
commit`, and it never blocks, it only tells you.

`audit-notes.py` is the odd one out: it is an ADVISORY, it changes nothing,
and it exists because the defect it looks for is one no other check can see.
A BOM notes cell that has grown back into a dated running log is not wrong
yet — it is wrong *later*, when one of the values in it moves and the
supersession segments disagree. `--regrown` is what catches it while it is
still cheap. Its threshold is HISTORY SEGMENTS, not length: the first version
also fired above 1,200 characters and flagged twelve rows that had just been
trimmed correctly, because a dense spec is long too (`U-DAC` is 1,891
characters with zero history in it). A threshold that fires on correct rows is
`CLAUDE.md` §2's own trap, and it was in the tool written to enforce the rule.

### What each one refuses to do, and why it now refuses

All three used to fail **open** — they reported success on a tree that had been
broken underneath them. All three were fixed on 2026-09-21 after the failures
were reproduced, not argued:

| Tool | Used to | Now |
|---|---|---|
| `check-staleness.py` | `os.walk` a missing `CORPUS_DIRS` entry and print `PASS`. Moving `docs/decisions/` took the corpus from 33 files to 18 and still scored green | Asserts its own inputs exist, carries a file-count floor, and **prints the corpus file count on every run** — the count is what you check, not the verdict |
| `check-staleness.py` | Define `check_refdes()` and never call it — for the tool's whole life | Asserts its own wiring: any `def check_*` with no call site is a failure. It found `check_refdes` on the first run |
| `merge-manifests.py` | Write a header-only `MANIFEST.csv` from zero fragments, exit 0, destroying 98 rows of provenance | Refuses. The fragments are **dotfiles**, so `git mv datasheets/*` leaves them behind — move the directory whole |
| `verify-datasheets.py` | Skip BOM coverage silently when `bom.csv` was absent | Refuses to print a summary it cannot stand behind |

---

## §7. The 2026-09-21 restructure

Paths changed. **`path-map-2026-09-21.csv` in this directory maps every old
path to its new one** — every tracked file has a row, including the ones that
did not move, because the question a reader actually asks is "did this path
change?" and a map of only the movers cannot answer it.

> **The as-of points, because they are not the same date and the map is
> applied at content granularity.**
>
> - **Old side** — the `old` column is exactly the tracked tree at `81c081d`,
>   the commit before A0 wrote the map. 287 paths, and it is a bijection onto
>   that tree: nothing in it is missing and nothing in it is invented.
> - **New side** — HEAD, reconciled against `git ls-files` on 2026-09-21 after
>   the pre-merge review wave closed. 410 rows: 405 tracked files, plus 4
>   `deleted` and 1 duplicate destination.
>
> **The "every tracked file has a row" sentence above was false for most of a
> day, and it is worth saying how.** The map was written at A0 and described
> Phase A1 only. Phase B then created files it had never heard of and the
> datasheet re-filing moved 22 more, which left **143 tracked files with no row
> and 22 rows whose `new` path existed on *neither* side**. A reader asking
> "did this path change?" about the TI 74HC165 sheet — filed under the retired
> `other-semi/` bucket — got `unmoved`, for a file that had moved directory
> *and* been renamed.
>
> **A map is not a document you keep true by being careful, it is one you
> assert.** The check is four lines and belongs in any future restructure's
> tooling; run it whenever files are added, because a new file is an orphan the
> moment it is committed:
>
> ```
> tracked = set(git ls-files)
> placed  = {r.new for r in rows if r.kind != "deleted"}
> assert not (tracked - placed)      # no tracked file without a row
> assert not (placed - tracked)      # no row pointing at nothing
> ```
>
> Both assertions hold as of this writing, and the second one is the half that
> caught the 22: they all pointed at `datasheets/` paths that no longer
> existed, and nothing had ever looked.
>
> **`datasheets/.moves.csv` is the authority for the datasheet rows**, not
> anyone's memory of the re-filing. It records all 22 moves with a reason each,
> and two of them **rename the file as well as the directory**: the two
> 74HC165 sheets that were `74HC165.pdf` and `74HC165-toshiba.pdf` are now
> `74HC165-ti-scls116e.pdf` and `74HC165-toshiba-1986-excerpt.pdf` under
> `logic/`. A map corrected from directory names alone gets those two wrong
> and still looks right. (Paths there are relative to `datasheets/`, the way
> `.moves.csv` and the `MANIFEST.csv` file column write them — and the way
> this paragraph has to write them, because `verify-datasheets.py` requires
> every `datasheets/…` path in the corpus to resolve on disk, which a
> deliberately retired one does not.)

**The `kind` column**, which is the part a reader acts on:

| `kind` | `old` | `new` | Means |
|---|---|---|---|
| `unmoved` | path | same path | Corpus file, path unchanged |
| `unmoved-history` | path | same path | `docs/review/**`, `docs/log/**`, `docs/research/**`. Path unchanged, and **never corrected** (§1) |
| `moved` | old path | new path | Rewritable: `rewrite-paths.py` reads exactly these rows |
| `deleted` | old path | *empty* | Gone. The `note` says where its content went, if anywhere |
| `created` | *empty* | path | Did not exist at the old-side as-of point. The `note` names the commit and, for a Phase B split, the page it was split out of |
| `created-history` | *empty* | path | Same, under `docs/review/**` — a record written after the map, never corrected |

**A `created` row's `old` is deliberately empty even when the file's text came
out of a known parent page.** `hardware/module/panel-led/panel-led.md` was
split out of `hardware/module/power-entry.md`, but power-entry has its own
`moved` row, and putting a second old→new pair on the same old path would make
`rewrite-paths.py` rewrite every reference to power-entry into a page about
the LED. The parent belongs in `note`, where a reader uses it and a tool does
not.

**References inside `docs/review/**`, `docs/log/**` and `docs/research/**`
point at the old paths and are deliberately not corrected** (§1, `CLAUDE.md`
§6). There are over eight thousand of them, and history outnumbers the corpus
roughly 24:1 on path references — so any whole-repo `sed` is wrong by that
factor. A path is a value; rewriting one inside a dated record makes that
record say something its author did not. Resolve them through the map.

`tools/rewrite-paths.py --invert --baseline <rev>` is the proof that the move
changed no content: it applies the inverse rewrite to every moved file and
requires the result byte-identical to the original. A numeric diff is the weak
form — it cannot see a permutation, a non-numeric fact, or an edit inside a
path. Byte identity under inversion can.

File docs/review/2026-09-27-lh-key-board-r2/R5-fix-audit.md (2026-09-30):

# R5 — Fix audit, `383116e..eebcdfb`

**Slice:** R5, the fix audit (wave README, "Slices").
**Revision measured:** `eebcdfb` (HEAD `36341bf` differs from it only by the
wave README `[run: git diff --stat eebcdfb HEAD]`). `tools/` not modified; the
tools were run as they stand at `eebcdfb`.
**Cold:** nothing under `docs/review/` read except this wave's README.

**Commits audited** `[run: git log --oneline 383116e..eebcdfb]`, every text diff
read with `git show` (renders, Gerbers and `.kicad_pcb` bodies skimmed by stat;
`docs/review/` skipped):

| Commit | Subject |
|---|---|
| `cd264c1` | Register becomes the SN74HCS165; key-board standoff gets its washer |
| `22f82ec` | WIP: corpus follows the SN74HCS165 and the standoff washer |
| `1040a65` | Corpus follows the SN74HCS165 and the standoff washer; the owner's fallback |
| `eebcdfb` | LH key board: every key's network identical round its switch; no acid traps; silk both sides |

## Gates, as run

| Command | Result |
|---|---|
| `python3 tools/check-staleness.py` | `PASS no live stale values \| corpus 172 files, 23 circuits, 40 figures / 274 patterns \| 6 unresolved (tracked) \| 221 restated-not-cited (advisory)`, exit 0 `[run]` |
| `python3 tools/check-netlist.py --strict` | `22 circuit(s), 193 components, 246 nets, 64 master net(s) \| 0 problem(s)`, exit 0 `[run]` |
| `python3 tools/merge-bom.py --check` | `checked 158 rows from 26 fragments \| 0 problems`, exit 0 `[run]` |
| `python3 tools/kicad.py check` | `PASS - 3 source sheet(s), 2 board(s), 39 render(s) match their sources`, exit 0 `[run]` (runs `pcb.py check`, `tools/kicad.py:528-532`) |

All four pass. Every finding below is therefore something the gates cannot see.

## Findings

### R5-1 [medium] `config/body.yaml`'s hardware comment still says the standoff's length is not a parameter and the part is "a candidate, not a choice"

- **Node:** `hardware.kb_standoff_l`, `MECH-KB-STANDOFF`.
- **Shape:** 1 (a fix that did not reach the text beside it) and 4 (a statement its own new entries refute).
- **Introduced / missed by:** `cd264c1` (added `kb_standoff_l`, status `nominal`, and made the row `selected`); `1040a65` edited the same file and missed it.
- **Evidence:** `[repo config/body.yaml:729-736]` "The standoff's length is not a parameter: it is the plate-to-board gap the switch pins set (switch.pcb_below_seat less the plate), in drc.echo … it is a candidate, not a choice - see MECH-KB-STANDOFF and ADR 0020." Directly below it, `kb_standoff_l: value: 3, status: nominal, source: "MSO4-M2-3, the owner's choice 2026-09-27"` `[repo config/body.yaml:~755]`. `MECH-KB-STANDOFF` status is `selected` `[repo hardware/unplaced.csv:25]`. The comment is unchanged from `383116e` `[run: git show 383116e:config/body.yaml | grep -n "candidate, not a choice"` → line 731]. The derivation now runs the other way: the hardware sets `switch.pcb_below_seat` (ADR 0020 point 2's amendment). `decided_by: "M4, with the standoff chosen"` on `kb_standoff_od`, `kb_standoff_edge` and `kb_standoff_inset` `[repo config/body.yaml:741, 751, 792]` reads the same way. The remaining open question is whether the part clinches, not which part it is.
- **Fix:** rewrite the comment. The standoff is MSO4-M2-3 (`kb_standoff_l`). With the washer (`kb_washer_t`) it sets `switch.pcb_below_seat`, and PEM and the plate vendor confirm that it clinches. Change the three `decided_by` entries to "M4: PEM and the plate vendor confirm MSO4-M2-3 clinches". Then run `tools/cad.py build`, because `params.scad` carries the sources.

### R5-2 [medium] ADR 0020 cites a DRC rule that `cd264c1` deleted, in the present tense

- **Node:** `mechanical/drc.echo` rule "key-board standoff stocked lengths against the window".
- **Shape:** 1 (a renamed or deleted rule, not followed to the page citing it).
- **Introduced / missed by:** `cd264c1` removed the rule `[repo git show cd264c1 -- mechanical/drc.echo: the "-" line "key-board standoff stocked lengths against the window"]` and replaced it with "key-board standoff and washer set the board depth" and "key-board depth at the hardware's tolerance limits".
- **Evidence:** `[repo docs/decisions/0020-key-boards-screw-to-the-plate.md:143-153]` "neither length lands in the window the switch pins allow: `drc.echo` "key-board standoff stocked lengths against the window" prints both and the shim that would close the gap … So the first question for the plate vendor and PEM is whether MSO4-M2-3 with a shim, or the fallback above, holds the board." `[run: grep -c "stocked lengths" mechanical/drc.echo]` → 0. `[run: rules.py]` checks every quoted rule name near "drc.echo" in the corpus against `drc.echo`. This is the only dangling one this range created. The next bullet (the owner's choice) supersedes the shim, but it never says so. A reader who follows this bullet finds no such line and no shim.
- **Fix:** mark the bullet superseded in place: "*(Superseded the same day by the washer, below; the rule it cites was replaced by "key-board standoff and washer set the board depth".)*" Keep the rule name on the same line as the correction.

### R5-3 [low] `switch.pcb_below_seat` moved 3.4 → 3.3, and three pages still derive about 0.5 mm of pin from it

- **Node:** `boards.key_board_t` source; ADR 0020 point 6; the tooling history bullet.
- **Shape:** 1.
- **Introduced / missed by:** `cd264c1` fixed `docs/reference/ks33-geometry.md:110-116` (now "a little higher than the middle, so they show a little more pin") and missed the pages that restate the same arithmetic.
- **Evidence:** `[calc]` pin below a 1.2 mm key board = 5.10 − `switch.pcb_below_seat` − 1.2 = 5.10 − 3.3 − 1.2 = **0.6 mm** (it was 0.5 at 3.4). Still stated as ~0.5 against `switch.pcb_below_seat` by name:
  - `[repo config/body.yaml:448]` `key_board_t` source: "the board top is switch.pcb_below_seat below it, so … 1.2 mm ~0.5 mm". The same text is in `mechanical/cad/generated/params.scad:106`.
  - `[repo docs/decisions/0020-key-boards-screw-to-the-plate.md:98-100]` "the board's top is `switch.pcb_below_seat` below it. … on 1.2 mm about 0.5 mm".
  - `[repo docs/reference/tooling.md:391-392]` "The key boards are now 1.2 mm, which leaves about 0.5 mm".
- The 1.6 mm / 0.1 mm statements are still right for the thumb switches at `switch.thumb_pcb_below_seat` = 3.4 `[calc: 5.10 − 3.4 − 1.6 = 0.1]`.
- **Fix:** do not restate the number. Say "at the window's middle, ~0.5 mm; the key boards sit a little higher (`switch.pcb_below_seat`) and show a little more", citing `ks33-geometry.md`, as that page now does.

### R5-4 [low] `switch.pcb_below_seat_window`'s source still says "pcb_below_seat is its middle"

- **Node:** `switch.pcb_below_seat_window`.
- **Shape:** 1.
- **Introduced / missed by:** `cd264c1`.
- **Evidence:** `[repo config/body.yaml:270]` "…some pin to solder; pcb_below_seat is its middle", which is also in `params.scad:73`. The window is [3.2, 3.6], so its middle is 3.4 `[calc]`. `switch.pcb_below_seat` is 3.3 `[repo config/body.yaml:241]`. The parameter that now sits at the middle is `switch.thumb_pcb_below_seat` `[repo config/body.yaml:235-238]`.
- **Fix:** change it to "switch.thumb_pcb_below_seat is its middle; the key boards' switch.pcb_below_seat is set by their hardware, inside it".

### R5-5 [low] ADR 0020 point 4 still says the standoff's end face is what covers the top keep-out

- **Node:** the standoff keep-out on `F.Cu` (every `H-*` hole footprint on `key-board-lh`).
- **Shape:** 1.
- **Introduced / missed by:** `cd264c1`. The echoed diameter became `max(hardware_kb_standoff_od, hardware_kb_washer_od)` = 4.5 `[repo mechanical/cad/woody_body.scad:699-701; mechanical/export/pcb-geometry.echo:7-10]`. `tooling.md:387-389` was updated in `1040a65`, and ADR 0020 was not.
- **Evidence:**
  - `[repo docs/decisions/0020-key-boards-screw-to-the-plate.md:66-71]` "On top it is covered by the standoff's end face … `tools/pcb.py` places the keep-out from the CAD's standoff diameter and screw head". The washer (OD 4.5) is what bears on the top copper now.
  - Same shape, advisory: `[repo mechanical/cad/woody_body.scad:1096]` "no parts under a screw head: the PCB keeps the same circle clear". The CAD parts envelope excludes a 3.8 circle (`max(screw_head_d 3.8, standoff_od 3.16)`), while the PCB keep-out is now 4.5 + 2 × clearance `[repo tools/pcb.py:682]`. So the circles are no longer the same. The CAD is the more permissive of the two, so a part envelope could pass CAD and fail PCB.
  - The comment at `tools/pcb.py:677` ("The standoff's end face presses on the top copper") is in frozen `tools/` and is recorded here only.
- **Fix:** in ADR 0020 point 4, write "On top it is covered by the washer (`MECH-KB-WASHER`, `hardware.kb_washer_od`)…". Make the scad envelope use the same `max(...)` as the echo, or reword its comment.

### R5-6 [low] `latency-budget.md` says the key press is "two orders of magnitude inside the scan period": it is 25×

- **Node:** `key-press-time`.
- **Shape:** 4 (a conclusion its own corrected number refutes).
- **Introduced / missed by:** `cd264c1` moved `key-press-time` 5.92 → 9.87 µs. `22f82ec` edited the very next row of the same table (`latency-budget.md:98`) and left this one.
- **Evidence:** `[repo docs/reference/latency-budget.md:96]` "Two orders of magnitude inside the scan period". `[calc]` 250 / 9.87 = 25.3×, which is 1.4 orders. The owner says "25× inside the 250 µs scan" `[repo hardware/cluster/key-switch-network/key-switch-network.md:96]`, and so does `figures.yaml` `key-press-time.note`. The sentence was already an overstatement at 42× (1.6 orders), and the move made it worse. ADR 0001's "far inside the 250 µs scan" `[repo docs/decisions/0001-mcu-and-board-partitioning.md:241]` is fine.
- **Fix:** "Far inside the scan period (the figure's `note`)". Do not restate 25×.

### R5-7 [low] The `R-KEY-SER` row still names the plain-HC thresholds `V_IL` / `V_IH`

- **Node:** `R-KEY-SER` (`hardware/cluster/key-switch-network/bom.csv:4`, master `hardware/bom.csv:37`).
- **Shape:** 1.
- **Introduced / missed by:** `22f82ec` rewrote the sibling `C-KEY` row to "the register's lower threshold (VT-, at its minimum) … upper threshold (VT+, at its maximum)" and left `R-KEY-SER`. `1040a65`'s BOM list ("C-KEY, TP-CHAIN, PCB-CLUSTER, R-CHAIN-SER, U-KEYS") does not include it.
- **Evidence:** `[repo hardware/cluster/key-switch-network/bom.csv:4]` "press crosses V_IL at key-press-time so it stays instant, and release crosses V_IH at key-release-time". Both figures are now defined against the SN74HCS165's VT− min and VT+ max `[repo config/figures.yaml:218-223, 238-243]`. The SN74HCS165 table has no `V_IH`/`V_IL` rows, only VT+, VT− and ΔVT `[datasheets/logic/SN74HCS165-ti-scls828a.pdf p.6, §6.5]`. There is no wrong number here, but the row points a reader at thresholds the fitted part does not have.
- **Fix:** use the `C-KEY` wording ("the register's lower/upper threshold, VT−/VT+, at key-press-time / key-release-time"), edit the fragment, and run `merge-bom.py`.

### R5-8 [low] The new forbidden patterns miss the CSV spellings of the retired thresholds, against the escape note written in the same commit

- **Node:** `config/figures.yaml` `key-release-time.forbidden`, `key-press-time.forbidden`.
- **Shape:** 2 (the fix's own explanation states the rule the fix breaks).
- **Introduced by:** `cd264c1`. Its new `escape_note` ends "Patterns for a retired value go in both spellings." `[repo config/figures.yaml:226-231]`.
- **Evidence** `[run: scratchpad/R5/pat.py]` (each pattern `git grep -F` at `383116e`, at `cd264c1^` and at `eebcdfb`, over the §6 corpus):
  - The crossing-time patterns are sound. `at **119.9`, `→ 119.9 µs`, `at **5.92` and `42× inside the 250` each fired at `383116e` on ADR 0001 and on `key-switch-network.md`. At `eebcdfb` they fire only in `figures.yaml` (the list itself) and in `key-switch-network/notes.md`, which the checker counts as refuted in place. `119.9us`, `5.92us` and `42x inside the 250` are CSV spellings that matched nothing at either revision (pre-emptive, harmless).
  - The threshold patterns `V_IH = 2.31 V` and `V_IL = 0.99 V` matched **only `config/figures.yaml` itself** at `383116e`, never a derived page.
  - The CSV spellings that were actually live at `383116e`, in `C-KEY` (fragment and master), are "`VIL (0.99V at 3.3V)`", "`VIH (2.31V)`" and "`above the HC165's VIL`" `[run: git grep -F "VIH (2.31V)" 383116e` → `hardware/bom.csv`, `hardware/cluster/key-switch-network/bom.csv`]. No pattern covers any of them.
  - Tested: `VIH (2.31V)`, `VIL (0.99V` and `HC165's VIL` each fire on both CSVs at `383116e` and on **nothing** at `eebcdfb` `[run]`, so adding them costs no false positive.
- The four patterns removed because they matched the new value (`at **138.7`, `crosses \`V_IH\` at **138.7`, `0.75 x VCC = 2.475`, `0.75 × VCC = 2.475`) were right to go: the owner now says "passes VT+ max at **138.7 µs**" `[repo key-switch-network.md:95]`, and `figures.yaml` says "0.75 x VCC".
- **Fix:** add `"VIH (2.31V)"`, `"VIL (0.99V"` and `"HC165's VIL"` to the two entries.

### R5-9 [low] `pcb.py check`'s new acid-trap test is missing from both lists of what `check` fails on

- **Node:** `tools/pcb.py` `check_tracks` (the "two tracks meet at < 90°" error).
- **Shape:** 3 (the list moved under the sentence enumerating it).
- **Introduced by:** `eebcdfb`. The commit message says "a new pcb.py check fails on any"; `check_tracks` is at `[repo tools/pcb.py:909-928]` and is called from `cmd_check` `[repo tools/pcb.py:~1023, "bad += check_tracks(board)"]`.
- **Evidence:** `[repo docs/reference/tooling.md:263-277]` "**`check` fails on**, every line an error:" lists DRC and parity, the design settings, silk and the body CAD, but no track-angle test. `[repo hardware/boards/key-board-lh/README.md:77-86]` "`pcb.py check` fails on any of these:" has the same omission. `eebcdfb` edited both files and updated neither list. `[run: grep -n -i "acute\|acid" docs/reference/tooling.md]` → nothing.
- **Fix:** add a bullet to both lists: "two tracks of one net meeting on one layer at under 90° (an acid trap; KiCad's DRC has no such test)".

### R5-10 [advisory] The README says `networks:`, `parts:` and `silk:` are the layout-only keys: `route_first:` is one too, and nothing checks the owner's rule afterwards

- **Node:** `hardware/boards/key-board-lh/layout.yaml` `route_first:` and `networks: pattern`.
- **Shape:** 3.
- **Introduced by:** `eebcdfb`.
- **Evidence:** `[repo hardware/boards/key-board-lh/README.md:35]` "`networks:`, `parts:` and `silk:` are read only by `pcb.py layout`". `route_first` is read by `tools/pcb_route.py:516-518`, which runs at layout only. So the owner's rule ("every key's network identical round its switch") is a layout-time property: once the `.kicad_pcb` is hand-edited (it is the source after layout, `README.md:34`), no check holds it `[repo tools/pcb.py:231, the only reader of networks]`. This belongs to R6's domain and is noted here for the ledger.
- **Fix:** add `route_first:` to the sentence. Either state that the network pattern is not re-checked after a hand edit, or add a check.

### R5-11 [advisory] Two superseded ADRs still state the 74HC165 as settled

- **Node:** `U-KEYS`.
- **Shape:** 1.
- **Missed by:** `22f82ec` / `1040a65`, whose sweep amended ADRs 0001, 0005, 0009 and 0010.
- **Evidence:** `[repo docs/decisions/0013-two-mcu-split.md:263]` "It is settled the other way: **one 74HC165 per cluster**". `[repo docs/decisions/0008-display-selection.md:109]` "The 74HC165 chain reads all 18 switches". Both ADRs carry **Status: Superseded** by ADR 0015 (line 3), so neither is a live instruction. ADR 0001's amendment covers only its own text ("The wording "74HC165" that remains above records the reasoning at the time", `0001:408`).
- **Fix:** none required. Optionally, write "74x165", as ADR 0005 now does.

### R5-12 [advisory] The owner's new standoff fallback did not reach `MECH-KB-SCREW`

- **Node:** `MECH-KB-SCREW` (`hardware/unplaced.csv:27`, `hardware/bom.csv:152`).
- **Shape:** 1.
- **Introduced by:** `1040a65`, which added the fallback to ADR 0020 (`:174-181`) and to `MECH-KB-STANDOFF`.
- **Evidence:** The fallback runs a screw up through the board, the washer, a spacer and a clearance hole in the plate into a nut on the plate's top face `[repo docs/decisions/0020-key-boards-screw-to-the-plate.md:174-181]`. That needs roughly 1.2 + 0.3 + 1.8 + 1.2 + a nut `[calc; the spacer is 2.1 − 0.3 per the ADR's "spacer plus washer replaces the standoff's reach"; M2 nut height ~1.6 from memory]`, about 6 mm. The row fixes "M2 x 4" and says a longer screw "stands above the plate's top face into the oak", which is exactly what the fallback designs for (the pocket in the oak). No nut row exists. It is correct for the chosen part and silent on the fallback.
- **Fix:** add one clause to `MECH-KB-SCREW`: "with ADR 0020's fallback, longer — through the plate into a nut in the oak's pocket; sized when the fallback is taken".

### R5-13 [advisory] The retired derivation in `key-switch-network/notes.md` is announced as "verbatim" but carries inserted markers

- **Node:** `key-release-time`, `key-press-time` (history).
- **Shape:** 2 (the fix's own framing is not true of the text it frames).
- **Introduced by:** `cd264c1`.
- **Evidence:** `[repo hardware/cluster/key-switch-network/notes.md:43]` "What the page said until then, verbatim:". Lines 79, 109, 138 and 139 contain "(retired, 74HC165)", which is not in the source text `[run: git show cd264c1^:hardware/cluster/key-switch-network/key-switch-network.md]`. The markers are what let `check-staleness.py` exempt table rows under rule 2b's same-line requirement. They are useful, but they make "verbatim" false. Relatedly, `[repo hardware/cluster/key-register/notes.md:23-24]` "thresholds against onsemi's published 3.0 V row — see §Derivations": §Derivations now derives the SN74HCS165's thresholds, and the onsemi table is in `key-switch-network/notes.md`.
- **Fix:** write "verbatim, with each retired figure marked (retired, 74HC165)". Point `key-register/notes.md`'s "see §Derivations" at `key-switch-network/notes.md`.

### R5-14 [advisory] ADR 0001's history quote says `C-KEY` "now carries these figures"

- **Node:** `C-KEY`, `key-release-time`, `key-press-time`.
- **Shape:** 1.
- **Missed by:** `cd264c1`, which replaced the table's figures with citations.
- **Evidence:** `[repo docs/decisions/0001-mcu-and-board-partitioning.md:245-251]` "`bom.csv` row `C-KEY` carried the stale the superseded "~1.4 us / 176x" pair until this edit and now carries these figures". The table above it now carries only figure names (`0001:240-241`). `C-KEY` deliberately does not restate the figures ("The thresholds are those figures' threshold_note, not restated here", `hardware/cluster/key-switch-network/bom.csv:5`). The sentence is also garbled ("the stale the superseded").
- **Fix:** "…until this edit, and now cites `key-release-time` / `key-press-time`."

### R5-15 [advisory] The test pads' stated order and the register's pins disagree for SER/QH

- **Node:** `TP-SER-LH`, `TP-QH-LH`, `U-KEYS-LH` pins 9 and 10.
- **Shape:** 2.
- **Introduced by:** `eebcdfb`.
- **Evidence:** `[repo hardware/boards/key-board-lh/layout.yaml:79-82]` "in the order of the register's own pins above them - SER and QH by pins 10 and 9 … so no chain net crosses another's pad". `[run: pcbnew.LoadBoard, pad positions, PCB mm]`: U-KEYS-LH pin 9 (`/HOP_LH_LT`, QH) is at x 146.06 and pin 10 (`/CHAIN_SER_LH`) at x 147.32, but TP-SER-LH is at x 143.0, left of TP-QH-LH at x 146.5. Along x, the SER/QH pads are therefore in the reverse order of their pins. The rest runs left to right: GND pin 8 at 146.06 → pad 150.0; SCK pin 2 at 153.68 → pad 153.5; SH/LD pin 1 at 154.94 → pad 157.0; 3V3 pin 16 at 154.94 → pad 160.5. `pcb.py check` passes, so nothing is shorted or unrouted. The claim is about ordering, and whether the crossing matters is R3's call.
- **Fix:** R3 to judge. Either swap TP-SER/TP-QH or reword the comment and the README's "in the register's pin order" (`README.md:251`).

### R5-16 [advisory] The dated `unplaced.csv` count table in `pcb-pipeline.md` moved again

- **Node:** `hardware/unplaced.csv`.
- **Shape:** 3.
- **Moved by:** `cd264c1` (added `MECH-KB-WASHER`, qty 8).
- **Evidence:** `[repo docs/reference/pcb-pipeline.md:149-155]` says "Re-measured against the current tree, 2026-09-21: … `unplaced.csv` … **34** rows, **75** units". `[run: csv count]` gives 32 rows / 78 units at `383116e` and 33 / 86 at `eebcdfb`. The table is dated and was already off before this range, so this is not a regression of it. It is recorded because the washer moved it and a reader may take it as current.
- **Fix:** replace the table with "`wc -l hardware/unplaced.csv` is the count", as `hardware/README.md:183` already does.

## Checked and found consistent

- **The part switch, part name.** `[run: grep -rn 74HC165 over the §6 corpus, excluding "HCS"]` Every remaining hit is one of the following:
  - history in `notes.md` files;
  - ADR 0001 text covered by its amendment (`0001:408`);
  - the explicit "not a plain 74HC165" warnings (`README.md:165`, `key-register.md:73,80`, `key-switch-network.md:88`);
  - the KiCad library symbol id `74xx:74HC165` and its cached `Value` (`key-register.kicad_sch:19,28`). The instance `Value` is `74HCS165`, the MPN `SN74HCS165DR` and the LCSC `C2864745` (`:394, 402-403`);
  - the path map, and R5-11.

  The old LCSC `C5613` and MPN `SN74HC165` appear nowhere live `[run]`. `U-KEYS` (fragment and master), `board-netlist.yaml` (both boards), the `fab/…bom-jlc.csv`, `nets.yaml`, `spi-link.md`, the `key-chain-loom.md` drawing, `cluster-boards.md`, `key-layout.yaml`, `allocation.yaml`, ROADMAP E4 and ADRs 0005 and 0010 all follow.
- **Timing figures.**
  - `[calc]` release: 103.40 × ln(3.1565/0.825) = 138.7 µs. Press: 4.4957 × ln(3.1565/0.3515) = 9.87 µs. 10 kΩ trade: 470 × ln(3.267/0.825) = 646.9 µs ≈ 647. Interpolations 2.358 V → 125.0 µs and 0.612 V → 8.58 µs. The "about 4.5 µs" 0 V-start error: 103.4 × ln(3.3/0.825) − 138.7 = 4.6.
  - Thresholds: TI VT+ max 1.5/3.15/4.2 and VT− min 0.3/0.9/1.2 at 2/4.5/6 V; ΔVT min 0.2/0.4/0.6; VT− max ≤ 0.5 × VCC in every row (1.0/2 = 0.50, 2.2/4.5 = 0.49, 3.0/6 = 0.50) `[datasheets/logic/SN74HCS165-ti-scls828a.pdf p.6]`, so ADR 0001's and `C-KEY`'s "1.94 V clears 1.65 V by about 0.3 V" holds.
  - Nexperia 74HCS165 at 3.0–3.6 V: VT+ max 0.7 VCC, VT− min 0.2 VCC, both inside the bound `[datasheets/logic/74HCS165-nexperia.pdf p.6]`.
  - CLK→QH 18 ns max at 4.5 V and 45 at 2 V `[same TI, p.7]`, matching `spi-link.md`. tt 5/8 ns at 4.5 V `[p.8]`, stated the same way in ADR 0001, `key-register.md`, `key-chain-loom.md` and `U-KEYS`.
  - "just over half a scan": 138.7/250 = 0.55 `[calc]`, in ADR 0001, `key-switch-network.md` and `figures.yaml role_note`. No "under half a scan" survives `[run: grep]`.
- **Every citation of `key-release-time` / `key-press-time`** in the corpus `[run: grep]` cites by name. Only the owner restates them (`key-switch-network.md:95-96`). Apart from R5-6 and R5-7, all wording is correct.
- **The standoff and depth.**
  - `[calc]` 3 + 0.3 = 3.3 = `switch.pcb_below_seat`. Limits 3 − 0.08 + 0.25 = 3.17 and 3 + 0.05 + 0.35 = 3.40, against [3.2, 3.6], which matches `drc.echo` "key-board depth at the hardware's tolerance limits" and ADR 0020's "a few hundredths". Standoff below the plate 3 − 1.2 = 1.8, plus the washer 0.3 = 2.1 = "key-board standoff length (derived)".
  - M2 × 4 against the THROUGH limit 1.2 + 2.1 + 1.2 = 4.5, leaving 2.5 engaged `[calc]`.
  - The drc.echo shifts follow from the board rising 0.1: parts room 14.1 → 14.2, gap 17.4 → 17.5, pin tails 1.25 → 1.15, fold 2.725 → 2.775, ribbon 104.27 → 104.37.
  - None of the retired values (14.1, 17.4, 1.25, 2.725, 104.27, 2.2 standoff, "0.2 to 0.6" shim) is restated anywhere in the corpus `[run: grep]`.
  - The FFSD code stays 4.48, consistent with `chain_order_in` = ceil((104.37 + 2t + 3.175)/25.4 × 100)/100 `[repo mechanical/cad/woody_body.scad:929]`.
  - "tbd parameters in play" stays 92: one removed (`kb_standoff_stock_l`) and one added (`thumb_pcb_below_seat`) `[repo drc.echo:2 diff]`.
  - `clash.txt`: 132 → 140 solids (+8 washers), still 100 allowed, no count restated elsewhere `[run: grep]`.
  - ADR 0017's "not at its worst case" (13.1 fits and 14.6 does not, against 14.2) still holds.
  - `switch.thumb_pcb_below_seat` is used for the thumb board in `woody_body.scad:788` and is cited correctly in `cluster-boards.md:121`, `DESIGN.md:46` and ADR 0020.
- **The fallback.** ADR 0020's old self-clinching-nut fallback (`:139-141`) is refuted in place by "This replaces the self-clinching-nut fallback above" (`:181`). `MECH-KB-STANDOFF` carries the new one. The README's *Open* row and `cluster-boards.md` Still-open both say "ADR 0020's fallback".
- **Test pads.** "six" and the six names agree in the `TP-CHAIN` row (fragment and master), the README (`:113, :203, :233, :251`) and `layout.yaml`. No live "five".
- **Drill files.** The README (`:45`), `tooling.md` (`:284`) and `SHEETS.csv` name `key-board-lh-PTH.drl` / `-NPTH.drl`, which match `fab/` `[run: ls]`. The tools present match the README's description: PTH 0.3/0.7/1.3, NPTH 2.2/5.25. `fab/` holds 16 files, as the README's list describes `[run: ls]`.
- **Network pattern and silk.** `tooling.md:243, 247`, the README (`:103-108, :220-243`) and `layout.yaml` describe the same `pattern`/`except`/`add_top_silk`/`top_at`. No old per-key wording ("above its switch", "one entry per key") survives `[run: grep]`.
- **ESD.** No live "over 2000 V" / 74HC165 HBM remains. `cluster-boards.md:243` and `key-chain-loom.md:365` cite ±4000 V HBM / ±1500 V CDM from TI p.4.
- **Retired figure fields.** No page still cites the removed `conservative_bound` `[run: grep]`.

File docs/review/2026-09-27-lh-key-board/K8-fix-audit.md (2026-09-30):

# K8 — Audit of today's fixes (2026-09-27), for the four recorded shapes

**Slice:** K8. **Revision:** `d46a3b0`. **Cold:** nothing under `docs/review/`
read except this wave's README. **Tools:** run, not changed; the tree was
left as found except for this file.

**Scope.** The 14 commits of 2026-09-27 (`34f17f2` … `d46a3b0`), weighted on
the seven that touch the key boards and the chain: `12d447d` (first PCB),
`5595f1a` (standoffs, ADR 0020), `f3fedff` (1.2 mm, corner standoffs),
`9d3dde1` (Samtec catalogue pages), `c696b34` + `27a3476` (flat flex/ZIF →
through-hole IDC, pin map 12−n/14−n), `d46a3b0` (full prints, −RN2, 13−n,
header dimensions, JLC rules, test pads, part numbers, board README).
Corpus per CLAUDE.md §6.

## Summary

Today's headline fixes landed cleanly. **The pin map is right everywhere**:
every live statement of the key-board J-CHAIN pinout says 13 − n (11 SCK,
9 SH/LD, 7 SER, 5 QH, 3 3V3, even pins ground), the two board netlists
agree, and the old 12 − n/14 − n map survives only in `notes.md` as dated
history. **The old header numbers (5.85, 7.1, 2.44) are gone** from every
prose and data file; the only hits are PCB/DXF coordinates. ZIF, FFC,
`ffc_conn_*`, 200528 and "tilt" survive only in dated, refuted-in-place prose.
`check-staleness`, `merge-bom --check` and `check-netlist --strict` pass.

What did not land is at the edges, and it has the recorded shapes:

- **Shape 4 (the serious one): ADR 0017's argument for IDC now cites a
  derivation that no longer derives the gap.** The fix deleted the old
  "17.4 mm gap" number — which was, and still is, the right gap — and left
  a `[calc]` recipe (twice the fold radius plus `boards.chain_hdr_h`) that
  was only true of the retired hairpin. Followed today it gives 15.5 mm
  (K8-1).
- **Shape 1:** the placement fix (corners, grown board) did not reach
  `config/body.yaml`'s own comment block or ADR 0020's point 5, which still
  say "between each pair of neighbouring switches", "the board stayed the
  same size", and "J-CHAIN at the board's end" (K8-2, K8-3). The 1.2 mm fix
  did not reach `switch.pcb_t`'s source line, which cites PCB-CLUSTER as
  1.6 mm and is marked `settled` although ADR 0020 says the main board's
  thickness is still to be decided (K8-4). The full-print fix did not reach
  `hardware/lib/README.md`'s "From" column (K8-6).
- **Shape 3:** tooling.md's "the four [3D models] this board needs" was
  counted when the Molex ZIF was on the board; it is three now (K8-5).
  `repo-maintenance.md` still says `fab/` is Gerbers/drill/placement
  ledgered against the `.kicad_pcb` alone; since `d46a3b0` it also holds the
  JLC BOM/CPL/hand list and every file is ledgered against the sheets too
  (K8-7).
- **Shape 2:** three ADR lines edited today to add "1.27 mm IDC since
  2026-09-27" still say the Matrix ribbon is **20-way** (24-way since ADR
  0018) — a fix line that restates a wrong value (K8-8).
- **Register (rule 2):** no forbidden pattern was added for any value
  retired today. The key-board pin map changed twice in one day and is
  restated in ten files with no register entry (K8-9).

No finding is high: nothing orders a wrong part or nets a wrong pin.

## Findings

### K8-1 [medium] ADR 0017's "why IDC was rejected" rebuttal cites a gap derivation that the hairpin fix broke; followed today it computes 15.5 mm, not the real 17.4 mm

**Node:** ADR 0017 amendment, *"Why the old reason against IDC no longer
holds"*; `drc.echo` "key-chain ribbon closed: hairpin leg and fold radius";
`boards.chain_hdr_h`.

- The paragraph says a 2.54 mm IDC stack of 13.1 mm (14.6 mm worst case) sits
  "in the gap between the boards `[calc: twice the fold radius in drc.echo
  "key-chain ribbon closed…" plus boards.chain_hdr_h]`, with parts on both
  boards, and fits nowhere" `[repo docs/decisions/0017-one-main-board.md:152-158]`.
- At `27a3476` the model's fold was `chain_r = (chain_zk - chain_zm) / 2`
  with both plug centres at `chain_hdr_h / 2` off their boards
  `[run: git show 27a3476:mechanical/cad/woody_body.scad, lines 857-859]`,
  so gap = 2r + `chain_hdr_h` = 2 × 5.775 + 5.85 = 17.4 `[calc; old
  drc.echo line 51: 5.775]`, and the ADR said "a 17.4 mm gap".
- `d46a3b0` moved the legs (main-board leg on the board, key-board leg under
  its socket): `chain_r = (chain_z_up - chain_z_low) / 2` with
  `chain_z_low = cb_top + chain_thumb_stub + ribbon_t/2` and
  `chain_z_up = chain_zk - plug_t/2 - 1.5` `[repo mechanical/cad/woody_body.scad:857-873]`.
  The recipe now gives 2 × 4.9375 + 5.59 = **15.47 mm**
  `[calc; drc.echo:51, body.yaml chain_hdr_h 5.59]`.
- The real gap did not change: `top_z − cb_top` = stub 1.05 + ribbon_t/2 0.4
  + 2r 9.875 + plug_t/2 1.525 + 1.5 + mouth_z 3.05 = **17.40 mm**
  `[calc from woody_body.scad:857-873; stub = 5.75 − (3.4 + 1.6) + 0.3 = 1.05]`.
- The same commit deleted "17.4 mm" from the sentence
  `[run: git show d46a3b0 -- docs/decisions/0017-one-main-board.md]`, so the
  one correct number was removed and the stale recipe kept. A reader who
  follows the recipe gets 15.5 mm, in which the 14.6 mm worst-case stack
  looks close to fitting, and "fits nowhere" then rests only on "with parts
  on both boards". The conclusion is weakened by its own citation.

**Fix:** state the gap by name, not by a formula about the ribbon. Either cite
a `drc.echo` line for the board-to-board gap (the model has `top_z` and
`cb_top`; a NOTE line such as "key board underside to main board top" costs
one `echo`), or cite "main board parts room under the key boards"
(`drc.echo:41`, 14.1 mm), which is the quantity the argument is really about.
Then check whether "fits nowhere" still holds against it.

### K8-2 [medium] `config/body.yaml`'s comment on the key-board standoffs still describes the retired placement ("between each pair of neighbouring switches")

**Node:** `config/body.yaml` `hardware.kb_standoff_*` block comment.

- The comment reads "an M2 self-clinching standoff pressed into the plate
  between each pair of neighbouring switches" `[repo config/body.yaml:714-716]`.
- That was `5595f1a`'s placement. `f3fedff` replaced it with one standoff
  per corner (ADR 0020 amendment), and the model says so:
  `drc.echo` "key-board standoffs" [4, 4] "one in each corner"
  `[repo mechanical/drc.echo:56]`; `pcb-geometry.echo` puts the LH ones at
  x = 40.5 and 117.5, both outside the switch row 50–108
  `[repo mechanical/export/pcb-geometry.echo]`.
- `f3fedff` added `kb_standoff_inset` with its corner rule to the same
  block `[repo config/body.yaml:743-747]` without changing the comment
  above it. This is a `.yaml`, where rule 2b allows no history.

**Fix:** "one M2 self-clinching standoff pressed into the plate at each
corner of the board (ADR 0020, amended), and an M2 screw up through the board
into it."

### K8-3 [medium] ADR 0020 point 5 still says the board "stayed the same size" and that J-CHAIN "sits at the board's end"; the amendment note in the same point corrects neither

**Node:** ADR 0020 decision point 5; J-CHAIN position (`pcb-geometry.echo`
"chain").

- Point 5's bullets: "`J-CHAIN` sits at the board's end with its cable
  entry facing the ribbon's fold" and "The board stayed the same size (the
  owner's choice over enlarging it)" `[repo docs/decisions/0020-key-boards-screw-to-the-plate.md:61-64]`.
- The same ADR's amendment grew the board: "if we need to increase the size
  of the board a little bit that would make sense" `[repo …0020…:93-94]`,
  and point 3 now makes it "a rectangle across the cavity" `[repo …0020…:36-38]`.
- J-CHAIN is mid-board: LH chain at x = 79, between LH2 (70) and LH3 (90),
  on a board spanning 37–121 (standoffs at 40.5/117.5, inset 3.5)
  `[repo mechanical/export/pcb-geometry.echo; calc 40.5 − 3.5, 117.5 + 3.5]`.
- The amendment note under point 5 `[repo …0020…:66-75]` covers the envelope
  and the rule name only.

**Fix:** extend point 5's dated note: "The board was grown in the amendment
(point 3), and `J-CHAIN` now sits between the switches where the model finds
room (`drc.echo` 'chain headers on the left_hand boards clear of the
switches')." Or strike the two bullets. They are prose, so the note may sit
beside them.

### K8-4 [low] `switch.pcb_t` still cites PCB-CLUSTER as 1.6 mm and is marked `settled`, although the key boards are 1.2 mm and ADR 0020 leaves the main board's thickness open

**Node:** `config/body.yaml` `switch.pcb_t` (1.6); PCB-CLUSTER; PCB-CARRIER.

- The source is "[adr] hardware/bom.csv PCB-CLUSTER and PCB-CARRIER,
  1.6 mm", status `settled` `[repo config/body.yaml:257-260]`.
- PCB-CLUSTER is "1.2mm (config/body.yaml boards.key_board_t)" since
  `f3fedff` `[repo hardware/cluster/bom.csv:4]`.
- ADR 0020 point 6: "The main board's thumb switches have the same
  arithmetic, and it is decided when the main board is laid out"
  `[repo docs/decisions/0020-…:84-85]`. That arithmetic gives
  5.10 − 3.4 − 1.6 = 0.1 mm of pin to solder on the main board
  `[calc, body.yaml:432 and 236]`, the same margin ADR 0020 rejected for the
  key boards. `settled` contradicts "decided when laid out" (shape 4).

**Fix:** source "hardware/carrier/bom.csv PCB-CARRIER, 1.6 mm (the key boards
are boards.key_board_t)", status `tbd`, decided_by "the main board's layout —
ADR 0020 point 6: 1.6 mm leaves ~0.1 mm of thumb-switch pin". The comment in
`woody_body.scad:781` needs no change.

### K8-5 [low] tooling.md counts "the four [3D models] this board needs"; since J-CHAIN became the model-less Samtec footprint it is three

**Node:** `docs/reference/tooling.md` §4 *Learned the hard way*, 3D models.

- The text says "the four this board needs came from … kicad-packages3D"
  `[repo docs/reference/tooling.md:295-296]`, written in `12d447d`
  `[run: git log -S'the four this board needs']`.
- At `12d447d` the board referenced four library models: C_0805, R_0805,
  SOIC-16 and `Molex_200528-0120…step` `[run: git show 12d447d:…kicad_pcb | grep model]`.
- At `d46a3b0` it references three library models (C_0805, R_0805, SOIC-16).
  The fifth model is the Gateron STEP from `datasheets/` `[run: grep '(model'
  hardware/boards/key-board-lh/key-board-lh.kicad_pcb]`. The next sentence
  of the same bullet says J-CHAIN "has no 3D model", which is the fix that
  moved the count.

**Fix:** "the three this board needs (0805 R and C, SOIC-16)", or drop the
number and name them.

### K8-6 [low] `hardware/lib/README.md` still says the J-CHAIN footprint's shroud comes from the catalogue page; the footprint and the Changed column say the full print

**Node:** `woody.pretty/IDC-Header_2x06_P1.27mm_Samtec_SHF_Horizontal`,
"From" column.

- From: "the shroud from Samtec's banked catalogue page
  (`datasheets/connectors/SAMTEC-SHF-1.27MM-SHROUDED-IDC-HEADER.pdf`)";
  Changed (same row): "…the full print, `SAMTEC-SHF-1XX-01-X-D-XX-PRINT.pdf`,
  sheet 2 section C-C" `[repo hardware/lib/README.md:9]`.
- The footprint's own `descr` was moved to the full print in `d46a3b0`
  `[run: git show d46a3b0 -- hardware/lib/woody.pretty/IDC-…kicad_mod]`.
- Related, and advisory: three `boards.chain_*` sources still cite the
  catalogue pages (`chain_hdr_l`, `chain_plug_t`, `chain_plug_l`)
  `[repo config/body.yaml:345, 380, 385]`. Four `decided_by` fields still
  say "with the full print" / "and its full print" although the print is
  banked and the values are now `nominal` from it `[repo config/body.yaml:346, 351, 356, 361]`.
  The catalogue values agree with the print (13.97 = 6 × 1.27 + 6.35 on
  both; the print's `(No OF POS x .050[1.27]) + .250[6.35] REF` `[run: pdftotext SHF print]`),
  so no number is wrong. Only the provenance and the open-item text are stale.

**Fix:** point the From column at the full print. Move the three sources to
the prints and rewrite the four `decided_by` as what is actually still open
(the part number and source, M4).

### K8-7 [low] `repo-maintenance.md` describes `fab/` as Gerbers, drill and placement, ledgered against the `.kicad_pcb`; since `d46a3b0` it also holds the JLC BOM, CPL and hand list, and every file is ledgered against the sheets too

**Node:** `docs/reference/repo-maintenance.md` §1 table, "Exported from the
layout".

- It says "`hardware/boards/*/fab/*` (Gerbers, drill, placement) …
  Ledgered in `hardware/SHEETS.csv` against the `.kicad_pcb`"
  `[repo docs/reference/repo-maintenance.md:22]`. Last touched in `12d447d`
  `[run: git log -3 -- docs/reference/repo-maintenance.md]`.
- `fab/` now holds 15 files, three of them the JLC BOM, CPL and hand-assembly
  list. Every ledger row lists `key-board-lh.kicad_sch@…` and the circuit
  sheets as inputs as well as the `.kicad_pcb`
  `[run: ls fab; grep bom-jlc hardware/SHEETS.csv]`. So a part-number edit on a
  circuit sheet makes `fab/` stale, and this page, the one CLAUDE.md says to
  read before touching generated files, does not say so. The board README
  and tooling.md §4 do say it `[repo hardware/boards/key-board-lh/README.md:27; docs/reference/tooling.md:246]`.

**Fix:** "(Gerbers, drill, placement, and the board house's BOM/CPL/hand
list) … ledgered against the `.kicad_pcb` and the sheets it was built from".

### K8-8 [low] Three ADR lines edited today to date the IDC change still call the Matrix ribbon 20-way (24-way since ADR 0018)

**Node:** `CBL-MCU-RIBBON` / `J-MCU` width; ADR 0018 decision 1.

- ADR 0009: "The key boards are on flat flex *(1.27 mm IDC since
  2026-09-27…)* and the Matrix on a 20-way ribbon; how its spare positions
  are used is open on `CBL-MCU-RIBBON`" `[repo docs/decisions/0009-enclosure-construction.md:643-645]`.
- ADR 0013: "…*(1.27 mm IDC ribbons since ADR 0017's 2026-09-27
  amendment)*; the Matrix is on the lid on a 20-way ribbon into `J-MCU`"
  `[repo docs/decisions/0013-two-mcu-split.md:244]`.
- ADR 0001's fenced drawing: "the Matrix is on the lid, 20-way ribbon to
  J-MCU" `[repo docs/decisions/0001-mcu-and-board-partitioning.md:82]`, in
  the block whose next lines `27a3476` edited.
- ADR 0018 decided "The Matrix ribbon is 24-way … It was 20-way"
  `[repo docs/decisions/0018-main-board-wiring-decisions.md:20-31]`, and
  ADR 0017 cites it correctly `[repo docs/decisions/0017-…:59-60]`. ADR 0009's
  "spare positions … open" is also answered by ADR 0018 (the spares became
  5 V and ground).
- `27a3476` edited the ADR 0009 and 0013 lines in place
  `[run: git show 27a3476 -- docs/decisions/0009… 0013…]`. The fix landed on
  the line that carries a stale value and did not touch it. No figure tracks
  the ribbon width, so the checker cannot see it.

**Fix:** "a 24-way ribbon (ADR 0018)" in all three, and drop "open" in 0009.
Consider a figure `mcu-ribbon-ways` (owner `carrier.md`) with forbidden
`20-way ribbon`. ADR 0018:31 and :61 narrate the change and need a
`false_positive_note`.

### K8-9 [medium] No forbidden pattern was added for any value retired today; the key-board pin map changed twice in a day and is restated in ten files with no register entry

**Node:** `config/figures.yaml`; the key-board J-CHAIN pin map
(`key-chain-loom.md` owns it).

- `figures.yaml` was touched once today, to reword two derivations
  `[run: git show 27a3476 -- config/figures.yaml]`. Its 38 figures include
  no pin map, header dimension, board thickness or connector part
  `[run: python3 over config/figures.yaml]`.
- The live 13 − n map is written out, not cited, in `key-chain-loom.md`
  (several places), `bom.csv` J-CHAIN/CBL-CHAIN/R-SER-TERM, `nets.yaml`
  (4 nets), `cluster-boards.md:33`, `key-register.md:21-26`,
  `key-switch-network.md:21,38`, the board README:106 and ADR 0017:163
  `[run: grep 'key-board[^.]{0,40}pins? [0-9]' over the corpus]`. All are right
  today. That is exactly the "restated, not cited" state that rule 1 says
  every past staleness defect grew from, and this fact has already moved
  twice.
- Grep-first counts for the retired spellings, corpus only
  (table below): `12 − k`/`14 − k`/"key-board pin 8" have **1 hit each, all
  in `notes.md`, as dated history**. `12-n`, `14-n`, `12 − n`, `14 − n`,
  `12-k`, `14-k`, "key-board pin 4", "pins 8 and 6", "12 SCK" have 0 hits.
  So patterns can be added now at almost no false-positive cost.

**Fix (rule 2's steps, in the spelling of each file):** add a figure
`key-board-chain-pinmap`, value "key-board pin = 13 − main-board pin (−RN2
cable)", owner `hardware/interfaces/key-chain-loom/key-chain-loom.md`, with
forbidden:
`12 − n`, `14 − n`, `12 − k`, `14 − k` (prose, U+2212),
`12-n`, `14-n`, `12-k`, `14-k` (CSV/YAML spelling),
`key-board pin 8`, `key-board pin 4`, `key-board J-CHAIN pin 8`,
`12 SCK, 10 SH/LD`, `pins 8 and 6`, and a `false_positive_note` for
`notes.md`'s dated paragraph. Add a `J-CHAIN`-part figure (or patterns on
`chain-connectors`) forbidding `ffc_conn`, `FFC-CHAIN` and `200528` outside
prose. Current hits are ADR 0017/0020, tooling.md and notes.md, all prose
with refutation wording; confirm each is exempted before committing. Do
**not** add bare `5.85`, `7.1` or `2.44`: they hit only coordinates in
`.kicad_pcb`/`.dxf`, and would fire on correct geometry.

### K8-10 [low] The JLC via rule is explained with the PTH ring figure, and `layout.yaml` still gives JLC's track/space from memory beside the banked page that contradicts it

**Node:** `layout.yaml` `rules.via` 0.7 and `fab.annular_min` 0.18;
tooling.md "Put the board house's limits in the DRC".

- tooling.md: "Adding JLC's 0.18 mm minimum ring caught the vias (0.6 on a
  0.3 drill = 0.15) and the header's pads … both grew"
  `[repo docs/reference/tooling.md:311-313]`. `layout.yaml` says the same:
  "0.2 ring on the 0.3 drill: JLC's 0.18 minimum" `[repo hardware/boards/key-board-lh/layout.yaml:19]`.
- The banked page gives 0.18 as the **PTH annular ring** absolute minimum
  (2-layer, 1 oz; 0.25 recommended). For **vias** it says only "Via
  diameter should be 0.1mm (0.15mm preferred) larger than Via hole size",
  with a 2-layer minimum of 0.15 hole / 0.25 diameter
  `[datasheets/fab/JLCPCB-PCB-CAPABILITIES.pdf, run: pdftotext, "Vias" and "PTH annular ring" rows]`.
  A 0.6/0.3 via met JLC's via rule. It failed KiCad's single annular-width
  constraint, which applies to vias too. Growing the vias costs nothing and is
  safe, but the stated reason puts a board-house rule on the page that the
  banked page does not state (shape 2).
- `layout.yaml`: "JLCPCB's standard 2-layer process allows 0.127 mm track and
  space [from memory]" `[repo hardware/boards/key-board-lh/layout.yaml:13-14]`;
  the page banked the same day gives 0.10/0.10 mm for 1 oz
  `[datasheets/fab/JLCPCB-PCB-CAPABILITIES.pdf, "Min. track width and spacing (1 oz)"]`.
  CLAUDE.md rule 3: the banked number wins.

**Fix:** tooling.md: "KiCad applies one minimum annular width to pads and
vias; set to JLC's 0.18 PTH minimum, it grew both". `layout.yaml`: cite the
banked 0.10/0.10 and drop `[from memory]`. Also consider citing the banked
page's thickness list (0.4…1.2…2.0) for `boards.key_board_t`, whose "1.2 mm
is a standard thickness at every board house" is still `[from memory]`
`[repo config/body.yaml:432; docs/decisions/0020-…:81]`.

### K8-11 [advisory] `boards.chain_plug_proud` (1.4) is "scaled" off prints that say DO NOT SCALE DRAWING

**Node:** `config/body.yaml` `boards.chain_plug_proud`, which sets the
hairpin's x extent, the footprint courtyard (9.51) and `chain_span`.

- Source: "its 5.08 height less the header's mouth-to-floor, about 3.67,
  which the print does not dimension (scaled)" `[repo config/body.yaml:362-366]`.
- Both banked prints carry "DO NOT SCALE DRAWING" in the title block
  `[run: pdftotext SAMTEC-SHF-1XX-01-X-D-XX-PRINT.pdf, lines 82, 159;
  SAMTEC-FFSD-XX-X-XX.XX-01-PRINT.pdf, line 83]`.
- It is honestly `tbd`, "decided_by: M4, on the first mated pair". It is
  recorded here because it replaced a value (2.44) that was *derived*,
  although from the wrong quantity, and it is now the least certain number
  in the stack. The fix's explanation should say it is a scale reading
  against the print's instruction, so nobody promotes it to `nominal`.

**Fix:** append "[scaled against the print's DO NOT SCALE note — a
placeholder until measured]" to the source.

### K8-12 [advisory] `chain-connectors` (4) is restated as "all four positions" in the row that says not to restate it, and in today's ADR text

**Node:** figure `chain-connectors`; BOM row J-CHAIN.

- J-CHAIN's notes: "Quantity is the tracked figure chain-connectors; do not
  restate it … THE SAME PART AT ALL FOUR POSITIONS" `[repo hardware/interfaces/key-chain-loom/bom.csv:2]`.
  The same phrase is in ADR 0017:120 (written today) and in
  `key-chain-loom.md:112,414`, the owner, which is allowed to state it.
- The value is right. This is the shape-3 precondition: a count stated beside
  the figure that owns it. The checker's patterns for `chain-connectors` are
  all old counts ("eight connectors", "Five connectors"…)
  `[run: figures.yaml chain-connectors.forbidden]`, so a future move from 4
  would not flag these.

**Fix:** "the same part at every `J-CHAIN` position (`chain-connectors`)".

### K8-13 [advisory] Smaller stale edges

- `mechanical/cad/woody_body.scad:757`: "there are no looms since ADR 0017 -
  the key boards are on flat flex and the Matrix on a ribbon" `[repo]`. A
  live comment in the §6 corpus. Changing the `.scad` re-fingerprints the
  renders, so fold it into the next model change.
- `docs/reference/ks33-geometry.md:134-136`: "on a 1.6 mm board it [the
  pole] protrudes 0.5–0.9 mm below the underside" `[repo]`. The page is cited
  as the source of the 1.2 mm decision (ADR 0020:80, body.yaml:432, tooling.md:338),
  but it has no 1.2 mm line. On 1.2 mm the pole protrudes 5.75 − 3.4 − 1.2 =
  1.15 mm (0.9–1.3 over the 3.2–3.6 window) `[calc, body.yaml:232,236]`.
  Nothing today depends on it; the page just has not heard.
- `mechanical/DESIGN.md:338`: the connector envelope "comes from the IDC
  header's banked page" `[repo]` — the full print since `d46a3b0`.
- **Method trap:** the command in this slice's brief,
  `git log --since=2026-09-27`, returns **0 commits**, because a date without
  a time means that date *at the current time of day* `[run: git log
  --since=2026-09-27 --oneline | wc -l → 0; --since='2026-09-27 00:00' → 14]`.
  A slice that trusted it would audit nothing and report clean. Use
  `--since='2026-09-27 00:00'` or an explicit range.

## Checks run

| Command | Result |
|---|---|
| `python3 tools/check-staleness.py --detail` | **PASS** no live stale values; 172 files, 38 figures / 240 patterns; 6 unresolved (tracked); 217 restated-not-cited (advisory); 24 old values refuted in place. Advisory lists include `1.2 mm` in 8 files and `1.6 mm` in 10; drawn-no-row lists `FFC-CHAIN`/`F-CHAIN` from `notes.md` only |
| `python3 tools/merge-bom.py --check` | 156 rows from 26 fragments, 0 problems |
| `python3 tools/check-netlist.py --strict` | exit 0 |
| `python3 tools/verify-datasheets.py` | 88 verified, 24 blocked/not-fetched, 0 problems |

Everything I verified as correct (no finding): the 13 − n map in both
`board-netlist.yaml` (LH: SCK 11, SH/LD 9, SER 7, QH 5, 3V3 3, GND
4/6/8/10/12, 1–2 unconnected) and every page listed in K8-9; "without −RN2,
3V3 lands on pin 10, a ground" (true under the 13 − n sheets); the footprint
body 2.53–7.86 and courtyard 9.51 = 7.86 + 1.4 + 0.25; J-CHAIN pads
(1.05 − 0.65)/2 = 0.20; standoffs 4 + 4 = MECH-KB-STANDOFF/SCREW qty 8;
TP-CHAIN qty 10 = 5 × 2; `fab/` 15 files = 15 ledger rows; board thickness
1.2 and HASL in the `.kicad_pcb`, `.kicad_pro` and `.gbrjob`; standoff length
2.2 = 3.4 − 1.2.

## Greps run (corpus = `hardware docs/decisions docs/reference config firmware mechanical README.md ROADMAP.md`; `fab/`, `*.kicad_pcb`, `*.gbr`, `*.dxf` excluded unless noted)

| Pattern | Hits | Judgement |
|---|---|---|
| `5\.85` | 0 (5 incl. `.kicad_pcb`) | coordinates only |
| `2\.44` | 0 (26 incl. `.kicad_pcb`, `plate-top.dxf`) | coordinates only |
| `7\.1\b` | 2 | `17.1 ms`, `CH7.1` — unrelated |
| `12-n` `14-n` `12 − n` `14 − n` `12 - n` `14 - n` `12-k` `14-k` | 0 | — |
| `12 − k`, `14 − k` | 1 each | `notes.md` history |
| `key-board pin 8` / `pin 4` / `pins 8 and 6` / `12 SCK` | 1 / 0 / 0 / 0 | `notes.md` history |
| `ZIF` | 14 | all dated history or refuted in place (ADR 0001, 0009, 0017, 0018, notes.md) |
| `FFC` / `FFC-CHAIN` | 3 / 3 | ADR 0017 rename line; notes.md |
| `[Ff]lat flex` | 15 | refuted in place, except `woody_body.scad:757` (K8-13) |
| `ffc_` | 5 | ADR 0017/0020, tooling.md — all say "no longer exists" |
| `200528` / `Molex` | 4 / 4 | ADR 0020 context, tooling.md findings, notes.md — history |
| `between neighbouring switches` / `between each pair of` | 1 / 1 | ADR 0020 amendment (history) / **body.yaml:715 (K8-2)** |
| `one at each plug` | 1 | notes.md history |
| `C toward` | 2 | ADR 0017:41 (amended), notes.md |
| `tilt` | 11 | 3 chain ones refuted (ADR 0017:44/51/175, notes.md); rest IMU |
| `latch` (filtered) | ~45 | none about the chain except refuted ADR 0017/0009 lines |
| `SAMTEC-SHF-1.27MM` / `SAMTEC-FFSD-1.27MM` | 3 / 4 | lib README, body.yaml, params.scad (K8-6) |
| `catalogue` | 10 | lib README (K8-6), body.yaml sources, notes.md |
| `1\.6 ?mm` (key-board sense) | 5 | ADR 0020, tooling.md, DESIGN.md (history); body.yaml:260 (K8-4); ks33-geometry.md:136 (K8-13) |
| `via … 0.[3-7]` | 5 | layout.yaml, `.kicad_pro` (0.7, correct); tooling.md:312 history (K8-10) |
| `13\.1 ?mm|14\.6|17\.4|fold radius|chain_hdr_h` | 20 | ADR 0017:152-158 (K8-1) |
| `stayed the same size` / `at the board.s end` | 1 / 2 | ADR 0020:61,63 (K8-3); tooling.md history |
| `the four this board` | 1 | K8-5 |
| `20-way` | 6 | ADR 0018 ×2 history; ADR 0001:82, 0009:334/644, 0013:244 live (K8-8) |
| `all four positions|four connectors` | 5 | K8-12 |
| key-board pin statements `key[- ]board[^.]{0,40}pins? [0-9]…` | 30 | all 13 − n; none stale |
| sheets/layout/netlists for `12-n|ZIF|200528|FFC|catalogue|5.85|2.44|Molex` | 0 | clean |

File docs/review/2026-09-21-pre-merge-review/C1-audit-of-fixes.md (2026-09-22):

# C1 — audit of this round's own fixes

**Agent:** C1, cold. **Tree:** `HEAD` = `c5e8f84` (`73c2b1b` + this wave's
reports). **Range audited:** `f94e91d..HEAD`, 41 commits.

**Method.** Read every commit message in the range for checkable claims, then
verified each claim **against the working tree at HEAD**, not against the
commit that made it. Tooling claims and reproductions were re-run in
`git archive HEAD` copies under the session scratchpad, never in the repo.
Nothing under `docs/review/**` was read, per the cold rule — see *Not
verified* at the end for what that excludes.

Provenance is marked on every claim: `[repo] path:line`, `[git] <sha>`,
`[calc]`, `[test]` for a reproduction I ran.

---

## Summary

Of ~30 checkable fix claims, **26 verify cleanly at HEAD**. Four do not, and
one of those is a check that reports green on the exact case its own docstring
names as the counter-example.

| # | Finding | Node / file | Consequence |
|---|---|---|---|
| **C1-1** | `check_owners` still passes `spi-series-r` on `100` — the case `2a9c720` claims to have fixed | `tools/check-staleness.py:515-523` | **High.** A green check believed to prove rule 1 |
| **C1-2** | `sim/README.md` credits `carrier.md` twelve lines below the note saying it must not | `hardware/module/breath-receive-stage/sim/README.md:49-50` | **High.** `f16b72b`'s fix, half-landed |
| **C1-3** | The path map and `repo-maintenance.md` §7 disagree with the tree: 22 rows say `unmoved` for files that moved, 113 tracked files have no row | `docs/reference/path-map-2026-09-21.csv`, `repo-maintenance.md:238-241` | **High.** The documented way to resolve a historical path |
| **C1-4** | `key-scan-current`'s register entry says "all three restate it"; it is five, in two files the entry never names | `config/figures.yaml:135-146` | **Medium.** Grep-first failed on the commit that invoked it |
| **C1-5** | `README.md` says `datasheets/` is 77 documents; it is 76, since five commits later the same branch deleted one | `README.md:116` | **Medium.** Named failure mode, inside the fix for it |
| **C1-6** | `pcb-pipeline.md` still says "the six pages"; `81c081d` §8 predicted this and nothing closed it | `docs/reference/pcb-pipeline.md:58` | **Medium.** Net-name reconciliation, the area three reviewers flagged |
| **C1-7** | `README.md` says `docs/review/` is seven waves; the disk has nine, `CLAUDE.md` says three | `README.md:117` | **Low.** Three counts of one quantity |
| **C1-8** | `check_refdes`'s advisory gained a 23-file noise entry, `CO-MENTION`, from `4ecc17e` | `.staleness/report.txt` | **Low.** Erodes the argument that made it advisory |
| **C1-9** | `b631987` says `108c633` carries "22 datasheet file renames"; it is 21 renames and one delete | `[git] 108c633` | **Low.** Accuracy of a commit that exists to record a mistake honestly |

---

## C1-1 — `check_owners` still passes the figure its docstring names (HIGH)

**The claim.** `[git] 2a9c720` — *"The filter was `len(token) >= 3` with
`any()`, so `spi-series-r` passed on `100` … It now requires the MOST
DISTINCTIVE token"* and *"The check now makes exactly one claim: the owner
states something only this figure would say."* The code repeats it in a
comment: *"THE LONGEST token, not any token. `any()` over everything >= 3
chars still passed `spi-series-r` on `100` — the very figure this docstring
names as the counter-example. A check whose own docstring names a case it
does not catch is worse than no check."* `[repo] tools/check-staleness.py:515-521`

**It does not catch it.** The token set is built from **digits only**:

```python
alltoks = re.findall(r"\d+\.?\d*", value)
toks = sorted((t for t in alltoks if len(t) >= 3), key=len, reverse=True)[:1]
```
`[repo] tools/check-staleness.py:522-523`

`spi-series-r`'s value is `100 ohm, R-SPI-SER, qty 3`. Its numeric tokens are
`['100', '3']`; after the `len >= 3` filter only `100` survives, so "the
longest" **is** `100`. The change from `any()` to longest-only is a no-op for
this figure. `R-SPI-SER` — the one string in the value that is distinctive —
is discarded by the regex before the sort ever runs. `[calc]`

**Reproduced.** In a throwaway `git archive HEAD` tree I repointed
`spi-series-r`'s owner to `docs/decisions/0009-enclosure-construction.md`, the
enclosure ADR, which derives no SPI series resistor and mentions SPI only in
passing about cable length:

```
PASS no live stale values | corpus 121 files, 23 circuits | 5 unresolved (tracked)
EXIT=0
```
`[test]` It passes on the single occurrence of `100` in that file, which is
*"10 kΩ, 100 Ω and 10 nF per switch position"* — a key-switch network.
`[repo] docs/decisions/0009-enclosure-construction.md:521`

**How wide the hole is.** For each settled figure I computed the single token
`check_owners` actually tests, and counted how many of the 121 corpus files
contain it — i.e. how many files would pass as that figure's owner: `[calc]`

| figure | token tested | corpus files containing it |
|---|---|---|
| `spi-series-r` | `100` | **47 of 121** |
| `loadswitch-gate-cap` | `197` | **38** |
| `pitch-compensation` | `2.2` | **27** |
| `cref-out-node` | `5050` | **17** |
| `dac-rail` | `5.21` | 16 |
| `plate-thickness` | `1.20` | 10 |
| `panel-toggle-hole` | `6.5` | 10 |
| `opa2197-output-impedance` | `375` | 10 |

Two further notes on the same function. `loadswitch-gate-cap`'s value is
`82 nF, ramp 49-197 ms (98 ms typ)` and the token tested is `197`, the ramp's
**upper bound**, not the `82 nF` the figure is about — so the check cannot
see the capacitor move. And `diode-split-rationale`'s value is prose; its
longest numeric token is `392`, from the parenthetical `r_d 69 mohm at 392 mA`.

**Why this ranks first.** `1d84861`, `2a9c720` and `4ecc17e` all rest on
`check_owners` being the thing that finally reads `owner:`. Three owners were
repointed on its evidence `[git] 2a9c720`, and `4ecc17e`'s STATUS entry treats
rule-1 enforcement as the *next* gap rather than a current one. A check that
green-lights 47 candidate owners for one figure is not evidence that the
repointing was right — it is the `--invert`-proves-the-easy-half mistake that
`8ef7979` names, shipped for the third time in the same session.

**What would close it.** Tokenise on non-numeric distinctive strings too —
refdes (`R-SPI-SER`), part numbers, unit-bearing spellings — and require the
match to be the *rarest* available token, not the longest digit run. The data
above is the acceptance test: no figure should be checkable on a token that
47 files contain.

---

## C1-2 — the sim deck's fix landed in the prose and not in the table (HIGH)

**The claim.** `[git] f16b72b` part B — *"`breath-receive-stage/sim/README.md`
attributed the 60.2 / 58.5 / 73 dB CMRR claims to `carrier.md`. Those moved to
`interfaces/breath-sense-link/` and `carrier.md` contains none of them."*

**Half landed.** The prose at the top is corrected and carries an honest note:

> *"Until 2026-09-21 this section credited `carrier.md` with all three
> figures; that page derives none of them any more"*
> `[repo] hardware/module/breath-receive-stage/sim/README.md:36-38`

Twelve lines below it, the table headed **"Three terms have to appear in the
same deck … each is currently argued on its own page"** still points two of
those three terms at `carrier.md`:

| Term | Where it is argued (as written at HEAD) |
|---|---|
| Source-impedance balance on the twisted pair | `` `carrier.md` ``, the `R1`/`R1b` pair |
| The bias pair against the series legs | … the floor `` `carrier.md` `` quotes |

`[repo] hardware/module/breath-receive-stage/sim/README.md:49-50`

`carrier.md` says in as many words that it no longer holds that argument:

> *"The `R1b` half of this section — the twin in the `AGND` leg, the link-CMRR
> argument for it, and the correction it files against the receive page's own
> case for the part — moved verbatim to `../interfaces/breath-sense-link/`"*
> `[repo] hardware/carrier/carrier.md:140-144`

Every live `R1b` derivation is now in `interfaces/breath-sense-link/`
(lines 70, 81-83, 135, 138, 183, 199, 237). `carrier.md` retains only the
drawing and the pointer. `[repo]`

**Consequence.** This is the sim deck's *contract* — the column that tells
whoever builds the deck where to read each term. It sends them to a page that
holds a drawing and a forwarding address. It is also invisible to every check
for the reasons `f16b72b` itself gives: the path resolves, the figures are
untracked, and the file was written during the restructure so it was never a
conservation source. The mechanism is the one `CLAUDE.md` opens with — the
author was editing the paragraph, and the reader of a deck contract reads the
table.

---

## C1-3 — the documented way to resolve a historical path no longer describes the tree (HIGH)

`CLAUDE.md` §6 ends: *"Paths in those records point at pre-2026-09-21
locations and are not to be corrected. Resolve them through
`docs/reference/repo-maintenance.md` §7."* §7 says:

> *"`path-map-2026-09-21.csv` in this directory maps every old path to its new
> one — **every tracked file has a row**, including the ones that did not
> move, because the question a reader actually asks is 'did this path change?'
> and a map of only the movers cannot answer it."*
> `[repo] docs/reference/repo-maintenance.md:238-241`

Measured against HEAD: `[calc]`

- The map has **287 rows**. **113 tracked files have no row** — every Phase B
  circuit directory (`hardware/carrier/breath-adc/*`, all 23 of them), the
  three new index pages, `datasheets/.moves.csv`, and all 22 re-filed
  datasheets. "Every tracked file has a row" is false by 113.
- **22 rows assert `kind=unmoved`** for datasheet paths that **do not exist**
  — `datasheets/other-semi/74HC165.pdf`, `datasheets/texas-instruments/OPA2197.pdf`
  and 20 more — with the note *"datasheets/ moves whole or not at all"*.
  They moved, internally, in `[git] 108c633` and were recorded in
  `datasheets/.moves.csv` by `[git] b631987`. Both the `new` column and the
  `kind` column are wrong for those rows.
  `[repo] docs/reference/path-map-2026-09-21.csv:79-99`
- One more: `datasheets/mechanical/WS2815-worldsemi-datasheet.pdf`, `unmoved`,
  deleted in `108c633` as the duplicate bank.

`[git] 1c1155f` says *"The path map is excluded by name, because its old-side
column is SUPPOSED to name paths that no longer resolve."* That is right about
the **old** column and does not cover this: the **new** column and the `kind`
verdict are the map's answer to "where is it now", and for 22 datasheets the
answer is a path that has not existed since `108c633`.

**Consequence.** `repo-maintenance.md` §7 says history outnumbers the corpus
24:1 on path references and that the map is how you resolve them. A reader
resolving `datasheets/texas-instruments/OPA2197.pdf` out of a September review
gets `unmoved` and a dead path, when `datasheets/.moves.csv` has the answer.
Either the map is regenerated and §7 stays true, or §7 stops claiming
completeness and names `.moves.csv` as the second hop. Both are cheap; neither
happened.

---

## C1-4 — `key-scan-current` undercounts its own duplication (MEDIUM)

**The claim.** `[git] f16b72b` part A and the register entry it wrote:

> *"1.43 mA, 25.8 mA, 0.077 %, 3.2 LSB and ~1594 counts each appear in two or
> three corpus files … DEDUPLICATING it is still owed: rule 1 says the owner
> states it and the other two cite it, and **today all three restate it**."*
> `[repo] config/figures.yaml:135-146`

The entry names three files: the owner
`hardware/cluster/key-switch-network/key-switch-network.md`, plus `carrier.md`
and `interfaces/key-chain-loom/key-chain-loom.md`.

**There are five statements, in four files.** `[repo]`

| File | Line | Text |
|---|---|---|
| `hardware/cluster/key-switch-network/key-switch-network.md` (owner) | 105 | `\| Static \| **1.43 mA** per closed key; 18 closed = **25.8 mA** \|` |
| `hardware/carrier/carrier.md` | 172-174 | full derivation, `1.43 mA` / `25.8 mA` / `0.077 %` / `3.2 LSB` |
| `hardware/interfaces/key-chain-loom/key-chain-loom.md` | 115-126 | full derivation, all five numbers |
| **`docs/decisions/0001-mcu-and-board-partitioning.md`** | **230** | `\| Static \| **1.43 mA** per closed key; 18 closed = **25.8 mA** \|` |
| `hardware/carrier/carrier.md` | 373 | `25.8 mA of play-rate load worth 3.2 LSB on a ~1594-count …` |

ADR 0001:230 is a **byte-identical copy** of the owner's table row and is
named nowhere in the entry, the `companion` field or the commit message.
`[calc]`

**Why it matters more than the count.** `f16b72b` is the commit that tracked
this figure *because* a cold reviewer found it live in two files with nothing
able to see a divergence. The register entry it wrote is now the authority on
where the duplicates are, and it is missing one of them — in an ADR, the
document class most likely to be read years from now. `CLAUDE.md` §2 step 2
exists for exactly this: the list was written from the pages in front of the
author. `6602b43` records the same lesson from the same afternoon
(*"the agent saw three of the five"*), one wave earlier.

**Related, unrecorded.** `inamp-full-scale` (`-9.94 V`, owner
`interfaces/breath-sense-link/breath-sense-link.md` after `2a9c720`
repointed it) is restated in **seven** non-owner corpus locations —
`breath-receive-stage.md:89,126`, `breath-output-stage.md:40`,
`breath-response-shaper.md:51,104`, `bom.csv:118`, plus the drawing `2a9c720`
names. That is worse than `sensor-full-scale`, which `4ecc17e` singles out as
*"restated six times right now"* — a count I confirmed exactly, at six.
`[calc]` `inamp-full-scale` appears in no debt list I can see from the corpus.

---

## C1-5 — `README.md` still says 77 datasheets; there are 76 (MEDIUM)

`[repo] README.md:116-118`:

> *"`datasheets/` is 77 banked documents and the largest directory in the
> repository; `docs/review/` is seven waves. Both were invisible in the one
> file a new reader opens first."*

Counted at each point in the branch: `[calc]`

| revision | files under `datasheets/` (excl. manifest, README, fragments) |
|---|---|
| `a973267` — the commit that wrote the sentence | **77** |
| `b631987^` (i.e. after `108c633`) | 76 |
| `HEAD` | **76** |

`[git] 108c633` deleted `datasheets/mechanical/WS2815-worldsemi-datasheet.pdf`
— the WS2815 was banked twice under two paths with one SHA-256, and
`[git] b631987` records the de-duplication deliberately: *"Both rows survive …
and now name one file."* The **row** count stayed 77; the **file** count went
to 76. `README.md` states it as a count of documents.

Directory census at HEAD: `analog 8, connectors 22, discrete-and-power 20,
led 6, logic 5, mechanical 15` = **76**. `[calc]`

This is the named failure mode with an unusually short fuse: the sentence was
written to fix an omission a cold reviewer found, and five commits later on
the same branch the number it states moved. Nothing can catch it — the
datasheet count is not a tracked figure, and `datasheets/` is not in
`CORPUS_DIRS`, so `datasheets/README.md` is unscanned as well.
`[repo] tools/check-staleness.py:30`

---

## C1-6 — `pcb-pipeline.md` still says "the six pages" (MEDIUM)

`[git] 81c081d` §8 recorded this as debt the restructure would create:
*"pcb-pipeline says 'the six' and will be wrong with no check able to see
it."* Nothing in the 40 commits since closed it.

At HEAD: `[repo] docs/reference/pcb-pipeline.md:58`

> **1. Reconcile net names across the six pages first.** `AGND` means the
> umbilical sense conductor *and* the module analog return. `BREATH` means the
> in-amp input *and* the output jack. **Three cold reviewers found this
> independently.**

There are now **23 circuit pages plus four board/index pages**, not six.
`[calc]` This is a live instruction under *"Precursors that bite at the
netlist, not the board — only the ones that corrupt something no later stage
can catch"*, and the failure it guards against is the one this wave keeps
naming: a transcription that misses the `AGND`/`BREATH` collision shorts the
in-amp input to the output jack with every downstream check passing
(`[git] 036b182`, `[git] fcd56e6`). Someone following the instruction
literally reconciles six pages out of twenty-seven.

Same section, line 67: *"Seven rails, six modules"* — SKiDL modules, probably
unaffected, but it reads as the same stale count on a second glance and is
worth a word either way.

---

## C1-7 — three documents, three counts of the review waves (LOW)

- `[repo] README.md:117` — *"`docs/review/` is seven waves"*.
- `[repo] CLAUDE.md:92-94` — *"Three have run"*, naming
  `2026-09-20-cold-review`, `2026-09-21-hardware-and-standards-review`,
  `2026-09-21-staleness-sweep`.
- On disk at HEAD: **nine** directories — the three above plus
  `datasheet-reconciliation`, `pcb-pipeline-review`, `preflight`,
  `restructure-design`, `schematic-review`, `pre-merge-review`, and one loose
  file `2026-09-20-analog-design-review.md`. `[calc]`

"Seven" was already off by one when `a973267` wrote it (eight directories at
that commit) and is off by two now: `[git] 6be65f7` and `[git] 73c2b1b` each
added one. `CLAUDE.md`'s "three" is the user's own and predates the branch;
I flag it only because it makes three different live answers to one question,
which is the shape the register exists to prevent.

---

## C1-8 — the refdes advisory gained a 23-file noise entry (LOW)

`[git] 9310848` wired `check_refdes` as an advisory on a measured argument:
*"raw it yields 36 hits of which about 14 are not reference designators at
all. Filtered, 18 — and they are real."*

At HEAD the advisory yields **19**, and the new one is `CO-MENTION`, listed
against **23 files** — every `circuit.yaml` in the repository:

```
CO-MENTION   hardware/carrier/breath-adc/circuit.yaml, …[23 files]…
```
`[test]` (`python3 tools/check-staleness.py --detail`)

`CO-MENTION` is not a refdes. It is a word in the `STATUS: SEEDED, NOT
VERIFIED` banner that `[git] 4ecc17e` added to all 23 `circuit.yaml` files
(*"`depends_on` was machine-seeded from CO-MENTION"*), and `check_refdes`
scans raw file text including comments. `[repo]` It is now the longest entry
in the advisory by a factor of five.

Low consequence on its own; worth reporting because the *only* argument for
this check being advisory rather than fatal is its signal-to-noise ratio, and
that ratio was degraded by the commit that documented the seeding. The fix is
one entry in the existing filter.

---

## C1-9 — `b631987`'s confession is accurate to within one word (LOW)

`[git] b631987` — *"Commit `108c633`, whose message says 'two tools', also
carries 22 datasheet file renames."*

`git show --name-status 108c633` gives **21 renames (all R100), one delete,
one modify, one add**. `[git] 108c633` The delete is
`datasheets/mechanical/WS2815-worldsemi-datasheet.pdf`. So the substance is
correct and honestly stated — `108c633`'s message does describe a commit that
does not exist — but "22 renames" is 21 renames and a deletion. Recording it
because `CLAUDE.md` is explicit that a finding filed as handled stops getting
re-checked, and this is a commit whose whole purpose is the accuracy of a
record.

---

## What I verified and found sound

Each of these was re-run or re-measured at HEAD, not taken from the commit.

**Tooling — reproduced in throwaway `git archive HEAD` trees**

| Claim | Commit | Result |
|---|---|---|
| Non-UTF-8 byte in a fragment + hand edit in `bom.csv` used to print PASS/exit 0; now fails | `eaf92f4` F1 | `[test]` `FAIL 1 shape … 11 generated`, **exit 1**. Both the stderr harvest and `check_readable` fire |
| Malformed `figures.yaml` renders `CHECKER CRASHED` in the hook, not a blank | `1787905` F6 | `[test]` hook string reproduced: `staleness: CHECKER CRASHED (exit 1) - no PASS or FAIL line` |
| `merge-manifests.py --check` byte-compares and names the first differing line; `check-staleness.py` runs it | `e30d3d8` | `[test]` appended a row to `MANIFEST.csv` → `PROBLEM: MANIFEST.csv does not match its fragments, first difference at line 100`, and `check-staleness` reports `1 generated`, exit 1 |
| `merge-manifests.py` checks **before** writing | `e30d3d8` | `[test]` corrupted `.manifest-R6.csv`'s header → `REFUSING TO WRITE`, exit 1, `MANIFEST.csv` still 99 lines |
| `check-conservation.py` exits non-zero and sees a tail loss | `1787905` F7 | `[test]` deleted the last 7 words of a page → `TAIL: the source's last 8 words are not in any destination`, **exit 1** |
| `MIN_CORPUS_FILES` raised 30 → 100 | `1787905` F10 | `[repo] tools/check-staleness.py:53` |
| `check_circuits` fails on a dangling refdes, fig and circuit id | `07c7ae8` | `[test]` all three named individually, exit 1 |
| `check_sections` and `check_links` bite | `9fc779a`, `f3876be` | `[test]` injected `§99` and a dead link → both reported, exit 1 |
| `verify-datasheets.py` resolves corpus-cited paths | `1c1155f` | `[test]` renamed a cited path → `CORPUS PATHS THAT DO NOT RESOLVE (3) of 127 cited`, exit 1 |
| Tool wiring assertion | `9310848` | `[repo] tools/check-staleness.py:576-592`, present and running |

**Data and structure — measured at HEAD**

- **23 circuit directories, 294 declared edges** — `refdes 126, fig 87,
  circuit 50, adr 31`, matching `[git] 07c7ae8` exactly. All 23 `circuit.yaml`
  open with the `SEEDED, NOT VERIFIED` banner `[git] 4ecc17e` promised; none
  is missing it. No board page has a `circuit.yaml`. `[calc]`
- **`bom.csv`**: 139 lines, **139 CRLF, 0 bare LF**, 138 rows × 11 columns,
  `unplaced.csv` 50 rows. The row **set** is byte-for-byte identical across
  `c483829` (0 lost, 0 added) and the `ref` set is unchanged from `c483829^`
  to HEAD. `[calc]` `merge-bom.py --check` and `merge-manifests.py --check`
  both clean.
- **Manifest fragments untouched** — all eight `.manifest-R*.csv` blobs are
  identical from `b631987^` to HEAD, as `[git] b631987` required. `[calc]`
- **Conservation re-run at HEAD**, not at the split commit: `carrier.md` from
  `fbf040c^` against all 16 current `carrier/` + `interfaces/` files gives
  **4 gaps, and all four are legitimate** — three are the datasheet path
  rewrites from `1c1155f`, one is the `cluster-boards.md §4` →
  `key-marker-and-bits.md` repoint from the split. No text was lost by any
  later commit. `[test]`
- **ADR index** — all 14 rows agree with their target's `**Status:**` line.
  `a973267` holds. `[calc]` (0008's row drops "(base, not Plus)"; harmless.)
- **`0.437 V` / `0.579 V`** (`6602b43`) — both now appear only inside
  refutation text; `0.573 V` is stated by its owner
  `breath-receive-stage.md:114` and nowhere else live. ADR 0006 and `bom.csv`,
  the two the grep-first rule caught, are both clean. `[calc]`
- **`0.00018` / `0.00027` / `0.00029`** (`c4fb614`) — all three only in
  refutation text; `0.00044` in the owner `power-entry.md:104` and the
  register. The `D-REVPOL` BOM note carries a correctly-formed append-only
  correction. `[calc]`
- **`sensor-full-scale`** — ADR 0003 now spells the coefficient `0.053` with
  the middle dot (`docs/decisions/0003-breath-sensing-path.md:123,436`), the
  one-character escape `c4fb614` describes. `[repo]`
- **`mod-reference`** (`d6146aa`) — `mod-channels.md:197-200` cites the figure
  and states `1.33 mA` with `[calc: 3.3333/2500]` and the refutation in place;
  the drawing at line 38 agrees at `~1.3 mA`. `[repo]`
- **`loop-budget`** (`eaf92f4` F4) — `latency-budget.md:148` states
  `196–241 µs of 250 µs`; the superseded `136 µs` / `54 % duty` survive only
  inside the blockquote that refutes them, and `291 µs with driver defaults`
  is stated. No other corpus page restates the comfortable version. `[calc]`
- **`pitch-stage` orphan table** (`14d2ccd`) — the follow-up it promised
  *did* land: the four headerless rows are now in
  `hardware/module/pitch-stage/notes.md:43-64` under *"The superseded accuracy
  table"*, and `pitch-stage.md:298` points at them. `[repo]`
- **`repo-maintenance.md` §4** (`d71488e`) — correctly describes `bom.csv` as
  generated, names `merge-bom.py`, and its "Validate … after any edit" bullet
  is re-scoped to what `merge-bom.py` does. `unplaced.csv` is now named in
  four Markdown files. `[repo]`
- **`README.md`** (`1787905` F2, `a973267`) — no "split by board", one licence
  section, `datasheets/` and `docs/review/` present in the layout tree.
  `[repo]`
- **The three new index pages** (`fcd56e6`) — `hardware/README.md`,
  `module/module.md`, `interfaces/README.md` exist; `module.md` lists all 12
  module circuits and restates no tracked value; `carrier.md` and
  `cluster-boards.md` likewise index all of theirs. `module.md`'s claim that
  `unplaced.csv` holds the DAC, the in-amp and the LM317 is true
  (`U-DAC`, `U-DIFFRX`, `U-REG-DAC`). `[calc]`
- **`§2` → "stage 2"** (`9fc779a`) — both sim decks now name the stage the way
  `pcb-pipeline.md` titles it. `[repo]`
- **Interfaces `End` column** (`036b182`) — present on all three crossing
  pages. `[repo]`
- **Hook wording** (`1787905` F6) — the hook writes the terse summary to
  `.staleness-report.txt` (83 bytes) and the detail lands in
  `.staleness/report.txt` (6.6 kB). The two halves now agree.
  `[repo] .claude/settings.json` `[calc]`
- **`check-staleness.py` clean at HEAD**: `PASS … corpus 121 files, 23
  circuits | 5 unresolved (tracked)`, exit 0. `[test]`

---

## Not verified — and why

**Anything whose evidence is inside `docs/review/**`.** The cold rule bars me
from reading it, so I did not open those files or `git show` their contents.
That leaves these claims **unaudited, not cleared**:

- `[git] 21e2ea3` — *"97.2% of the original word-mass present verbatim"*, the
  blob-SHA comparison across 87 datasheets, the sub-8-word structural diff,
  and *"497 words in 49 runs, 1.57%"* of duplication.
- `[git] 4ecc17e` / `2701647` / `aa2b89f` — `STATUS.md`'s *"eight named pieces
  of debt"*, the record of the six own-defects, and whether the stale Phase B
  section really was replaced with a note rather than deleted. I verified the
  one claim in `aa2b89f` that is checkable from outside: `4ecc17e`'s
  *"`sensor-full-scale` … is restated six times right now"* is **exactly
  right** at six. `[calc]`
- `[git] 81fad55` / `d88837b` / `453a3b3` / `68e9e1a` — per-agent *"0 REAL
  GAPS"* claims. I re-ran conservation at HEAD for the largest split
  (`carrier.md`, 8 709 words → 16 files) and it holds; I did not re-run the
  other six.
- `[git] 3473436` / `44697f9` — D1/D2/D3 findings and the `VERIFIED.md`
  entries recording which were checked by hand.

**`tools/rewrite-paths.py --invert`** (`8ef7979`, `8bb7366`) — the Phase A
inversion proof. I did not re-run it, because C1-3 shows the map it runs
against is a Phase-A snapshot; re-running it at HEAD would measure the map's
staleness, not the rewrite's correctness. It was a valid proof at `a9f647a`.
Whoever closes C1-3 should re-run it after, not before.

---

## Recommended order

1. **C1-1** — fix `check_owners`' tokeniser before anything else relies on it
   again. Three owner repointings this session rest on it, and the table in
   C1-1 is the acceptance test.
2. **C1-2**, **C1-4** — two half-landed fixes from `f16b72b`, both cheap, both
   in the "filed as handled" class `CLAUDE.md` calls worse than a wrong
   finding.
3. **C1-3** — decide whether the map is regenerated or §7 is re-scoped, then
   say which in `repo-maintenance.md`.
4. **C1-5**, **C1-6**, **C1-7** — three stale counts, one line each.
5. **C1-8**, **C1-9** — one filter entry and one word.

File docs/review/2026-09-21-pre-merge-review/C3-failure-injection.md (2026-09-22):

# C3 — Failure injection

**Agent:** C3, cold pre-merge review, 2026-09-21.
**Slice:** what the design does when things go wrong, not when they work.
**Cold rule observed:** nothing under `docs/review/**` was read. `docs/log/` and
`docs/research/` were touched only where noted, and are marked as history.

**Provenance on every claim.** `[repo] path:line` — read in this repository.
`[calc]` — arithmetic shown. `[datasheet]` — document and page, as the corpus
quotes it (I did not re-open the PDFs; where a figure is load-bearing I say so).
`[from memory]` — not verified here and must be checked.

**Findings are node-indexed** and filed against a circuit node or BOM reference.
**Nothing was fixed.** `tools/check-staleness.py` reports `PASS ... 5 unresolved
(tracked)` on the tree as I found it `[repo]`, so none of what follows is
something the checker can see — every finding below is semantic, which is the
class CLAUDE.md §5 says only a wave catches.

---

## Summary

Nineteen findings. Six are **silent** in the sense the ROADMAP means — the
instrument keeps playing, or keeps looking powered, while being wrong.

| # | Node | What | Loud or silent |
|---|---|---|---|
| **C3-01** | `+12V` raw / `D1`,`D2` / `U-LOADSW` `VCC` | Two mutually exclusive topologies stated for the module's highest-current node | latent |
| **C3-02** | `C-TIMER-LOADSW` | No minimum re-plug interval. Replug inside 2–4 s can latch off | **dark, and mislabelled** |
| **C3-03** | DAC `SYNC`/`SCLK`/`DIN` | Row-offset ribbon: the fix landed on the 10 kΩ pull and not the ~25 Ω driver on the same net | loud (dead DAC) |
| **C3-04** | DAC `AVDD` vs bus `+5V` | No power-up sequencing relationship; no series resistance | **silent (degradation)** |
| **C3-05** | `J-UMB` pin 7 `CS` | Connector break/make during a live transaction is not analysed anywhere | **silent and sticky** |
| **C3-06** | `J-UMB` pin 6 `PWR_GND` | A dirty pin-6 contact reroutes ~360 mA through `DIG_GND` into the analog star | **silent** |
| **C3-07** | etherCON contact set | No make-first/break-last on anything; mate order never stated | latent |
| **C3-08** | `C-BULK-RAIL` / `C1`–`C4` | Page says 4 × 47 µF; its own BOM row says "NOT 47uF on every rail" | latent |
| **C3-09** | all six jacks, rack power-**down** | ~30 ms toward −12 V on every power-down, analysed only in a BOM note | loud but unowned |
| **C3-10** | `PITCH` jack, rack power-on | ADR 0006 says "below −2 V"; the stage says 0.000 V | **silent (in tune-ish)** |
| **C3-11** | `BREATH` jack, instrument absent | ADR 0006's standing offset is 0.2–1.7 V; recomputes to 0.29–2.30 V | latent |
| **C3-12** | `J-CV` ×6 sleeve / `PANEL` | Which net the six jack sleeves tie to is stated nowhere | **silent** |
| **C3-13** | `C-FILT-PITCH`,`C-FILT-MOD`,`C-OUT-BREATH` | These are the ESD front line and none has a voltage rating | loud (dead cap) |
| **C3-14** | `U-TVS-MODULE` | ESD protection is fitted at the end nobody touches | loud |
| **C3-15** | `J-CHAIN` signal conductors | `F-CHAIN` fuses the supply conductor; the four signals get nothing | loud (marker) |
| **C3-16** | `SW1-n` contact material | The gold-vs-silver argument was made for `SW-POWER` and not for 21 key switches | **silent** |
| **C3-17** | `R-KEY-PU` 2.2 k vs 10 k | The recorded trade omits the leakage term humidity actually drives | latent |
| **C3-18** | `R4`/`R5` × `C_diff` | The unplug glide is accidental and written nowhere | latent |
| **C3-19** | `U-LOADSW` `ON` | Undesigned node on a front-panel lever: no divider, pull-down, debounce or ESD path | loud |

Two refuted premises found in passing, both in my slice's argument chain, are in
*Appendix A*.

---

## 1. The umbilical is unplugged mid-note

### What the corpus already says, and it says it well

This is the best-documented failure in the repository. `link-supervision.md`
carries a table of exactly what the deleted watchdog used to cover `[repo]
hardware/module/link-supervision/link-supervision.md:69-76`:

> | Cable unplugged mid-note | caught | **not caught — the DAC holds and the rack drones** |

and states the cost plainly: *"pull the umbilical mid-note and the rack holds
that note until you flip the module's toggle. That is the everyday case, not an
exotic one."* `[repo] link-supervision.md:78-80`. ADR 0004 withdraws its own
mechanism in the same terms `[repo] docs/decisions/0004-cv-interface-module.md:486-490`,
and `ROADMAP.md` E10 books the test `[repo] ROADMAP.md:51`.

Traced per jack, on the steady state after the plug leaves:

| Jack | State | Why |
|---|---|---|
| `PITCH` | **Holds its last value indefinitely** | The DAC keeps `AVDD` from the LM317 and the module keeps bus power. Nothing asserts `CLR` |
| `MOD 1`–`MOD 4` | **Hold their last values indefinitely** | Same. Channel 7 also holds, so the offset term is intact and the outputs are coherent, not railed |
| `BREATH` | Settles to `OFFSET` knob position less a fixed term | `R4`/`R5` 1 MΩ give the in-amp's inputs a DC path, so it rests at `V_REF` rather than saturating `[repo] hardware/interfaces/breath-sense-link/breath-sense-link.md:137` |

So five of six jacks are stuck and one is not — and the corpus's own framing
("a stuck CV is worse than a dead one", ADR 0004 §) applies to five of them. That
is stated and accepted. I have nothing to add to the steady state.

### C3-05 — what happens *during* the unplug is analysed nowhere

**Node: `J-UMB` pin 7 `CS`.** Every treatment of disconnection in the corpus is
of the state *after* the plug is out. I searched the whole design corpus for
`mid-note|unplug|disconnect|live insertion|insertion` and every hit is either
the steady state or the load switch's inrush arithmetic `[repo]`.

The transient is a different problem, and the corpus has already established why
it matters:

- A glitch on `CS` re-frames the 32-bit word, so every bit lands in the wrong
  field — *"including the software-reset and internal-reference-enable bits"*
  `[repo] hardware/interfaces/spi-link/spi-link.md:163-166`.
- `MISO` is deleted, so *"firmware can never read back what the DAC actually
  received"* `[repo] spi-link.md:144-146`.
- It is therefore *"the only failure in the digital path that does not self-heal
  on the next update"* — a **sticky** failure, against the 250 µs self-healing
  of everything else `[repo] spi-link.md:145-147, 163-166`.

The corpus defends `CS` against two glitch sources: intra-pair crosstalk (the
pin-map swap, ADR 0004) and floating inputs (`R-SPI-PULL` ×6). It defends it
against **neither of the two mechanical events that generate the most `CS` edges
in the instrument's life**: pulling the plug, and pushing it back in. A 4 kHz
refresh means a `CS` frame is in flight roughly 12 % of the time at 2 MHz
`[calc: 6 × 32 bits / 2 MHz = 96 µs of each 250 µs pass = 38 %`, actually — see
the loop budget's own `96.0 µs` figure `[repo] spi-link.md:117`, so **38 %**].
Contact bounce on break is a burst of edges, not one edge, and it lands inside a
word 38 % of the time.

**What a mis-framed word can write.** The DAC8568 command field is at the top of
the word, so a bit-count shift changes the command, not just data. Three of the
reachable outcomes are sticky and invisible:

- **Clear-code register.** `mod-channels.md` builds its entire safe-state
  argument on `CLR` producing zero scale `[repo]
  hardware/module/mod-channels/mod-channels.md:150-176`. The clear code is a
  writable register. A mis-framed word that rewrites it means the *next* `CLR`
  — the power-on reset, which ADR 0006 says happens on every rack power-up —
  parks four jacks somewhere else.
- **Internal-reference enable.** Disabling it takes `VREFOUT` to zero, which
  takes pitch's `V_ref` and the mod offset with it.
- **Software reset.**

`firmware/README.md` already names this exact shape: *"The same shape of bug is
latent in every other register the DAC holds that firmware writes once: the
internal-reference enable, and the clear-code register itself"* `[repo]
firmware/README.md:71-73` — and its answer is the statelessness rule, refreshing
sticky registers periodically. **That rule is what closes C3-05**, and it is
sized against a *firmware* fault, not against a mechanical one. Nothing states
the refresh interval for the sticky set ("a word every few thousand passes"
`[repo] firmware/README.md:78`), so the window between a plug event and the next
sticky-register refresh is undefined and could be seconds.

**Would it be loud?** No. A rewritten clear code does nothing at all until the
next power cycle, at which point four mod jacks come up somewhere other than 0 V
— and ADR 0006's power-on table, which is the document someone would check, says
they come up at exactly 0 V. This is the worst diagnostic shape in the project:
a fault installed by one physical act, expressed by a different one, hours later.

**Recommendation to the wave, not a fix:** the cheapest answer is a firmware
requirement, not a part — rewrite the clear-code register and the reference
enable every N passes with N small (tens of milliseconds), and say so in
`firmware/README.md` with the plug event as the stated reason. The second-
cheapest is the `74AHCT14` that `link-supervision.md` already wants for three
other jobs `[repo] link-supervision.md:105-118`; Schmitt hysteresis on `CS` is
what turns bounce into one clean edge instead of twelve.

### C3-18 — the one unplug transient that behaves, and it does so by accident

**Node: `R4`/`R5` × `C_diff`.** On break, `C_diff` (15 nF) discharges through the
two 1 MΩ bias resistors in series `[repo] breath-sense-link.md:137-142`:

```
τ = 15 nF × 2 MΩ = 30 ms          [calc]
```

So `BREATH` **glides** from mid-note to its rest position over ~30 ms rather than
stepping. That is why E10's *"breath parks quietly"* test will pass — and the
mechanism is written in no document. Anyone who later reduces `R4`/`R5` to
100 kΩ (the reflexive value for in-amp bias resistors) gets `τ` = 3 ms and turns
a glide into a click, with no line anywhere to warn them. `R4`/`R5` have their
own justification on the page (bias return, ADR 0005's withdrawn
`R-PD-BREATH` blockquote `[repo] docs/decisions/0005-power-architecture.md:358-372`)
and that justification does not mention the time constant at all.

---

## 2. The umbilical is hot-plugged

### What the corpus says

`umbilical-load-switch.md` treats hot-plug as **the** sizing case and does it
thoroughly `[repo] hardware/module/umbilical-load-switch/umbilical-load-switch.md:210-228`:
17.1 ms through the foldback ramp plus 30.4 ms at 940 mA less load, **47.5 ms
entirely in current limit**, against a worst-case fault timer of **95.6 ms** —
a stated **2.01×** margin. The `FB` divider is sized, `C-GATE` and `C-TIMER` are
sized, and ADI's own reference gate network is copied in. This is good work and I
found no arithmetic error in it.

It is, however, the **only** thing about hot-plug that is analysed. It answers
"how much current, for how long". It does not answer "in what order do the eight
contacts meet, and what is alive while only some of them have".

### C3-07 — no make-first/break-last on anything, and the mate order is never stated

**Node: the etherCON contact set, `J-UMBILICAL`.** An 8P8C/RJ45 contact block has
eight identical leaf contacts in one row. There is no sequenced, staggered or
early-mate contact on any of them `[from memory — the NE8FDP and NE8MC drawings
are banked at `datasheets/connectors/NE8FDP.pdf` and `NE8MC.pdf`, so this is
checkable in-repo and should be]`. The etherCON **shell** engages before the
contacts, but the shell is chassis/shield, not `PWR_GND` — and the shield policy
is, in `power-entry.md`'s own words, *"sixteen words in the whole repo"* `[repo]
hardware/module/power-entry/power-entry.md:140`.

Mate skew on a hand-inserted RJ45 comes from insertion angle and contact
tolerance and is not controlled. So during a hot-plug there is a window — short,
but real, and repeated on every insertion — in which some of these are connected
and some are not:

| Pins | Signal | What it is if it mates early or late |
|---|---|---|
| 3, 6 | `+12V` / `PWR_GND` | The supply and its only intended return |
| 1, 2 | `BREATH` / `AGND` | `AGND` is **an in-amp input, not a ground** `[repo] ADR 0004:602-640` |
| 7, 8 | `CS` / `DIG_GND` | `DIG_GND` is a ground, and where it ties is `dig-gnd-topology`, **DISPUTED** |
| 4, 5 | `SCLK` / `MOSI` | — |

**Pin 3 before pin 6 is the case that matters.** If `+12V` mates while
`PWR_GND` has not, the instrument's inrush current — current-limited at 940 mA,
not at zero — has to return through whichever ground conductor *has* mated.
There are two candidates and both are wrong:

- **Pin 8 `DIG_GND`.** At the module it ties to the analog star (per
  `digital-and-supervision.md`) or to the pour under the SPI trace (per
  `power-entry.md`) or to its own path to the star (per ADR 0004) — the figure
  records all three and is DISPUTED `[repo] config/figures.yaml:387-398`. On
  **any** of the three, up to 940 mA of inrush transits a conductor sized for
  SPI return current and lands in the module's quiet copper.
- **Pin 2 `AGND`.** Bounded, and bounded by accident: the instrument-side
  `R1b` 1 kΩ is in series, so the worst case is ~12 mA into the module-side
  `BAV99` `[calc: 12 V / 1 kΩ]`, dissipating ~144 mW in an instrument-side 1206
  during the event `[repo] breath-sense-link.md:134]`. Survivable. But `R1b`
  exists for CMRR balance `[repo] breath-sense-link.md:192-197]`, and it is the
  only thing standing between a partial mate and the INA828's input structure.
  Nothing says so.

**Nothing in the corpus states a requirement on mate order**, nor records that
none is available. That is the finding: not that the design is wrong, but that
the one connector property that governs hot-plug safety is undocumented on a
connector the design explicitly invites hot-plugging into (*"etherCON invites
live insertion"* `[repo] umbilical-load-switch.md:211`).

This is worth an E6/E11 bench item alongside the current-probe measurement the
ROADMAP already books: insert the plug slowly and at an angle, twenty times,
with a scope on `DIG_GND`-to-module-star.
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

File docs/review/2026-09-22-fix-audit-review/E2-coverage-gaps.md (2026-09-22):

# E2 — what the fix-audit wave did not look at

**Slice:** the complement of the twenty briefs. The parts of
`0e68f25~1..HEAD` no slice examined, the defect classes no slice was asked
about, and whether the twenty slices sliced by fact domain as `CLAUDE.md`
requires.

**Read:** `docs/review/2026-09-22-fix-audit-review/README.md`, all 20 `D*.md`
plus `README.md`, `STATUS.md` and `VERIFIED.md` of
`docs/review/2026-09-22-fix-audit/`, the batch's commit messages, and the
corpus. **No sibling in this round and no earlier wave was read**
`[test] ls docs/review/2026-09-22-fix-audit-review/` returns `README.md` only,
which is the whole of what I opened there.

---

## 0. The denominator moved while I was measuring it — read this first
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

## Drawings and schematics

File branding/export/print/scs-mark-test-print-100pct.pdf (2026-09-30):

## Space Coast Synthesizers mark: test print

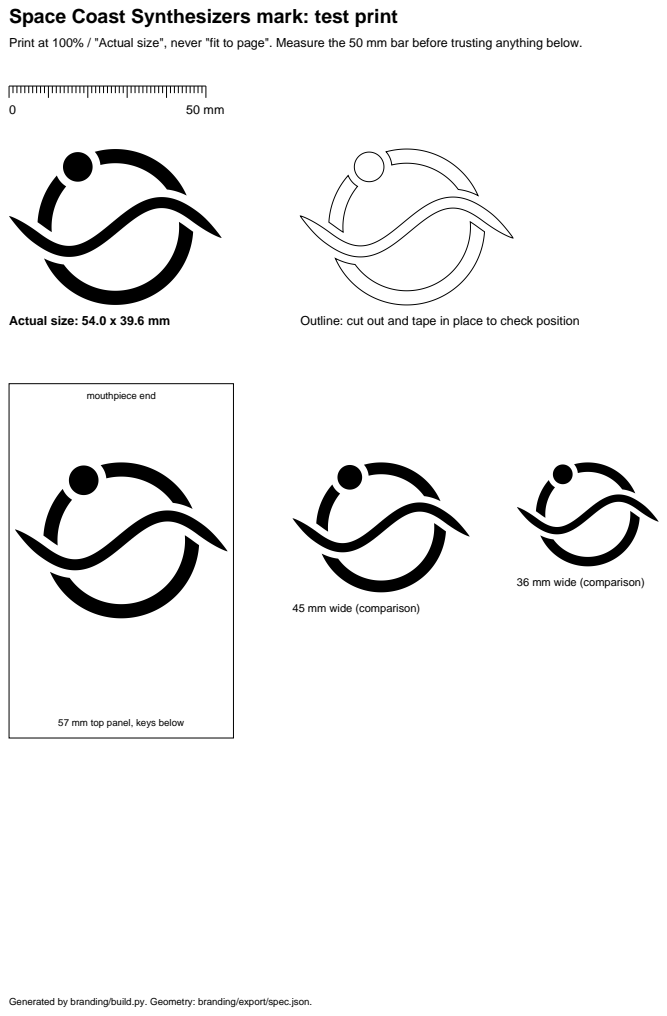
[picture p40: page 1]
Actual size: 54.0 x 39.6 mm; Outline: cut out and tape in place to check position; mouthpiece end

Print at 100% / "Actual size", never "fit to page". Measure the 50 mm bar before trusting anything below.

36 mm wide (comparison)

45 mm wide (comparison)

57 mm top panel, keys below

Generated by branding/build.py. Geometry: branding/export/spec.json.

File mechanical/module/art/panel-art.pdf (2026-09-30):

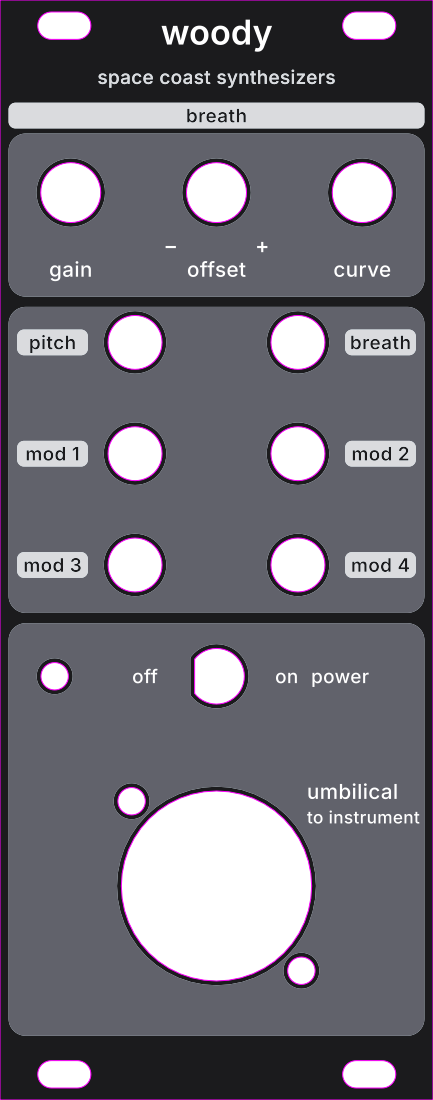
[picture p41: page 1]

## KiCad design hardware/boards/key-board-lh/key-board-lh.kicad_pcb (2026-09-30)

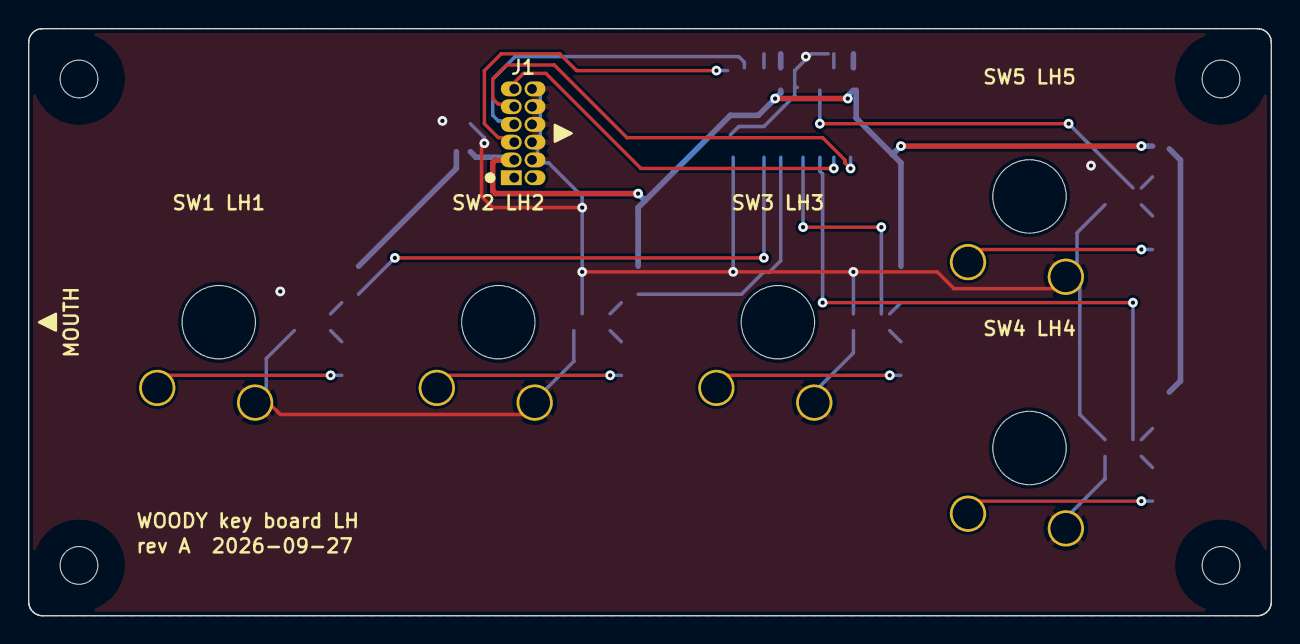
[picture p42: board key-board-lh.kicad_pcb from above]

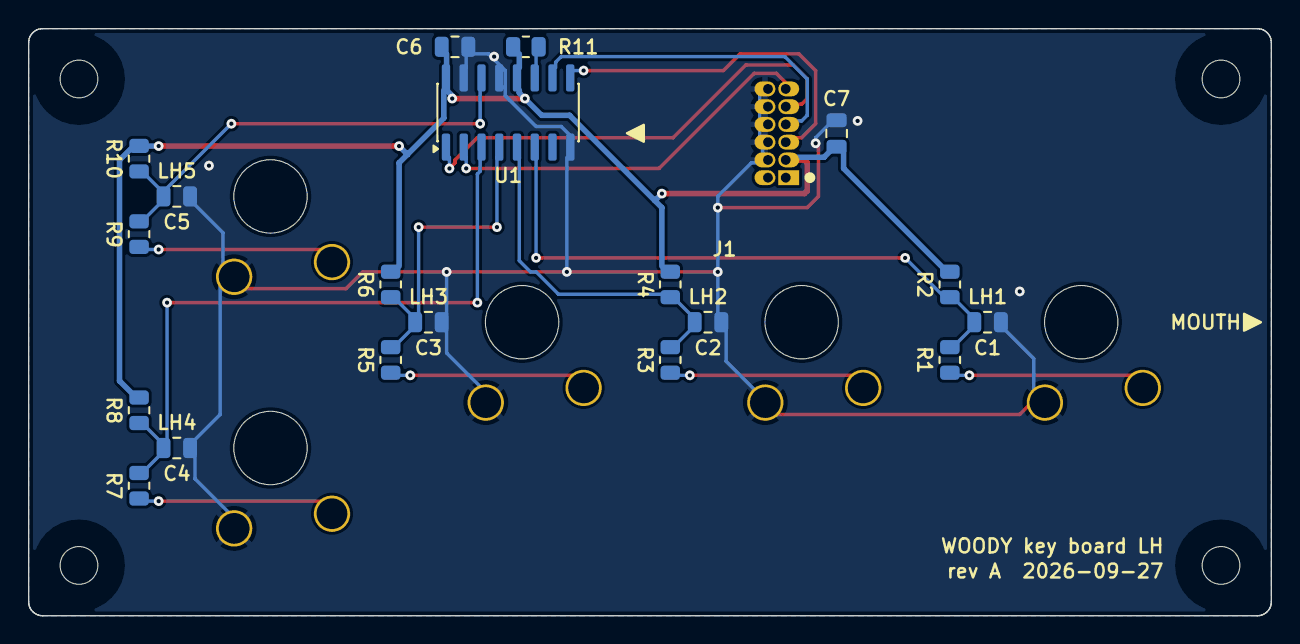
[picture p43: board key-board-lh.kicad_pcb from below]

Board: 2 copper layers, 88.9 x 42.0 mm, 29 parts (24 on the bottom side), 17 nets.

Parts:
C1, C2, C3, C4, C5: 47nF; C_0805_2012Metric
C6: 100nF; C_0805_2012Metric
C7: 10uF; C_0805_2012Metric
H1, H2, H3, H4: mount; MountingHole_2.7mm_M2.5
J1: 12-way; IDC-Header_2x06_P1.27mm_Samtec_SHF_Horizontal
R1, R3, R5, R7, R9: 100R 1%; R_0805_2012Metric
R2, R4, R6, R8, R10, R11: 2k2 1%; R_0805_2012Metric
SW1, SW2, SW3, SW4, SW5: KS-33; SW_Gateron_KS33_1u
U1: 74HCS165; SOIC-16_3.9x9.9mm_P1.27mm

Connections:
/CHAIN_SCK: J1.11, U1.2
/CHAIN_SER_LH: J1.7, U1.10
/CHAIN_SHLD: J1.9, U1.1
/HOP_LH_LT: J1.5, U1.9
/KEY_FREE3: R11.2, U1.11
/KEY_LH1: C1.1, R1.1, R2.2, U1.6
/KEY_LH2: C2.1, R3.1, R4.2, U1.5
/KEY_LH3: C3.1, R5.1, R6.2, U1.4
/KEY_LH4: C4.1, R7.1, R8.2, U1.3
/KEY_LH5: C5.1, R9.1, R10.2, U1.14
/LH1/SWITCH_LEG: R1.2, SW1.1
/LH2/SWITCH_LEG: R3.2, SW2.1
/LH3/SWITCH_LEG: R5.2, SW3.1
/LH4/SWITCH_LEG: R7.2, SW4.1
/LH5/SWITCH_LEG: R9.2, SW5.1
GND_CHAIN: C1.2, C2.2, C3.2, C4.2, C5.2, C6.2, C7.2, J1.4, J1.6, J1.8, J1.10, J1.12, SW1.2, SW2.2, SW3.2, SW4.2, SW5.2, U1.8, U1.13, U1.15
V3V3_CHAIN_LH: C6.1, C7.1, J1.3, R2.1, R4.1, R6.1, R8.1, R10.1, R11.1, U1.12, U1.16

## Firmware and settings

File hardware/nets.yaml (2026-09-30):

# THE MASTER NET LIST. Authoritative for every net that crosses a circuit
# boundary.
#
# WHY IT IS AT THIS LEVEL. A per-circuit netlist.yaml can only declare its own
# side of a boundary-crossing net. Across 23 circuits that is up to 23
# half-declarations with NOBODY OWNING THE NET - so two circuits can spell it
# differently, two can both claim to drive it, and one can name a peer that
# never names it back. None of that is visible from inside either circuit. It
# is the same shape as every other defect here: a fact stated in several
# places and owned in none.
#
# SEEDED FROM THE 23 `## Interfaces` TABLES, which are the prose version of
# this file: 164 rows, 114 distinct node spellings, 29 nets named by more than
# one circuit. Those tables stay - they carry the reasoning - but this file is
# what a tool reads.
#
# THE RULES, enforced by tools/check-netlist.py:
#   - every `ports:` entry in a circuit netlist must name a net here
#   - dir `out` must come from this net's `driver`; `in` from `receivers`;
#     `ref` from `reference`
#   - every net needs exactly one driver unless `multi_driver` or `undriven`
#   - every circuit named here must declare the matching port
# The last rule is the bidirectional half, and it is what made the `circuit:`
# dependency edges trustworthy when it was applied to them.
#
# VALUES LIVE IN config/figures.yaml. `figure:` cites; it does not restate.
# A NET HERE ASSERTS A CONNECTION. Do not add one speculatively - an asserted
# connection the board does not have is worse than a missing one.

version: 1

nets:

  # ======================================================================
  # INSTRUMENT: the key chain, main board to the two key boards (ADR 0017)
  # ======================================================================

  V3V3_CHAIN:
    kind: power
    carries: "The chain's 3V3 as the replicated cluster schematics name it. On the main board it IS DEV_3V3 - right_thumb and left_thumb by trace, with no fuse (ADR 0018); each key board's instance is on V3V3_CHAIN_RH or V3V3_CHAIN_LH, past its ribbon's bead"
    driver: interfaces/key-chain-loom
    receivers: [cluster/key-register, cluster/key-switch-network, cluster/key-marker-and-bits]

  # Each key board's 3V3, past the FB-CHAIN bead on its ribbon's conductor 10.
  # `per_board:` like the hop nets below: the replicated schematic declares
  # only the generic V3V3_CHAIN, so which instance sits on which is the key
  # chain's to say.
  V3V3_CHAIN_RH:
    kind: power
    carries: "right_hand key board's 3V3: FB-CHAIN on the main board, then conductor 10 of its ribbon (main-board J-CHAIN pin 10, key-board pin 3)"
    driver: interfaces/key-chain-loom
    receivers: [cluster/key-register, cluster/key-switch-network, cluster/key-marker-and-bits]
    per_board: true

  V3V3_CHAIN_LH:
    kind: power
    carries: "left_hand key board's 3V3: FB-CHAIN on the main board, then conductor 10 of its ribbon (main-board J-CHAIN pin 10, key-board pin 3)"
    driver: interfaces/key-chain-loom
    receivers: [cluster/key-register, cluster/key-switch-network, cluster/key-marker-and-bits]
    per_board: true

  GND_CHAIN:
    kind: reference
    carries: "Chain return: the main board's ground, and five alternating grounds on each ribbon: main-board J-CHAIN pins 1/3/5/7/9, key-board pins 4/6/8/10/12"
    figure: chain-conductors
    origin: interfaces/key-chain-loom
    note: "It is the main board's ground pour, carried to each key board by its ribbon's five grounds - a separate name for those conductors, not a separate node"
    reference: [cluster/key-register, cluster/key-switch-network]

  CHAIN_SCK:
    kind: signal
    domain: digital
    carries: "Shift clock to all four U-KEYS registers - one net, two by trace and two over the ribbons"
    driver: interfaces/key-chain-loom
    receivers: [cluster/key-register]

  CHAIN_SHLD:
    kind: signal
    domain: digital
    carries: "Shift/load to all four U-KEYS registers, one net like CHAIN_SCK"
    driver: interfaces/key-chain-loom
    receivers: [cluster/key-register]

  # --- SER and QH: point to point, one hop per net ------------------------
  #
  # cluster/key-register is ONE schematic built four times, so it declares a
  # generic CHAIN_SER in and CHAIN_QH out. WHICH INSTANCE SITS ON WHICH HOP is
  # the hop map, and it lives in interfaces/key-chain-loom/netlist.yaml, which
  # declares one port per instance pin (the _RT/_RH/_LT/_LH nets below) and
  # joins them hop by hop. Neither side can be checked against the other while
  # the register is one replicated schematic, so all ten are `per_board:` and
  # the checker prints them by name. Chain order MCU <- RT <- RH <- LT <- LH.

  CHAIN_SER:
    kind: signal
    domain: digital
    carries: "A register's serial input - generic, one per instance; resolved per instance by the CHAIN_SER_* nets"
    figure: chain-connectors
    driver: interfaces/key-chain-loom
    receivers: [cluster/key-register]
    per_board: true
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

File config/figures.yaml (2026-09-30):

# Shared figures — the single source of truth.
#
# WHY THIS FILE EXISTS
# Three review waves found the same defect ~90 times: a value changes, and the
# numbers derived from it in other documents do not follow. The corpus contains
# exactly one fact with zero staleness findings against it (USB MIDI opt-in),
# and what makes it different is that it is stated ONCE and cited by name from
# everywhere else. This file generalises that.
#
# RULES
#   1. A figure listed here is stated ONCE, in its `owner` document.
#   2. Every other document CITES it. It does not restate the number.
#   3. `forbidden` lists values this quantity USED to have. tools/check-staleness.py
#      fails if any of them appear in the design corpus.
#   4. When a figure changes: update it here, move the old value into `forbidden`,
#      and run the checker. The checker then tells you every place to fix.
#
# STATUS
#   settled  - derived, agreed, safe to cite
#   disputed - the corpus disagrees; `candidates` lists what, `decided_by` says how
#   blocked  - needs a datasheet or a bench measurement

figures:

  - id: inamp-full-scale
    quantity: In-amp output at full sensor range
    value: "-9.94 V"
    status: settled
    owner: hardware/interfaces/breath-sense-link/breath-sense-link.md
    derivation: "G = 1 + 50k/42.2k = 2.18483; x 1M/(1M+11k) = 2.16106 effective; x 4.6 V sensor span = 9.941 V"
    forbidden: ["-9.6 V", "−9.6 V", "-10.05 V", "−10.05 V", "-9.6V", "−9.6V", "to -9.6", "-2.185*(V_BREATH", "−2.185·(V_BREATH"]
    false_positive_note: >
      DO NOT add a bare "10.05 V" or "2.185". mod-channels.md carries four
      legitimate +-10.05 V lines about the MOD CHANNEL range, which is a
      different quantity and is discussed there as the superseded design;
      and 2.185 is the correct RAW in-amp gain, stated correctly in four
      places. Only the combination - the raw gain used to compute this
      figure - is the defect.
    escape_note: |
      THE MISS WAS ONE SPACE, 2026-09-21, AND THE ROW WAS WRONG TWO WAYS.
      The U-DIFFRX BOM row read "Output is 0V at rest to -9.6V at full
      (Vout = -2.185*(...))". All four patterns above spell the value WITH a
      space; the row spells it without. And the formula beside it used the
      RAW gain 2.185 rather than the effective 2.16106, which yields -10.05 V
      - also a forbidden value, also spelled without a space, also invisible.
      So the row disagreed with the register and with itself, and the
      checker reported PASS.
      Found independently by the breath-chain slice and the datasheet slice,
      from opposite ends. It is also in TWO files at once, because
      hardware/bom.csv is generated from the fragment - one defect, two
      copies, one edit site.
    note: "-10.05 V is the same gain with the 1M bias divider omitted. -9.6 V is derived from nothing and matches no configuration."
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

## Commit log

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2026-09-20 Resolve test equipment open item; add characterisation plan
    A full bench is available (scopes, logic analysers, multimeters, signal
    generators, RF), so E9 is not gated on tooling and the multimeter
    purchase in the BOM is dropped.
    More usefully, this makes the latency budget measurable rather than
    assumed. Adds a characterisation table naming what to measure, how, and
    why each figure is load-bearing:
    - Breath transducer response is the dominant term in the whole budget
    and is currently a datasheet figure
    - KS-33 contact bounce decides the debounce window. The 2021 firmware
    used a flat 20 ms; if these switches settle in 2 ms, measuring it
    buys back 18 ms on the most latency-sensitive p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
    [bom.csv]
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2026-09-20 AMOLED decided; record the QSPI and pin-count constraints
    Display goes AMOLED, superseding the earlier monochrome OLED lean. Off-
    axis legibility is the dominant requirement and emissive panels are best
    at it - no backlight means no contrast collapse at the steep angle this
    is read from. True blacks read well under stage lighting, and power
    follows lit pixels so a mostly-black status layout costs little. Burn-in
    mitigation still applies.
    The practical consequence: these panels are almost universally QSPI, not
    SPI. RM67162 and SH8601 class drivers need four data lines, so the
    display interface is ~8 pins rather than 4-5. That is fine here
    specifically because ADR 0001 already put the MCU alo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
    [bom.csv]
2026-09-20 Split into two MCUs: real-time board and display board
    New ADR 0013, revising the partitioning in ADR 0001.
    Two problems had converged on one place. Pin budget was the binding
    constraint on board choice, and the integrated screen boards that suit
    this instrument are often C6, which fails on single core and on the
    missing USB OTG peripheral. Both come from asking one chip to run a 4 kHz
    deterministic loop, a QSPI panel, a WiFi stack and a web server at once.
    Splitting dissolves both rather than working around them:
    - Real-time board (ESP32-S3) owns keys, breath, IMU, the DAC loop, USB
    MIDI, and all state. Pin use drops to 13 of ~30 - seventeen spare,
    against two before.
    - Display board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
    [bom.csv]
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2026-09-20 Three-zone physical layout: display top, MCU mid-body, IO bottom
    Top holds the display board, breath sensor and ADC on a short tube, and
    the upper key cluster. Middle holds the real-time MCU. Bottom holds the
    IMU, umbilical connector, power entry and 3.3V regulation.
    Noted explicitly in the ADR to avoid confusion: the DAC itself is not in
    the instrument, it is in the rack module. The mid-body board is the MCU
    that drives it down the umbilical.
    Centring the MCU is what a star topology buys. Worst-case run drops from
    360mm to 205mm - 14 inches to 8. Nothing here needs that, since UART and
    slow SPI were both fine at 14 inches, but it buys margin on every link at
    once and margin is what stops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
    [bom.csv]
2026-09-20 Select the display board: LilyGO T-Display-S3 AMOLED
    Buying new, so this is a free choice. Looked up real specifications
    rather than working from recall.
    1.91in AMOLED, 536x240, RM67162 over QSPI. Active area 44.22 x 19.8mm,
    board 60 x 25.5 x 10mm, 28 pins broken out of which 18 are GPIO.
    Chosen mainly on shape. 536x240 is a 2.2:1 strip and a 44 x 20mm active
    area is exactly the form of a status bar - note, breath meter, channel
    indicators in a row - which is all the display has to do now that
    configuration lives on a phone. Squarer panels waste area on a body only
    57mm wide. It also carries little that goes unused: this category often
    bundles a PMIC, battery charging and an onboard IMU, n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
    [bom.csv]
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2026-09-20 Analog breath goes single-ended with a dedicated sense return
    The eurorack patch cable comparison is the right one and it explains both
    why patch cables work and what to copy. A module's power returns through
    the bus board ground rail, not through the patch cable, so the cable's
    ground carries only signal current into a high-impedance input -
    microamps, developing 8uV over 2m of 24 AWG against a 153uV LSB. It works
    because its ground does exactly one job.
    The umbilical only breaks that if one ground conductor does both jobs.
    Then instrument power return develops 34mV at 200mA, and it moves with
    display brightness, LED animation and WiFi bursts. That is a shared-
    conductor problem, not a cab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
    [bom.csv]
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2026-09-20 KS-33 Red confirmed; design the final build for hot-swap sockets
    Red is linear and the lightest common option in the line, which is right
    here - tactile or clicky would add breakaway force fighting the left
    thumb, which actuates with its tip while partly giving up grip, and a
    tactile bump buys nothing on a wind instrument.
    Keeping the option to change switches is worth designing for now rather
    than retrofitting, so the final PCB gets hot-swap sockets. Three reasons,
    one of which is more interesting than the obvious one:
    Feel is genuinely uncertain until played. A thumb tip extending from a
    grip has far less force available than a finger pressing straight down,
    and no datasheet answers whet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
    [bom.csv]
2026-09-20 Drop hot-swap sockets; switch action is decided by hand at M1
    Misread the intent. "Swap them out if I don't like them" meant trying the
    switches by hand when they arrive and deciding before building, not
    runtime swappability. Sockets were over-engineering for a decision that
    happens once.
    Switches are soldered. Action is settled at M1 with switches on the
    bench: press one with a fingertip, then with the tip of a thumb held as
    it would grip the instrument. Ten minutes, no hardware needed.
    Kept the one part of that reasoning that survives the simplification.
    Weights need not be uniform - the four left-thumb keys may want a lighter
    spring than the eleven finger keys, since a thumb tip extendi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
    [bom.csv]
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2026-09-20 Add lighting (ADR 0014) and an instrument power switch
    Power switch: switch the buck converter's EN pin, not the +12V rail. The
    instrument draws a few hundred milliamps, and breaking that with a panel
    switch means a switch rated for it, arcing over time, and a fat conductor
    routed to wherever it sits. Switching EN carries no current at all, so it
    can be a tiny slide switch anywhere convenient on signal-gauge wire.
    Placement has to be reachable but not reachable by accident - there is
    very little free surface on a body whose top is a key run and whose
    underside carries thumb keys. Upper section or tail are the candidates.
    This does not replace the module panel switch; that is a hard cut at t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
    [bom.csv]
2026-09-20 Two independent LED strips rather than one chained pair
    Splitting is the right call and the reason is physical routing. Chaining
    needs a data wire crossing the cavity at one end of the runs, and both
    ends are the congested ones - display board and breath sensor at the top,
    real-time board, IMU and umbilical connector at the bottom. Adding a
    signal wire across either, inside a bonded stack that cannot be reopened,
    is a liability for no benefit.
    Two data lines cost one extra GPIO against roughly 17 broken out and 12
    needed, and the S3 drives both on separate RMT channels without effort.
    Splitting also means each run installs and is replaced independently
    during assembly, and each gets its own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
    [bom.csv]
2026-09-20 Define the power tree; fix the rail voltage; add LED level shifting
    Auditing the part list for gaps turned up a wrong decision and two
    missing ones.
    The rail is 5V, not 3.3V. An earlier revision specified a 12V to 3.3V
    buck, which would have clipped the top 30% of the breath range - the
    MPXV4006GP is a 5V part outputting 0.2 to 4.7V, so the analog front end
    needs 5V and an RRIO op-amp on it to reach 4.7V with margin. Feeding the
    dev boards 5V is also the right way round: both carry their own 3.3V
    regulators and USB power paths, so driving their 5V pins lets that
    circuitry work rather than backfeeding a 3V3 pin and contending with USB
    during flashing.
    Power tree now written down. 12V goes d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
    [bom.csv]
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2026-09-20 Settle the DAC; move the pitch precision budget to a matched network
    TSSOP-16 being acceptable removes the caveat on the DAC, so DAC8568 is
    settled. Recorded a package policy in ADR 0013 so choices do not drift:
    SOIC and through-hole preferred, TSSOP and MSOP acceptable as drag-
    solderable with flux, QFN and BGA avoided. Passives 0805 or 1206.
    Checking where the pitch precision budget should actually go turned up
    something counter-intuitive. Over a 10 degC swing on a 9V span, against
    one semitone at 83.3mV:
    DAC internal reference, 5 ppm/degC 0.45 mV 0.54 cents
    discrete resistors, 25 ppm/degC, opposite 4.50 mV 5.40 cents
    matched network, 1 ppm/degC tracking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
    [bom.csv]
2026-09-20 Finalise module parts; add the logic rail the DAC needs
    Applied the same lens as the controller side - one part number wherever
    possible, precision only where it is measurable - and it exposed a rail
    I had missed.
    The DAC8568 is a 2.7-5.5V part and cannot run on the rack rails, so the
    module needs its own low-voltage supply. Which one interacts with noise
    more than it looks: at 3.3V the DAC outputs 0-2.5V and the scaling stage
    needs 3.6x gain, at 5V it outputs 0-5V and needs 1.8x. Everything the
    stage amplifies - op-amp noise, offset, drift - scales with that, so 5V
    halves it.
    The cost is that a 5V DAC wants ~3.5V for a logic high while the
    instrument sends 3.3V, so SPI needs shifting. Tha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
    [bom.csv]
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2026-09-20 Resolve module power entry from eurorack practice
    Researched how modules actually do this rather than guessing. Community
    practice converges on series Schottky diodes for reverse polarity
    (1N5817 being the usual choice), a ferrite bead in series for RF - or in
    many designs a small 2.2-10 ohm series resistor instead - bulk
    electrolytics of 10-100uF per rail, and 100nF ceramics at every IC.
    Two things make this module atypical and both change the answer.
    It passes the instrument's current. A typical module draws 20-100mA;
    this one draws ~290mA on +12V, being 40 of its own plus 250 for the
    instrument. That is about 15% of a modern rack supply and unremarkable
    in itself, but it rules out the s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
    [bom.csv]
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2026-09-20 Closed tube confirmed; pitch gets trim pots
    Two owner decisions resolving review findings.
    The closed sensor tube is correct and the review finding is rejected. The
    reviewer's evidence about commercial instruments was accurate - the EWI
    plugs its sensor tube and runs a second one for airflow, the WX has
    swappable drain plugs - but the premise about this instrument was wrong.
    The player vents through the corners of the mouth around the mouthpiece,
    which is also what makes circular breathing possible. Air leaves
    continuously; it just never enters the sensor tube. Recorded in ADR 0003
    with the reasoning so it does not get re-raised. The moisture and
    Helmholtz resonance findings are independent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
    [bom.csv]
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2026-09-20 Breath receiver becomes a true instrumentation amp
    INA134 swapped for an INA821/828. A difference amplifier's CMRR is set by
    source-impedance balance rather than by the chip - TI's own datasheet
    gives ~74dB for a 10 ohm mismatch - and this design's own protection
    resistor and pulldown would have left roughly 19-34dB against the 60dB
    the scheme needs.
    The two requirements were also incompatible as written: protecting the
    buffer against a sustained 12V fault on the BREATH conductor needs at
    least 3.3k of series resistance, and 3.3k unmatched leaves about 24dB.
    Buffered gigaohm inputs dissolve that conflict - protection resistors can
    be 10k and unmatched with no CMRR penalty. It also absorbs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
    [bom.csv]
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2026-09-20 DAC gets its own regulator, not the rack's +5V rail
    Tier-0 decision 5 of 7.
    The module's 5V was going to come straight off the bus header: short
    ribbon, milliamp load, rail already on the connector. That is fine for
    logic and wrong for the DAC.
    The DAC8568 at internal reference x2 spans 0-5V, so its full-scale
    output *is* AVDD. Eurorack's +5V is the least-regulated rail in the
    case at +-5%, and it moves with whatever else is drawing from it. On a
    rail sagging to 4.75V the DAC saturates around 4.55-4.65V, which puts
    the top pitch calibration point in the nonlinear region and corrupts
    the whole two-point fit rather than just clipping the top. It also
    means another module powering up shifts a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
    [bom.csv]
2026-09-20 Pitch output keeps its 1k series resistor
    Tier-0 decision 6 of 7. The review wanted the 1k shrunk or bypassed
    with in-loop feedback, because it divides against the load: -11.9
    cents/octave into 100k, -23.5 into 50k.
    It stays, because this is a pure gain error and the gain trimmer has
    full authority over it. That is the distinction the review blurred -
    the offset error that forced trimmers into the design was
    unrecoverable because nothing implemented b. A resistive divider is
    entirely a, so both the trimmer and the firmware scale factor cancel
    it exactly.
    The alternatives cost more than they return. 100R gives up an order of
    magnitude of short protection to reduce rather than remove an erro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
    [bom.csv]
2026-09-20 Delete the instrument power switch; load switch at the module
    Tier-0 decision 7 of 7. This reverses an earlier request for a power
    switch on the instrument.
    As specified it could not be built: ADR 0005 said "switch the buck
    converter's enable pin", and the Recom R-78E5.0 is a 3-pin SIP with no
    enable pin. It would not have worked anyway - the WS2815 strips run on
    raw umbilical +12V upstream of the buck, so killing the buck leaves
    ~120mA of strip quiescent draw and the strips holding their last
    latched colours. "Off" would be a lit instrument with dead logic.
    The version that works is a high-side P-FET on raw +12V, which means a
    gate network and a fat conductor routed to a panel hole inside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
    [bom.csv]
2026-09-20 Breath sensor gets a precision reference, not the shared 5V rail
    Decision 8, which the fix stress-test promoted: R8 has a better
    cost/benefit than several of the fixes already applied.
    The MPXV4006GP is ratiometric by specification - Vout = VS x (0.1533P
    + 0.04). Its output is a fraction of its own supply, and it was
    sharing the buck's 5V rail with both dev boards. AMOLED current steps
    and WiFi bursts of 1% put 52mV on the breath jack, with millisecond
    envelopes that pass straight through the 500Hz filter. For scale, the
    AGND common-mode path this ADR spends pages on contributes 0.13mV.
    The ratiometric path was ~30dB worse than the one that was analysed.
    The usual free fix - reference the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
    [bom.csv]
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2026-09-20 Apply remaining Tier-1/2 findings across module, LEDs, IMU and BOM
    Closes the power-on open item from decision 4, and it turns out not to
    be a conflict at all. Taking the mod channels' 2.5V offset from a DAC
    channel rather than from the internal reference means both terms are
    zero on a zero-scale reset: Vout = 4 x (0 - 0) = 0V. So an A or C
    grade part gives the best available state on every channel at once -
    pitch parks subsonic below -2V, mods park at exactly 0V, breath is
    held at 0 by the receiver pulldown. Specify the full orderable part
    number; the grade letter is the whole decision and is invisible in
    "DAC8568". The internal reference is also disabled by default and
    needs an explicit en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
    [bom.csv]
2026-09-20 Vapour, continuous auto-zero, and the mod channel update rate
    Three findings that were still only in the review document.
    The condensation section handled liquid and said nothing about
    vapour, which is the datasheet's actual objection: NXP qualifies this
    family on dry air, states it is "NOT compatible with water or water
    vapors", and the gel die coat swells when wet - which presents as
    unreliable readings, not a dead part. Exhaled breath is ~100% RH and
    at 6kPa the tube air compresses ~6%, so every note pumps saturated air
    toward the die. Vapour cannot be eliminated from a closed tube that is
    breathed into, so this is recorded as three partial measures rather
    than a fix: a porous PTFE plug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
    [bom.csv]
2026-09-20 Apply the systems findings: bring-up order, silent failures, bonding
    The siloed agents could not see these; the systems pass and the
    bring-up review could.
    Bring-up ordering was wrong in three places. M5 cut the aluminium
    plate - the most expensive irreversible part - in Phase 3, before the
    carrier PCB it has to accommodate was designed in Phase 4; M5 moves to
    Phase 4. E13 and M7 sat in the same phase with a hard dependency, and
    the carrier will spin at least once since the SPI split alone changes
    its topology, so the rule is now that the body does not close until
    the carrier is revision-final and burned in. And E11 - the single test
    validating the entire analog-breath decision - ran agains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
    [bom.csv]
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2026-09-20 Select the real-time board: Waveshare ESP32-S3-Matrix
    Three open items closed, verified against CircuitPython's and
    Zephyr's board definitions rather than product listings - those have
    to be correct for the board to boot at all.
    The IMU is a QMI8658C and it IS 6-axis. CircuitPython names it with
    IMU_SDA on GPIO11, IMU_SCL on GPIO12, INT1 on GPIO10, INT2 on GPIO13.
    The 9-axis claim in one write-up is wrong. It would not have mattered
    - only relative tilt is needed, never heading - but the item is
    closed.
    The USB-C is the S3's native USB, not a UART bridge. Zephyr sets
    zephyr,console = &usb_serial with no bridge chip in the tree. This one
    was decisive: GPIO19/20 are not broken out, so a CH34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
    [bom.csv]
2026-09-20 The 8x8 matrix becomes the instrument's second display
    Your idea, and it reverses the framing from the last commit. The
    matrix was recorded as 64 LED drivers that would never light, costing
    ~50mA and 0.25W for nothing. Pointed out through a window in the oak
    underside at the tail, it becomes the only two-dimensional display in
    the instrument.
    Generic and assignable, the same shape as the mod channels in ADR
    0006: a sink with a configurable source, defaulting to breath. Other
    sources are IMU tilt and roll, acceleration, note, any mod channel,
    playing state; render modes are bar, 2D dot, bloom, field brightness,
    glyph. Orientation is a config field, not a construction decision -
    which edge re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
    [bom.csv]
2026-09-20 Rack supply is generous - which exposes the constraint that actually binds
    Recorded in the README design scope alongside the +5V rail: the
    target rack's supply is a stated property of the system, not an
    assumption to defend. "A small Eurorack PSU might not cope" arguments
    no longer apply.
    But the relief is narrower than it sounds, and ADR 0014 was arguing
    from the wrong constraint. Withdrawing the rack argument does not
    relax the clamp - it replaces a soft constraint with two harder ones
    sitting underneath it, and the binding one is tighter than the rack
    ever was.
    Heat is the real limit. The body is oak and acrylic, both insulators,
    sealed, with the aluminium plate the only path out and th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
    [bom.csv]
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2026-09-20 Clean up stale open items and a duplicate BOM row
    Auditing what is actually still open turned up bookkeeping rot from
    today's changes.
    R-DIV-ADC and R-ADCDIV were the same part twice - I added the second
    while applying the Tier-1 findings without noticing the TBD row
    already there. Merged into R-ADCDIV with both rationales.
    TUBE still said ~30mm, from before the sensor moved to the bottom of
    the instrument. It is ~400mm and 1.17ms, the largest single term in
    the latency budget.
    ADR 0014's open list still asked for a density decision and carried
    the clamp as unsettled; both were resolved when the rack-supply
    framing was withdrawn. What remains open there is what the side
    strips display - t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
    [bom.csv]
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2026-09-20 Umbilical connector: etherCON at both ends
    The cable is a consumable, and everything else follows from that.
    Ethernet patch lead is not flex-rated and will eventually fail on an
    instrument that moves constantly - the question is whether that costs
    an afternoon with a crimp tool or the time to open a drawer.
    Measured the alternatives properly. A 6HP panel is 30.18mm, (6 x
    5.08) - 0.3. etherCON's D-series cutout is 23.8mm, leaving 3.19mm of
    aluminium each side; M12 X-coded is ~16mm, HR10A 10.2mm.
    M12 X-coded is ruled out on current, not on cable. The ADR listed its
    cost as an "industrial-looking custom cable", which was wrong twice:
    M12 X-coded IS industrial Ethernet with off-the-shelf shiel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
    [bom.csv]
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2026-09-20 The KS-33 is documented; "must be measured" was wrong
    ADR 0002 said the plate cutout "must be measured, not taken from a
    datasheet". Gateron publishes a KS-33 Low Profile 2.0 datasheet and
    downloadable 3D models for this exact switch, there is a GrabCAD
    model, and ianmaclarty/ik is an open-source keyboard built on KS-33
    with a real plate in the repo.
    A caliper is also the worse instrument here. Measuring a moulded
    plastic housing gives that sample's dimension including draft angle
    and mould flash - not design intent, and not the tolerance band. The
    drawing gives both. Measuring was the right instinct for an
    undocumented part and the wrong one for this.
    Captured what the published spec alre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
    [bom.csv]
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2026-09-21 Module goes to 8HP; mouthpiece, spare switches and tuning settled
    Four decisions, each of which dissolves findings that cost more to
    work around than to answer.
    8HP. At 6HP a 23.8mm etherCON bore left 3.19mm of aluminium each side
    - a fit the panel passed and a stiffness test it did not - and the
    connector body extending 30-40mm behind a PCB sitting 7mm back needed
    a 26mm notch in a 28mm board, which severs it. That is why a review
    concluded the module had to become two boards. 40.34mm gives 8.27mm
    each side of the bore, leaves web at the notch so the module stays one
    board, frees a panel height budget that overran by 0.5mm, and allows a
    normal 16-20mm knob instead of 13mm. Costs two horizo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
    [bom.csv]
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2026-09-21 Draw the breath receive stage; fix the zone table
    Two keystone pieces.
    hardware/module/breath-receive-stage.md is the schematic that never
    existed. Its absence was the single largest source of findings in the
    cold review - five separate findings turned out to be five symptoms of
    one absent document, and two expert reviewers built two different
    circuits from the same ADR prose, deriving six different in-amp gains
    each arithmetically correct for a different reading.
    The keystone choice is which input BREATH drives. An in-amp is
    additive at REF, so with BREATH on IN+ the sensor's +0.2V pedestal
    needs a NEGATIVE REF and the unipolar DAC channel cannot produce one -
    that was the polarity showst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
    [bom.csv]
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

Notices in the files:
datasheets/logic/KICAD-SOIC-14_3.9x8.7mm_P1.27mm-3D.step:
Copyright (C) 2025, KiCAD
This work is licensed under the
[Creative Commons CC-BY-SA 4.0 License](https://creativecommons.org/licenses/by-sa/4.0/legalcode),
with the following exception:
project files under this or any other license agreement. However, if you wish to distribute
